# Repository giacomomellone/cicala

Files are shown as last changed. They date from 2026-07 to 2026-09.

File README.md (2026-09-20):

# cicala

Cicala is the Italian word for cicada, the loud, mildly annoying voice of every Italian summer.
What do cicadas talk about all that time? They must be asking each other quite interesting questions.
`cicala` is an open source questions and conversation project built to keep the words going, and to stimulate introspection and discovery.

Its three parts share one database:

1. **[Question database](questions/)**: community-maintained YAML files in this repo.
2. **[Website](website/)**: a static front-end to the database, no account needed. Anyone can play, save favorites, and suggest questions.
3. **[Device](hardware/)**: a pocket-sized offline object with one e-paper display and adjacent Filters and Next buttons. The first prototype is still in development.

Cicala also has an [Xteink X4 Pro integration](docs/crosspoint.md) in a CrossPoint
fork. It shares the portable question engine with the device firmware and adds
manual bundle updates and sessions saved on SD.

## AI policy

Cicala's questions are [**Human Reserved**](https://www.gatesnotes.com/home/home-page-topic/reader/a-turbulent-ai-era-and-critical-choices-to-make).
Do not use generative AI to write questions.
The questions in this project are meant for humans, not for machines (unless machines start having consciousness and enjoy asking each other questions).
For everything else in this repository, like code, documentation, tests, tooling, firmware, and hardware, feel free to use AI.
**Just make sure to leave questions to humans.**

AI may translate an human-written question into another supported language and may suggest metadata such as tags. After a new question or a human edit in any language is merged, the Google Cloud Translation workflow opens or updates review pull requests for the other linked translations. Editing a translation never rewrites its human-written original. Every machine-translated entry retains that original's `origin` and keeps `translated_by: google`, including after review. `translation_sync` records the version used for each update and prevents generated updates from triggering another round.

Machine translations do not merge automatically. A maintainer compares each draft with the accepted source edit and its original, and may edit or reject it to preserve the intended meaning and make it read naturally in the target language. Published machine translations remain labeled `translated_by: google` in the database, and the website marks them as automatically translated and human-reviewed wherever they appear, with a link to the original.

### Some tips to write a good question

More on the reasoning behind these points: [docs/theory.md](docs/theory.md). Every example below is quoted from that page.

- **Make people build an answer instead of repeating one.** If the answer is already finished in their head, the question is boring. Try adding a constraint.
  - Weak: "What food do you dislike?"
  - Better: "Which food do you wish you liked, and what keeps stopping you?"
- **Avoid rankings and superlatives: best, favourite, top, most.** They ask a person to scan a whole life, pick a winner, and defend that taste in public. Someone who cannot think of an answer feels boring, instead of blaming the question. Ask only what you would answer yourself, at that table.
  - Weak: "What's the best book you've ever read?" A memory test and a public verdict on taste.
  - Better: "Which book do you still think about at odd moments?" It asks what you noticed, not what is best.
- **Ask about one concrete thing, not a whole subject or a principle.** A subject gives attention nowhere to land, a principle has a socially correct answer, and a scene gives the table people, places, and choices to ask about next.
  - Weak: "Do you value honesty?"
  - Better: "When did you last tell a lie you're still unsure about?"
  - Weak: "What do you think about music?"
  - Better: "Which song do you love for a reason that has nothing to do with the music?"
- **Do not invent someone's life.** Keep the assumption that helps and remove the details you cannot know about their family, work, health, or history.
  - Weak: "Which parent understands you better?" It assumes two parents, a relationship with both, and a ranking.
  - Better: "Who understood you better than you expected?"
- **Give the question one job, and keep it short.** Leave the follow-up to the people at the table.

## Contributing a question

You don't need to be a developer or have an account. Use [suggest a question](https://cicala.dev/suggest), or open a [new-question issue](../../issues/new?template=new-question.yml) directly on GitHub. A maintainer who speaks your language reviews it, and once merged it ships to the site and every device. All questions are dedicated to the public domain (CC0); see [CONTRIBUTING.md](CONTRIBUTING.md).

To correct an existing question, use **suggest an edit** on its permalink. That
form needs no account either; the
[question-edit form](../../issues/new?template=edit-question.yml) on GitHub
stays available. Question rewrites remain Human Reserved; accepted edits keep
the existing ID.

Want to add a whole language? Read [docs/languages.md](docs/languages.md).

## Development

[`just`](https://github.com/casey/just) is the entry point. Type `just` to see every command:

```sh
just setup     # one-time: python venv + npm install
just validate  # check the question database
just website   # run the site locally
just test      # database validation + tools tests + website tests
just docs      # live-preview the docs (mkdocs)
```

Requires `just`, Python 3.11+ and Node 20+. `just setup` creates the venv (`.venv/`) from [requirements.txt](requirements.txt).

On a machine with [Nix](https://nixos.org), `nix develop` (or `direnv allow`, using the committed `.envrc`) provides those tools at the versions CI uses, without installing anything system-wide. It is optional and no recipe depends on it; `flake.nix` says what it deliberately leaves to upstream installers, the Zephyr SDK included.

## Documentation

- [docs/design.md](docs/design.md): product and UX rationale
- [docs/brand.md](docs/brand.md): public wordmark, typography, colour, and asset rules
- [docs/device_prototype.md](docs/device_prototype.md): device feasibility review, enclosure study targets, and prototype plan
- [docs/prototype_bom.md](docs/prototype_bom.md): breadboard and rev A parts list
- [docs/decisions.md](docs/decisions.md): decision log
- [docs/languages.md](docs/languages.md): multilingual policy and maintainers
- [docs/sync_protocol.md](docs/sync_protocol.md): device sync and bundle format

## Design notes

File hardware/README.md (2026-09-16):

# Hardware

Each revision owns its PCB, enclosure, exported parts and manufacturing notes.
Open the revision's KiCad project so its local libraries and models resolve.

| Directory | Design |
| --- | --- |
| [rev_a](rev_a/README.md) | Original 78 × 49 mm board and deeper enclosure |
| [rev_b](rev_b/README.md) | Landscape device; L-shaped board beside a thin battery |
| [tools](tools/README.md) | Shared checks and revision-specific build commands |

Native KiCad and OpenSCAD files are authoritative. Generated exports belong
inside their revision. Temporary candidates and logs go in the ignored
`build/` directory. Hardware is licensed under [CERN-OHL-S-2.0](../LICENSE-HARDWARE).

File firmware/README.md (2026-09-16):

# Firmware

Zephyr firmware for the ESP32-S3 Cicala device. The breadboard rig runs the
tabletop loop, deep sleep, setup portal, signed bundle sync, signed firmware
updates, battery monitoring, and the two status LEDs. Whole-device sleep current
still needs measurement on rev A because the DevKitC indicators exceed the
30 µA target.

Start with the [firmware primer](../docs/firmware_primer.md). See the
[firmware architecture](../docs/firmware_architecture.md) for module boundaries
and the [hardware wiring guide](../docs/hardware_wiring.md) for the bench rig.

## Integrated Rev A board

Select `hw=rev_a` for the integrated PCB; the default remains the breadboard.
The Rev A overlay/configuration control the switched battery divider and panel
rail, set the ADC divider to 1 MΩ/470 kΩ, wait 200 ms before sampling, and use
native USB Serial/JTAG for console and debugging. A dedicated power-sampling
work queue keeps the settling delay out of the input/system queue. Conversion
failure and deep-sleep entry both switch the divider off.

```sh
just hw=rev_a fw-build debug
just hw=rev_a fw-flash debug
just hw=rev_a fw-monitor debug
just hw=rev_a fw-debugserver
just hw=rev_a fw-flash                 # release with MCUboot
```

Rev A build directories are `build/cicala-rev-a` and
`build/cicala-rev-a-debug` (other profiles use the corresponding suffix).
Use `port=/dev/cu.usbmodem…` or the Linux serial device as a `just` override
when automatic detection selects the wrong port. The debug ELF is
`build/cicala-rev-a-debug/zephyr/zephyr.elf`; the existing OpenOCD configuration
uses the ESP32-S3 built-in USB JTAG adapter. No external JTAG probe is required.

GPIO14 low requests charging; the independent analog temperature guard can
still veto it. GPIO5 enables the panel before driver initialization. Deep
sleep parks physical display-bus levels low before disabling the rail and
holds those pins. The first refresh after power restoration is full because
the display controller RAM has been lost. The PCB recovery pinout and first
power checks are in [the hardware review](../hardware/rev_a/REVIEW.md).

The [Rev A build and flash guide](../docs/firmware_rev_a.md) covers toolchain
installation, first USB download, JTAG, UART recovery and hardware acceptance.
Rev A reads both BQ25185 status pins: high/high means idle or disabled, so it
does not claim a full battery from voltage alone. The release application and
MCUboot both use 16 MiB flash without PSRAM. Firmware validation passed 195
QEMU cases across 16 configurations, with two skips.
Physical USB flashing, JTAG, charging and display operation remain prototype
acceptance tests. The accepted question database is currently empty; use the
existing charset diagnostic for initial display testing.

## Target

- ESP32-S3-DevKitC-1-N8R8 on the breadboard
- ESP32-S3-WROOM-1-N16 on rev A
- 250 × 122 GDEY0213B74 e-paper panel with SSD1680 controller
- Filters and Next buttons
- red and green status LEDs; lighting both produces amber
- single-cell LiPo with a bq25185 power-path bench

Application logic is C++17 under `firmware/lib/`. Zephyr threads, drivers, and
channels live in `firmware/app/` and use C where Zephyr macros require it.

## Commands

```sh
just fw-init          # install the west workspace once
just fw-build         # release image with MCUboot
just fw-flash         # build and flash the release image
just fw-monitor       # UART console; ctrl-] exits
just fw-sim           # run the application under qemu
just fw-test          # run all firmware suites under qemu
just fw-test input    # run one suite
```

`fw-build`, `fw-flash`, and `fw-monitor` accept a profile:

| Profile | Purpose |
|---|---|
| `release` | normal MCUboot application; the default |
| `debug` | `-Og`, USB debug console, and OpenOCD support |
| `charset` | step through the renderer's glyph pages |
| `soak` | generate Next presses for ghosting measurements |
| `retain` | warm-reboot during the soak run |
| `power` | log raw and converted battery readings |
| `portal` | open the setup portal at boot |
| `corpus` | write the compiled corpus to LittleFS at boot |
| `bench` | fetch bundles from a local server; requires its host |
| `ota` | fetch firmware from a local server; requires its host on first build |

Examples:

```sh
just fw-flash charset
just fw-monitor charset
just fw-flash bench 192.168.1.20
just fw-build ota 192.168.1.20
just fw-monitor debug
```

Profiles use separate build directories, so switching images does not retain
another profile's CMake configuration. The release, power, and OTA profiles use
sysbuild and produce MCUboot plus the signed application.

For debugging, `just fw-debug` builds and flashes the debug profile, then starts
OpenOCD on port 3333. `just fw-debugserver` starts the server without flashing.

## Interaction

- Filters opens the menu or advances through Dark, Sexual, Heavy, and Done.
- Next draws during play, toggles a permission in the menu, or applies Done.
- A cold boot excludes all three permissions. RTC memory preserves the question
  snapshot, menu draft/cursor, per-language bags, and refresh count through sleep.
- Presses during a panel refresh are dropped.
- Ordinary playback includes depths 1 and 2. Heavy permits depth 3.
- Display errors and refused refreshes do not commit pending selection state.
- Holding both buttons through boot opens the setup portal.
- External power keeps the device awake and opens the sync and update window.
- LOW and CRITICAL battery states refuse panel refreshes. LOW blinks amber
  once; CRITICAL blinks red three times.

Wi-Fi is optional. Every release image contains the shipped corpora, and a
stored corpus replaces its compiled counterpart only after validation.

## Source layout

```text
firmware/
├── west.yml          # pinned Zephyr workspace
├── Kconfig.policy    # shared product policy
├── app/
│   ├── boards/       # board Kconfig and devicetree
│   ├── include/      # C interfaces and channel messages
│   └── src/          # Zephyr integration
├── lib/              # hardware-free logic
├── tests/            # ztest suites
└── patches.yml       # local Zephyr patches
```

The build creates question fixtures from the real YAML database. Firmware tests
therefore exercise the same QDB4 bytes compiled into the application.

## Hardware checks

The breadboard rig has verified:

- Filters and Next from GPIO input through the panel refresh
- English and German QDB4 bundles and no-repeat draws
- every shipped question at the minimum font size
- partial and full refresh policy on the GDEY0213B74
- deep-sleep wake and RTC-retained state
- setup with a phone, including saved credentials and language
- bundle validation and atomic LittleFS replacement
- MCUboot installation and rejection of an image signed with the wrong key
- battery and VBUS sensing, refresh gating, and LED states

Network download checks require a reachable bench server. Sleep-current
measurement requires rev A or a power mule without the DevKitC's indicator
loads. The procedures and recorded measurements are in the
[hardware wiring guide](../docs/hardware_wiring.md#bench-measurements).

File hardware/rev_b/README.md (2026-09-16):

# Rev B

Landscape prototype with a centered 3.52-inch display, ESP32-S3 module,
L-shaped PCB, 500 mAh battery and two flat, recessed Omron controls at the right: Filters above the larger Next button.
The core envelope is 128 × 66 × 16.8 mm (1 mm nominal button recess). The phone carrier is removable.

The routed board and nominal mechanical design pass the digital checks.
This is an engineering prototype; physical qualification and factory order
review remain open. See [validation](validation.md) for the measured scope.

- `contract.json` — shared mechanical dimensions and manufacturing limits
- `pcb/` — native KiCad project, local libraries and component models
- `case/` — OpenSCAD enclosure and generated geometry
- [Complete assembly BOM](BOM.md)
- [Fabrication and assembly order notes](pcb/fabrication_notes.md)
- `component_selection.csv` — selected components and rationale
- [Hardware specification](../../docs/hardware_rev_b.md)
- [Component evidence](../../docs/hardware_rev_b_selection.md)

Digital validation and first-article measurements are separate records.
The first assembled board is needed to qualify electrical behavior, printed
fits, display flex, temperature sensing and the optional phone carrier.

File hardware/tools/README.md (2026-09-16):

# Hardware tools

Run commands from the repository root through `just`.

| Directory | Responsibility |
| --- | --- |
| `pcb/` | KiCad parsing, geometry, assembly export and electrical/copper audits; historical Rev A routing helpers |
| `case/` | STEP-derived component bounds and mesh checks |
| `rev_a/` | Rev A review and manufacturing/enclosure exports |
| `rev_b/` | Rev B contract, routing support, review and exports |

Native board files are the source of truth. Routing helpers generate review
candidates; they do not reproduce a finished board by replaying an old script.
Keep candidate files and logs under `build/`, outside the source directories.

Rev B's `silkscreen.py` maintains the native identity and service legends and
checks their pin mappings. `just hw-rev-b-pcb-renders` regenerates orthographic
KiCad PNGs, mirrored underside/normal top silkscreen SVGs and their provenance.

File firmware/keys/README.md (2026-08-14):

# Firmware signing keys

MCUboot verifies each image with the public key compiled into the bootloader.
`SB_CONFIG_BOOT_SIGNATURE_KEY_FILE` in `firmware/app/sysbuild.conf` names the PEM
used both to generate that public key and to sign application images.

## Development key

`firmware-signing-dev.pem` is committed so local sysbuild builds produce a
matching bootloader and application without extra setup. Its private key is
public, so use it only for development hardware.

## Release key

Create the release key with:

```sh
just keygen --purpose firmware --out release-firmware-key.pem
```

Store the private PEM in the `FIRMWARE_SIGNING_KEY` GitHub Actions secret. CI
writes it over the development PEM while building a release. Never commit it.

A shipped device must receive the release-key bootloader during its wired first
flash. OTA cannot replace the bootloader or change the key it trusts. Losing or
rotating the release key requires a wired reflash of every affected device.

`BUNDLE_SIGNING_KEY` is separate. The application uses it to verify question
bundles and OTA manifests. See [firmware updates](../../docs/firmware_update.md).

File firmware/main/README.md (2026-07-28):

# main

Application entry point and state transitions. See
[firmware/README.md](../README.md) for the current interaction contract and
state outline.

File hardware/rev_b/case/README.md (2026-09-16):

# Rev B enclosure

`cicala_enclosure.scad` is editable. `contract.scad` and `pcb_component_bounds.scad` are generated from the contract and native KiCad placement.

The housing is 128 × 66 × 16.8 mm; the flat button tops are 1 mm recessed. Filters is at the upper right and the larger Next button is below. The active screen remains centered. Filters uses a 9 × 9 mm ivory B32-1200 cap; Next uses a 12 × 12 mm orange B32-1320 cap. Both seat directly on B3F-4050 switches. The enclosure supplies flared access wells, with no printed actuators or retaining mechanism.

Run `just hw-rev-b-export --renders` for checked native exports. `exports/assembly/` preserves assembly coordinates; `exports/print/` contains eight individually oriented printed parts, grouped by purpose. Purchased cap, switch, battery, panel and PCB models stay in `exports/reference/` and must not be printed. The clear lens outline is in `exports/patterns/`.

Four core prints form the housing and display supports. The other prints are the optional carrier, ring cover, wedge and temporary flex former. See [the assembly guide](../../../docs/hardware_rev_b.md#buttons-and-print-preparation) for soldering, cap installation, print tolerances and screws.

The carrier adds 3.2 mm. Its increased portrait length fails the former iPhone 16 Plus fit target; phone compatibility is unqualified. The R1.55 flex bend and connector entry height remain first-article checks. No integrated Rev B prototype has been assembled.

Native meshes use KiCad STEP handedness: X right, Y up (negative layout Y), Z above the base. Translate the native PCB STEP up 4.6 mm to align it. Print meshes include their bed rotation/translation; do not mirror them. The validation compares the PCB reference outline and mounting holes against this datum.

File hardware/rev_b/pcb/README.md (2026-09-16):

# Rev B PCB

Open `cicala_rev_b.kicad_pro` in KiCad 10. The engineering design uses the ESP32-S3 module, an L-shaped 1.2 mm four-layer PCB and one fitted assembly face. Bare diagnostic contacts may be on the underside. Component selection and assembly assumptions are recorded in [the engineering guide](../../../docs/hardware_rev_b.md) and [selection record](../../../docs/hardware_rev_b_selection.md).

The display is Waveshare 22609, 3.52-inch V1.1 UC8253. The Molex 503480-2400 connector uses the panel table: pins 1 and 4 unused, pin 5 decoupled. The protected Renata pack connects through JST SH: BAT+/NTC/GND on pins 1/2/3. R8 sets nominal 100 mA charging.

The board uses 0.2 mm general clearance, 0.5 mm copper-to-edge spacing, 0.15 mm fine-pin escapes and ordinary 0.3 mm drilled / 0.6 mm diameter through-vias. 87 SMT components and two B3F-4050 through-hole switches are installed from the top; switch solder joints are underneath; there are no filled via-in-pad requirements. Ground is poured on both outer faces and In1, with local In1 signal crossings outside reserved reference areas. In2 carries power/signals and a dedicated ground reference beneath the bottom USB pair.

Run `just hw-rev-b-check` for native electrical and mechanical checks. `just hw-rev-b-fab-export` exports only after those checks pass, including assembly BOM/CPL, Gerbers, drills, IPC-2581 and STEP. The factory must confirm the stack, controlled impedance, panel support, component orientations and paste treatment before an engineering order. This is an unbuilt prototype; see [validation](../validation.md) for actual check results and remaining measurements.

[`renders/`](renders/README.md) contains top and bottom KiCad 3D exports used by
the public device page. The mechanical board model is
`exports/cicala_rev_b_board.step`.

[Reading the board](silkscreen.md) explains its native silkscreen: Cicala
branding, circuit brackets, connector polarity, every test point, and the
underside power/recovery guide. Main text is 1 mm, compact labels are 0.8 mm,
with 0.15 mm minimum strokes and silk clearance. The render directory also
contains both silkscreen drawings as SVGs.

The switch hole pattern uses 1.2 mm finished PTH and 1.8 mm NPTH holes. The JLC BOM/CPL covers 87 SMT references; `manual_assembly.csv` specifies the separate switch soldering and purchased-cap installation. Caps are fitted only after soldering.

The [fabrication notes](fabrication_notes.md) specify stack, impedance, panel, tighter switch-hole tolerances, assembly stages and inspection. They are included in the exported prototype package. SW1/Filters is the upper control; SW2/Next is the lower control.

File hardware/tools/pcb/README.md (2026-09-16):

# PCB review and candidate tools

The checked `../cicala_rev_a/cicala_rev_a.kicad_pcb` is authoritative. These
scripts support review and isolated routing candidates. The historical
placement pipeline is not an exact replay of the current board; do not run
it over the working source. No script authorizes production release.

## Checks and exports

`just hw-pcb-check` runs KiCad ERC, netlist/pin/land checks, filled DRC,
schematic parity and populated STEP export. `../export_fab.sh` also requires
exact assembly MPNs and creates Gerber/drill ZIPs, BOMs, placement files and
both assembly drawings. `jlc_assembly.py` expands KiCad reference ranges,
converts the headers and requires identical fitted-reference coverage in the
BOM and CPL. It preserves explicit top/bottom placement and the common origin.

Run tool regressions with the dependencies in `requirements.txt` (NumPy,
Shapely 2 and fontTools):

```sh
python3 -m unittest discover -s hardware/tools/pcb -p 'test_*.py'
```

Run the complete source review with `just hw-review`. `CICALA_HW_PYTHON`
selects the analysis interpreter; `KICAD_PYTHON_BIN` selects KiCad's Python.
Pass `--app build/cicala-rev-a/app/zephyr --boot build/cicala-rev-a/mcuboot/zephyr`
after the report-directory argument to compare compiled firmware settings too.
The placement/copper/USB commands return a failing exit status on violations.

KiCad Python and analysis Python may be separate installations. On macOS,
KiCad supplies `pcbnew` in its bundled interpreter. CadQuery and Gerbonara
are optional analysis dependencies; install them in a separate environment.
`requirements.txt` contains the routing dependencies.

| Tool | Input / purpose |
| --- | --- |
| `export_geom.py` | KiCad Python: board → physical pads, drills, courts, tracks, filled polygons |
| `audit_electrical.py` | Netlist and project → critical pin mapping, bypass, feedback, LED and land checks |
| `audit_temperature.py` | Netlist → static NTC/comparator tolerance model |
| `audit_copper.py` | Geometry JSON → continuous clearance, edge, via-in-pad and track-angle audit |
| `audit_placement.py` | Geometry + board/models → courts, through-hole/body interference, fitted models |
| `audit_reference.py` | Candidate USB paths → reference/stitch analysis; not a measurement of current routing |
| `audit_usb.py` | Actual board → path lengths including vias, branch mismatch and In1 reference continuity outside launches |
| `check_rev_a_contract.py` | PCB/case datums and compiled app/MCUboot → connector, GPIO, flash, PSRAM and display agreement |
| `package_prototype.py` | Dated public working-source/export snapshot with archive and per-file SHA256 verification |
| `audit_fabrication.py` | Gerber ZIP + geometry → eleven layers and every drill/slot read back independently; needs Gerbonara |
| `check_assembly_bom.py` | Reject blank, unresolved or multiple MPNs |
| `make_component_models.py` | CadQuery → six original STEP envelopes; drawings in `../cicala_rev_a/models/README.md` |
| `apply_silkscreen.py` | Native cicada/wordmark/service legends and fab references; `--mark-only` preserves existing legends |
| `make_cicada.py` | Public SVG → committed native stroke and fill geometry for the cicada silkscreen |

The fabrication audit accounts for Excellon's 1 µm coordinate rounding.
It also opens the compressed IPC-2581 exchange and checks its XML document;
a plain XML file with a `.zip` extension fails the audit.
The enclosure's `../../case/export_component_bounds.py` exports 87 fitted
component envelopes from STEP and fingerprints placement/model changes.
The case checks reject stale envelopes. Generic capacitor height is bounded
at 1.5 mm; the enclosure contains detailed switch references.

## Candidate routing

`build_candidate.py` creates an isolated candidate directory. Its historical
placement and critical routing stages predate the current top-side display
and temperature guard. Updating those stages requires a new placement and
mechanical review; they must not be represented as a reproducible release.

`route_fanout.py` and `finish_routes.py` route on F.Cu, In2.Cu and B.Cu,
leaving In1 as ground. They model every physical pad, oval drills, no-net
mechanical copper, outlines, keepouts and via drills. Surface escapes stay
on the pad's actual layer. `repair_routes.py` permits explicit scoped rip-up
of ordinary copper while preserving the supplied critical seed. Its displaced
nets must be reconnected and checked.

`usb_pair.py` records the dedicated USB geometry, connector crossover and
inline test points. Its main F.Cu width/gap is 0.32/0.26 mm for the selected
JLC04121H-7628 stack. Short escapes remain 0.29 mm or the explicit fine-pitch
neck width. The current board's connector mismatch including the new barrel
spacing is about 0.041 mm. Generated candidate compensation can differ;
audit the actual board rather than treating a seed report as a measurement.

The recovery keepout is derived from J4's transformed physical contacts,
including rotation. The TC2030 shaded contact region and 0.508 mm foreign
copper rule must accompany candidates. U7's package land-to-land clearance
is 0.15 mm; this exception does not relax routed copper clearance.

`ground_planes.py`, `stitch_islands.py` and `stitch_coverage.py` add checked
plane connections. Filled polygons apply only to the exact track set KiCad
refilled. Never route using stale filled polygons. `stitch_islands.py` rejects
a mismatched input set. Unconnected-zone island removal does not repair an
unconnected pad.

`cleanup_dangling.py` removes only DRC-identified items whose deletion preserves
every physical pad group. Refill and repeat; deleting one stub can expose the
next. Some apparent dangling vias are single-layer copper junctions and need
replacement with proper trace junctions before deletion. Never suppress a
DRC warning merely because the router finished.

`unique_ids.py` assigns deterministic unique IDs to cloned footprint items;
`apply_tracks.py` emits stable IDs for copper. Appearance uses native polygon
artwork from `assets/cicala-wordmark.json` and stroke geometry from
`assets/cicala-mark.json`; their sources and regeneration are documented in
`assets/README.md`.

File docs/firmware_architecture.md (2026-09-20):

# Firmware architecture

The ESP32-S3 firmware runs the tabletop interaction, preserves state through
deep sleep, manages the setup portal, and installs signed question and firmware
updates. See [design.md](design.md) for interaction rules,
[sync_protocol.md](sync_protocol.md) for bundle formats, and
[hardware_wiring.md](hardware_wiring.md) for the breadboard pins.

Every module builds and runs on the breadboard. Whole-device sleep current is
still unmeasured because the DevKitC indicators exceed the 30 µA target. The
[firmware primer](firmware_primer.md) covers setup and common development
tasks.

## Runtime model

ESP32-S3 deep sleep restarts the application. SRAM and thread stacks are lost;
`main()` runs again after a button wake. State needed across wakes lives in RTC
slow memory or flash.

The device enters deep sleep after the idle timeout when all three conditions
hold:

1. the tabletop state machine has settled;
2. the portal, sync, and update paths are idle;
3. external power is absent.

External power keeps the application awake. It also opens a bounded window for
sync and update checks.

```mermaid
flowchart LR
    GPIO[Filters and Next GPIO] --> WQ[system workqueue<br/>debounce]
    WQ -->|chan_filters / chan_next| APP[app thread<br/>tabletop policy]
    APP --> QDB[qdb + shuffle bag]
    APP -->|chan_question| DISPLAY[display thread]
    DISPLAY --> PANEL[e-paper]
    DISPLAY -->|chan_render| APP

    POWER[power work item<br/>cell ADC + VBUS] -->|chan_power| STATUS[status LEDs]
    NET[net thread<br/>portal · sync · OTA] -->|chan_service / chan_corpus| APP
    NET --> NVS[(NVS)]
    NET --> LFS[(LittleFS)]
```

The display has its own thread because an e-paper refresh can block for up to
two seconds. The app thread remains responsive and can apply the rule that
presses during a refresh are discarded. Network coordination also has a thread;
short ADC and VBUS reads run as delayed work.

## Code boundaries

Shared question and session policy lives in `core/`, also consumed by the
[Xteink X4 fork](crosspoint.md). Zephyr-specific policy remains in
`firmware/lib/`; threads, drivers, channels, and storage adapters live in
`firmware/app/src/`.

| Area | Owns |
| --- | --- |
| `lib/fsm` | table-driven state machine engine with an injectable clock |
| `lib/app_fsm` | Filters, Next, render, and service-card policy |
| `../core`, through `lib/qdb` | QDB4 validation, selection, and transactional session state |
| `lib/layout` | UTF-8 decoding, accent composition, and line wrapping |
| `lib/portal` | portal state machine, form parsing, DNS replies, and HTML rendering |
| `lib/power` | battery and external-power states |
| `lib/status` | LED priority and blink patterns |
| `lib/sync` | CMake adapter for shared manifest parsing and version comparison |
| `lib/retained` | validation of the RTC-retained block |
| `lib/ed25519` | CMake adapter for shared detached-signature verification |
| `app/src/input.c` | Filters and Next events from `gpio-keys` |
| `app/src/app.c`, `app_logic.cpp` | app thread, state machine effects, and corpus binding |
| `app/src/display.c`, `panel.cpp` | display thread, layout, and refresh policy |
| `app/src/net.c`, `net_logic.cpp`, `portal.c` | Wi-Fi, setup, and network events |
| `app/src/fetch.c`, `sync.cpp`, `ota.cpp` | HTTP transport and signed updates |
| `app/src/power.c`, `power_logic.cpp` | ADC/VBUS sampling and power state publication |
| `app/src/status.c`, `status_logic.cpp` | serialized LED output |
| `app/src/sleep.c` | idle timer, wake sources, and pin state for deep sleep |

Files that define zbus objects stay in C because Zephyr's macros use
initializers that C++17 rejects. C++ policy is exposed to those files through
small C APIs.

## Channels

`chan_question` and `chan_power` hold current state. The other channels carry
events.

| Channel | Carries | Publisher | Consumer |
| --- | --- | --- | --- |
| `chan_filters`  | timestamp and press duration | input work item | app |
| `chan_next` | timestamp and press duration | input work item | app |
| `chan_question` | sequence, permissions, cursor, kind, text | app | display  |
| `chan_render` | sequence, result, and refresh type | display | app |
| `chan_service`  | setup or sync result card | net | app |
| `chan_corpus` | active language change | net | app |
| `chan_power` | power state, millivolts, and VBUS | power work item | status |

Messages use subscribers, so publishers do not wait for consumers.
`chan_question` copies the text into the message. This keeps it valid if sync
replaces the underlying corpus before the display thread reads it.

The app is the only publisher of `chan_question` and owns its sequence number.
Render results with an older sequence are ignored. Corpus changes take effect
on the next requested draw and do not refresh the panel by themselves.

## Question data

Every shipped language is compiled into the firmware. A valid synced corpus in
LittleFS takes precedence; the compiled copy remains the fallback.

```mermaid
flowchart LR
    YAML[questions/*.yaml] --> BUILD[tools/build_bundle.py]
    BUILD --> GZIP[dist/bundles/*.qdb.gz]
    GZIP --> RAW[firmware test fixtures<br/>raw QDB4]
    RAW --> EMBED[compiled corpora]
    HTTP[verified sync download] --> LFS[(LittleFS /corpus)]
    EMBED --> OPEN[qdb::open]
    LFS --> OPEN
```

The selected language is stored in NVS. Changing it reopens the corpus and
publishes `chan_corpus`. Binding the shuffle bag to a different bundle
fingerprint clears indices that belong to the previous corpus.

### QDB reader

`Qdb::open()` validates the whole QDB4 buffer: magic, record lengths, question
count, and trailing bytes. Questions point into that buffer, so the buffer must
outlive every returned view.

`Qdb::at()` walks records from the start. The shipped corpora are small enough
that an offset table would cost more RAM than the scan saves.

A question is eligible only when Dark permits its dark flag, Sexual permits its
sexual flag, and Heavy permits depth 3. All applicable permissions are required.

### Shuffle bag

Each installed language has one drawn bitmap and recent ring of 20 indices.
Selection happens at draw time: eligible, unseen, non-recent if possible, then
not current if possible. Only exhaustion reopens the eligible cycle. Excluded
questions keep their seen bits. A depth-3 predecessor adds a cost of three to
another depth-3 candidate; repeated depth band and overlapping form each add
one. Random choice among the cheapest candidates therefore prefers a breather
before texture, without forcing an early repeat. Restrictions never relax.

The fingerprint covers the full bundle bytes, so metadata or order changes
invalidate old indices even if a development version string is unchanged.

## Tabletop state machine

Filters opens or advances the four-row menu. Next draws during play, toggles a
menu row, or applies Done. A cold boot draws from default permissions; a valid
retained menu, question, or empty state needs no redraw. A button wake replays
its action once. The two-button service gesture remains unchanged.

```mermaid
stateDiagram-v2
    [*] --> BOOT
    BOOT --> SHOWING: retained view
    BOOT --> DRAWING: cold boot or Next wake
    BOOT --> FILTERS: Filters wake
    SHOWING --> DRAWING: Next
    SHOWING --> FILTERS: Filters
    SHOWING --> SERVICE: service pending
    DRAWING --> REFRESHING: card queued
    FILTERS --> REFRESHING: menu queued
    SERVICE --> REFRESHING: service queued
    DRAWING --> FAIL: queue refused
    FILTERS --> FAIL: queue refused
    SERVICE --> FAIL: queue refused
    REFRESHING --> SHOWING: commit matching successful render
    REFRESHING --> FAIL: error or timeout
    FAIL --> SHOWING: discard pending state
```

`AppIo` stages a copy of the bag and play state before publishing a card.
`complete(true)` commits after the display succeeds. A low-power refusal,
failed publication, display error, or timeout discards that copy. Both tabletop
inputs are dropped while refreshing. Late render results cannot commit. Service
cards wait until the current refresh finishes. If sync changes the corpus during
a refresh, completion cannot revive indices into the old corpus.

## Display

`panel.cpp` lays out UTF-8 text through `lib/layout`, draws through Zephyr CFB,
and selects full or partial refresh. A full refresh is forced at boot and after
`CONFIG_CICALA_FULL_REFRESH_INTERVAL` partial updates.

The SSD16xx driver performs a full update when blanking changes from on to off.
`panel.cpp` therefore uses `display_blanking_on()`, `display_write()`, then
`display_blanking_off()` for a full refresh. A partial refresh writes while
blanking is already off.

The local Zephyr patch controlled by `firmware/patches.yml` preserves the image
during driver initialization. Without it, every deep-sleep wake would clear the
bistable panel before the app could decide that no refresh was needed.

Before system power-off, `sleep.c` sends the panel controller to deep sleep,
stops pending ADC sampling and LED work, then parks the display signals.
Rev A holds reset, D/C, chip-select, MOSI and clock physically low and disables
the panel rail. Its first refresh after restoring power is full because the
controller RAM was lost. The retained question and shuffle state survive.

## Retained state and wake

`app/src/retained_block.cpp` places one validated block in `.rtc_noinit` inside
RTC slow memory. It contains:

- shuffle-bag state and the shared recent ring;
- the partial-refresh counter;
- committed permissions, menu draft and cursor;
- a copied question and its restrictions, plus the displayed card kind;
- the last question sequence number.

The block carries a magic value, layout version, size, and payload hash. A
failed check clears the whole block and excludes Dark, Sexual, and Heavy. The block is sealed
after each completed render.

```mermaid
flowchart TB
    BOOT([boot]) --> CHECK{retained block valid?}
    CHECK -- no --> COLD[clear state<br/>permissions off]
    CHECK -- yes --> MATCH{panel holds a retained<br/>question, menu, or empty state?}
    MATCH -- yes --> KEEP[keep panel unchanged]
    MATCH -- no --> ACTION[replay wake action<br/>or draw from defaults]
    COLD --> ACTION
```

Filters and Next are active-low RTC-capable inputs. At sleep time, firmware
arms every input that currently reads high with EXT1 `ANY_LOW`. A held or stuck
button is omitted from the mask, avoiding an immediate wake loop while leaving
the other button usable. The EXT1 wake status is latched at `PRE_KERNEL_1` so
later driver initialization cannot erase it. Next wins if both bits are set.

VBUS uses a separate active-high EXT0 trigger when
`CONFIG_CICALA_POWER_WAKE_ON_USB` is enabled. It is disabled by default because it
keeps the RTC peripheral domain powered. With the default setting, plugging in
does not wake the device; the next button press wakes it, VBUS is sampled during
boot, and the network window opens.

## Power and status

`power.c` samples the battery divider and VBUS on a dedicated workqueue. Rev A
switches its 1 MΩ/470 kΩ divider, waits 200 ms, samples, then switches it off
even after a conversion failure. VBUS remains usable when the ADC fails.
Rev A also reads both BQ25185 status inputs atomically. A mutex protects the
power state machine and queries from app, networking and system workqueue threads.

```mermaid
stateDiagram-v2
    [*] --> UNKNOWN
    UNKNOWN --> NORMAL: plausible cell reading
    NORMAL --> LOW: below refresh floor
    LOW --> CRITICAL: below critical threshold
    CRITICAL --> LOW: recovered with hysteresis
    LOW --> NORMAL: recovered with hysteresis
    NORMAL --> UNKNOWN: implausible reading
    LOW --> UNKNOWN: implausible reading
    CRITICAL --> UNKNOWN: implausible reading
    UNKNOWN --> CHARGING: VBUS high
    NORMAL --> CHARGING: VBUS high
    LOW --> CHARGING: VBUS high
    CRITICAL --> CHARGING: VBUS high
    CHARGING --> CHARGED: breadboard voltage estimate only
    CHARGED --> CHARGING: below full estimate with hysteresis
    CHARGING --> UNKNOWN: VBUS low
    CHARGED --> UNKNOWN: VBUS low
    CHARGING --> EXTERNAL_IDLE: Rev A idle or disabled
    EXTERNAL_IDLE --> CHARGING: charging
    CHARGING --> CHARGE_FAULT: charger fault
    EXTERNAL_IDLE --> CHARGE_FAULT: charger fault
    CHARGE_FAULT --> CHARGING: charging
    CHARGE_FAULT --> EXTERNAL_IDLE: idle or disabled
    EXTERNAL_IDLE --> UNKNOWN: VBUS low
    CHARGE_FAULT --> UNKNOWN: VBUS low
```

LOW and CRITICAL refuse panel refreshes. UNKNOWN permits them, so a missing or
failed divider does not disable the tabletop interaction. Downward transitions
are immediate. Recovery uses hysteresis. A reading below
`CONFIG_CICALA_POWER_PLAUSIBLE_MV` is treated as an invalid divider reading.

CHARGED is retained for the breadboard's voltage estimate. Rev A selects
CHARGING, EXTERNAL_IDLE or CHARGE_FAULT directly on USB insertion, depending
on its two status pins. High/high can mean charge completion, CE-disabled or
sleep; it does not prove a full battery. A failed status read uses EXTERNAL_IDLE
and logs unavailable status. The message preserves recoverable/latched fault
detail, even if voltage and the outer state do not change. External power
keeps the device awake in all four external states and opens one network window
per insertion; charger state changes do not reopen that window.

The red and green LEDs share one priority arbiter:

| Condition | Output |
| --- | --- |
| critical refresh refused | three red blinks |
| low refresh refused | one amber blink  |
| Rev A charger fault | slow red pulse |
| sync or update active | slow green pulse |
| setup portal active | steady amber |
| breadboard charged estimate | steady green |
| charging | steady red |
| Rev A idle/disabled/unavailable | slow amber pulse |
| healthy battery or unknown reading | off |

Calls from app, network and power threads set atomic flags. The zbus power
listener also posts to those flags; it runs on the ADC publisher's thread.
The status work item owns the arbiter and GPIO writes. Sleep synchronously
cancels pending work, prevents rescheduling, then makes the final LED-off write.

## Setup, sync, and updates

Holding Filters and Next for `CONFIG_CICALA_PORTAL_ENTRY_HOLD_MS` during boot opens
the setup portal. The device scans first, starts a WPA2 access point with a
fresh session password, serves DHCP/DNS/HTTP, stores submitted credentials, then
joins the selected network. The password is generated from the device random
source, shown on the e-paper service card, and cleared when the portal closes.
The setup page can rescan nearby networks and save the question language
separately from Wi-Fi. Its status page shows the access-point name, remaining
portal window, board and firmware versions, corpus information, connection
diagnostics, and the last requested sync result. It can request a question or
firmware update, or forget all saved Wi-Fi credentials after confirmation. The
stored password is never shown. The portal closes at its configured deadline.

```mermaid
stateDiagram-v2
    [*] --> OFF
    OFF --> SCANNING: both buttons held through boot
    SCANNING --> AP_STARTING: scan complete or timed out
    AP_STARTING --> SERVING: access point ready
    AP_STARTING --> SHUTDOWN: start failed
    SERVING --> CONNECTING: credentials submitted
    SERVING --> SHUTDOWN: portal deadline
    CONNECTING --> CONNECTED: station joined
    CONNECTING --> SERVING: join failed or timed out
    CONNECTED --> SHUTDOWN: portal deadline
    SHUTDOWN --> OFF
```

A cold boot with stored credentials checks for new data. A button wake also
checks while the external-power window is open. Battery-only wakes skip Wi-Fi
so the requested question is not delayed by network association.

Question sync performs these checks before storing a bundle:

1. manifest schema and minimum firmware version;
2. version newer than the installed corpus;
3. declared download size;
4. SHA-256 digest;
5. Ed25519 signature against the compiled public key.

The verified bytes are written beside the installed corpus and renamed over it.
A failure leaves the previous file intact. An automatic sync keeps the current
panel content. A sync requested from the portal publishes a result card.

OTA uses the same fetch, manifest, hash, and signature code. The image streams
into `slot1_partition`; it is marked for upgrade only after verification.
MCUboot validates and installs it on the next boot. `update_notice.c` displays
the installed version after a successful update. See
[firmware_update.md](firmware_update.md).

## Persistent storage and security

```mermaid
flowchart LR
    RTC[RTC slow memory<br/>bags · display · permissions] -->|lost on total power loss| COLD[cold defaults]
    NVS[NVS<br/>Wi-Fi credentials · language · versions] -->|cleared by factory reset| EMPTY[unset]
    LFS[LittleFS<br/>synced QDB4 files] -->|atomic rename| NEW[new corpus]
    SLOT[MCUboot secondary slot<br/>candidate firmware] -->|verified boot| APP[running image]
```

The current breadboard build does not enable flash encryption. Physical access
to its flash exposes Wi-Fi credentials and stored corpora. Product provisioning
needs ESP32-S3 eFuse-backed flash encryption before the device is used on a
sensitive network.

## Testing boundary

```mermaid
flowchart LR
    PURE[fsm · app_fsm · qdb · layout<br/>portal · power · status] --> HOST[qemu or native_sim]
    SEAMS[GPIO debounce · zbus flow<br/>panel policy · real QDB fixtures] --> HOST
    PHYSICAL[panel image · timing · radio<br/>battery · sleep current] --> BENCH[breadboard or rev A]
```

`just fw-test` runs the firmware suites under qemu. Linux can use
`just fw-test-linux` for `native_sim`. Both platforms use `gpio-emul` for the
button suites. Generated QDB fixtures keep the writer and firmware reader on
the same data contract.

The dummy display checks bounds, refresh selection, and channel behavior. Image
quality, ghosting, radio behavior, power thresholds, and current require
hardware.

## Open measurements

- Measure whole-device deep-sleep current on rev A without DevKitC indicator
  loads.
- Measure the lowest reliable e-paper refresh voltage and set
  `CICALA_REFRESH_MIN_MV` from that result.
- Measure the current cost of enabling VBUS wake through EXT0.
- Verify font coverage and layout for every released language.
- Run multi-phone setup-portal and long-transfer stress tests.

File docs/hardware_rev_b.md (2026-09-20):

# Rev B landscape hardware

Rev B is an **engineering prototype**, with a centered screen, two large flat controls beside a 30° outer-edge bevel and a thin battery beside an L-shaped PCB. The housing is **128 × 66 × 16.8 mm**. Filters is at the upper right and the larger Next button is below it; both flat faces are nominally **1 mm recessed**. The breadboard firmware works; the integrated Rev B hardware has not been built or powered. Read [component selection evidence](hardware_rev_b_selection.md) for the manufacturer drawings and the remaining first-article measurements.

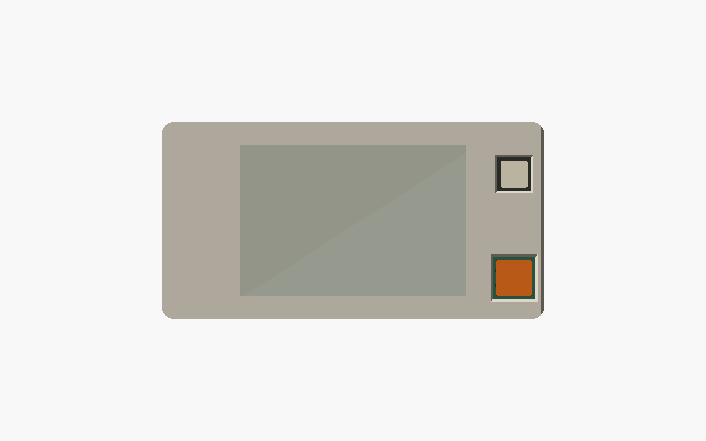
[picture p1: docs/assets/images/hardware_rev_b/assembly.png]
Rev B assembly from the mechanical source


## Files and revisions

Both hardware generations use the same structure. `hardware/rev_a/` preserves the earlier design; `hardware/rev_b/` owns this design. Shared and revision-specific tools live under `hardware/tools/`. A clean public clone contains all required engineering sources.

| File or directory | Purpose |
| --- | --- |
| `hardware/rev_b/contract.json` | Packaging dimensions and manufacturing limits |
| `hardware/rev_b/pcb/cicala_rev_b.kicad_pro` | Editable KiCad 10 project, schematic and board |
| `hardware/rev_b/case/cicala_enclosure.scad` | Editable enclosure, buttons, supports and carrier |
| `hardware/rev_b/case/contract.scad` | Generated numeric include |
| `hardware/rev_b/case/pcb_component_bounds.scad` | Fitted STEP envelopes and placement fingerprint |
| `hardware/rev_b/case/exports/` | STL, 3MF, lens outline and source/output manifest |
| `hardware/rev_b/pcb/exports/` | Generated fabrication, assembly and review files  |
| `hardware/rev_b/validation.md` | Recorded validation status |

Native KiCad files are authoritative. Routing helpers produce candidates; replaying a historical routing script is not required to open or edit the board. Do not hand-edit the generated SCAD dimensions.

## Packaging

| Item | Implemented arrangement |
| --- | --- |
| Enclosure | 128 × 66 × 16.8 mm; 1.4 mm wall, 1.2 mm base, 4 mm outer corner radius |
| PCB | Four layers, 1.2 mm nominal; lower arm and right arm, R1 reentrant corner; lower face z=4.6 mm |
| Assembly | Electronic components on the top face |
| Controller | ESP32-S3-WROOM-1-N16, antenna toward the left edge |
| Display | Waveshare 22609 V1.1, UC8253; 84.70 × 54.41 mm glass, 1.18 mm reserved thickness |
| Active screen | 74.51 × 49.67 mm, 360 × 240; centered at x=54, y=33 mm |
| Battery | Protected Renata ICP303450PA-02, 500 mAh minimum; 54 × 36 × 4.8 mm assembly reservation |
| Display connector | Molex 503480-2400, 24 positions, 0.5 mm pitch, dual contacts |
| Battery header | JST SH, BAT+/NTC/GND; AWG28 adapter harness |
| Controls | 2 × Omron B3F-4050; B32-1200 ivory 9 × 9 mm / B32-1320 orange 12 × 12 mm |
| USB / recovery | HRO TYPE-C-31-M-12 and six-contact Tag-Connect recovery interface |
| Optional carrier  | 3.2 mm behind the core; 1.4 mm around its perimeter |
| Table stand | Separate passive wedge, approximately 12° |

The glass is offset because its inactive border is asymmetric. The **visible screen** is centered. A separate frame and lower support bar carry the glass through a nominal 0.2 mm foam interface; the battery does not support it. The lens is 0.8 mm thick. Adhesive and foam interfaces need prototype compression checks.

The lower arm holds the module and recovery contacts. The right arm holds power, display electronics, the connector and switches. No U arm is needed for this placement. Keep the battery bay free of electronics and copper.

The antenna exclusion is x=3–9.5 mm, y=29–64 mm on all layers. It excludes the battery, display, other components and carrier metal. Follow [Espressif's placement guidance](https://docs.espressif.com/projects/esp-hardware-design-guidelines/en/latest/esp32s3/pcb-layout-design.html). This reserve does not predict radio performance against a phone; measure standalone and attached operation.

## Display, power and recovery

The circuit implements the V1.1 pin table, with pins 1/4 NC and pin 5 VDHR, and the reference HAT's 68 µH / BSS138 / 3 Ω boost arrangement. The selected reservoir capacitors are rated 50 V. [Selection evidence](hardware_rev_b_selection.md) explains the conflicting vendor documents and the exact BOM.

The display fold has a nominal R1.55 mm inside radius and straight reinforced tip. The minimum-tail / maximum-stiffener length calculation leaves **0.276 mm**. The connector entry z=6.115 mm is an assembly assumption; its contact-plane height, latch access and actual bend must be checked on a sample. The printed former is an assembly jig and is removed after forming. Hold the glass independently, avoid tension at the bond and never bend the reinforced tip to force insertion.

The battery retains factory protection. Bond the insulated **103JT-025** NTC against the pouch following its lead and insulation instructions. Splice the stock AWG26 pack wires to short AWG28 JST SH pigtails, with separate insulation and strain relief. Pin 1 is protected BAT+, pin 2 NTC, pin 3 protected ground. Test polarity and NTC resistance before connecting J3.

BQ25185 charging is nominal **100 mA at 4.2 V**, with the existing independent temperature veto. The Renata pack permits 510 mA continuous discharge; its higher noncontinuous rating is not a qualified operating budget. Measure Wi-Fi/OTA and display startup loads, charge-temperature thresholds, low-voltage behavior and sleep current. Runtime is unmeasured.

USB supplies charging and native USB recovery. The optional C1/C2 capacitor lands and TP12/TP13 branches were removed to shorten the data paths. USB measurements use the actual filled board; the factory still needs to confirm impedance. The Tag-Connect interface becomes accessible after removing the display stack; its 3.3 V contact is a reference, not a second power input. Rev B requires a UC8253 firmware port before display bring-up; this hardware change does not add a Rev B firmware target.

## Buttons and print preparation

Both controls use **Omron B3F-4050**, a through-hole switch with a 12 × 12 mm body, projected square plunger, 7.3 ±0.2 mm free height, 1.27 ±0.49 N operating force and 0.3 +0.2/−0.1 mm pretravel. **Filters is B32-1200, ivory, 9 × 9 mm. Next is B32-1320, orange, 12 × 12 mm**: 78% more face area. Both purchased caps fit directly onto the projected plunger. Their assembled height is 10.0 ±0.4 mm above the PCB. See the [switch drawing](https://omronfs.omron.com/en_US/ecb/products/pdf/en-b3f.pdf) and [cap drawing](https://omronfs.omron.com/en_US/ecb/products/pdf/en-b32.pdf).

The controls remain flat inside flared access wells; the outer case edge has a separate bevel. In landscape top view, SW1/Filters is at (108, 17.5) mm and SW2/Next at (108, 52.3) mm. Layout coordinates use KiCad Y-down; printable CAD uses X = layout X, Y = −layout Y and Z unchanged, matching native KiCad STEP with the board translated up by 4.6 mm. Do not mirror the printable files. The mesh audit compares the asymmetric outline and all four mounting holes against that STEP datum. The board right edge is x=116 mm and both switch centers are x=108 mm. The case extends from x=−10 to 118 mm, preserving the centered active screen. The PCB and display stack move upward together by 1.965 mm; the flex bend and relative connector geometry remain unchanged. The lens is recessed below the taller housing roof.

### Clearances

The throat openings are **10 × 10 mm** and **13 × 13 mm**, with 0.5 mm nominal clearance per side. Each has a 2.5 mm-deep flare opening another 1.4 mm per side at the roof. The geometric screen includes ±0.15 mm cap width, ±0.30 mm opening size and ±0.15 mm lateral alignment assumptions: minimum radial clearance is **0.125 mm**. These are critical local fit assumptions, not a printing service's guaranteed whole-part tolerances.

Cap tops are nominally z=15.8 mm below the z=16.8 mm roof. Including the manufacturer's assembled-height tolerance, board thickness and independent ±0.20 mm panel/PCB-seat assumptions, released faces remain at least **0.07 mm recessed**. At maximum 0.5 mm specified pretravel, worst-case recess is **2.43 mm**. A centered rigid R6 mm spherical access probe clears the flared well by at least **1.278 mm** in the analytical screen. This establishes geometric access, not fingertip comfort or off-centre performance. The housing does not preload the caps or stop the switch travel. Test full actuation and return on the first article.

The PCB underside is z=4.6 mm. Untrimmed nominal 3.5 mm leads have 1.10 mm base clearance; the declared worst-case untrimmed stack leaves 0.17 mm. The assembly specification therefore limits the complete lead/fillet projection to **2.60 mm below B.Cu**, trimming if needed, for at least **0.40 mm modeled base clearance**. The switch drilling example uses a 1.6 mm PCB; this design retains 1.2 mm and reserves the greater underside protrusion. Verify body seating and inspect the finished joints.

### Print and assembly preparation

| Folder | Contents |
| --- | --- |
| `case/exports/assembly/` | Assembly-coordinate printed parts |
| `case/exports/print/core/` | Base, top shell, display frame and support bar |
| `case/exports/print/accessories/` | Carrier, cover and wedge |
| `case/exports/print/jigs/` | Temporary flex former |
| `case/exports/reference/` | Purchased caps, switch, battery, panel and PCB envelopes; do not print |
| `case/exports/patterns/` | Clear-sheet lens cutting outline |

`print-layout.json` records print orientations and bed translations. Start home trials with PETG, a 0.4 mm nozzle and 0.15 mm layers. The top shell prints face-down; inspect the recessed display ledge and use local supports if required by the slicer. The base and display supports have flat print orientations. Purchased caps eliminate printed sliding fits, elastomer inserts and cap-retaining screws. [JLC3DP guidelines](https://jlc3dp.com/help/article/3d-printing-design-guideline) and [PCBWay printing capabilities](https://www.pcbway.com/rapid-prototyping/3d-printing/) describe the service limits, not acceptance of these parts.

Four **M2.5 × 10 mm countersunk screws** close the core; use **M2.5 × 12 mm** with the optional 3.2 mm carrier. Verify head seating, pilot engagement and screw-tip clearance before installing electronics.

1. Complete the 87-part SMT assembly. Seat and solder the two B3F-4050 switches from above, inspecting the underside joints and limiting lead/fillet projection to 2.60 mm below B.Cu. B3F is unsealed and not washable; follow the manufacturer's soldering restrictions.
2. Verify unpressed/open and pressed/closed continuity for both controls. Support the PCB beneath each switch and press on the matching cap **after soldering**: ivory on SW1/Filters, orange on SW2/Next. Do not load the display while seating a cap.
3. Install the board, prepared protected-cell/NTC harness, display supports, formed and latched flex, glass, perimeter foam and lens. Verify battery polarity before connection.
4. Lower the top shell over the fitted caps through its clearance openings. Close with the four core screws. Check full return and center/edge actuation again before powering the device.

The assembly checks cover cap insertion through the roof, 0–0.5 mm travel, lateral alignment corners, switch bodies/leads, electronics, glass, flex, supports and carrier fasteners. They do not simulate friction, spring force or cap extraction force. Recovery access still requires opening the display stack.

### What is printed, fabricated or purchased

| Part or operation | Practical route |
| --- | --- |
| L-shaped PCB: 87 SMT parts and two through-hole switches | PCB fabrication and assembly from Gerbers/BOM/CPL; confirm exact parts and the supported routed panel |
| Shell, base, supports, wedge and carrier plastics | Separate prints; qualify material, surface finish, fits and pilot threads |
| E-paper panel, protected battery, switches, caps, controller and NTC | Purchase the selected components |
| Clear lens, foam and insulation | Cut purchased sheet materials using the patterns; reference meshes are not substitutes |
| Battery/NTC harness | Crimp or source pigtails, splice and insulate, bond the sensor and verify polarity |
| Fasteners, magnetic array and steel shield | Source separately; printing supplies their housing, not the functional materials |
| Completed device | Install the controls, flex, glass and cell, close, program and test |

PCBWay advertises complete product and cable-harness assembly, which needs a separately defined scope, instructions and test procedure. JLCPCB states that enclosure integration and box-build assembly are not included in its current workflow. These are advertised services, not acceptance of this design. [PCBWay assembly services](https://www.pcbway.com/pcb-assembly.html), [JLCPCB service scope](https://jlcpcb.com/blog/turnkey-pcb-assembly).

## PCBWay / JLCPCB construction

Use nominal **1.2 mm four-layer FR-4, 1 oz copper, ENIG**, top-side SMT assembly plus separate through-hole switch soldering, through vias and tab routing. Check the current [PCBWay capabilities](https://www.pcbway.com/capabilities.html) and [JLCPCB capabilities](https://jlcpcb.com/capabilities/Capab) at order. No factory has reviewed or accepted an order for this revision.

| Constraint | Design limit |
| --- | --- |
| General trace / clearance | 0.20 / 0.20 mm |
| Fine-pitch escape traces | 0.15 mm minimum, local to dense pads |
| TI DGK adjacent lands | 0.15 mm pad-to-pad exception from the manufacturer pattern |
| Through via | 0.30 mm drill / 0.60 mm diameter; no soldered via-in-pad, blind or buried vias; bare probe contacts can share a through-via |
| Copper / drilled hole to routed edge | 0.50 mm minimum |
| Inside corner | True R1 routed arc |
| Assembly panel basis | 5 mm handling rails, 2 mm routed channels, supported lower/right arms |
| USB | 90 Ω differential target; 0.28 mm main tracks / 0.24 mm gap on B.Cu, local In2.Cu ground reference |

L1 carries components and signals; L2 is mostly ground with local signal crossings outside reserved reference regions; L3 carries power and signals with a dedicated ground corridor under the lower-face USB pair; L4 carries signals and ground fill. Keep that corridor free of foreign traces and inspect the filled copper, including around vias.

The calculation basis is [PCBWay's four-layer stack table](https://www.pcbway.com/multi-layer-laminated-structure.html), entry 17: outer pressed dielectric 0.1855 mm, Dk 4.74, 1 oz inner/outer copper. The published reference lists a 0.630 mm core and 1.21 mm finished board, ±10%. Those simplified listed layers do not sum exactly to the finished thickness. **KiCad uses a 0.689 mm normalized core solely to make the CAD substrate total 1.2 mm**; it does not prescribe that value to the factory. The USB estimate uses the published outer dielectric, not the normalized core. Confirm the actual pressed stack, solder mask and impedance at order; JLCPCB may require a different track width for its offered stack.

Account for approximately 1.33 mm maximum board thickness in assembly checks. The component/case intersection checks operate at the nominal CAD stack; printed seats, foam and flex positioning require first-article tolerance checks. Do not treat nominal collision-free CAD as a production tolerance analysis.

The L outline needs tab routing. Keep tabs clear of the antenna, USB opening and stressed reentrant corner. Factory rails carry fiducials and tooling; the bare board does not carry a duplicate set inside the case. Factory CAM review must confirm supports, tab placement and depanelization. [JLCPCB panel guidance](https://jlcpcb.com/help/article/pcb-panelization), [PCBWay assembly panels](https://www.pcbway.com/pcb_prototype/Panel_Requirements_for_Assembly.html).

The assembly BOM identifies exact MPNs. Blank LCSC fields require exact-part sourcing/consignment, not an inferred substitute. Check supplier stock, pin 1, rotations, stencil apertures and exposed-pad wetting in the order preview. No filled/capped thermal via process is assumed.

### Which factory and order options

**PCBWay turnkey mixed assembly is the recommended first-article route.** The selected stack is the calculation basis, and its sourcing and mixed SMT/through-hole services match the exact-MPN BOM. This is an engineering fit assessment, not a price comparison or accepted quote. [PCBWay assembly scope](https://www.pcbway.com/pcb-assembly.html).

Start with five bare boards and two assembled first articles. Use the exact settings and acceptance conditions in the [fabrication notes](https://github.com/giacomomellone/cicala/blob/main/hardware/rev_b/pcb/fabrication_notes.md), also included in the prototype ZIP. In particular: 1.2 mm four-layer FR-4, 1 oz inner/outer copper, ENIG, green mask/white legend, 90 Ω controlled USB impedance, tab-routed supported panel, electrical test, top SMT plus two through-hole switches, exact MPNs and hidden-joint inspection. Request caps loose. Confirm the tighter ±0.05 mm finished switch PTH tolerance; the ordinary PCBWay allowance is ±0.08 mm.

**JLCPCB Standard PCBA is the alternative**, with factory rails and confirmed stack/impedance. Its current capability table distinguishes Standard from Economic by stack, finish and inspection options. Standard's 70 × 70 mm minimum means the 113 × 62 mm L board needs a supported panel. The existing 87-part JLC BOM/CPL covers SMT only; add/quote the manual operations explicitly or install the switches locally. Current JLC services support through-hole assembly and parts consignment, but availability of this exact BOM must be checked. [JLC capabilities](https://jlcpcb.com/capabilities/pcb-assembly-capabilities), [sourcing/assembly FAQ](https://jlcpcb.com/help/article/pcb-assembly-faqs).

For the first case fit sample, request unpainted Somos Ledo tough SLA resin and inspection of the thin supports, PCB seats and button openings. The 0.8 mm supports and local tolerances need explicit print-service acceptance; do not infer approval from a generic material listing. PETG remains the home-print fit trial. The manufacturing notes specify the files, units, surface treatment and checks.

Digital checks prepare the design for **factory review and prototype fabrication**. Production readiness additionally requires the first-article measurements, factory acceptance and UC8253 firmware integration. Those are open, and `manufacturing.release` remains false.

## Removable phone carrier

The core rotates for carrying, radio end downward. With the carrier it occupies **68.8 × 130.8 mm**, with **20.0 mm** combined depth behind the phone before case/adhesive gaps. Its covered accessory-style magnetic array is a separate, made-to-drawing part, not a generic ring magnet.

The ring is 43.535 mm below the carrier top. On the iPhone 16 Plus reference it overlaps the camera keepout by **6.815 mm** and overhangs the bottom by **6.815 mm**. It fails that fit screen. [Selection evidence](hardware_rev_b_selection.md) gives the dimensions and source. Another phone or mounting position needs a new check, followed by physical optical/flash, retention and RF tests. Detach for wireless charging. The carrier remains experimental and optional.

## Reproduce validation

Use KiCad 10 with footprint/STEP libraries, OpenSCAD, and the repository Python environment with Shapely and Gerbonara. Install the hardware helper dependencies with `.venv/bin/python -m pip install -r hardware/tools/pcb/requirements.txt`. Regenerating fitted envelopes requires CadQuery, tested with 2.8.0. Optional tool variables are `KICAD_CLI`, `KICAD_PYTHON`, `KICAD10_3DMODEL_DIR`, `OPENSCAD_BIN` and `CAD_PYTHON`. Linux needs a Python that imports `pcbnew`; renders need a display or `xvfb-run`.

```sh
just hw-rev-b-check
CAD_PYTHON=/path/to/python-with-cadquery just hw-rev-b-export --renders
just hw-rev-b-fab-export
```

Reports are written under `build/hardware-rev-b/`. The checks cover the actual concave outline, component courts/models, one fitted assembly face and underside bare diagnostic contacts, mounting and pad-to-edge clearance, centered active screen, RF exclusion, source fingerprints, schematic/PCB netlist parity, ERC and DRC. The electrical check requires zero unconnected items.

Mesh checks require closed, oriented single solids for each printable part. Intersection checks cover components, battery, PCB, display, supports, harness, flex, carrier and caps across their stroke. Purchased cap and lead clearance calculations include the declared print and component tolerances. `--mechanical-only` explicitly skips electrical checks and labels its report accordingly.

Physical acceptance remains: first power and recovery; exact panel waveforms and fold; charge/NTC and pulse loads; purchased-cap fit, actuation and retention; enclosure assembly and optical support; optional phone retention and loaded RF. These measurements follow fabrication of the engineering prototype.

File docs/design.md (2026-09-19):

# Design

Product and interaction rationale. [Theory](theory.md) governs question writing.

## The principle

**Minimize time-to-question, maximize time-in-conversation.** Start with a question.
The originality belongs in the writing and its variety, rather than a taxonomy
that people must learn before talking.

## One mixed stream

Questions have no relationship categories. Each question is stored once per
language with editorial depth and optional tags. There is no topic taxonomy,
new emotional-weight scale, intensity ladder, or inferred readiness.

Depth means the existing disclosure cost:

1. Little public exposure.
2. A personal construction.
3. Vulnerability, conflict, fear, loss, or consequential disclosure.

Forms describe how a question invites an answer: `icebreaker`, `reflective`,
`hypothetical`, `memory`, and `wouldyourather`. Form tags guide variety and remain
available in Browse. They are not modes of play.

The ordinary pool includes depths 1 and 2, with Dark and Sexual excluded.
Thoughtful, gentle questions can belong here. Editorial review must ensure that
a standalone question does not depend on everyone sharing a particular
relationship. Existing wording and IDs remain human-owned.

## Optional permissions

| Filters row | What enabling it permits |
| --- | --- |
| Dark | Questions tagged `dark`: macabre material, morbid scenarios, disturbing imagery |
| Sexual | Questions tagged `sexual`: sexual experiences, desire, explicit material |
| Heavy | Depth 3: vulnerable or consequential disclosure |
| Done | Apply the draft and resume play |

These are independent permissions. A dark, sexual depth-3 question needs all
three. Enabling a permission adds eligible questions to the mixed pool. It does
not select a separate channel. Absurdity, playfulness, ordinary disagreement,
and emotional depth alone do not imply sexual content.

The old `spicy` tag is retired. It was broader than Sexual, so pending submissions
with that tag need explicit human reclassification. It must never be silently
converted. Production question texts and IDs are unchanged by this migration.

## Two-button interaction

The small physical button is **Filters**; the large one is **Next**. The phone
and web player use the same controls and state transitions. On web and phone,
each filter row is also a clickable toggle, and Done can be tapped directly.
Tapping a row selects it for subsequent Filters / Next input. These edits use
the same draft and apply only at Done.

| Input | During play | In Filters |
| --- | --- | --- |
| Filters | Open the menu with Dark selected | Move to the next row; Done wraps to Dark |
| Next | Draw a permitted question | Toggle the selected permission, or apply Done |
| Hold a button | One action on release | One action on release |
| Both buttons held through boot | Open service setup | Existing service gesture |

All four menu rows are visible. The e-paper explains “Filters: move” and
“Next: change / done”; the cap labels stay fixed. Changes remain a draft until
Done. Done resumes the same question if it is still permitted, otherwise it
selects an eligible replacement. An empty pool shows an empty state with Filters
still reachable. Question-specific save, share, edit, and provenance controls
are hidden while the menu is open.

During play, a compact summary shows each permission as included or excluded.
A discarded press changes no state. Firmware stages the question, bag, draft,
and permissions, committing only after a successful matching display result.
A failed queue, denied refresh, error, or timeout does not silently consume a
question or apply a permission.

## Fresh starts and sleep

All permissions start excluded. During use, they persist through device deep
sleep and same-tab browser reloads and navigation. The browser uses
`sessionStorage`; a fresh tab/session starts excluded. Favorites and language
preferences still use `localStorage`.

The device retains the menu cursor, draft, permissions, question text snapshot,
and per-language selection state in validated RTC memory. Full power loss or an
invalid RTC block restores defaults. A corpus fingerprint change clears its
index-based selection state. A copied question snapshot remains safe to display
even when the underlying corpus buffer is replaced.

## Selection and variance

Both platforms select at draw time, using one bag per language and a recent
window of 20. Filter changes preserve seen history. The priority order is:

1. Require every relevant permission.
2. Prefer unseen eligible questions. Reopen the eligible cycle only when exhausted;
   excluded questions retain their seen state.
3. Avoid recent questions when possible, then avoid the current question when possible.
4. After depth 3, prefer a non-3 question within those candidates.
5. Prefer a different depth band (1 versus 2/3) and a different form; each repetition
   costs one point.
6. Choose randomly within the best remaining group.

A breather never forces an early repeat. Small pools can relax recency and
texture, but permissions never relax. A singleton can repeat; an empty pool
stays empty. There is no escalation schedule, turn count, or judgment of the table.

## Website jobs

- The landing at `/` opens the question app at `/play`.
- Play mirrors the device and adds visible save/share actions. F opens or advances
  Filters; Space and Right perform Next. There is no previous/forward replay history.
- Browse exposes all questions with search, depth, tags, and sort. Play permissions
  do not filter Browse.
- Saved and shared collections remain at `/deck`, without relationship chips.
- Direct question links display their named question regardless of play permissions.
  They do not enable permissions; Next returns to the allowed automatic pool.
- Contribution collects original human wording. Editors assign depth and precise tags.
- Info introduces the project in a few sentences; Device links to the hardware README.

The website uses orange and yellow with wine-coloured ink, bold sans-serif
branding and Zilla Slab questions on cream. The circular cicada and question
transitions respect reduced motion. See the [brand guide](brand.md).

## Why a device

The device stays a shared object: e-paper keeps the conversation visible at
zero display power, without accounts, notifications, Bluetooth, or an app.
Wi-Fi and language setup remain on a phone. Sync is optional and does not
interrupt the displayed question. There are no physical favorites or automatic
session progression.

QDB4 removes category masks. Question manifests use schema 4 and require
firmware 0.2.0; RTC layout version 3 replaces version 2. A stored QDB3 bundle is
rejected and the embedded QDB4 corpus is the fallback. The electrical aliases
and enclosure geometry retain their existing identifiers; visible labels become
Filters. See [the protocol](sync_protocol.md) and
[firmware architecture](firmware_architecture.md).

Physical validation still needs to check menu legibility, accepted versus
dropped presses during real e-paper refreshes, wake replay, and total power loss.

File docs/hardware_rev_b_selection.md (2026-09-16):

# Rev B component selection evidence

Reviewed 15 September 2026. The selections in `hardware/rev_b/component_selection.csv` are applied to the native Rev B design. The assembled board has not been powered or measured. [The engineering notes](hardware_rev_b.md) describe the current geometry; this page records the source evidence and the decisions that need first-article measurements.

## Controller, display and boost

Retain **ESP32-S3-WROOM-1-N16**, native USB, recovery contacts and 16 MB flash. Use **Waveshare SKU 22609, 3.52-inch V1.1, UC8253**, with a 360 × 240 landscape image. The [V1.1 panel drawing](https://files.waveshare.com/wiki/3.52inch%20e-Paper%20HAT/3.52inch%20e-Paper%20V1.1.pdf) specifies pins 1 and 4 NC and pin 5 VDHR. The [linked HAT schematic](<https://files.waveshare.com/wiki/3.52inch%20e-Paper%20HAT%20(B)/3.52inch_e-Paper_HAT.pdf>) uses older names: pin 1 is unconnected; pins 4 and 5 each have a capacitor to ground. It does not externally drive pin 5 as a gate voltage.

The implementation follows the V1.1 pin table: **pins 1/4 NC, pin 5 VDHR with 1 µF to ground**. The PCB net name `EPD_VSH2` at pin 5 is the inherited host-side name for that reservoir. Pin 4 has no fitted or optional capacitor. This reconciles conflicting documents; it is not a vendor-issued correction. Compare actual rail waveforms with a reference HAT during bring-up.

| Circuit role | Applied MPN / value |
| --- | --- |
| L1 | TDK VLS4012CX-680M-1, 68 µH |
| Q1 | Diodes BSS138-7-F, SOT-23: gate 1, source 2, drain 3 |
| D1–D3 | Diodes MBR0530-7-F |
| R20 / R19 | Yageo RC0603FR-073RL / RC0603FR-0710KL, 3 Ω / 10 kΩ |
| C15 / C16 | Murata GRM31CR71H475KA12L, 4.7 µF, 50 V, X7R, 1206; 1.8 mm maximum height |
| C17–C24 | Samsung CL21B105KBFNNNE, 1 µF, 50 V, X7R, 0805 |

The boost topology follows the HAT. C15 is input decoupling; C16 is the flying capacitor. The HAT input regulator and level translator are unnecessary with a 3.3 V host. Direct logic, panel supply switching and GPIO parking are retained. Check gate drive, rail startup, MLCC capacitance under bias and inductor current on the prototype. [TDK](https://product.tdk.com/en/search/inductor/inductor/smd/info?part_no=VLS4012CX-680M-1) specifies 1.625 Ω maximum DCR and 320 mA minimum saturation current at its 30% inductance-drop criterion. Sources: [BSS138](https://www.diodes.com/datasheet/download/BSS138.pdf), [Samsung capacitor](https://product.samsungsem.com/mlcc/CL21B105KBFNNN.do), [Murata capacitor](https://search.murata.co.jp/Ceramy/image/img/A01X/G101/ENG/GRM31CR71H475KA12-01A.pdf).

### Firmware interface

Zephyr [PR 113230](https://github.com/zephyrproject-rtos/zephyr/pull/113230) added UC8253 support, merged 4 August 2026 as `4420c8ce85d91ac7f309cb5fb1b13e75b843a844`. Cicala still pins Zephyr 4.4.1, whose checked-out driver lacks that support. The selected bring-up path is a reviewed project-owned backport; do not edit `deps/`. The [binding](https://docs.zephyrproject.org/latest/build/dts/api/bindings/display/ultrachip%2Cuc8253.html) uses active-low BUSY. Address the controller as **240 × 360**, then rotate the UI. A monochrome framebuffer occupies 10,800 bytes. Start with full refresh and the panel waveform settings. This hardware revision does not implement or validate that firmware port.

## Display connector and fold

**Molex 503480-2400** has dual contacts, a 0.30 ±0.05 mm FPC interface, 1 mm nominal body height and **1.58 mm insertion**. Its [manufacturer drawing](https://www.molex.com/content/dam/molex/molex-dot-com/products/automated/en-us/salesdrawingpdf/503/503480/5034802400_sd.pdf) requires at least 2 mm exposed contacts and 3 mm reinforcement. The panel drawing gives 3.15 ±0.30 mm contacts and 3.65 ±0.30 mm reinforcement, which meet those lengths.

The earlier FH12 selection was rejected: its [Hirose family drawing](https://www.hirose.com/en/product/series/FH12) calls for a longer reinforced end and exposed contact region than this panel supplies. Connector pitch and cable thickness alone did not establish compatibility.

The custom land pattern follows Molex drawing 503480 rev J/J1: 24 lands at 0.5 mm pitch, each 0.30 × 0.70 mm; two 0.30 × 1.00 mm retention lands at ±6.54 mm. Pin 1 is the left rear contact in the footprint drawing. The board rotates the footprint 90°, with cable entry toward the right. Inspect pin 1 and the dual-contact latch in the assembly viewer before ordering.

The supported static fold uses **R1.55 mm inside radius**. With maximum flex thickness 0.13 mm, minimum 9.70 mm tail, maximum 3.95 mm stiffener and 0.40 mm straight at the glass bond:

`9.70 − 3.95 − π × (1.55 + 0.13/2) − 0.40 = 0.276 mm`

That is the remaining length allowance, not a physical measurement. The nominal folded centerline fits the 10 mm tail with the reinforced end straight. The CAD entry height of **6.115 mm** is an assembly assumption based on the connector envelope, not a dimensioned contact-plane tolerance. Check insertion, contact side, latch access and bond loading on the first article. Use the rounded former as an assembly jig; remove it after forming. [Minco's static-flex guidance](https://www.minco.com/wp-content/uploads/Designing-a-Flex-Circuit-for-Flexibility.pdf) supports a starting bend ratio; it does not qualify this particular panel construction. Do not force the fold or bend the stiffener.

## Battery and harness

Select **Renata ICP303450PA-02 / 100701**, protected, 500 mAh minimum / 510 mAh typical, maximum 52 × 34.5 × 3.6 mm. Its [datasheet](https://www.renata.com/en-us/downloads/?fileid=362eb77e217c713a5b0570752b&product=icp303450pa-02) specifies 510 mA continuous discharge; its 1.02 A noncontinuous figure has no usable pulse-duration qualification. Use **Semitec 103JT-025**, an insulated 10 kΩ B3435 film NTC, maximum 0.5 mm thick, following the [sensor drawing](https://www.semitec-global.com/uploads/2022/01/P9-JT-Thermistor.pdf).

Retain BQ25185DLHR, TPS63802DLAR, TPS22917DBVR and the TLV9022DGKR charge-temperature veto. R8 = 3.00 kΩ selects nominal **100 mA charging**, with 4.2 V regulation. The JT-table tolerance model gives a nominal permission window of 4.44–37.05 °C and positive static stop margins at 0 and 45 °C; sensor bonding and thermal lag require physical measurements. Charging must remain inside the pack's 0–45 °C range including circuit tolerances. Hardware protection, the NTC veto and firmware have separate roles; verify all on the sample.

The low-profile **JST SM03B-SRSS-TB(LF)(SN)** uses **SHR-03V-S** and **SSH-003T-P0.2** contacts. Its wire range requires **AWG28 pigtails spliced to the pack's AWG26 leads**; do not crimp the stock leads directly into these contacts. Use at most 40 mm per power pigtail, individually insulated joints and strain relief. The 80 mm round-trip AWG28 copper contributes approximately 18 mΩ before connectors and joints. Pin 1 is protected BAT+, pin 2 NTC, pin 3 protected ground; the NTC returns to that ground. Keep the pack's factory protection. [JST SH drawing](https://www.jst-mfg.com/product/pdf/eng/eSH.pdf).

The 54 × 36 × 4.8 mm battery reservation includes the NTC, attachment, insulation and clearance. It is not a supplier-approved lifetime expansion allowance. Capture battery current and rail minima during Wi-Fi, OTA and display refresh. A 350 mA, 3.3 V load at 3.0 V battery and assumed 90% converter efficiency already needs about 428 mA from the cell. Schedule radio and refresh separately where possible and validate shutdown margin above the 3.0 V discharge endpoint. Runtime is not yet measured.

## Controls and magnetic carrier

**Omron B3F-4050** is selected for both controls. The projected 3.8 mm square plunger matches **B32-1200 (ivory, 9 × 9 mm)** and **B32-1320 (orange, 12 × 12 mm)**. The caps are 5.5 mm high and both reach 10.0 ±0.4 mm above the PCB when seated. The B3F drawing specifies a 12 × 12 mm body, 7.3 ±0.2 mm projected-plunger height, 1.27 ±0.49 N operating force and 0.3 +0.2/−0.1 mm pretravel. The 1.27 N B3F-4000 family rating is three million operations; this is the component rating, not measured device life. [Omron B3F](https://omronfs.omron.com/en_US/ecb/products/pdf/en-b3f.pdf), [Omron B32](https://omronfs.omron.com/en_US/ecb/products/pdf/en-b32.pdf).

The local centered footprint follows the top-view drilling diagram: four 1.2 mm PTH holes on a 12.5 × 5 mm grid and two 1.8 mm NPTH positioning holes, 9 mm apart. Logical pin 1 joins the top terminal pair, pin 2 the bottom pair; the PCB also connects each duplicate pair in copper. These logical numbers intentionally collapse the manufacturer's four physical terminal numbers into the existing two-pin switch symbol. The 2.4 × 2.0 mm oval lands provide at least 0.4 mm nominal annular copper. Specify finished hole sizes; the manufacturer drawing calls for ±0.05 mm hole tolerances. Ask the fabricator to confirm these at order.

The 22 kΩ pull-ups draw about 150 µA at 3.3 V. This exceeds Omron's reference minimum applicable load of 10 µA at 1 V, though it is below the general 1 mA rated-load range. Confirm reliable low-current switching on the first article. B3F-5051 is a compatible projected-plunger gold-contact alternative if contact reliability testing warrants a substitution; it is not the selected BOM part. B3F is unsealed/IP00 and cannot be washed. Solder the switches after the SMT cycle, then mount the caps; heating installed caps can deform them.

The removable carrier specifies a made-to-drawing **CIC-MAG-01** accessory array; this is not a stocked MPN. The [Apple accessory guidelines](https://developer.apple.com/accessories/Accessory-Design-Guidelines.pdf), 8 June 2026, §42, describe 54.10/46.00 mm ring geometry, N48H magnets, radial polarity and a steel DC shield. The CAD reserves 1.10 mm magnets, 0.05 mm adhesive, 0.70 mm shield, 0.85 mm cover and 0.50 mm support, totaling **3.20 mm**. A generic axial ring is not an equivalent specification. Actual magnetic field, force and certification are unverified.

The former reference phone was [iPhone 16 Plus](https://developer.apple.com/download/files/accessories/dimensional-drawings/iphone-16-plus.pdf): 77.76 × 160.89 mm, ring center 80.44 mm from the top, camera keepout ending at 43.72 mm. The widened carrier is now **68.8 × 130.8 mm** in portrait. With the retained ring datum it occupies y=36.905–167.705 mm: **6.815 mm into the camera keepout and 6.815 mm beyond the phone bottom**. This revision therefore fails that nominal phone-fit target. The carrier stays an experimental removable accessory; another mounting position or phone requires a new dimensional check. It is not presented as a confirmed phone-compatible product. Retention, optical clearance, cases and loaded RF remain physical checks; detach for wireless charging.

## Qualification after fabrication

No further user component decisions are required. Build a small engineering batch, then check power and recovery, the exact panel and fold, charging/NTC and pulse loads, purchased button operation, optical support and attached radio behavior. Supplier CAM/assembly review belongs to the prototype order. It does not require delaying digital routing until the user obtains hardware.

If the panel fold fails on a sample, [GDEY037T03](https://www.good-display.com/product/437.html) is the preselected larger-panel redesign candidate. Its 92.99 × 53 mm glass requires a new envelope and circuit review; it is not a drop-in substitute. The smaller [GDEY031T10](https://www.good-display.com/product/426.html) sacrifices image area. Do not force an incompatible flex into the current design.

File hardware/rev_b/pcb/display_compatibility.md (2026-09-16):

# Display compatibility work after the fit study

The current firmware supports the Rev A panel. The new display is **not compatible by changing only the enclosure or bundle contents**. This milestone changes no firmware.

## New target contract

The candidate active matrix is 360 × 240 pixels in landscape. A packed monochrome framebuffer has 10,800 bytes before driver-specific alignment or secondary buffers. Confirm the controller, SPI protocol, waveform tables and power sequence against the exact supplied panel revision.

The V1.1 pin table calls BUSY_N active low while busy. The driver and GPIO flags must match the actual device. Do not copy the old panel's busy interpretation. The visible active area is centered mechanically, but the flex exits right; establish the software rotation with a labelled corner/checkerboard pattern on hardware.

The retained host pins are EPD_PWR_EN GPIO5, RESET GPIO8, BUSY GPIO9, CS GPIO10, MOSI GPIO11, CLK GPIO12 and DC GPIO18. Treat the copied `pin_contract.csv` as the host wiring proposal, not proof that the new driver can run. Park host outputs safely when panel power is off and verify the power switch, bleed path, boost voltages and leakage on the new panel.

## Before a firmware target

Resolve the vendor pin-table/application-circuit discrepancy, select the boost components, fit the FPC without bending its stiffener and confirm connector contact side. Then measure full refresh, usable partial-refresh behavior (if any), temperature effects, ghosting, wake latency and the complete power-off state. Revisit text wrapping, glyph size and question presentation for the larger matrix without changing the question corpus.

Signed question bundles remain an application-data format. A panel change does not make a competitor's firmware accept those bundles, nor does it make a Cicala firmware image compatible with a different bootloader. A future donor-device port needs its own storage/install adapter, signature verification, driver mapping, partition budget and recovery/rollback validation.

Sources: [Waveshare candidate](https://www.waveshare.com/product/displays/e-paper/3.52inch-e-paper.htm) and [V1.1 documentation](https://files.waveshare.com/wiki/3.52inch%20e-Paper%20HAT/3.52inch%20e-Paper%20V1.1.pdf). See [the engineering contract](../../../docs/hardware_rev_b.md) for the current unresolved gates.

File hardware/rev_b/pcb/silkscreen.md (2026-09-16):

# Reading the Rev B board

The native `F.SilkS` and `B.SilkS` layers contain the Cicala wordmark and cicada,
functional boundaries, connector legends and a service guide. These markings
are part of the manufactured Gerbers. KiCad groups the added graphics as
**Rev B identity and service guide**.

## Front

Open brackets identify the display/boost, charge-temperature guard, power and
debug areas without crossing component bodies or solder openings. Large IC and
connector labels give the function alongside the reference. Dense passive
designators remain on `F.Fab` and in the assembly PDF.

The probe labels name the signals directly: `BOOT`, `EN`, `GND`, `3V3`, `BAT`,
`SYS`, `5V`, `S1`, `CLK`, `MOSI`, `CS`, `DC` and `BUSY`. `S1` means charge
status 1. J3's `+`, `T` and `-` align with its battery-positive, thermistor and
ground pins. J2 identifies the e-paper connector and downward-facing flex
contacts. Both switches and the status LED are named.

## Back

The underside is read with the board flipped over; its artwork is mirrored in
KiCad coordinates. It provides:

- Revision B.05, module/flash identification, four layers and 1.2 mm thickness.
- USB/battery/system/3.3 V power flow, nominal 100 mA charging and the U7/Q2
  temperature veto.
- The top-side test-point number key and direct labels for all seven bottom
  test contacts. Numbers refer to `TP` references; `BAT` is the charger-side
  battery rail and `CELL+` is the protected pack connector's positive rail.
- J4's six-pin recovery mapping, MCU-relative TX/RX direction and boot/reset
  sequence. J4 pin 1 is **3.3 V reference only**, not a power input.
- J3 polarity and the protected single-cell LiPo / bonded 10 kΩ B3435 NTC
  requirement, plus the J2 UC8253 display identification.
- An antenna-clearance reminder and the hardware license identifier.

`FACTORY OD` identifies an open-drain firmware signal; its eventual factory
operation remains unqualified. The printed service guide does not replace the
schematic or the first-power procedure.

## Print rules and checks

Main legends are 1.0 mm high; compact probe and connector labels are 0.8 mm.
Text and outline strokes are at least 0.15 mm. KiCad enforces 0.15 mm silk
clearance to edges and other markings, and checks solder-mask clipping. The
front text was also checked against the fitted component envelopes. The local
L1 outline is shortened on its Q1-facing side to preserve the ink gap; its
lands, courtyard and component position are unchanged.

The generator verifies every test-point net and both service-connector pinouts
before editing. Regression checks preserve copper, pads, placements, outline
and model geometry. The manufacturer must still review the resulting artwork;
physical print quality has not been measured.

## References

- [Adafruit ESP32-S3 Feather](https://learn.adafruit.com/adafruit-esp32-s3-feather/pinouts):
  nearby power, pin, reset/boot and hardware-variant labels. Rev B uses this
  approach for service information placed beside the relevant contact.
- [SparkFun PCB Basics](https://learn.sparkfun.com/tutorials/pcb-basics/all):
  silkscreen as a human-readable explanation of pins, LEDs and assembly.
- [PCBWay legend guidance](https://www.pcbway.com/helpcenter/design_instruction/How_to_make_my_silkscreen_clear_and_beautiful_on_PCB__.html):
  at least 0.15 mm strokes and 0.8 mm character height for ordinary positive text.
- [JLCPCB silkscreen guide](https://jlcpcb.com/blog/pcb-silkscreen-printing-guide):
  readable lettering, pad clearance, identity and service markings.

Reviewed 15 September 2026. No third-party artwork was copied. The logo and
wordmark are the project's existing public brand assets.

## Regeneration

From the repository root:

```sh
.venv/bin/python hardware/tools/rev_b/silkscreen.py
just hw-rev-b-check
just hw-rev-b-pcb-renders
just hw-rev-b-fab-export
```

The [render directory](renders/README.md) includes straight top/bottom PNGs and
zoomable SVG plots of both silkscreen layers with solder openings. The device
page imports these files directly. Refresh the complete enclosure export when
updating its source manifest, even though silkscreen does not change the fit.

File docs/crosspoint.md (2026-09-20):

# Cicala on Xteink X4 Pro

[cicala-crosspoint](https://github.com/giacomomellone/cicala-crosspoint) adds
Cicala to CrossPoint's Home menu. It targets the Xteink X4 Pro. CrossPoint keeps its
book reader, settings, networking, and device drivers. Cicala owns the question
session and its signed bundle store.

The implementation has host tests and builds for X4 Pro. Touch and physical button mapping,
panel refreshes, sleep current, peak heap, and installation through firmware
OTA still need checks on a device. The public English corpus is currently empty;
the embedded fallback therefore shows the empty-deck state. Existing firmware
test questions are packaged only as test fixtures.

## Shared code

```mermaid
flowchart TD
    YAML[Human-authored question database] --> Builder[Python bundle builder]
    Builder --> Bundle[Signed QDB4 bundles]
    Core[Portable C++ core] --> Zephyr[Zephyr adapter]
    Core --> X4[CrossPoint activity and SD adapter]
    Bundle --> Zephyr
    Bundle --> X4
    Contract[Shared selection fixtures] --> Core
    Contract --> Website[TypeScript website engine]
```

`core/` contains QDB4 parsing, permission eligibility, selection and recency,
transactional Filters/Next behavior, bundle verification, and an explicit SD
snapshot codec. It has no Arduino, Zephyr, network, filesystem, or display
dependency. It uses C++17, fixed capacity state, and no dynamic allocation.

The Zephyr application compiles these sources through its existing CMake
library adapters. Its RTC layout and three language bag slots remain intact.
The website retains its TypeScript implementation. Both languages run
`core/tests/fixtures/selection.json` to check eligibility and seen-history rules;
they need not produce the same random ordering among equally ranked candidates.

The fork consumes a versioned archive with a SHA-256 pin. That archive contains
the core, the public verification key, and an English offline bundle. It has no
dependency on another local repository or a private repository. A local archive
override supports development before publication.

## Session and display contract

Preparing an action creates a token and a bounded copy of the proposed view.
Permissions, draft state, displayed question, and bag history change only after
the matching render completes. Failed, timed-out, cancelled, and stale renders
cannot consume a question. Input pressed during a refresh remains suppressed
through its later release.

Filters opens the draft menu and moves the cursor. Touch can activate a filter
row directly; each tap follows the same display-commit contract. Next toggles a permission;
on Done it applies the draft. The current question remains if it is still
eligible. Otherwise the core selects another question. New session resets
permissions and history after the new view renders successfully.

CrossPoint's activity uses its logical buttons and touch coordinates, wraps the
whole question, and falls back to a smaller font when necessary. Layout failure
does not commit the question. It uses one framebuffer, starts with a full
refresh, and requests another full refresh after ten partial refreshes.

A small FreeInk SDK patch adds an opt-in checked refresh result. The Pro adapter
checks BUSY completion using the detected panel controller's protocol.
SSD1677 requires a BUSY assertion and completion. UC8179/UC8279 retain the SDK's
one-tick wait followed by idle-HIGH completion; a stuck LOW times out, but this
level-based protocol cannot diagnose a disconnected line that reads HIGH.
The build applies the patch to an ignored copy of the pinned SDK display
library. The SDK submodule remains unchanged. The fork includes host tests of
the patched bus implementation with simulated GPIO and semaphore behavior.

## Persistence and updates

Normal power-off loses RAM. Its SD card is authoritative for
sessions. Two alternating, checksummed session records retain the question,
permissions, draft cursor, and bag history. The codec writes fields explicitly
in little-endian order and rejects incompatible capacities. Records are 265
bytes with the default configuration. A new record is reopened and checked
before it becomes the active generation.

Sessions save on leaving Cicala, preparing for sleep, and completing New session.
An unexpected power cut can lose changes since the last save. Normal sleep
preserves the committed question or filter view. A consumed-on-boot SD marker
requests Cicala resume; panic recovery and holding the Pro's right page button (Down) take precedence. Opening
books and returning to Cicala restores the saved session.

Question updates are manual. Cicala reuses CrossPoint's Wi-Fi selection and HTTP
transport. Its worker releases the active corpus allocation during networking,
then checks the downloaded file's size, SHA-256 digest, Ed25519 signature, QDB4
structure, language, version, count, UTF-8, and question length. The payload's
signed header must match the manifest. A bundle is limited to 32 KiB and 512
questions, each at most 128 UTF-8 bytes. Two payload/manifest slots keep the old
verified bundle available if a write is interrupted. Every reopen verifies the
signature again; two invalid slots fall back to the compiled English bundle.

An updated corpus clears incompatible selection indices while keeping the
copied current question and explicit filter state. The update task stops before
the activity is destroyed. A Wi-Fi connection opened by Cicala is shut down
after updating or cancelling; play itself performs no networking.

Firmware OTA replaces the combined CrossPoint/Cicala application. Its version
starts at `0.1.0`, independently of CrossPoint's version. It follows the fork's
GitHub releases and selects `cicala-crosspoint-<version>-x4pro.bin`. Core packages,
firmware versions, upstream revisions, and question bundle versions are separate
identities. Bundle `min_fw` is compared with the shared sync contract version,
currently `0.2.0`, rather than either project's release number.

## Development and rollout

Run `just test-core` and `just core-package` here. Build the fork with
`CICALA_CORE_ARCHIVE=/absolute/path/to/cicala-core-0.1.0.tar.gz pio run -e cicala`.
The fork's [development guide](https://github.com/giacomomellone/cicala-crosspoint/blob/cicala/docs/cicala.md)
contains setup, native HTTP tests, release staging, and the hardware checklist.

Publish a core package from a clean, reviewed Cicala revision before releasing
firmware. Then replace the fork's development archive checksum with the checksum
of that published package. The intended `core-0.1.0` URL is not populated by a
local build. During review, the fork can reproduce the same archive from its
pinned public source commit if that release asset is absent; release builds
require the published asset. Release provenance records both source revisions and artifact
hashes; a development archive's dirty provenance cannot pass the release gate.

The production bundle feed also needs verification before release. During this
implementation, `device.cicala.dev` did not resolve from the development host.
Local HTTP tests cover signed updates independently of that service.

Keep `develop` aligned with upstream and maintain the product on `cicala`.
Merge upstream into the shared product branch; rebase unpublished feature
branches as useful. The fork's daily workflow tries an upstream merge in a
disposable checkout, builds X4 Pro, and runs the native suites. It does not update
branches. Set `cicala` as the fork's default branch when it is published so the
scheduled workflow runs there. SDK changes require reviewing the checked-refresh
patch and its pin before adoption.

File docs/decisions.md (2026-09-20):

# Decisions

Append-only decision log (ADR-lite). One `##` per decision, newest last. Decisions marked DECIDED in the handoff specification (`Cicala — Project handoff specification.md` at the repo root) are not repeated here; this file records choices the spec left OPEN, plus every dependency added.

## 2026-07-24: Repo bootstrapped from the handoff specification

Phase A (database + tools), Phase B (website), and structure-only stubs for firmware/hardware created in one pass. Git history starts here; the spec document itself is kept at the repo root as the founding reference.

## 2026-07-24: Placeholder org and domain

The GitHub repository is `giacomomellone/cicala` and the site domain is `cicala.dev`. Both live in exactly one place each (`website/src/config.ts`; `$id` in `questions/schema.json`; `--base-url` default in `tools/build_bundle.py`; CODEOWNERS handles in `.github/CODEOWNERS` and maintainer names in `docs/languages.md`).

## 2026-07-24: Tests use stdlib unittest, not pytest

The tools dependency policy is "stdlib + pyyaml + jsonschema only"; adding pytest for tests would be the first violation of the policy in the same commit that introduces it. `python -m unittest discover tools/tests` needs nothing extra.

## 2026-07-24: Ed25519 signing via system openssl, not a Python package

`build_bundle.py`/`keygen.py` shell out to `openssl` (≥ 1.1.1, present on GitHub runners and dev machines) instead of adding `cryptography` or `pynacl`. Keeps the tools dependency policy intact; the signature is standard ed25519 over the bundle's raw SHA-256 digest, so the firmware side can use any conforming verifier. Unsigned dev builds are allowed (`"sig": null`) and must be rejected by release firmware.

## 2026-07-24: Denylist semantics: whole-word match on normalized text

Terms (including multi-word phrases) match case-insensitively as whole words against the NFC-lowercased, whitespace-collapsed text. Substring matching was rejected for Scunthorpe-problem false positives. A hit is a CI failure that asks for manual maintainer review, and no cleverness beyond that, per spec.

## 2026-07-24: `--fix` rewrites only files that validate cleanly

`validate.py --fix` never rewrites a file that produced errors, so a broken submission can't cause data-destroying reformats. Rewritten files carry a fixed 3-line header comment; hand-written comments in question files are not preserved (the files are tool-managed).

## 2026-07-24: Browse "newest" sort uses reverse file order

`added` is stripped from the main payloads (spec §5), so the browse page sorts "newest" by reverse position within each category file. Files are append-only, so file order _is_ chronological order. `recent.{lang}.json` (which keeps `added`) stays the source for the contribute page's recent list.

## 2026-07-24: Website shows the device's display id

The meta line's `#<id-short>` uses the same formula as the OLED (`decimal of first 2 id-hash bytes mod 10000`, e.g. `#6666`), so a question has one human-visible number across site and device. Collisions are cosmetic and accepted, same as on the device.

## 2026-07-24: Permalinks switch the active language

Visiting `/q/<id>` sets the active language (`cicala.lang`) to that question's language. A shared German link therefore lands in a fully German experience, and "next question" continues in German. The alternative (keeping the visitor's old language) would show a German question inside English chrome and then jump languages on the first keypress.

## 2026-07-24: Generated site data is not committed

`website/src/data/*.json` is gitignored; `tools/build_site_data.py` regenerates it locally and in CI before every build. The question YAML stays the single source of truth, and PR diffs never contain generated blobs.

## 2026-07-24: npm dependencies (website)

Per the guardrail, every package with a one-line justification:

- `astro`: the decided framework (spec §7.1).
- `@fontsource/literata`, `@fontsource/ibm-plex-mono`: the decided self-hosted fonts (spec §7.1); fontsource is the standard way to self-host with subset files.
- `typescript` (dev): required for `.ts` islands and editor support; ships no runtime bytes.

## 2026-07-24: firmware.yml gates on the project existing

The firmware CI workflow checks for `firmware/CMakeLists.txt` and exits green with a notice while only the structure stubs exist (this build), so CI isn't red for months. The `idf.py build` path activates automatically once the phase-C skeleton lands.

## 2026-07-24: GitHub issue form uses a multi-select dropdown for tags

GitHub issue forms cannot URL-prefill checkbox groups, and the contribute page must prefill everything. Tags are therefore a `dropdown` with `multiple: true` (prefillable); the CC0 confirmation stays a required checkbox the contributor must tick on GitHub, which is exactly the explicit consent we want anyway.

## 2026-07-24: Doc filenames are snake_case; just is the repo entry point

`docs/` files renamed from SCREAMING_SNAKE_CASE to snake_case (`design.md`, `decisions.md`, `languages.md`, `sync_protocol.md`) per maintainer preference; root-level `README.md`/`CONTRIBUTING.md`/`CODE_OF_CONDUCT.md` keep their conventional names because GitHub's UI treats them specially. A `justfile` is the single entry point: typing `just` lists every command (database, website, docs, tests, firmware); recipes call the `.venv` tools directly so nothing needs to be on PATH except `just`, `python3` and `npm`.
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

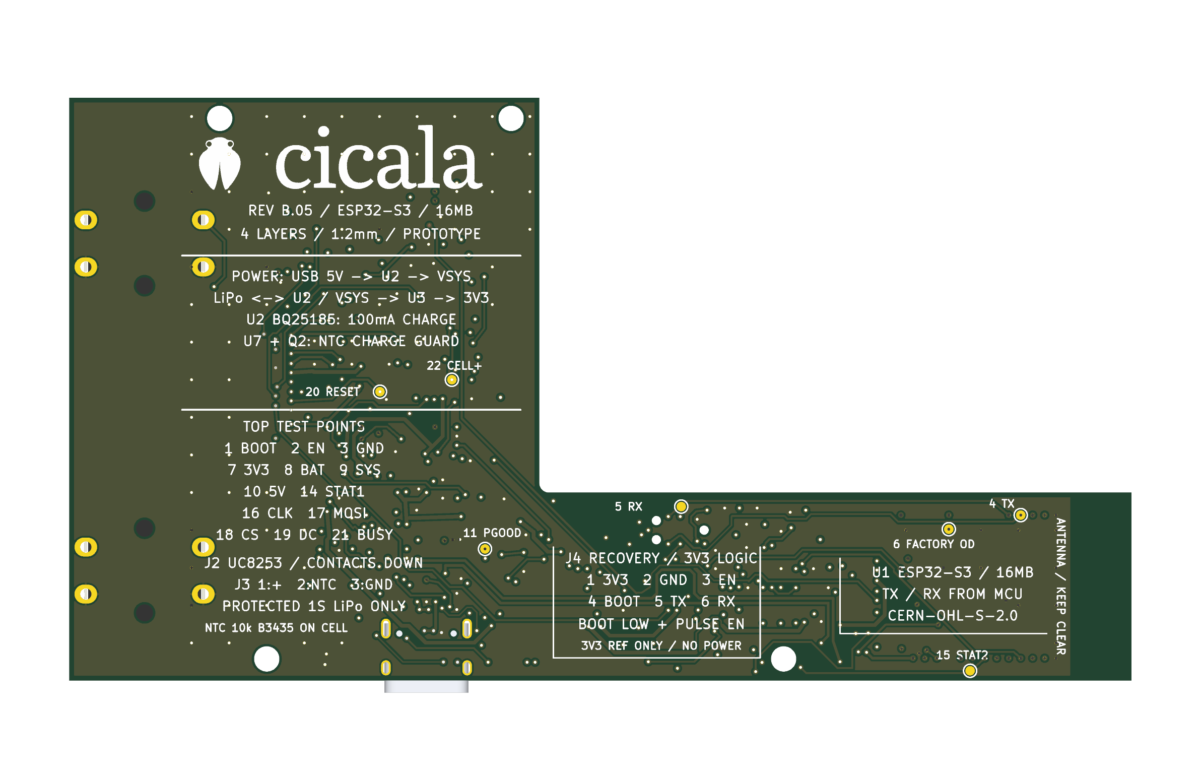
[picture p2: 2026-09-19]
hardware/rev_b/pcb/renders/bottom.png

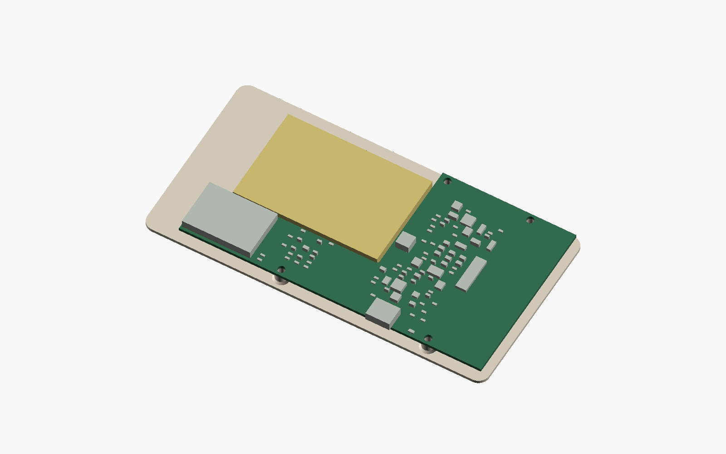
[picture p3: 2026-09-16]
hardware/rev_b/case/renders/inside.png

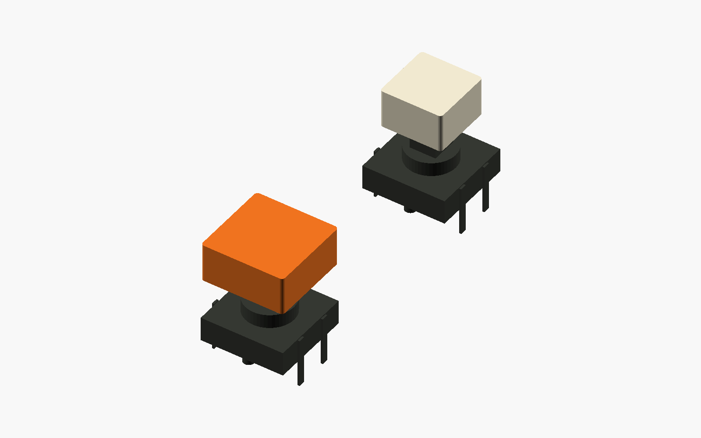
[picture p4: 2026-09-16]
hardware/rev_b/case/renders/buttons_exploded.png

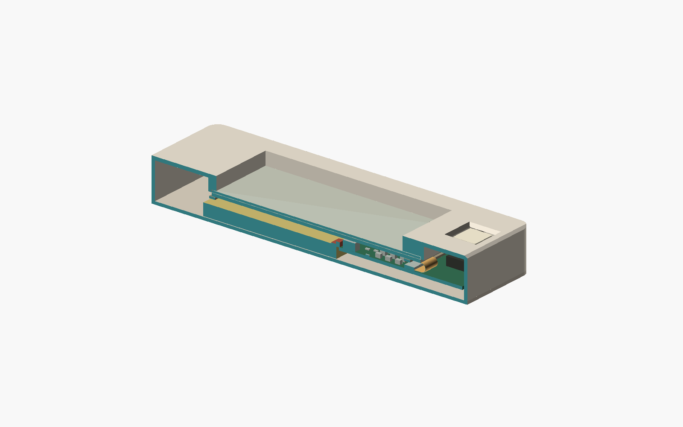
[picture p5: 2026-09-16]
hardware/rev_b/case/renders/section.png

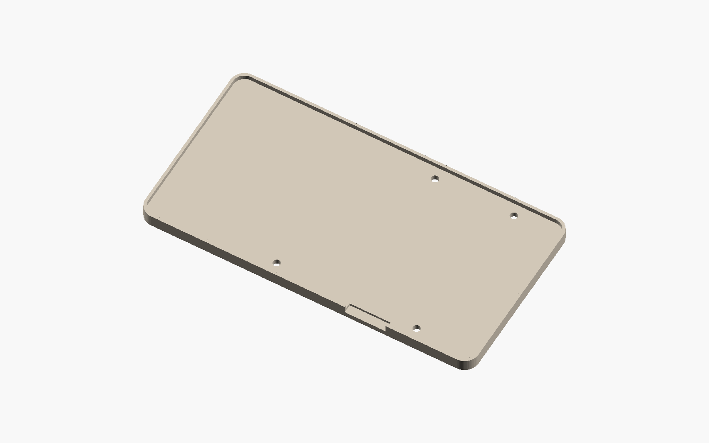
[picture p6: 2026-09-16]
hardware/rev_b/case/renders/carrier.png

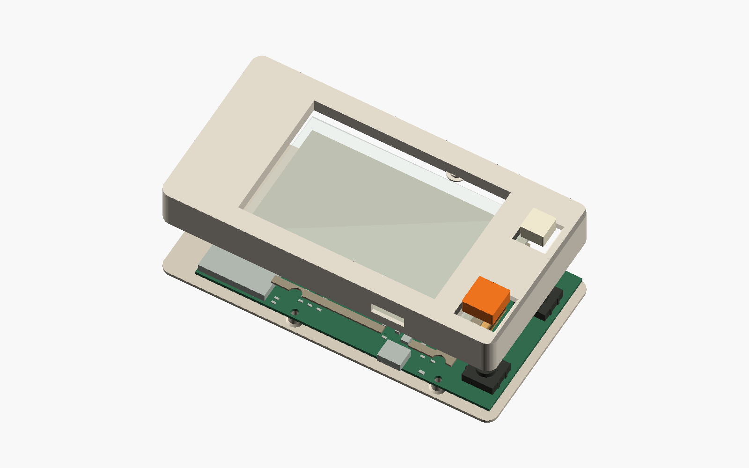
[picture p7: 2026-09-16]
hardware/rev_b/case/renders/exploded.png

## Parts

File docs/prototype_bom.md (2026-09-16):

# Prototype BOM

Parts for the working breadboard rig and the planned rev A integration. Prices and stock change; order by manufacturer part number and confirm the exact board revision at checkout.

## Breadboard rig

| Part | Quantity | Use | Reference |
| --- | ---: | --- | --- |
| Espressif **ESP32-S3-DevKitC-1-N8R8** | 1 | firmware target with UART and native USB/JTAG | [Reichelt ESP32S3DK-C1N8R8](https://www.reichelt.de/index.html?ACTION=3&ARTICLE=411139) |
| Waveshare **12915 2.13-inch e-Paper HAT V4**, black/white, 250 × 122 | 1 | SPI display and partial-refresh testing | [Welectron](https://www.welectron.com/Waveshare-12915-213inch-e-Paper-HAT_1), [Amazon B07J3FHJVP](https://www.amazon.de/dp/B07J3FHJVP), [Eckstein](https://eckstein-shop.de/Waveshare-213-inch-250x122-E-Ink-Display-HAT-for-Raspberry-Pi-SPI-EN) |
| 6 mm through-hole tactile buttons | 2 | Category and Next | any electronics distributor |
| Adafruit **6092**, bq25185 charger with 3.3 V buck | 1 | USB charging, power path, and regulated 3.3 V | [Adafruit 6092](https://www.adafruit.com/product/6092) |
| **EEMB 524261**, 3.7 V, 1500 mAh, JST-PH | 1 | bench cell and discharge measurements | supplier listing matching the exact MPN |
| Red LED and green LED | 1 each | status output | any electronics distributor |
| LED series resistors | 1 each | set bench LED current | choose from the measurement in [hardware wiring](hardware_wiring.md) |
| 1 MΩ, 470 kΩ, 100 kΩ, and 150 kΩ resistors, 1% | 1 each | battery and VBUS dividers | any electronics distributor |
| 100 nF ceramic capacitor | 1 | battery-divider filter | any electronics distributor |
| Breadboard and jumper wires | 1 set | temporary wiring | existing stock |
| USB-C data cables | 3 | UART, native USB/JTAG, and charger | existing stock |

The display listing must say black/white, 250 × 122, V4, and SKU 12915. Three-colour, four-colour, touch, and HAT+ variants use different hardware. The module includes the eight-wire PH2.0 cable and accepts 3.3 V logic.

The DevKitC N8R8 has enough flash and RAM for firmware development. The rev A partition layout targets a 16 MB module and must be checked on that board.

### Buttons

Ordinary through-hole buttons cover the breadboard tests. The target switch is the sealed 2 N C&K **KSC321GLFS**. It is available as [RS 1769505](https://de.rs-online.com/web/p/tastschalter/1769505) and from [Sinuss](https://sinuss.nl/en/products/ksc321glfs-switch-spst-005a-32vdc-16n-smd-ck-components).

The SMD switch needs soldered leads for breadboard use. Connect one side to ground and the opposite side to a GPIO input with its pull-up enabled. Check the contact pair with a continuity meter before connecting the ESP32.

### Battery safety

Cut the Adafruit 6092 charge-rate jumper before connecting the cell. This sets the charge current to 500 mA, about 0.33C for the 1500 mAh bench cell.

Check JST-PH polarity against the charger silkscreen with a meter. Suppliers use both connector polarities; a reversed cell can damage the charger and cell.

The 1500 mAh cell is for measurement. Its roughly 61 × 42 × 5.2 mm envelope does not fit the planned enclosure, and its runtime must not be quoted as the 503035 product-cell runtime.

## Measurement tools

A multimeter is enough for continuity, divider taps, and steady voltage. Short Wi-Fi and e-paper current peaks need a current profiler such as the Nordic Power Profiler Kit II.

The DevKitC power LED and WS2812 prevent a useful whole-device sleep-current measurement. Measure the 30 µA target on rev A.

## Rev A integration

| Part | Quantity | Use |
| --- | ---: | --- |
| ESP32-S3-WROOM-1U-N16, with WROOM-1-N16 gated | 1 | production module, antenna study and 16 MB partition layout |
| **GDEY0213B74** bare panel | 1, plus optional spare | final display stack |
| 24-pin 0.5 mm FPC connector | 1 | panel connection |
| C&K **KSC321GLFS** | 2 | Category and Next |
| Protected 503035 LiPo | 1 | enclosure-sized product cell |
| Charger, regulator, USB-C, ESD, load switches, and passives | 1 set | rev A power and service path; exact parts remain open in `hardware/rev_a/BOM.md` |
| Printed shell, button caps, lens, ballast, and feet | 1 set | tabletop interaction and mechanical tests |

Use [hardware wiring](hardware_wiring.md) to assemble and check the breadboard. The current validation state and remaining enclosure tests are in [device prototype](device_prototype.md).

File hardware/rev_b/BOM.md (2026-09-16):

# Rev B assembly bill of materials

The exact fitted PCB component list is generated from schematic fields into
`pcb/exports/assembly/cicala_rev_b_bom.csv`. The factory-specific BOM and placement
files are generated from that list and the native PCB. The JLC BOM/CPL contains 87 SMT references; `manual_assembly.csv` lists both through-hole switches and the two purchased caps. The full native BOM/position files retain all 89 electronic references. Empty distributor IDs
require sourcing the specified MPN; they do not authorize substitutions.

The following parts complete one standalone prototype. Dimensions and assembly
allowances are in [the engineering guide](../../docs/hardware_rev_b.md).

| Quantity | Part | Selection |
| --- | --- | --- |
| 1 | Populated PCB | Rev B, 1.2 mm four-layer FR-4, ENIG; 87 SMT parts plus 2 through-hole switches |
| 1 | Display | Waveshare 22609, 3.52-inch V1.1 UC8253 |
| 1 | Protected cell | Renata ICP303450PA-02 / 100701, 500 mAh minimum |
| 1 | Temperature sensor | Semitec 103JT-025, 10 kΩ B3435 thin film |
| 1 | Battery plug | JST SHR-03V-S |
| 3 | Crimp contacts | JST SSH-003T-P0.2 |
| 2 | Power pigtails | AWG28, each ≤40 mm; insulated splices to stock pack leads |
| 1 set | Sensor wiring and insulation | Route without loading the sensor head; bond to the cell through electrical insulation |
| 1 | Lens blank | Clear 0.8 mm sheet, cut to `case/exports/patterns/lens_cut.svg`; kerf and material fit to be established on a coupon |
| 1 set | Printed core | Base, top shell, display frame, support bar |
| 2 | Switches (included in PCB BOM) | Omron B3F-4050, through-hole; solder after SMT |
| 1 | Filters cap | Omron B32-1200, ivory, 9 × 9 mm; upper control |
| 1 | Next cap | Omron B32-1320, orange, 12 × 12 mm; lower control |
| 1 set | Display foam and attachment | Nominal 0.2 mm removable perimeter foam; keep the active screen and flex bond unloaded |
| 1 set | Battery attachment and insulation | Within the 54 × 36 × 4.8 mm reservation; preserve the pack's protection board |
| 4 | Core fasteners | M2.5 × 10 mm countersunk screws; confirm engagement and tip clearance in the printed posts |

The remaining meshes are assembly tools and purchased-part references. The flex
former is removed after forming. The reference battery, panel and PCB meshes are
not installed alongside the real components.

## Optional accessories

The wedge is a separate print. The magnetic carrier uses its printed body and
cover, the made-to-drawing CIC-MAG-01 array and shield in `contract.json`, and four
M2.5 × 12 mm screws in place of the core screws. The carrier adds 3.2 mm. No
catalogue magnet is a verified substitute; the array, shield, adhesive stack and
phone compatibility need supplier and first-article qualification.

These are engineering selections, not stock guarantees or a production release.
The prototype must be assembled and tested before accepting the hardware.

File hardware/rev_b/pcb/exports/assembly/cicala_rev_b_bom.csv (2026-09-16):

Refs | Value | Footprint | MPN | Manufacturer | LCSC | Qty | DNP
C3,C7,C11,C28,C32,C33 | 100nF | Capacitor_SMD:C_0603_1608Metric | CL10B104KB8NNNC | Samsung Electro-Mechanics | C1591 | 6
C4,C6,C34 | 10uF 10V | Capacitor_SMD:C_0603_1608Metric | CL10A106KP8NNNC | Samsung Electro-Mechanics | C19702 | 3
C5 | 10uF 25V | Capacitor_SMD:C_0805_2012Metric | CL21A106KAYNNNE | Samsung Electro-Mechanics | C15850 | 1
C8,C10,C30 | 47uF 10V | Capacitor_SMD:C_0805_2012Metric | CL21A476MPYNNNE | Samsung Electro-Mechanics | C41796773 | 3
C9 | 22uF 6.3V | Capacitor_SMD:C_0603_1608Metric | CL10A226MQ8NRNC | Samsung Electro-Mechanics | C59461 | 1
C12,C27 | 1uF | Capacitor_SMD:C_0603_1608Metric | CL10B105KA8NNNC | Samsung Electro-Mechanics | C29936 | 2
C13,C29 | 10uF | Capacitor_SMD:C_0603_1608Metric | CL10A106KP8NNNC | Samsung Electro-Mechanics | C19702 | 2
C14 | 1nF | Capacitor_SMD:C_0603_1608Metric | CL10C102JB8NNNC | Samsung Electro-Mechanics | C163508 | 1
C15,C16 | 4.7uF 50V | Capacitor_SMD:C_1206_3216Metric | GRM31CR71H475KA12L | Murata |  | 2
C17-C24 | 1uF 50V | Capacitor_SMD:C_0805_2012Metric | CL21B105KBFNNNE | Samsung Electro-Mechanics |  | 8
C25,C26 | 10nF | Capacitor_SMD:C_0603_1608Metric | CL10B103KB8NNNC | Samsung Electro-Mechanics | C1589 | 2
D1-D3 | MBR0530 | Diode_SMD:D_SOD-123 | MBR0530-7-F | Diodes Incorporated |  | 3
D4 | APBA2006SURKCGKC red/green | cicala:LED_Kingbright_APBA2006SURKCGKC | APBA2006SURKCGKC | Kingbright |  | 1
J1 | USB-C receptacle | cicala:USB_C_Receptacle_HRO_TYPE-C-31-M-12_EdgeOverhang | TYPE-C-31-M-12 | HRO |  | 1
J2 | Waveshare 3.52in V1.1 UC8253 | cicala:Molex_503480-2400_1x24_P0.5mm | 503480-2400 | Molex |  | 1
J3 | Battery + external 10k B3435 NTC | Connector_JST:JST_SH_SM03B-SRSS-TB_1x03-1MP_P1.00mm_Horizontal | SM03B-SRSS-TB(LF)(SN) | JST |  | 1
L1 | 68uH | cicala:L_TDK_VLS4012 | VLS4012CX-680M-1 | TDK |  | 1
L2 | 0.47uH XFL4015-471ME | cicala:L_Coilcraft_XFL4015 | XFL4015-471ME | Coilcraft |  | 1
Q1 | BSS138 | Package_TO_SOT_SMD:SOT-23 | BSS138-7-F | Diodes Incorporated |  | 1
Q2 | 2N7002P | Package_TO_SOT_SMD:SOT-23 | 2N7002P,215 | Nexperia |  | 1
R1,R2 | 5.1k | Resistor_SMD:R_0603_1608Metric | RC0603FR-075K1L | Yageo |  | 2
R3,R4 | 22 | Resistor_SMD:R_0603_1608Metric | RC0603FR-0722RL | Yageo |  | 2
R5,R16,R38,R39 | 100k | Resistor_SMD:R_0603_1608Metric | RC0603FR-07100KL | Yageo |  | 4
R6 | 150k | Resistor_SMD:R_0603_1608Metric | RC0603FR-07150KL | Yageo |  | 1
R7 | 18k | Resistor_SMD:R_0603_1608Metric | RC0603FR-0718KL | Yageo |  | 1
R8 | 3.00k | Resistor_SMD:R_0603_1608Metric | RC0603FR-073KL | Yageo |  | 1
R9,R10,R19,R25,R26 | 10k | Resistor_SMD:R_0603_1608Metric | RC0603FR-0710KL | Yageo |  | 5
R11,R32 | 1M | Resistor_SMD:R_0603_1608Metric | RC0603FR-071ML | Yageo |  | 2
R12 | 470k | Resistor_SMD:R_0603_1608Metric | RC0603FR-07470KL | Yageo |  | 1
R13 | 4.7k | Resistor_SMD:R_0603_1608Metric | RC0603FR-074K7L | Yageo |  | 1
R14 | 511k 1% | Resistor_SMD:R_0603_1608Metric | RC0603FR-07511KL | Yageo |  | 1
R15 | 91k 1% | Resistor_SMD:R_0603_1608Metric | RC0603FR-0791KL | Yageo |  | 1
R18 | 150 | Resistor_SMD:R_0603_1608Metric | RC0603FR-07150RL | Yageo |  | 1
R20 | 3 | Resistor_SMD:R_0603_1608Metric | RC0603FR-073RL | Yageo |  | 1
R21,R22 | 22k | Resistor_SMD:R_0603_1608Metric | RC0603FR-0722KL | Yageo |  | 2
R23,R24 | 1k | Resistor_SMD:R_0603_1608Metric | RC0603FR-071KL | Yageo |  | 2
R27-R31 | 470 | Resistor_SMD:R_0603_1608Metric | RC0603FR-07470RL | Yageo |  | 5
R33,R34 | 0 | Resistor_SMD:R_0603_1608Metric | RC0603JR-070RL | Yageo |  | 2
R35 | 820k | Resistor_SMD:R_0603_1608Metric | RC0603FR-07820KL | Yageo |  | 1
R36 | 210k | Resistor_SMD:R_0603_1608Metric | RC0603FR-07210KL | Yageo |  | 1
R37 | 82.5k | Resistor_SMD:R_0603_1608Metric | RC0603FR-0782K5L | Yageo |  | 1
SW1,SW2 | B3F-4050 | cicala:SW_Omron_B3F-4050 | B3F-4050 | Omron |  | 2
U1 | ESP32-S3-WROOM-1-N16 | cicala:ESP32-S3-WROOM-1_NoEmbeddedVias | ESP32-S3-WROOM-1-N16 | Espressif Systems |  | 1
U2 | BQ25185DLH | cicala:Texas_DLH0010A_NoEmbeddedVias | BQ25185DLHR | Texas Instruments |  | 1
U3 | TPS63802DLA | cicala:Texas_DLA0010A_VSON-HR-10_2x3mm_P0.5mm | TPS63802DLAR | Texas Instruments |  | 1
U4 | USBLC6-2SC6 | Package_TO_SOT_SMD:SOT-23-6 | USBLC6-2SC6 | STMicroelectronics |  | 1
U5,U6 | TPS22917DBVR | Package_TO_SOT_SMD:SOT-23-6 | TPS22917DBVR | Texas Instruments |  | 2
U7 | TLV9022DGK | Package_SO:VSSOP-8_3x3mm_P0.65mm | TLV9022DGKR | Texas Instruments |  | 1

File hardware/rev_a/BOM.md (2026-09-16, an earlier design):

# Rev A bill of materials

The schematic contains exact manufacturer part numbers for every fitted PCB
component. The generated grouped BOM is
`pcb/exports/assembly/cicala_rev_a_bom.csv`; the JLCPCB version also
includes purchasing identifiers where available. Do not substitute a package,
voltage rating or capacitor dielectric on value alone.

## Main PCB parts

| Reference | Selected part | Purpose |
| --- | --- | --- |
| U1 | ESP32-S3-WROOM-1-N16 | Controller, 16 MB flash, PCB antenna |
| U2 | BQ25185DLHR | Protected 1S cell charger and power path |
| U3 | TPS63802DLAR | 3.3 V buck-boost supply |
| U4 | USBLC6-2SC6 | USB ESD protection |
| U5, U6 | TPS22917DBVR | Switched battery measurement and display supply |
| U7 | TLV9022DGKR | Independent charge-temperature window comparator |
| Q2 | 2N7002P,215 | Charge-enable veto interface |
| J1 | HRO TYPE-C-31-M-12 | USB-C power, ROM flashing, serial and JTAG |
| J2 | Hirose FH12-24S-0.5SH(55) | Top-side, bottom-contact display ZIF |
| J3 | JST S3B-PH-SM4-TB(LF)(SN) | Protected cell, NTC and ground |
| L1 | TDK VLS4012CX-470M-1 | 47 µH display boost inductor |
| L2 | Coilcraft XFL4015-471ME | 0.47 µH buck-boost inductor |
| Q1 | Si1308EDL-T1-GE3 | Display boost MOSFET |
| D1–D3 | MBR0530-7-F | Display rail Schottky diodes |
| D4 | APBA2006SURKCGKC | Red/green side-view status LED |
| SW1, SW2 | KSC323GLFG | Gold-contact Filters and Next switches; R21/R22 = 22 kΩ |

Resistors are Yageo RC0603, 1% except the 0 Ω links. Capacitors are Samsung
MLCCs with exact purchasing suffixes in the schematic. The DLA0010A,
Kingbright LED and two inductor lands follow the manufacturer drawings.
U3 has an extended PGND terminal with split paste apertures and no central
exposed pad. U7's adjacent package lands require 0.15 mm pad clearance; routed
copper remains at least 0.20 mm from foreign copper.

C1/C2 (optional USB shunts) and C31 (optional shell capacitor) are DNP.
R33 is the fitted 0 Ω USB-shell ground bond. J4, TP1–TP22 and H1–H4 are bare
PCB features, excluded from the assembly BOM and placement file.

## Off-board parts per device

| Item | Selection | Quantity |
| --- | --- | ---: |
| Display | Good Display GDEY0213B74, W2 mechanical drawing | 1 |
| Battery | Adafruit 258, protected PKCELL LP503562, 1200 mAh | 1 |
| Cell thermistor | Semitec 103AT-2, 10 kΩ at 25°C | 1 |
| Harness | PH2 battery adapter to PHR-3, with bonded NTC; see assembly instructions | 1 |
| Battery adapter source | Adafruit 1131 extension, retaining its battery-mating end | 1 |
| PCB harness housing | JST PHR-3 | 1 |
| Harness terminals | JST SPH-002T-P0.5S, crimped for AWG28 | 3 |
| Case and controls | Printed parts in [case/README.md](../case/README.md) | 1 set |
| Base screws | ISO 7046 / DIN 965 M2.5 × 20, countersunk machine screws | 3 |
| Lens | 55.0 × 30.1 × 0.8 mm clear PMMA, R1 corners | 1 |
| Light pipe | Ø2.0 × 3.5 mm clear PMMA rod, polished ends | 1 |
| Ballast | Optional 1.2 mm steel cut to `steel_cut.svg`, countersunk after cutting | 1 |
| Feet | Ø8 × 1.5 mm self-adhesive elastomer disks | 4 |

The harness rows list its constituent connector parts, not additional complete
harnesses. Also allow AWG28 insulated wire, splice insulation, polyimide NTC
tape, 0.10 mm display-perimeter adhesive and 0.2 mm removable battery tabs.
Print the steel surrogate when omitting the metal so the screw stack is retained.
Bench equipment includes a USB-C data cable; UART recovery additionally uses
a TC2030-IDC-NL breakout and a 3.3 V USB/UART adapter.

The battery's manufacturer drawing specifies a maximum new-pack envelope of
62.3 × 35.3 × 5.3 mm. The case reserves 63 × 36 × 6.3 mm plus 0.2 mm adhesive.
The NTC is attached to the pouch surface with electrically insulating tape;
never solder directly to a pouch cell. The factory pack protection circuit
and connector must remain intact. Wire J3 as 1=protected pack positive,
2=NTC, 3=pack negative; the other NTC lead goes to pin 3.

## Circuit settings

USB-C is a 5 V sink with separate 5.1 kΩ CC pull-downs; it has no PD controller.
BQ25185 is set to 4.2 V, approximately 250 mA charge and 500 mA input limit.
R13 requests charging when the MCU is unpowered; U7/Q2 can independently
force charge disable. The nominal external temperature window is roughly
4–37°C and is deliberately conservative relative to the pack's 0–45°C charge
range. The native charger TS protection remains connected.

The battery divider is 1 MΩ / 470 kΩ with 100 nF filtering. Firmware enables
it only for measurement and waits 200 ms before conversion. The buck-boost
input C8 is 47 µF; its output is 22 µF + 47 µF. C4/C6/C34 use 10 µF parts so
their effective capacitance stays above the required 1 µF after DC bias.
The numerical capacitor and temperature review is in [REVIEW.md](REVIEW.md).

R27–R31 are 470 Ω display signal resistors. Firmware parks the physical signal
levels low before removing panel power. R34 is a removable battery-current
measurement link; TP22 is on its protected-pack side. A WROOM-1U replacement
requires a separate antenna and mechanical review and is not an approved BOM
substitution.

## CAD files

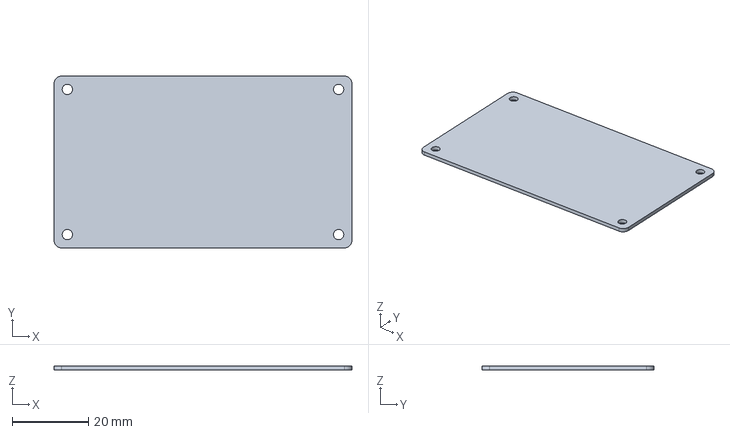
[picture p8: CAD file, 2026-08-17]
hardware/pcb/kveld_rev_a/exports/kveld_rev_a_board.step
78.0 x 45.0 x 1.13 mm

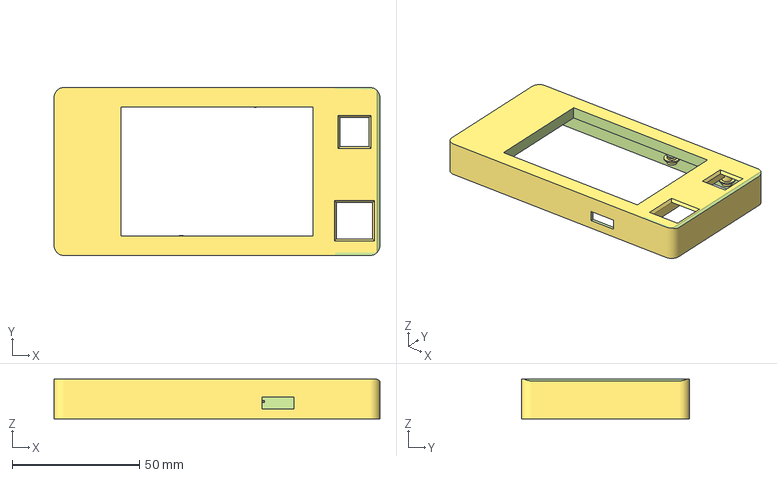
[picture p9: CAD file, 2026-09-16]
hardware/rev_b/case/exports/assembly/top_shell.3mf
128.0 x 66.0 x 15.6 mm

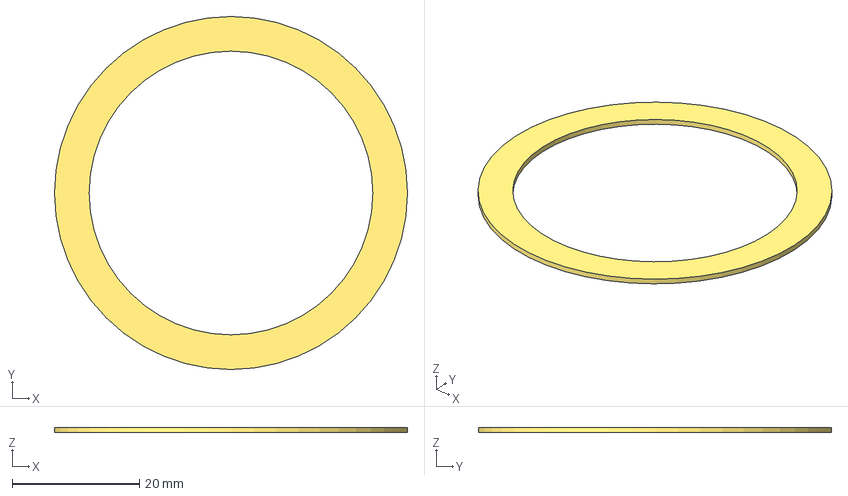
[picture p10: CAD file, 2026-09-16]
hardware/rev_b/case/exports/print/accessories/carrier_cover.3mf
55.5 x 55.5 x 0.85 mm

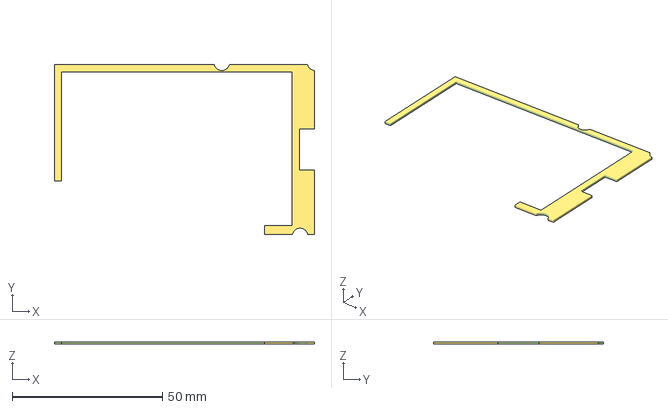
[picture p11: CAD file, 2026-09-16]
hardware/rev_b/case/exports/print/core/display_frame.3mf
86.4 x 56.4 x 0.8 mm

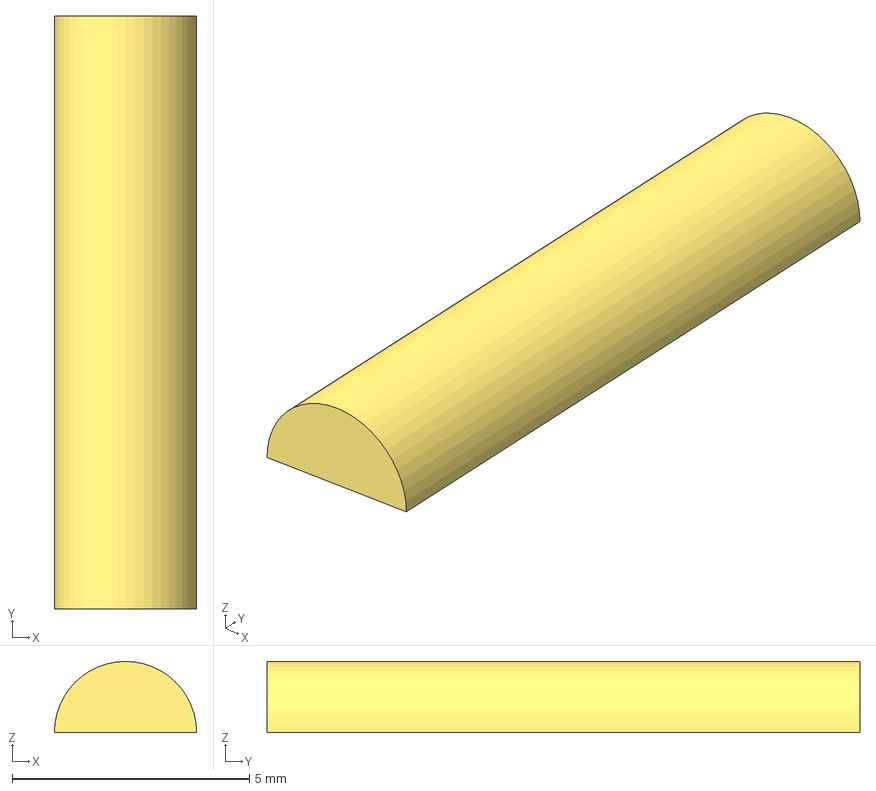
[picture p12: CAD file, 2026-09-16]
hardware/rev_b/case/exports/print/jigs/flex_former.3mf
3.00 x 12.5 x 1.50 mm

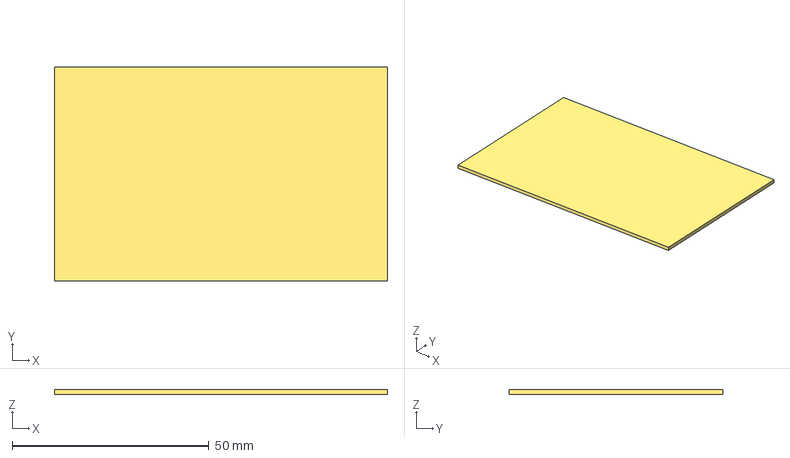
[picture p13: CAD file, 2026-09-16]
hardware/rev_b/case/exports/reference/panel_reference.3mf
84.7 x 54.4 x 1.18 mm

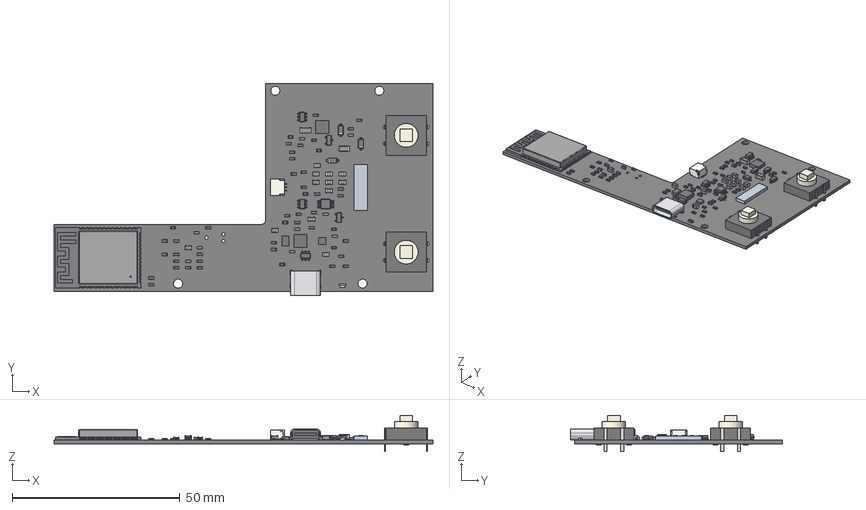
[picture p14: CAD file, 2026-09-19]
hardware/rev_b/pcb/exports/cicala_rev_b_board.step
113.0 x 63.3 x 10.8 mm
R_0603_1608Metric x 38
C_0805_2012Metric x 12
C_0603_1608Metric x 17
SOT-23-6 x 3
D_SOD-123 x 3
JST_SH_SM03B-SRSS-TB_1x03-1MP_P1.00mm_Horizontal
SOT-23 x 2
plunger x 2
lead_0_0 x 2
lead_0_1 x 2
lead_1_0 x 2
lead_1_1 x 2
boss_0 x 2
boss_1 x 2
Texas_DLH0010A_WSON-10-1EP_2.2x2mm_P0.4mm_EP0.9x1.5mm
C_1206_3216Metric x 2
VSSOP-8_3x3mm_P0.65mm
ESP32-S3-WROOM-1
cicala_rev_b_PCB

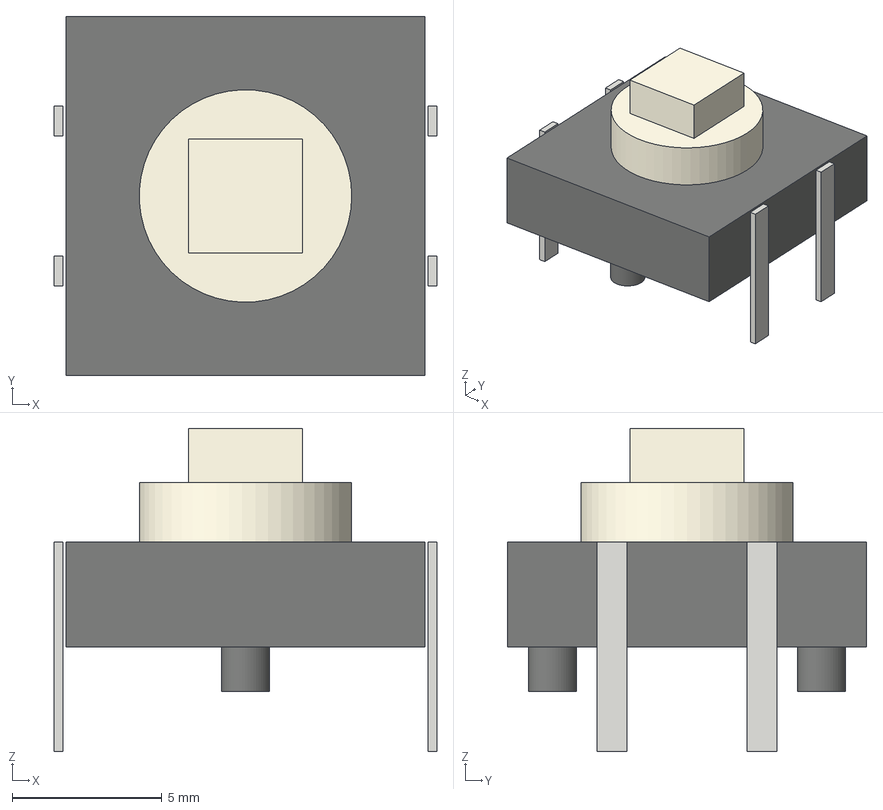
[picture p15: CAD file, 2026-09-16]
hardware/rev_b/pcb/models/Omron_B3F-4050.step
12.8 x 12.0 x 10.8 mm
plunger
lead_0_0
lead_0_1
lead_1_0
lead_1_1
boss_0
boss_1

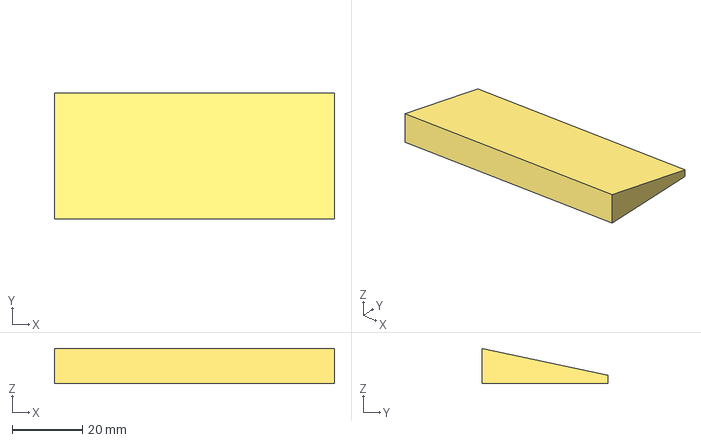
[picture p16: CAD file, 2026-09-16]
hardware/rev_b/case/exports/assembly/wedge.3mf
80.0 x 36.0 x 10.0 mm

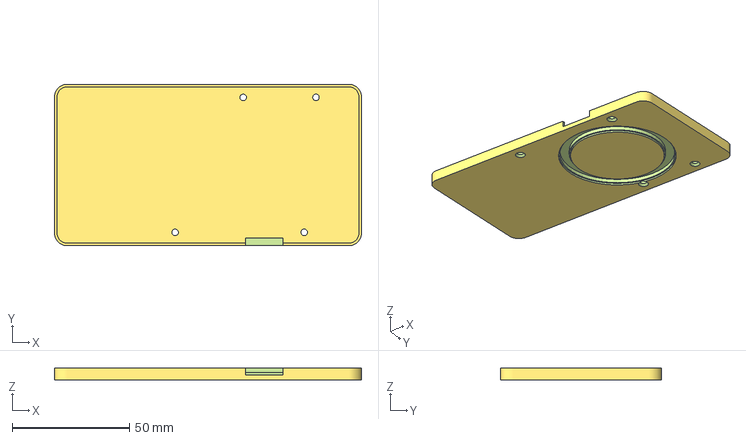
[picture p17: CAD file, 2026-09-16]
hardware/rev_b/case/exports/print/accessories/carrier.3mf
130.8 x 68.8 x 5.19 mm

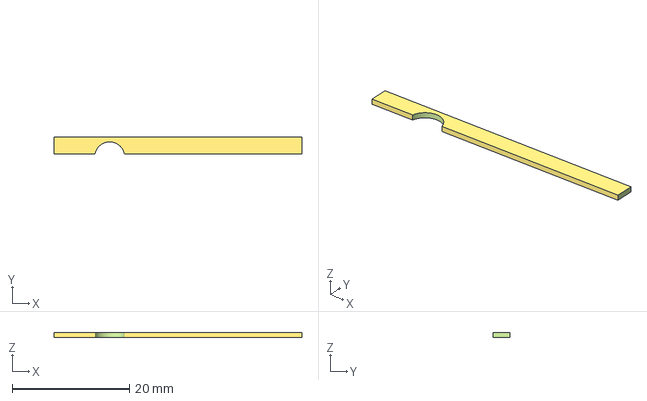
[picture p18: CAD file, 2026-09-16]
hardware/rev_b/case/exports/print/core/display_support_bar.3mf
42.3 x 2.87 x 0.8 mm

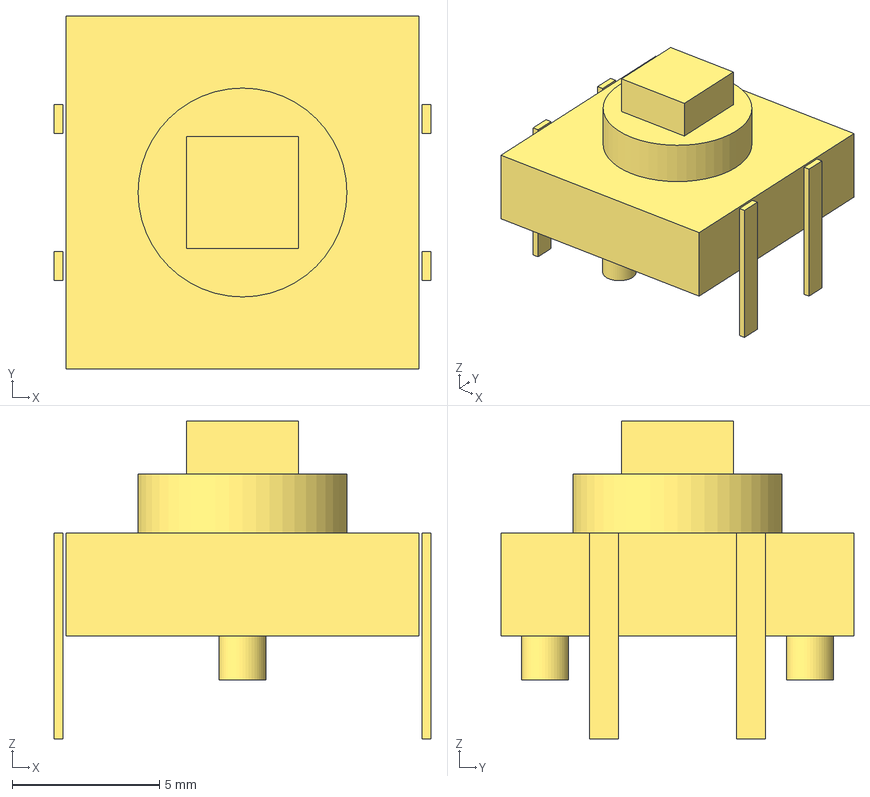
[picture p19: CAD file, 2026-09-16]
hardware/rev_b/case/exports/reference/switch_reference.3mf
12.8 x 12.0 x 10.8 mm

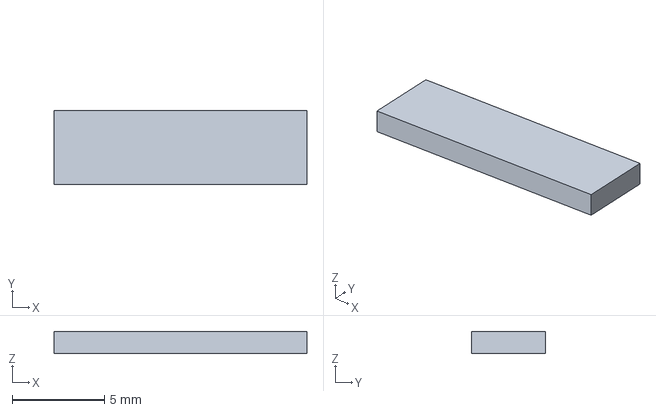
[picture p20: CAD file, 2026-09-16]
hardware/rev_b/pcb/models/Molex_503480-2400_envelope.step
13.7 x 4.00 x 1.20 mm

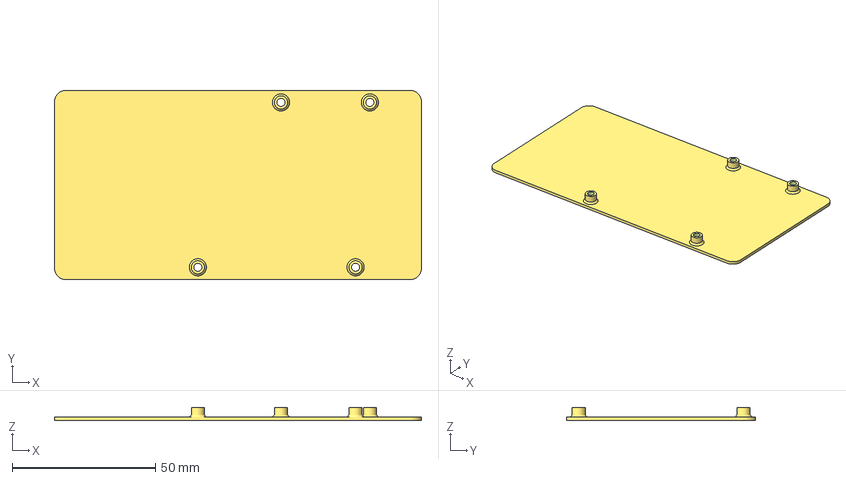
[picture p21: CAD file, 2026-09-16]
hardware/rev_b/case/exports/print/core/base.3mf
128.0 x 66.0 x 4.60 mm

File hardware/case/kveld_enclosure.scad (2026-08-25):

/*
 * Kveld enclosure, Rev A mechanical contract
 *
 * Canonical coordinates are millimetres. X runs left to right, Y runs from
 * rear to front, and Z runs upward from the table. The model is deliberately
 * parametric and conservative: fit-critical details remain coupon-gated.
 *
 * SPDX-License-Identifier: CERN-OHL-S-2.0
 */

$fn = $preview ? 48 : 96;

part = "assembly"; // [assembly,exploded,section,top_shell,base,retainer,category_cap,next_cap,lens,steel_skin,light_pipe,pcb_reference,coupon_buttons,coupon_buttons_assembly,coupon_usb,coupon_lens,coupon_boss]
section_axis = "x"; // [x,y,z]
section_position_percent = 50; // [0:1:100]
section_keep = "positive"; // [negative,positive]

// Public Kveld finish intent. Physical colour and texture remain sample-gated.
paper_color = [250 / 255, 248 / 255, 242 / 255];
paper_raised_color = [1, 1, 254 / 255];
ink_color = [31 / 255, 31 / 255, 29 / 255];
ink_soft_color = [95 / 255, 94 / 255, 90 / 255];

// Product envelope.
case_width = 84;
case_depth = 56;
corner_radius = 3;
face_rear_z = 15.85;
face_front_z = 12.91;
face_angle = atan(
    (face_rear_z - face_front_z) /
    (case_depth - 2 * corner_radius)
);

// Stack from the table upward.
foot_height = 1.5;
steel_thickness = 1.2;
base_thickness = 1.2;
steel_z = foot_height;
base_z = steel_z + steel_thickness;
seam_z = base_z + base_thickness;

// Shell construction. Do not tune fits before printing the coupons.
wall = 2.0;
roof = 2.0;
fit_clearance_xy = 0.25;
boss_outer_diameter = 6.0;
boss_pilot_diameter = 2.1;

// PCB datum: rear-left corner at (3, 3), component side upward.
pcb_x = 3;
pcb_y = 3;
pcb_z = 9.2;
pcb_width = 78;
pcb_depth = 45;
pcb_thickness = 1.2;
pcb_corner_radius = 2;

// Display datum and vendor envelope.
display_x = 42;
display_y = 37;
panel_width = 59.2;
panel_depth = 29.2;
panel_thickness = 1.0;
active_width = 48.55;
active_depth = 23.7046;
window_width = 50.6;
window_depth = 25.7;
lens_width = 55.0;
lens_depth = 30.1;
lens_thickness = 0.8;
lens_pocket_width = 55.4;
lens_pocket_depth = 30.5;

// Controls. Default Rev A presentation: Category sub-flush, Next flush.
category_x = 27;
category_y = 12;
category_bore = 10.30;
category_cap_diameter = 10.0;
category_proud = -0.20;
next_x = 53;
next_y = 12;
next_bore_width = 18.30;
next_bore_depth = 11.30;
next_bore_radius = 5.65;
next_cap_width = 18.0;
next_cap_depth = 11.0;
next_cap_radius = 5.5;
next_proud = 0.0;

// Front I/O. Light pipe is sealed by a gasket or adhesive at assembly.
usb_x = 42;
usb_width = 9.4;
usb_height = 3.8;
usb_center_z = 7.7;
light_pipe_x = 52;
light_pipe_diameter = 2.4;
light_pipe_center_z = 7.7;

mount_points = [
    [6.5, 6.5], [77.5, 6.5], [6.5, 44.5], [77.5, 44.5]
];
service_points = [[6.5, 28], [77.5, 28]];
foot_points = [[14, 8], [70, 8], [14, 48], [70, 48]];

function face_z(y) = face_rear_z -
    (face_rear_z - face_front_z) *
    (y - corner_radius) /
    (case_depth - 2 * corner_radius);

module rounded_2d(width, depth, radius) {
    hull()
        for (x = [radius, width - radius], y = [radius, depth - radius])
            translate([x, y]) circle(r = radius);
}

module rounded_prism(width, depth, height, radius) {
    linear_extrude(height = height)
        rounded_2d(width, depth, radius);
}

module centered_rounded_prism(width, depth, height, radius) {
    translate([-width / 2, -depth / 2, -height / 2])
        rounded_prism(width, depth, height, radius);
}

module xy_centered_rounded_prism(width, depth, height, radius) {
    translate([-width / 2, -depth / 2, 0])
        rounded_prism(width, depth, height, radius);
}

module sloped_rounded_solid(inset = 0, bottom = seam_z, top_offset = 0) {
    local_radius = max(0.5, corner_radius - inset);
    x0 = corner_radius;
    x1 = case_width - corner_radius;
    y0 = corner_radius;
    y1 = case_depth - corner_radius;
    hull()
        for (x = [x0, x1], y = [y0, y1])
            translate([x, y, bottom])
                cylinder(
                    r = local_radius,
                    h = (y == y0 ? face_rear_z : face_front_z) +
                        top_offset - bottom
                );
}

module face_part(width, depth, thickness, radius, x, y, z_offset = 0) {
    translate([x, y, face_z(y) + z_offset])
        rotate([-face_angle, 0, 0])
            centered_rounded_prism(width, depth, thickness, radius);
}

module top_shell_blank() {
    difference() {
        sloped_rounded_solid();
        // Open-bottom cavity leaves conservative roof and wall thickness.
        sloped_rounded_solid(
            inset = wall,
            bottom = seam_z - 0.2,
            top_offset = -roof
        );

        // Lens rebate and the smaller through-window are separate operations.
        face_part(
            lens_pocket_width,
            lens_pocket_depth,
            1.25,
            1.2,
            display_x,
            display_y,
            -0.45
        );
        face_part(
            window_width,
            window_depth,
            7,
            1.0,
            display_x,
            display_y,
            -3.0
        );

        // Vertical cap bores. Flange and actuator stack are coupon-gated.
        translate([category_x, category_y, seam_z - 1])
            cylinder(d = category_bore, h = 20);
        translate([next_x, next_y, seam_z + 8])
            centered_rounded_prism(
                next_bore_width,
                next_bore_depth,
                20,
                next_bore_radius
            );

        // USB-C mouth and adjacent status-light channel through the front wall.
        translate([usb_x, case_depth + 1, usb_center_z])
            rotate([90, 0, 0])
                xy_centered_rounded_prism(
                    usb_width,
                    usb_height,
                    wall + 2,
                    usb_height / 2
                );
        translate([light_pipe_x, case_depth + 0.5, light_pipe_center_z])
            rotate([90, 0, 0])
                cylinder(d = light_pipe_diameter, h = wall + 3);
    }
}

module top_shell() {
    difference() {
        union() {
            top_shell_blank();
            // Bosses are rebuilt inside the cavity after the cavity subtraction.
            for (point = mount_points)
                translate([point[0], point[1], seam_z])
                    cylinder(d = boss_outer_diameter, h = 4.4);
        }
        for (point = mount_points)
            translate([point[0], point[1], seam_z - 0.5])
                cylinder(d = boss_pilot_diameter, h = 6);
    }
}

module base() {
    difference() {
        translate([1.2, 1.2, base_z])
            rounded_prism(
                case_width - 2.4,
                case_depth - 2.4,
                base_thickness,
                2.0
            );

        for (point = concat(mount_points, service_points))
            translate([point[0], point[1], base_z - 0.2])
                cylinder(d = point[1] == 28 ? 2.5 : 2.7, h = base_thickness + 0.4);

        // Shallow datum only: the adhesive-backed cell is retained above it.
        translate([24.5, 4.0, base_z + base_thickness - 0.35])
            rounded_prism(35, 30, 0.5, 1.5);
    }
}

module steel_skin() {
    difference() {
        translate([0.8, 0.8, steel_z])
            rounded_prism(
                case_width - 1.6,
                case_depth - 1.6,
                steel_thickness,
                2.3
            );
        for (point = concat(mount_points, service_points))
            translate([point[0], point[1], steel_z - 0.2])
                cylinder(d = 3.0, h = steel_thickness + 0.4);
        // RF keepout: no steel under or beside the PCB antenna zone.
        translate([-0.1, 20, steel_z - 0.2])
            cube([15.1, 16, steel_thickness + 0.4]);
    }
}

module foot(x, y) {
    translate([x, y, 0]) cylinder(d = 8, h = foot_height);
}

module lens() {
    color([31 / 255, 34 / 255, 35 / 255, 0.82])
        face_part(
            lens_width,
            lens_depth,
            lens_thickness,
            1.0,
            display_x,
            display_y,
            -lens_thickness / 2 + 0.05
        );
}

module panel_reference() {
    color(paper_raised_color)
        face_part(
            panel_width,
            panel_depth,
            panel_thickness,
            0.7,
            display_x,
            display_y,
            -2.3
        );
}

module retainer() {
    // Front-loaded frame with a clear FPC exit at the rear-left of the panel.
    difference() {
        face_part(61.2, 31.2, 1.2, 1.2, display_x, display_y, -2.8);
        face_part(56.8, 26.8, 2.0, 0.8, display_x, display_y, -2.8);
        translate([24, 47, 7]) cube([12, 6, 8]);
    }
}
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

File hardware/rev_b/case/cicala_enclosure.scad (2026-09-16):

// CERN-OHL-S-2.0. Rev B engineering prototype; dimensions from contract.json.
include <contract.scad>
include <pcb_component_bounds.scad>
part = "assembly";
stroke = 0;
print_rotation = [0,0,0];
print_shift = [0,0,0];
side_shift = [0,0,0];
lift = display_assembly_lift;
$fn = 48;
eps = 0.01;

module block(p, size) { translate(p) cube(size); }
module round_box(w,d,h,r=4) {
    linear_extrude(h) offset(r=r) translate([r,r]) square([w-2*r,d-2*r]);
}
module bevel_volume() {
    translate([case_bevel_start,case_depth+1,case_height]) rotate([90,0,0])
        linear_extrude(case_depth+2)
        polygon([[0,0],[20,-20*tan(case_bevel_angle)],[20,20],[0,20]]);
}
module outer() {
    difference() {
        translate(case_origin) round_box(case_width,case_depth,case_height);
        bevel_volume();
        block([case_control_ledge_x,-1,case_control_ledge_z],[20,case_depth+2,2]);
    }
}
module glass(extra=0) {
    block(display_glass_origin-[extra,extra,extra],display_glass+[2*extra,2*extra,2*extra]);
}
module cell() { block(battery_reserved_origin,battery_reserved_size); }
module lens() {
    block([display_glass_origin.x,display_glass_origin.y,display_lens_z],
          [display_glass.x,display_glass.y,display_lens_thickness]);
}
module pcb() {
    translate([0,0,pcb_z]) linear_extrude(pcb_thickness) difference() {
        polygon(board_polygon);
        for (p=mounts) translate(p) circle(d=2.7);
    }
}
module components() {
    for (row=pcb_component_bounds) block(row[1],row[2]);
}
module switch_body(index=0) {
    p=buttons_centres[index]; z=pcb_z+pcb_thickness;
    block([p.x-6,p.y-6,z],[12,12,3.5]);
    translate([p.x,p.y,z]) cylinder(d=7.1,h=5.5-stroke);
    block([p.x-1.9,p.y-1.9,z+5.5-stroke],[3.8,3.8,1.8]);
    for(x=[-6.25,6.25],y=[-2.5,2.5])
        block([p.x+x-.15,p.y+y-.5,z-buttons_lead_length],[.3,1,7]);
    for(y=[-4.5,4.5]) translate([p.x,p.y+y,z-1.5]) cylinder(d=1.6,h=1.5);
}
module switches() { for(i=[0:1]) switch_body(i); }
module rounded_block(p,size,r=.4) {
    translate(p) linear_extrude(size.z) offset(r=r)
        translate([r,r]) square([size.x-2*r,size.y-2*r]);
}
module cap(index=0,travel=stroke) {
    p=buttons_centres[index]; size=buttons_cap_sizes[index];
    z=pcb_z+pcb_thickness+buttons_assembled_height-buttons_cap_height-travel;
    // Purchased-part exterior/socket envelope. Internal ribs are not reproduced.
    translate(side_shift) difference() {
        rounded_block([p.x-size/2,p.y-size/2,z],[size,size,buttons_cap_height],.5);
        block([p.x-size/2+.8,p.y-size/2+.8,z-eps],[size-1.6,size-1.6,2.8+eps]);
    }
}
module caps() {
    color("#eee6cd") cap(0);
    color("#ed721f") cap(1);
}
module cap_slot(index) {
    p=buttons_centres[index]; size=buttons_cap_sizes[index]+2*buttons_radial_clearance;
    block([p.x-size/2,p.y-size/2,0],[size,size,case_height+5]);
    // The flared mouth admits a fingertip while the cap remains recessed.
    hull() {
        block([p.x-size/2,p.y-size/2,case_control_ledge_z-buttons_well_depth],
              [size,size,eps]);
        block([p.x-size/2-buttons_well_flare,p.y-size/2-buttons_well_flare,case_control_ledge_z],
              [size+2*buttons_well_flare,size+2*buttons_well_flare,eps]);
    }
}
module flex_reserve() { block([99.225,26.5,3.85+lift],[2.15,13,3.8]); }
module port() { block([71.7,60,pcb_z+.5],[12.6,10,4.7]); }
module screw_holes() {
    for (p=mounts) translate([p.x,p.y,-4]) cylinder(d=2.8,h=pcb_z+4+eps);
}
module shell_posts() {
    for (p=mounts) translate([p.x,p.y,pcb_z+pcb_thickness+.05]) difference() {
        cylinder(r=2.3,h=case_height-pcb_z-pcb_thickness-.6);
        translate([0,0,-eps]) cylinder(d=2.05,h=4.5);
    }
}
module frame_seats() {
    for (p=mounts) translate([p.x,p.y,5.75+lift]) cylinder(r=3.6,h=.6);
}
module top_shell() {
    difference() {
        intersection() {
            outer();
            union() {
                difference() {
                    outer();
                    block([case_origin.x+case_wall,case_wall,-1],
                          [case_width-2*case_wall,case_depth-2*case_wall,case_height-case_wall+1]);
                    block([case_origin.x-1,-1,-1],[case_width+2,case_depth+2,case_base+1]);
                }
                shell_posts(); frame_seats();
                // Recessed display bezel joins the roof and locates the lens.
                block([display_glass_origin.x-1.4,display_glass_origin.y-1.4,display_lens_z],
                      [display_glass.x+2.8,display_glass.y+2.8,case_height-display_lens_z]);
            }
        }
        flex_reserve(); glass(.2);
        block([display_glass_origin.x-.2,display_glass_origin.y-.2,display_lens_z-.15],
              [display_glass.x+.4,display_glass.y+.4,display_lens_thickness+.3]);
        block([display_active_origin.x-.5,display_active_origin.y-.5,display_lens_z-.25],
              [display_active.x+1,display_active.y+1,case_height]);
        port();
        for(i=[0:1]) cap_slot(i);
    }
}
module base() {
    difference() {
        union() {
            translate(case_origin) round_box(case_width,case_depth,case_base);
            for(p=mounts) translate([p.x,p.y,case_base]) {
                cylinder(r=2.3,h=pcb_z-case_base);
                cylinder(r1=3,r2=2.3,h=.8);
            }
        }
        screw_holes();
        for(p=mounts) translate([p.x,p.y,-eps]) cylinder(d1=4.8,d2=2.8,h=1.01);
    }
}
module display_frame_set() { translate([0,0,lift]) display_frame_set_local(); }
module display_frame_set_local() {
    difference() {
        block([13.375,4.795,6.35],[86.425,56.41,.8]);
        block([15.745,7.165,6.2],[76.51,51.17,1.1]);
        block([94.8,26.15,6.1],[7,13.7,1.3]);
        block([72.8,58.2,6.1],[10.4,4.2,1.3]);
        // The module occupies the lower left; the frame supports the other
        // three perimeter regions without placing a load on its RF shield.
        block([12,43.5,6.1],[18.5,20,1.3]);
        for(p=mounts) translate([p.x,p.y,6.1]) cylinder(r=2.55,h=1.2);
    }
}
module display_frame() {
    difference() { display_frame_set(); block([30,58.2,6+lift],[43,4,2]); }
}
module display_support_bar() {
    intersection() { display_frame_set(); block([30,58.2,6+lift],[43,4,2]); }
}
module flex() { translate([0,0,lift]) flex_local(); }
module flex_local() {
    // Static fold former R1.55; the connector tip remains straight.
    translate([99.475,39.25,5.75]) rotate([90,0,0]) linear_extrude(12.5)
        difference() {
            circle(r=1.65); circle(r=1.55);
            translate([-2,-2]) square([2,4]);
        }
    block([99.075,26.75,7.3],[.4,12.5,.1]);
    block([94.9,26.75,4.1],[4.575,12.5,.1]);
}
module flex_former() { translate([0,0,lift]) flex_former_local(); }
module flex_former_local() {
    translate([99.475,39.25,5.75]) rotate([90,0,0]) linear_extrude(12.5)
        intersection() { circle(r=1.5); translate([0,-2]) square([2,4]); }
}
module harness() { translate([0,0,lift]) harness_local(); }
module harness_local() {
    // Reserved service loop beside the cell. Leads follow the edge of the
    // pouch; all joints use individual insulation and strain relief.
    block([64.7,30.5,3.7],[1.6,5,1.8]);
    block([62.8,29,3.7],[1.9,8,.9]);
}
module carrier_ring(outer=carrier_ring_outer_diameter, inner=carrier_ring_inner_diameter, height=1) {
    linear_extrude(height) difference() { circle(d=outer); circle(d=inner); }
}
module carrier_cover() {
    difference() {
        translate([carrier_ring_centre.x,carrier_ring_centre.y,-carrier_thickness])
            carrier_ring(carrier_ring_outer_diameter+1.4,carrier_ring_inner_diameter-1.4,carrier_cover_thickness);
        for(p=mounts) translate([p.x,p.y,-carrier_thickness-eps])
            cylinder(d1=5.2,d2=3.2,h=1.01);
    }
}
module carrier_screws() {
    for(p=mounts) translate([p.x,p.y,-carrier_thickness]) {
        cylinder(d1=4.8,d2=2.5,h=1);
        cylinder(d=2.5,h=12);
    }
}
module carrier_magnets() {
    translate([carrier_ring_centre.x,carrier_ring_centre.y,-carrier_thickness+carrier_cover_thickness])
        carrier_ring(height=carrier_magnet_thickness);
}
module carrier_shield() {
    translate([carrier_ring_centre.x,carrier_ring_centre.y,-carrier_support_thickness-carrier_steel_shield_thickness]) carrier_ring(height=carrier_steel_shield_thickness);
}
module carrier() {
    difference() {
        union() {
            translate([case_origin.x-1.4,-1.4,-carrier_thickness]) round_box(case_width+2.8,case_depth+2.8,carrier_thickness,5.4);
            difference() {
                translate([case_origin.x-1.4,-1.4,-eps]) round_box(case_width+2.8,case_depth+2.8,2,5.4);
                translate([case_origin.x-.3,-.3,-1]) round_box(case_width+.6,case_depth+.6,4,4.3);
            }
        }
        translate([carrier_ring_centre.x,carrier_ring_centre.y,-carrier_thickness-eps])
            carrier_ring(carrier_ring_outer_diameter+.4,carrier_ring_inner_diameter-.4,2.7+eps);
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

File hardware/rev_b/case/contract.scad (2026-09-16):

// Generated by hardware/tools/rev_b/generate_contract.py. Millimetres.
case_width = 128;
case_depth = 66;
case_height = 16.8;
case_corner_radius = 4;
case_wall = 1.4;
case_base = 1.2;
case_bevel_start = 116.8;
case_bevel_angle = 30;
case_origin = [-10, 0, 0];
case_control_ledge_x = 100;
case_control_ledge_z = 16.8;
pcb_z = 4.6;
pcb_thickness = 1.2;
pcb_layers = 4;
pcb_outline = [[3, 44], [65, 44], [66, 43], [66, 2], [116, 2], [116, 64], [3, 64]];
pcb_inside_radius = 1;
pcb_copper_edge_clearance = 0.5;
display_glass = [84.7, 54.41, 1.18];
display_glass_origin = [14.375, 5.795, 9.315];
display_active = [74.51, 49.67];
display_active_origin = [16.745, 8.165];
display_resolution = [360, 240];
display_flex_width = 12.5;
display_flex_length = 10;
display_flex_stiffener = 3.65;
display_flex_bend_radius_assumption = 1.55;
display_lens_z = 10.615;
display_lens_thickness = 0.8;
display_flex_nominal_spare_length = 0.923;
display_connector_insertion = 1.58;
display_connector_contact_bottom_z = 6.115;
display_assembly_lift = 1.9649999999999999;
battery_capacity_mah = 500;
battery_nominal_cell = [52, 34.5, 3.6];
battery_reserved_origin = [11, 7, 1.4];
battery_reserved_size = [54, 36, 4.8];
battery_adhesive = 0.2;
battery_charge_current_ma = 100;
buttons_centres = [[108, 17.5], [108, 52.3]];
buttons_caps = ["B32-1200", "B32-1320"];
buttons_cap_sizes = [9, 12];
buttons_cap_colors = ["ivory", "orange"];
buttons_cap_height = 5.5;
buttons_assembled_height = 10;
buttons_assembled_height_tolerance = 0.4;
buttons_switch_height = 7.3;
buttons_switch_height_tolerance = 0.2;
buttons_switch_body_size = [12, 12, 3.5];
buttons_switch_travel = 0.3;
buttons_switch_travel_range = [0.2, 0.5];
buttons_radial_clearance = 0.5;
buttons_cap_size_tolerance = 0.15;
buttons_printed_aperture_tolerance = 0.3;
buttons_alignment_tolerance = 0.15;
buttons_vertical_print_tolerance = 0.2;
buttons_pcb_thickness_tolerance = 0.13;
buttons_lead_length = 3.5;
buttons_lead_length_tolerance = 0.4;
buttons_terminal_pitch = [12.5, 5];
buttons_terminal_drill = 1.2;
buttons_boss_pitch = 9;
buttons_boss_drill = 1.8;
buttons_force_n = 1.27;
buttons_force_tolerance_n = 0.49;
buttons_sources = ["https://omronfs.omron.com/en_US/ecb/products/pdf/en-b3f.pdf", "https://omronfs.omron.com/en_US/ecb/products/pdf/en-b32.pdf"];
buttons_pcb_seat_height_tolerance = 0.2;
buttons_nominal_recess = 1.0;
buttons_well_flare = 1.4;
buttons_well_depth = 2.5;
buttons_access_probe_radius = 6.0;
buttons_maximum_pressed_recess = 2.5;
buttons_max_solder_projection = 2.6;
rf_keepout_origin = [3, 29];
rf_keepout_size = [6.5, 35];
mounts = [[40, 61.7], [69, 4.2], [100, 4.2], [95, 61.7]];
carrier_thickness = 3.2;
carrier_ring_outer_diameter = 54.1;
carrier_ring_inner_diameter = 46;
carrier_ring_depth = 1.15;
carrier_ring_centre = [75.865, 33];
carrier_case_clearance = 0.3;
carrier_magnet_thickness = 1.1;
carrier_adhesive_thickness = 0.05;
carrier_steel_shield_thickness = 0.7;
carrier_cover_thickness = 0.85;
carrier_support_thickness = 0.5;
manufacturing_route_min_width = 0.2;
manufacturing_escape_min_width = 0.15;
manufacturing_clearance = 0.2;
manufacturing_via_drill = 0.3;
manufacturing_via_diameter = 0.6;
manufacturing_panel_rail = 5;
manufacturing_panel_route_channel = 2;
manufacturing_release = false;
gates = ["First power-up: polarity, 3V3 regulation and USB/UART programming", "Display refresh, power-down, rail voltages and flex fit on selected V1.1 panel", "Battery NTC veto, charging, pulse load and sleep current", "Purchased cap seating, aperture clearance, off-centre force, full actuation and return; soldered through-hole lead clearance", "Optional phone carrier retention, camera interference and loaded antenna performance", "Factory confirmation of stack, stencil and tab-panel support at prototype order"];
board_polygon = [[3, 44], [65.0, 44.0], [65.08715574274765, 43.99619469809175], [65.17364817766693, 43.984807753012205], [65.25881904510253, 43.965925826289066], [65.34202014332567, 43.939692620785905], [65.4226182617407, 43.90630778703665], [65.5, 43.86602540378444], [65.57357643635105, 43.81915204428899], [65.64278760968654, 43.76604444311898], [65.70710678118655, 43.707106781186546], [65.76604444311897, 43.642787609686536], [65.819152044289, 43.57357643635105], [65.86602540378443, 43.5], [65.90630778703665, 43.4226182617407], [65.9396926207859, 43.34202014332567], [65.96592582628907, 43.25881904510252], [65.9848077530122, 43.173648177666934], [65.99619469809174, 43.08715574274766], [66.0, 43.0], [66, 2], [116, 2], [116, 64], [3, 64]];

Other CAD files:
hardware/rev_b/case/exports/assembly/flex_former.3mf
hardware/rev_b/case/exports/print/accessories/wedge.3mf
hardware/rev_b/case/exports/reference/cell_reference.3mf
hardware/rev_b/case/exports/assembly/base.3mf
hardware/rev_b/case/pcb_component_bounds.scad
hardware/rev_a/case/cicala_enclosure.scad
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

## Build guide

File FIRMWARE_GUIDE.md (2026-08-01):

# Firmware guide

A hands-on tour of the Zephyr setup in this repo: what exists, how a build
actually works, and what to poke at to understand it. Everything here is
runnable — read it next to a terminal.

The design this implements is [docs/firmware_architecture.md](docs/firmware_architecture.md).
The reasons behind each choice are in [docs/decisions.md](docs/decisions.md).

---

## 1. What is here

```
firmware/
├── west.yml                    manifest: zephyr revision + module allowlist
├── app/
│   ├── CMakeLists.txt
│   ├── prj.conf                shared config, all boards
│   ├── Kconfig                 our own settings (CONFIG_TK_*)
│   ├── boards/                 per-board config + devicetree overlay
│   └── src/main.c              bring-up blinky
├── lib/fsm/                    table-driven state machine, C++17
└── tests/
    ├── smoke/                  proves the harness works
    └── fsm/                    13 cases, injected clock
```

Two things are deliberately absent: the application state machine, and
`deps/`. The first is next. The second is Zephyr itself — cloned by
`just fw-init`, gitignored, never committed.

Quick check that your machine is set up:

```sh
just fw-doctor
```

Every line should have a path or a version. If not, it prints the command to
fix that line.

---

## 2. The three commands you will actually use

```sh
just fw-build     # compile for the ESP32-S3 devkit
just fw-test      # run both ztest suites under qemu, no hardware
just fw-flash     # build + write to the board over USB
```

`just fw-test` takes about 25 seconds and needs nothing plugged in. That is
the loop for anything that is not driver code.

---

## 3. How a Zephyr build works

A Zephyr binary is assembled from four inputs. Confusing them is the source of
most early frustration, so it is worth separating them properly.

| Input | Answers | Lives in |
|---|---|---|
| **Board** | Which chip, which peripherals exist | `deps/zephyr/boards/…` |
| **Devicetree** | What hardware is wired where | `app/boards/*.overlay` |
| **Kconfig** | Which software features are compiled in | `app/prj.conf`, `app/Kconfig` |
| **Source** | What the program does | `app/src/`, `lib/` |

The rule of thumb: **devicetree describes hardware, Kconfig selects software.**
A pin number is devicetree. "Include the SPI driver" is Kconfig.

### The board target

```
esp32s3_devkitc/esp32s3/procpu
└── board          └── SoC  └── CPU cluster
```

Under Zephyr's hardware model v2, the qualifiers are part of the name. Leaving
them off is an error rather than a default — `qemu_xtensa` is a board *name*,
and the target is `qemu_xtensa/dc233c`. `west boards` lists what exists.

---

## 4. Devicetree, hands on

Devicetree is a description of hardware that the build turns into C macros. You
never write those macros — you read the tree and ask for a node.

**Look at what the board gives you:**

```sh
sed -n '15,45p' deps/zephyr/boards/espressif/esp32s3_devkitc/esp32s3_devkitc_procpu.dts
```

You will see an `aliases` block with `watchdog0` and not much else. In
particular there is no `led0`, which is why blinky here does not use the usual
`DT_ALIAS(led0)` — the DevKitC-1's only onboard LED is an addressable WS2812.

**Look at what we add:**

```sh
cat firmware/app/boards/esp32s3_devkitc_esp32s3_procpu.overlay
```

The filename is not arbitrary: it is the board target with `/` replaced by `_`.
Zephyr picks it up automatically because it sits in `app/boards/`.

**Look at the merged result.** This is the file worth knowing about — board
plus overlay, fully resolved:

```sh
less build/esp32s3/zephyr/zephyr.dts
```

**Now change something and watch it move.** In the overlay, find:

```dts
zephyr,user {
    blink-gpios = <&gpio0 2 GPIO_ACTIVE_HIGH>;
};
```

Change `2` to `4`, rebuild, and grep the generated header:

```sh
just fw-build
grep -m1 -A3 "zephyr_user.*blink_gpios" build/esp32s3/zephyr/include/generated/zephyr/devicetree_generated.h
```

That 1 MB header is what `GPIO_DT_SPEC_GET(DT_PATH(zephyr_user), blink_gpios)`
in `app/src/main.c` expands into. The C source never mentions a pin number, so
moving the LED is an overlay edit and the same source still builds for the
host.

`zephyr,user` is a conventional catch-all node for application-specific
properties that do not deserve a binding of their own. Good for bring-up,
not where the real selector and panel go — those get proper nodes.

---

## 5. Kconfig, hands on

Kconfig decides what is compiled in. Symbols come from Zephyr, from modules,
and from us.

**Ours are in `firmware/app/Kconfig`:**

```sh
cat firmware/app/Kconfig
```

These are the values the architecture deliberately leaves open — the selector
settle window, the refresh interval, the depth cap. They are Kconfig rather
than `#define` so they can be changed per board and per test without editing
source.

**See the resolved values:**

```sh
grep "^CONFIG_TK_" build/esp32s3/zephyr/.config
```

```
CONFIG_TK_SELECTOR_SETTLE_MS=600
CONFIG_TK_NEXT_DEBOUNCE_MS=30
CONFIG_TK_FULL_REFRESH_INTERVAL=8
CONFIG_TK_PLAYBACK_DEPTH_MAX=2
CONFIG_TK_RECENT_RING=20
CONFIG_TK_REFRESH_MIN_MV=3200
```

**Explore interactively:**

```sh
.venv/bin/west build -t menuconfig -d build/esp32s3
```

Press `/` to search for a symbol. `CONFIG_TK_` finds ours. This is the fastest
way to discover what a subsystem offers and what it depends on — Kconfig shows
you why a symbol is unavailable, which is usually a missing dependency.

Changes made in menuconfig apply to that build directory only. To keep one,
write it into `app/prj.conf` (all boards) or `app/boards/<target>.conf` (one
board).

**Three layers, in merge order:**

1. the board's `_defconfig`
2. `app/prj.conf`
3. `app/boards/<board target>.conf`

`build/<dir>/zephyr/.config` is the outcome. When a setting seems ignored,
check there first — it is the ground truth, and a typo'd symbol name silently
does nothing.

**A note on the `LATER` blocks in `prj.conf`.** Sections for zbus, display,
storage, power management and networking are written out and commented. They
are the architecture's targets, staged so the tree always builds. Uncomment as
each component lands.

---

## 6. What to look at in a build directory

```sh
just fw-build
```

The link map at the end is the most informative output:

```
FLASH:      140564 B    8388352 B     1.68%
iram0_0_seg:  49832 B     415492 B    11.99%
dram0_0_seg:  58152 B     399108 B    14.57%
rtc_slow_seg:    36 B        8 KB      0.44%
```

That last line matters for this project. `rtc_slow_seg` is memory that survives
deep sleep, and the architecture puts the shuffle bag, the recent ring and the
current question there — about 512 bytes against the 8 KB shown. Watch it as
the application grows.

Worth knowing about:

| Path | What it is |
|---|---|
| `zephyr/.config` | resolved Kconfig, the ground truth |
| `zephyr/zephyr.dts` | merged devicetree, board + overlay |
| `zephyr/include/generated/zephyr/devicetree_generated.h` | the macros `DT_*` expands to |
| `zephyr/zephyr.elf` | what the debugger loads |
| `compile_commands.json` | what clangd reads for IntelliSense |

`just fw-clean` removes all of it. Rebuild after changing anything structural —
Zephyr does not always notice a new source file, and a stale build directory
produces confusing errors like `ninja: error: loading 'build.ninja'`.

---

## 7. The state machine

`firmware/lib/fsm/` is a table-driven FSM. The idea: a transition table is the
specification, and the per-tick function only answers *what happened*, never
*where do I go*.

```cpp
enum class State { IDLE = 0, WORKING, DONE, FAILED };
enum class Transition { CONTINUE, FAIL, REPEAT };

// clang-format off
const Fsm::StateTransition MyFsm::_transitions[] = {
//   Current State     Transition             Next State       Timeout
    {STATE(IDLE),     TRANSITION(CONTINUE),  STATE(WORKING),  0       },
    {STATE(IDLE),     TRANSITION(REPEAT),    STATE(IDLE),     0       },
    {STATE(WORKING),  TRANSITION(CONTINUE),  STATE(DONE),     0       },
    {STATE(WORKING),  TRANSITION(REPEAT),    STATE(WORKING),  30_s    },
};
// clang-format on
```

The `// clang-format off` is required. Without it the formatter collapses the
column alignment, and the alignment is what makes the table readable as a
specification.

Four behaviours worth knowing, each covered by a test:

- **A timeout only fires on a self-loop.** A transition that leaves the state
  wins even on the tick its timeout expires. This is a fix to the original
  pattern, which checked the timeout first and could send a state that had just
  succeeded to the fail state instead.
- **A self-loop does not restart the clock.** Otherwise a state that repeats
  every tick would never reach its timeout.
- **A transition with no table row goes to the fail state.** That is a table
  bug, not a runtime condition, and failing loudly beats silently staying put.
- **`current_state_has_timeout()`** tells an event loop whether it may block
  forever. In this design that is what lets the system reach deep sleep: no
  timeout to honour means `K_FOREVER`, which means nothing is runnable, which
  means the idle thread can power down.

Time is injected via a virtual `now_ms()`. Tests override it, so a 30-second
timeout is verified in microseconds and no suite ever sleeps:

```cpp
fsm.advance(29_s);
fsm.run();
zassert_equal(fsm.get_current_state(), STATE(WORKING), "timed out early");

fsm.advance(1_s + 1_ms);
fsm.run();
zassert_equal(fsm.get_current_state(), STATE(FAILED));
```

---

## 8. Tests

```sh
just fw-test              # everything
just fw-test fsm          # one suite
```

Under the hood this is `twister`, Zephyr's runner. It builds each suite, runs
it under qemu, and parses the output.

**To add a suite**, copy `firmware/tests/fsm/` — four files:

| File | Purpose |
|---|---|
| `CMakeLists.txt` | sources, plus `add_subdirectory` for any lib under test |
| `prj.conf` | `CONFIG_ZTEST=y` and whatever the code needs |
| `testcase.yaml` | which platforms may run it |
| `src/main.cpp` | `ZTEST_SUITE` and `ZTEST` cases |

**Platforms.** `qemu_xtensa/dc233c` is the default: a full Zephyr kernel on
macOS, same architecture as the target. `native_sim` is faster and is the only
host platform that emulates GPIO, but it builds on Linux only — so suites that
drive the selector and Next need it, and that is what `just fw-test-linux`
(Docker) and CI are for.

**Fixtures.** `qdb` tests will run against real question bundles rather than
hand-written bytes. `just fw-fixtures` builds them from the question database
and decompresses them, since the device stores raw TKB2 and the gzip is only a
transport encoding. They are gitignored, so a corpus change is picked up by the
next run.

---

## 9. Debugging

**Host, under qemu.** Open the repo in VSCode and pick *sim: debug (qemu)* —
it builds, starts a gdb server on :1234 halted, and attaches. Breakpoints in
`main()` hit.

**On hardware.** *devkit: debug (OpenOCD)* uses the DevKitC-1's built-in
USB-JTAG, so no external probe is needed. It starts OpenOCD on :3333 and
attaches with the xtensa gdb from the SDK.

If either fails to launch, the SDK paths are in `.vscode/settings.json` as
`tischkarte.gdbTarget` and `tischkarte.gdbSim`. `just fw-doctor` prints the
paths that actually exist.

**Printf debugging** works too — `just fw-monitor` opens the serial console.
`LOG_INF` output appears there.

---

## 10. Errors we already hit

These all happened while setting this up. If you see one, this is the fix.

**`esptool>=5.0.2 not found in PATH`**
Zephyr's espressif CMake looks on PATH, not in the venv. The justfile prepends
`.venv/bin` for every recipe, so use `just fw-build` rather than calling `west`
directly. If you must call west by hand:
`PATH="$PWD/.venv/bin:$PATH" .venv/bin/west build …`

**`unrecognized platform - qemu_xtensa`**
Missing SoC qualifier. Use `qemu_xtensa/dc233c`. See section 3.

**`xtensa/config/core.h: No such file or directory`**
A module is missing from the allowlist in `firmware/west.yml`. This one was
`hal_xtensa`. The allowlist is narrow on purpose — importing all ~60 modules
costs several GB — so widening it when a build fails is the expected workflow.
Add the name, run `west update` (not `west update <name>`, which refuses for
imported projects).

**`zephyr/heap_constants.h: No such file or directory`**
A library added with `add_subdirectory` after `find_package(Zephyr)` misses the
generated-header dependency, so it can compile before those headers exist.
`firmware/lib/fsm/CMakeLists.txt` shows the fix:
`add_dependencies(<lib> zephyr_generated_headers)`.

**`undefined reference to` something in a lib you added**
Same root cause — Zephyr collects its own libraries before `find_package`
returns. Link it explicitly: `target_link_libraries(app PRIVATE <lib>)`.

**`invalid application of 'sizeof' to incomplete type`**
`ARRAY_SIZE(_transitions)` in a constructor defined inline in the class, above
the table's definition. Define the constructor after the table.

**`ninja: error: loading 'build.ninja'`**
A build directory left half-configured by an earlier failure. Delete it, or
build with `-p`.

**CMake 4.x complaining about a minimum required version**
CMake 4 dropped compatibility with `cmake_minimum_required(VERSION < 3.5)`.
Zephyr itself is fine; a third-party module might not be. If it happens:
`export CMAKE_POLICY_VERSION_MINIMUM=3.5`. It has not been needed here.

---

## 11. Conventions

**C++ for logic, C at the Zephyr boundary.** Not stylistic:
`ZBUS_CHAN_DEFINE`, `ZBUS_MSG_INIT` and several HAL macros expand to
out-of-order designated initializers, which C accepts and C++17 rejects.
Keeping those files `.c` means upstream samples paste in unmodified.

No exceptions, no RTTI, nothing allocates. Construct objects inside `main()`
rather than as globals — a static constructor runs before device drivers are
ready.

**Formatting** is `just fmt`. Firmware is clang-format with Linux braces and
four-space indent; `deps/` is protected by its own `DisableFormat` config, so
an editor cannot reformat Zephyr on save. `just fmt-check` is what CI runs.

**Never format `questions/`.** `just fix` (`tools/validate.py --fix`) owns that
formatting exactly, and prettier is configured to ignore it.

**Commits** are conventional, enforced by `.githooks/commit-msg`. Scope `fw`
for firmware.

---

## 12. Where to go next

The application state machine is the next piece. The design is settled — see
the diagrams in [docs/firmware_architecture.md](docs/firmware_architecture.md) —
and the order that keeps every step testable:

1. **`input`** — six selector GPIOs plus Next, publishing on zbus. Needs
   `CONFIG_ZBUS=y` and the 600 ms settle. Testable on `native_sim`.
2. **`qdb`** — TKB2 reader and the drawn-bitmap bag, against real fixtures.
   No hardware at all.
3. **`app_fsm`** — the tabletop machine, built on `lib/fsm`. Pure logic given
   fake input, so it tests under qemu.
4. **`panel`** — SSD1680 and text layout. The first part that genuinely needs
   the breadboard.

One loose end: `tools/*.py` predates the formatter and `just fmt-check` fails
on it. `just fmt-py && just lint-py` cleans it up in a commit of its own.

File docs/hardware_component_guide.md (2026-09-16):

# Rev A component guide

Why each part on the Rev A schematic is there. It walks the three functional
sheets — Power and USB, Controller and user I/O, E-paper display — and gives the
role of every component, not just the ICs. The selected part numbers and
sourcing notes are in [hardware/rev_a/BOM.md](https://github.com/giacomomellone/cicala/blob/main/hardware/rev_a/BOM.md);
the coordinate, pin and validation contracts are in [rev A hardware](hardware_rev_a.md).

This is an electrical-review baseline, not a fabrication release. The wiring
errors found so far are fixed and recorded under
[Wiring errors found and fixed](#wiring-errors-found-and-fixed); none of them
were visible to ERC.

Values quoted are the schematic values. Voltage rating, tolerance and dielectric
still have to be pinned when each line gets an ordered manufacturer part.

## Power and USB

### USB-C receptacle and CC detection

One USB-C port brings in 5 V and carries USB 2.0 data. There is no USB-PD
controller: the device is a plain 5 V sink.

| Ref | Value | Role |
| --- | --- | --- |
| J1  | USB-C 2.0 16-pin | Power and data inlet. VBUS and GND are doubled on the receptacle; the SBU and shield pins are unused. |
| R1  | 5.1 kΩ | CC1 pull-down (Rd). Advertises the board as a sink so a source turns on 5 V. |
| R2  | 5.1 kΩ | CC2 pull-down (Rd). The second CC line makes detection work in both plug orientations. |

Two 5.1 kΩ resistors (one per CC line) are required rather than one, because a
reversible cable can land the source's CC on either pin.

### Data-line ESD and series termination

| Ref | Value | Role |
| --- | --- | --- |
| U4  | USBLC6-2SC6 | Low-capacitance ESD/TVS array on the D+/D− pair, placed at the connector so a discharge is clamped before it reaches the MCU. |
| R3  | 22 Ω | Series resistor on D− between the TVS and the ESP32-S3, for impedance matching and edge control. |
| R4  | 22 Ω | Series resistor on D+, same purpose. |
| C1  | 3 pF, DNP | Optional D− shunt for extra edge slowing. Not populated; a footprint kept for tuning. |
| C2  | 3 pF, DNP | Optional D+ shunt, same. |

The 22 Ω series parts sit between the TVS and the MCU so the clamp is closest to
the connector. The native USB pins (GPIO19/20) are the ESP32-S3 USB-Serial/JTAG
block, so this one port does flashing, serial console and JTAG without a USB-UART
bridge chip.

### Shell grounding

| Ref | Value | Role |
| --- | --- | --- |
| R33 | 0 Ω | Ties the USB-C shell to board ground. Fitted by default. |
| C31 | 1 nF, 2 kV | The alternative if a DC-isolated shell is ever wanted; not fitted alongside R33. |

The enclosure is plastic and carries no chassis ground, so the shell's only
discharge path is into the board. A direct connection at the receptacle gives
that discharge the shortest route to the ground plane.

### VBUS presence sensing

| Ref | Value | Role |
| --- | --- | --- |
| R5  | 100 kΩ | Top of the VBUS divider, from VBUS to the sense node. |
| R6  | 150 kΩ | Bottom of the VBUS divider. 100 k over 150 k scales 5 V to 3.0 V, which clears the ESP32-S3 guaranteed high-input threshold at 3.3 V. The earlier 150 k/100 k gave 2.0 V and did not. |
| C4  | 1 µF 25 V | Bulk/decoupling on VBUS at the charger input. |
| C3  | 100 nF | Filters the divided VBUS-sense node against noise and switching transients. |

The high-value divider keeps the standing current on VBUS at 20 µA, which
matters for the sleep budget when USB is attached but idle.

### BQ25185 charger and power path

The charger runs the cell and supplies the system rail (VSYS) with power-path
switching between USB and battery.

| Ref | Value | Role |
| --- | --- | --- |
| U2  | BQ25185 | Single-cell linear charger with power path. Sets charge from USB and hands VSYS to the regulator. |
| C4  | 1 µF 25 V  | Input (VBUS/IN) capacitor, shared with the VBUS sense group above. |
| C5  | 10 µF 25 V | SYS/VSYS output capacitor for the power path. |
| C6  | 1 µF 16 V  | BAT-pin decoupling next to the cell connection. 16 V keeps useful capacitance at 4.2 V. |
| R7  | 18 kΩ | ILIM/VSET — sets the 4.2 V cell target and the 500 mA input current limit. |
| R8  | 1.20 kΩ | ISET — sets the 250 mA fast-charge current for the ~500 mAh pack. |
| R9  | 10 kΩ | Pull-up on the open-drain STAT1 status output so the MCU can read it. |
| R10 | 10 kΩ | Pull-up on the open-drain STAT2 status output. |
| R13 | 100 kΩ | Pull-down on /CE so charging is enabled by default even before firmware runs. |

STAT1/STAT2 are open-drain, so they need the two 10 kΩ pull-ups to present a
logic level. The /CE pull-down is a deliberate fail-safe: a blank board still
charges.

### Protected cell and temperature sense

| Ref | Value | Role |
| --- | --- | --- |
| J3  | 3-pin JST-PH | Protected LiPo connector: VBAT, the NTC sense wire, and GND. |
| R34 | 0 Ω | Removable link in the cell lead, with TP22 on the pack side. Lifting it puts a meter between the pack and everything else, which is how whole-device sleep current is measured. Specify a part rated at least 1 A. |
| BT1 | 503035-class 1S LiPo | Off-board protected pack with PCM and a 10 kΩ B=3435 NTC on a keyed three-wire harness. |

The charger sources about 38 µA into its TS pin, so the pack's 10 kΩ NTC to GND
sets the temperature window directly (roughly 1.5 °C cold to 59 °C hot) with no
external bias resistors. TS/MR is its own `BATT_NTC` net carrying only the NTC
wire; tying it to VBAT (an earlier error, now fixed) would have read as
out-of-range and suspended charging.

### TPS63802 buck-boost 3.3 V rail

A buck-boost holds 3.3 V across the whole useful LiPo range, where a linear
regulator would drop out as the cell approaches 3.3 V.

| Ref | Value | Role |
| --- | --- | --- |
| U3  | TPS63802 | Low-IQ buck-boost regulator, VSYS in, 3V3 out. |
| L2  | 0.47 µH (XFL4015) | Buck-boost inductor; the single energy-storage element the topology switches. |
| C8  | 10 µF 25 V | Input capacitor on VSYS at the regulator. 25 V because SLUSF65B section 7.2.2.3 asks for it on the SYS node, and because the regulator needs 4 µF effective on VIN, which a 6.3 V part at 4.5 V does not reliably give. |
| C9  | 22 µF 6.3 V | Output bulk on 3V3. |
| C10 | 47 µF 6.3 V | Additional 3V3 output bulk for transient response and display-refresh load steps. |
| C11 | 100 nF | High-frequency 3V3 decoupling. |
| R14 | 511 kΩ 1% | Top of the feedback divider. |
| R15 | 91 kΩ 1% | Bottom of the feedback divider. 511 k/91 k sets V_out = 0.5 V·(1 + 511/91) ≈ 3.31 V. |
| R16 | 100 kΩ | Pull-up on the open-drain PG (power-good) output, exposed as REG_PG. |

The 1 % feedback resistors set the output voltage, so their tolerance matters;
ordinary parts elsewhere can be 5 %. MODE is tied low for power-save operation at
light load, which is where the device spends most of its life.

### Switched battery measurement

Measuring the cell through a fixed divider would leak current continuously, so
the divider is switched off except during a reading.

| Ref | Value | Role |
| --- | --- | --- |
| U5  | TPS22917 | Load switch that connects the battery divider only when the MCU asserts VBAT_SENSE_EN. |
| R11 | 1 MΩ | Top of the battery-sense divider. |
| R12 | 470 kΩ | Bottom of the battery-sense divider; 1 M/470 k scales VBAT into the ADC range. |
| C7  | 100 nF | Filters the ADC sense node for a stable reading. |

The megohm-scale divider keeps the measurement current tiny, and the load switch
removes even that during sleep.

## Controller and user I/O

### ESP32-S3 module and boot straps

| Ref | Value | Role |
| --- | --- | --- |
| U1  | ESP32-S3-WROOM-1(-U) | The controller: Wi-Fi/BLE SoC module running the firmware. WROOM-1 is preferred; WROOM-1U is the antenna fallback. |
| C28 | 100 nF | High-frequency decoupling at the module 3V3 pin. |
| C29 | 10 µF | Mid-band bulk for the module supply. |
| C30 | 47 µF | Bulk to hold the rail through radio and flash current bursts. |
| R25 | 10 kΩ | EN pull-up so the module runs by default. |
| C27 | 1 µF | EN capacitor: an RC delay on reset for a clean power-up, and debounce on EN. |
| R26 | 10 kΩ | IO0 pull-up so the module boots from flash normally; pulling IO0 low selects download mode. |

The EN pull-up plus 1 µF gives the reset an RC rise; the IO0 pull-up sets normal
boot. Both nets reach the recovery header so a bad image can be forced into
download mode.

### Buttons

| Ref | Value | Role |
| --- | --- | --- |
| SW1 | KSC321G | "Category" tactile switch (also an RTC wake source). |
| SW2 | KSC321G | "Next" tactile switch (also an RTC wake source). |
| R21 | 47 kΩ | Pull-up on the Category line; the switch pulls it to GND when pressed. |
| R22 | 47 kΩ | Pull-up on the Next line. |
| C25 | 10 nF | Hardware debounce on Category, with R21. |
| C26 | 10 nF | Hardware debounce on Next, with R22. |

47 kΩ pull-ups keep the standing current on each idle button under 100 µA; the
10 nF caps give an RC debounce so a single press is not read as several.

### Status LED

| Ref | Value | Role |
| --- | --- | --- |
| D4  | APBA2006 red/green | Side-view bi-colour status indicator, driven anode-high by two GPIOs. |
| R23 | 1 kΩ | Red-channel series/current-limit resistor. |
| R24 | 1 kΩ | Green-channel series resistor. |

Both dies are AlGaInP: hyper red at 1.95 V typical and 2.5 V maximum, green at
574 nm, 2.1 V typical and 2.5 V maximum. From 3.3 V through 1 kΩ that is
0.8 mA in the worst case and about 1.3 mA typically. That is a deliberately
small current, and how much of it reaches the eye through the light pipe is a
bench measurement, not a calculation.

Each die has its own series resistor, so both GPIOs low leaves no standing LED
current in sleep. The part is two independent diodes; the board ties both
cathodes to GND to use it as a common-cathode LED.

### Recovery header and production test points

| Ref | Value | Role |
| --- | --- | --- |
| J4 | Tag-Connect TC2030 (DNP) | Concealed recovery interface: 3V3, GND, EN, IO0, UART0_TX, UART0_RX — a full UART download path when native USB is unavailable. Pads only, no fitted part. |
| TP1–TP11 | test points | Bring-up/probe access: BOOT_IO0, CHIP_EN, GND, UART0_TX, UART0_RX, FACTORY_RESET_OD, 3V3, VBAT, VSYS, USB_VBUS, REG_PG. |

USB-C is the normal flashing/console/JTAG port. J4 and the test points are the
fallback for when firmware has reconfigured or disabled the native USB; they live
on the underside and are reached only with the case open.

## E-paper display

The panel is a GDEY0213B74 with an on-glass SSD1680 controller. Its analog
supplies are generated on-board by a boost and a pair of charge pumps, following
Good Display's reference circuit, and are switched off between refreshes.

### Switched panel supply

| Ref | Value | Role |
| --- | --- | --- |
| U6  | TPS22917 | Load switch that removes 3V3 from the panel and boost network between refreshes (gated by EPD_PWR_EN). |
| C12 | 1 µF | Input decoupling on the switch's 3V3 input. |
| C13 | 10 µF | Output bulk on the switched panel rail (EPD_3V3). |
| C14 | 1 nF | CT capacitor setting the switch's controlled turn-on slew, to limit inrush into the panel caps. |
| R18 | 150 Ω | Quick-output-discharge resistor: bleeds the panel rail down fast when the switch opens, so the panel restarts cleanly. |

Switching the whole panel supply is what makes the display-off leakage near zero;
the CT slew limits inrush and the QOD resistor guarantees a clean rail collapse.

### SSD1680 boost and charge pumps

| Ref | Value | Role |
| --- | --- | --- |
| L1  | 47 µH (VLS4012) | Boost inductor for the panel's high-voltage generation. |
| Q1  | Si1308EDL | Switching MOSFET driven by the SSD1680 gate-driver output (EPD_GDR). |
| R20 | 2.2 Ω | Boost current-sense resistor at the RESE pin, setting the switch current. |
| R19 | 1 MΩ | Gate pull-down on EPD_GDR, keeping the MOSFET defined and off when the driver is inactive. |
| D1  | MBR0530 | Output diode of the negative (VGL) pump: cathode on EPD_PUMP, anode on EPD_PREVGL. |
| D2  | MBR0530 | Clamp diode of the VGL pump: anode on EPD_PUMP, cathode to GND. |
| D3  | MBR0530 | Schottky in the positive (VGH) charge pump from the switch node. |
| C15 | 4.7 µF 25 V | Boost/panel reservoir on EPD_3V3. |
| C16 | 4.7 µF 25 V | Flying capacitor between the switch node and the pump node EPD_PUMP. |

Schottky diodes are used for their low forward drop and fast recovery, which the
charge pumps need to reach the panel's ±15 V-class rails efficiently.

### Bus isolation and reset parking

The panel's logic pins sit behind series resistors so that driving one while
`EPD_3V3` is off cannot push current into the panel through its own ESD diodes.

| Ref | Value | Role |
| --- | ----- | --- |
| R27–R31 | 470 Ω | In series with CLK, MOSI, CS, D/C and RES#. Caps the injected current at about 5.7 mA per pin against a 3.3 V output and a diode drop, and damps the edges; fit 0 Ω to remove them during bring-up. |
| R32 | 1 MΩ  | Pull-down on the panel side of RES#, so the panel is held in reset while its rail is off and while the MCU pin is high-impedance. |

At 4 MHz into roughly 20 pF of connector and trace, 470 Ω adds about 21 ns of
rise time, which is a small fraction of the 125 ns half-period. The resistors
are the fallback, not the plan: firmware still parks the bus before removing
panel power.

### Panel rail reservoirs and FPC

Each SSD1680 analog rail gets its own reservoir capacitor so it holds voltage
through a refresh.

| Ref | Value | Rail / role |
| --- | --- | --- |
| C17 | 1 µF 25 V | EPD_PREVGH pre-charge-pump reservoir |
| C18 | 1 µF 25 V | EPD_VSH2 (positive source) |
| C19 | 1 µF 25 V | EPD_3V3 (panel VCI/VDDIO) |
| C20 | 1 µF 25 V | EPD_VDD |
| C21 | 1 µF 25 V | EPD_VSH1 |
| C22 | 1 µF 25 V | EPD_VSL (negative source) |
| C23 | 1 µF 25 V | EPD_PREVGL pre-charge-pump reservoir |
| C24 | 1 µF 25 V | EPD_VCOM (common electrode) |
| J2  | FH12-24S-0.5SH | 24-pin 0.5 mm bottom-contact ZIF connector for the panel FPC. |

The 25 V rating on the pump and rail capacitors is deliberate: the charge-pump
nodes swing well above 3.3 V.

## Wiring errors found and fixed

Four errors reached the captured schematic and all four passed ERC, because each
was an electrically valid connection that was simply wrong. They are fixed; the
list is kept so the same checks get repeated on the next capture.

- **USB-C D+/D− shorted, then crossed (critical).** J1's D+ (A6/B6), D− (A7/B7)
  and CC2 (B5) first sat on one net tied to both USBLC6 line pins. Separating
  them left the pair crossed: the connector's D− reached GPIO20 (USB_D+) and D+
  reached GPIO19 (USB_D−). D− now runs J1 → U4 I/O1 → R3 → USB_DN → GPIO19 and
  D+ runs J1 → U4 I/O2 → R4 → USB_DP → GPIO20.
- **Q1 gate and source swapped.** The capture used `Q_NMOS_SGD`, but the
  Si1308EDL in SOT-323 is pin 1 = G, 2 = S, 3 = D. The symbol is now
  `Q_NMOS_GSD`, so EPD_GDR lands on the gate and EPD_RESE on the source.
- **D1 shorted, then D2 on the wrong node.** Both D1 terminals sat on
  EPD_PREVGL. Freeing D1 left D2's anode on EPD_PREVGL instead of the pump node,
  which gave the flying capacitor no charging path. D1's cathode, D2's anode and
  C16 now meet at EPD_PUMP, matching the GDEY0213B74 reference circuit.
- **C21 was 1 nF.** VSH1 is a driving rail and the reference gives it 1 µF/25 V,
  as every other panel rail here already had.

Three net names were also lost in a sheet re-layout and restored: `BATT_NTC`,
`BTN_CATEGORY` and `BTN_NEXT`, all of which `pin_contract.csv` refers to.

Two earlier errors from the same review were fixed before these: the TPS63802
feedback divider (FB had been shorted to VOUT, bypassing R14) and the BQ25185
TS/MR path (now the `BATT_NTC` net). See [decisions](decisions.md) for the
record.

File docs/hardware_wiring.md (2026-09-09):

# Hardware and wiring

This page describes the breadboard rig and its bench checks. See
[prototype BOM](prototype_bom.md) for parts, [device prototype](device_prototype.md)
for the product design, and [firmware architecture](firmware_architecture.md)
for firmware behavior.

The rig includes the two buttons, e-paper panel, charger, cell, voltage dividers,
and separate red and green status LEDs. The DevKitC indicators make sleep-current
measurements invalid for the 30 µA target; use rev A or a separate power mule for
that measurement.

## Wiring overview

```text
   cell ──JST──┐
               │
      ┌────────┴─────────────────────────────┐
      │        Adafruit 6092 · bq25185       │
      │   USB-C ──► charge input             │
      │                                      │
      │   ● VU      ● BAT      ● 3V     ● −  │
      └─────┬──────────┬─────────┬────────┬──┘
            │          │         │        │
       100k/150k   470k/470k     │        │
            │      + 100 nF      │        │
            ▼          ▼         ▼        ▼
         GPIO21      GPIO1      3V3      GND ─────┐
      ┌──────────────────────────────────────┐    │
      │        ESP32-S3-DevKitC-1            │    │
      │                                      │    │
      │  GPIO4  ──── Filters switch ────────┼────┤
      │  GPIO17 ──── Next switch ────────────┼────┤
      │  GPIO15 ──── R ──►|── red ───────────┼────┤
      │  GPIO16 ──── R ──►|── green ─────────┼────┤
      │                                      │    │
      │  GPIO10 11 12 13 · 18 8 9 ──── HAT   │    │
      │  3V3, GND ───────────────────── HAT ─┼────┤
      └──────────────────────────────────────┘    │
                                              − rail
```

Connect every ground to one rail: charger, dividers, capacitor, DevKitC,
switches, LEDs, and panel.

## Pin assignment

| GPIO | Function | Direction | Notes |
| ---: | --- | --- | --- |
| 4 | Filters | input, pull-up | active low; RTC-capable |
| 17 | Next | input, pull-up | active low; RTC-capable |
| 10 | e-paper CS | output | SPI2 |
| 11 | e-paper MOSI | output | SPI2 |
| 12 | e-paper SCK | output | SPI2 |
| 13 | SPI MISO | input | claimed by SPI2; unused by panel |
| 18 | e-paper D/C | output | active high |
| 8 | e-paper reset | output | active low |
| 9 | e-paper busy | input | active high |
| 1 | battery sense | ADC1_CH0 | 470 kΩ / 470 kΩ divider |
| 21 | VBUS detect | input | 100 kΩ / 150 kΩ divider |
| 15 | red status LED | output | active high |
| 16 | green status LED | output | active high |

Wake inputs must use RTC-capable GPIO0–21. GPIO19 and GPIO20 remain free for
native USB. GPIO0 and GPIO3 are strapping pins; GPIO26–32 are used by flash;
GPIO33–37 are used by octal PSRAM; GPIO43/44 carry UART0; GPIO48 drives the
onboard WS2812.

GPIO0–31 belong to Zephyr controller `gpio0`; GPIO32–53 belong to `gpio1`. For
example, GPIO48 is `<&gpio1 16 ...>`.

Battery sensing uses ADC1 because ADC2 shares hardware with Wi-Fi. GPIO2, 5, 6,
7, and 14 remain spare and RTC-capable.

## Voltage dividers

Use 1% metal-film resistors. The 100 nF battery-sense capacitor must be ceramic
(X7R or C0G); electrolytic leakage causes a large error at this impedance. An
1/8 W rating is sufficient.

### Battery sense

```text
   BAT (3.0–4.2 V)
      │
    470 kΩ
      │
      ├────────────┬────────────► GPIO1
      │            │
    470 kΩ        100 nF
      │            │
      └────────────┴────────────► GND
```

The tap is half the cell voltage. Place the capacitor across the lower resistor,
close to GPIO1. `CONFIG_CICALA_POWER_DIVIDER_NUM=2` and
`CONFIG_CICALA_POWER_DIVIDER_DEN=1` convert the ADC reading back to cell voltage.

| Resistor pair | Current at 4.2 V | Source impedance |
| --- | ---: | ---: |
| 100 kΩ / 100 kΩ | 21 µA | 50 kΩ |
| 470 kΩ / 470 kΩ | 4.5 µA | 235 kΩ |
| 1 MΩ / 1 MΩ | 2.1 µA | 500 kΩ |

The BOM uses 470 kΩ. Rev A switches this divider off during sleep. Connect the
divider to `BAT`, which follows the cell, rather than the regulated 3.3 V rail.

### VBUS detect

```text
   VU (about 5 V with charger USB-C connected)
      │
    100 kΩ
      │
      ├─────────────────────────► GPIO21
      │
    150 kΩ
      │
      └─────────────────────────► GND
```

The tap is about 3.0 V. A 100 kΩ / 100 kΩ divider leaves too little margin over
the ESP32-S3 input-high threshold. Connect the divider to `VU`; `VIN` can reach
18 V and would overvoltage GPIO21. DC or solar power applied at `VIN` is not
detected as VBUS.

Before fitting either divider, connect GPIO1 and GPIO21 to ground. Both pins are
read by the normal firmware and must not float. Remove each jumper only after
checking the corresponding divider tap with a meter.

The buttons are the deep-sleep wake sources. USB insertion is sampled on the
next boot; `CONFIG_CICALA_POWER_WAKE_ON_USB` is disabled because the ESP32-S3 cannot
mix EXT1 trigger polarities per pin.

## Buttons

Both buttons are active low and use internal pull-ups. Connect one leg from each
internally joined pair of a tactile switch:

```text
   switch viewed from above

     1 ●━━━━━━━━━● 2
       ╎  ▄▄▄▄▄  ╎
     3 ●━━━━━━━━━● 4

   GPIO ───● 1        4 ●─── GND
```

Connect Filters to GPIO4 and Next to GPIO17. Continuity should be open when
released and closed when pressed.

## Status LEDs

```text
GPIO15 ── resistor ──►|── GND    red
GPIO16 ── resistor ──►|── GND    green
```

The long leg is the anode and faces the resistor. Choose resistor values for a
clear but subdued indication across a table.

| State | Red | Green |
| --- | --- | --- |
| Healthy on battery  | off | off |
| Charging | on | off |
| Charged | off | on |
| Setup portal | on | on |
| Sync or update | off | slow pulse |
| Low-battery warning | one blink | one blink  |
| Refresh refused | three blinks | off |

The breadboard uses separate LEDs. Rev A uses one bi-color package, where both
dies appear amber when lit together.

## E-paper panel

Connect the Waveshare HAT through its 40-pin header:

```text
   pin 1  VCC  → 3V3       pin 6  GND  → GND
   pin 11 RST  → GPIO8     pin 18 BUSY → GPIO9
   pin 19 DIN  → GPIO11    pin 22 DC   → GPIO18
   pin 23 CLK  → GPIO12    pin 24 CS   → GPIO10
```

The overlay targets the 250 × 122 V3/V4 panel:

| Revision | Devicetree compatible | Controller | Size |
| --- | --- | --- | --- |
| V3 / V4  | `gooddisplay,gdey0213b74` | SSD1680 | 250 × 122 |
| V2 | `gooddisplay,gdeh0213b72` | SSD1675A | 250 × 120 |
| V1 | `gooddisplay,gdeh0213b1`  | SSD1673 | 250 × 120 |

Set the compatible and height to match the board marking. The panel uses
MIPI-DBI; [firmware architecture](firmware_architecture.md#display) describes
the refresh policy.

## Power and cables

Connect the charger's `3V` output to DevKitC `3V3` and `−` to GND. This bypasses
the DevKitC regulator. Disconnect the cell, or open a switch in its lead, before
powering the DevKitC from USB: otherwise both regulators drive the 3.3 V rail.

The charger `VU` signal detects only the charger USB-C input. A DevKitC cable
powers the board without asserting VBUS detect, so remove all DevKitC cables for
battery and current measurements.

| Job | Cell | Charger USB-C | DevKitC UART | DevKitC USB  |
| --- | --- | --- | --- | --- |
| Flash and normal console | disconnected | disconnected  | connected | optional |
| Debug console and JTAG | disconnected | disconnected  | connected for flash | connected |
| Charge-state check | connected | connected | disconnected | disconnected |
| Battery behavior | connected | disconnected  | disconnected | disconnected |
| Sleep current | connected through meter | disconnected  | disconnected | disconnected |

The UART jack appears as `/dev/cu.usbserial-*` and carries flashing and the
normal console. The native USB jack appears as `/dev/cu.usbmodem*` and carries
JTAG plus the debug profile's console. Opening the UART port resets the chip via
the CP2102 auto-reset circuit.

Rev A routes charger USB D+/D− to GPIO19/20. Native-USB flashing through that
route remains a hardware verification item.

## Bring-up checks

Perform these checks in order.

1. With nothing connected, confirm that the 6092 charge-rate jumper is open.
   Check that cell polarity matches the charger marking and that the cell reads
   3.6–4.0 V. A reversed cell can damage the charger and cell.
2. Connect the charger and cell. Confirm `3V` is 3.30 V ±0.05 and `4.5V` is near
   cell voltage. Connect charger USB-C briefly; `VU` should be about 5 V and the
   charge LED should light.
3. Measure each divider before connecting it to the MCU. Battery sense should be
   half the cell voltage. VBUS sense should be 2.9–3.1 V with charger USB-C
   connected and about 0 V without it.
4. Touch each LED resistor to 3.3 V and confirm polarity.
5. With DevKitC USB disconnected, connect charger `3V` to DevKitC `3V3` and
   charger `−` to GND. Confirm 3.30 V ±0.05 at the DevKitC.
6. Disconnect the cell before connecting the DevKitC UART cable for flashing.

Build the power profile to inspect ADC and VBUS readings:

```sh
just fw-flash power
just fw-monitor power
```

Compare the reported cell voltage with a meter at `BAT`; the error should be
within about 2%. Connect and disconnect charger USB-C and confirm that VBUS
follows on the next sample. Check charging red, charged green, portal amber, and
the three-red-blink refresh refusal.

Restore the release profile and test on the cell with all DevKitC cables removed:

```sh
just fw-flash
```

The panel should respond to both buttons, the LEDs should follow charger state,
and the device should sleep two seconds after external power is removed.

## Functional checks

```sh
just fw-flash
just fw-monitor
```

- Cold boot starts with Dark, Sexual, and Heavy excluded.
- Filters opens the four-row menu; Next toggles the selected permission or applies Done.
- Next shows one question per accepted press.
- Holding and releasing a button produces one event.

Ground GPIO1 and GPIO21 when the dividers are absent. A floating GPIO21 can keep
the device awake; a floating GPIO1 can make the firmware reject refreshes.

## Bench measurements

Measured with a Waveshare 2.13-inch V4 panel:

| Measurement | Result | Configuration |
| --- | --- | --- |
| Consecutive partial refreshes | minor artifacts at 193; visible ghosting before 64 | `CICALA_FULL_REFRESH_INTERVAL=16` |
| Partial refresh duration | 622 ms ±2 ms across 193 refreshes | below the 1 s product target |
| Refresh after deep-sleep wake | 624 ms | Zephyr panel patch applied |
| Peak thread stack | logging 89%; other threads 18–38% | `LOG_PROCESS_THREAD_STACK_SIZE=2048` |
| RTC memory across warm reboot | retained across three runs | retained block works on ESP32-S3 |
| Battery reading | 3890 mV reported; 3930 mV measured | divider ratio remains 2/1 |
| VBUS detection | followed first sample after connect and disconnect | sync and sleep inputs work |

Open measurements:

- full-refresh duration at the BUSY pin;
- lowest cell voltage that gives a clean partial refresh;
- discharge curve;
- idle, refresh, Wi-Fi, LED, and sleep current.

### Measurement profiles

Use `just fw-flash <profile>` and `just fw-monitor <profile>`.

| Profile | Purpose |
| --- | --- |
| `soak` | Draw a new question every five seconds with periodic full refresh disabled. Record the first visible ghosting. |
| `retain`  | Warm reboot every three presses. Confirm sequence and partial-refresh state survive. |
| `charset` | Draw every supported diacritic and inspect placement. |
| `power` | Log raw and converted ADC values once per second. Use for divider calibration and discharge measurements. |

For the refresh floor, replace the cell with a bench supply and reduce voltage
in steps while requesting partial refreshes. Set `CICALA_REFRESH_MIN_MV` above the
first voltage that leaves visible artifacts. Below the configured floor, the
panel should remain unchanged and the red LED should blink three times.

Measure current in series with the cell and remove every DevKitC USB cable. The
DevKitC power LED and onboard WS2812 add roughly 1–2 mA, so this rig cannot
validate the 30 µA sleep budget.

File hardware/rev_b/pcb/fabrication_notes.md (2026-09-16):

# Cicala Rev B.05 — engineering prototype fabrication notes

Reviewed 16 September 2026. This package supports a first-article fabrication and
assembly review. It is not a production release. No factory has accepted the
stack, tooling, component sourcing or assembly process, and no integrated unit
has been powered. Do not substitute parts or change copper without approval.

## Board order

| Setting | Required specification |
| --- | --- |
| Board | One design; routed L outline, 113 × 62 mm bounding box; dimensions from Edge.Cuts |
| Material | FR-4, four copper layers, nominal 1.2 mm finished board; maximum 1.33 mm reserved |
| Copper | 1 oz finished outer; 1 oz inner; no blind/buried vias or filled via-in-pad |
| Finish | ENIG, lead-free process; green solder mask, white legend on both sides |
| Quality | IPC Class 2 acceptance; electrical open/short test on every bare board; AOI after SMT |
| Geometry | 0.20 mm general track/space; 0.15 mm fine-pitch escape width; local 0.15 mm U7 pad spacing |
| Holes | Standard vias Ø0.30/0.60 mm drill/land; use separate plated/non-plated drill files |
| Switch holes | SW1/SW2: Ø1.20 ±0.05 mm **finished PTH**, Ø1.80 ±0.05 mm NPTH; preserve the 12.5 × 5 mm terminal grid and 9 mm boss pitch |
| Edge | Routed, R1 concave corner, 0.50 mm minimum copper clearance; no V scoring through the L |
| Mask | Follow supplied masks; keep probe contacts exposed; do not fill or cap test-contact vias |
| Panel | Factory-designed tab-routed support, ≥5 mm handling rails and 2 mm route channels; approval drawing before manufacture |
| Tooling | Fiducials and tooling holes on removable rails; support both arms during assembly and depanelization |
| Marking | Keep factory order marks on removable rails; preserve Cicala and all diagnostic labels |

PCBWay's published standard PTH tolerance is ±0.08 mm, which is wider than the
switch drawing. Obtain written acceptance of the specified **±0.05 mm** switch
holes. NPTH tolerance is also explicit. A nominal drill file does not request a
tighter finished-hole tolerance by itself.
[PCBWay capabilities](https://www.pcbway.com/capabilities.html).

Keep tabs away from the module antenna, USB mouth, switch apertures, mounting
holes and reentrant corner. Factory-depanelize and deburr before shipment; no
remaining tabs may intrude into the enclosure fit. Return the panel drawing for
review. [PCBWay assembly panel requirements](https://www.pcbway.com/pcb_prototype/Panel_Requirements_for_Assembly.html).

## Controlled impedance

Target **90 Ω differential, ±10%**, for the USB main pair on B.Cu, referenced to
the designated In2.Cu ground corridor. Main geometry is 0.28 mm trace width and
0.24 mm edge gap. Local launches differ; use the complete native board for review.
Keep the reference corridor continuous and the return vias intact.

Calculation basis: PCBWay's published four-layer 1.2 mm entry 17, 0.1855 mm pressed
outer dielectric, Dk 4.74, 1 oz inner/outer copper. The published entry lists
0.630 mm core and 1.21 mm finished thickness. KiCad's normalized 0.689 mm core only
makes the CAD substrate total 1.2 mm; it is **not** a factory stack instruction.
Confirm the actual laminate, pressed thicknesses, solder mask and required width/gap
before releasing CAM. Request an impedance coupon and measured report. If the
proposed stack requires different geometry, return it for layout review instead
of scaling or silently editing the tracks.
[PCBWay stack table](https://www.pcbway.com/multi-layer-laminated-structure.html).

## Assembly scope and files

Install **87 SMT components on the top face and two Omron B3F-4050 through-hole
switches from the top**. The full native BOM/position files cover all 89 electronic
references. `cicala_rev_b_smt_bom.csv` and `cicala_rev_b_smt_pos.csv` isolate the SMT
stage; the JLC BOM/CPL also covers only these 87 parts. `manual_assembly.csv`
specifies the switches and two caps. Include its operations in the quote; an SMT
upload alone is not a complete assembly order.

Use exact manufacturer part numbers. Blank LCSC fields mean sourcing is required,
not that a part is optional. The caps, display, protected cell, NTC harness, lens,
plastics and fasteners are additional device parts, not SMT placements. Request
B32-1200 ivory and B32-1320 orange caps packed separately for enclosure assembly.

- Inspect USB connector position, Molex FPC pin 1/entry direction, diode polarity,
  module antenna overhang and U2/U3 exposed pads against the assembly drawings.
- Use a 0.10 mm laser-cut stainless stencil as the initial process proposal. The
  assembler must approve aperture volumes, paste and reflow profile for the mixed
  package sizes. Inspect hidden U2/U3 joints by X-ray; ask for the inspection record.
- Complete SMT reflow and cleaning **before** adding B3F switches. The switches
  are unsealed and must not be washed. Follow Omron's permitted soldering process.
- Seat switch bodies on the PCB; support the board during soldering and later cap
  fitting. The total lead/fillet projection below B.Cu must be **≤2.60 mm**. Trim
  where needed, remove clippings and inspect for shorts. This preserves at least
  0.40 mm modeled clearance to the base under the declared assembly assumptions.
- SW1 is Filters at upper right: ivory **9 × 9 mm B32-1200**. SW2 is Next at lower
  right: orange **12 × 12 mm B32-1320**. Fit caps only after soldering. Released
  contacts must be open and pressed contacts closed; inspect both duplicate pairs.

[Omron B3F process restrictions](https://omronfs.omron.com/en_US/ecb/products/pdf/en-b3f.pdf),
[Omron B32 cap drawing](https://omronfs.omron.com/en_US/ecb/products/pdf/en-b32.pdf).

No programming or functional-test binary is included. The Rev B UC8253 firmware
port remains outstanding. Optical/X-ray inspection and an unpowered continuity
test do not certify operation of the device.

## Enclosure print order

Use the four parts in `case/exports/print/core/`: base, top shell, display
frame and support bar. Select either STL or 3MF for each part, not both.
Optional accessories and the temporary flex-forming jig
are separate. Never print `reference/` files. STL/3MF units are mm; do not scale,
mirror or auto-thicken parts. Native assembly meshes use X right, Y up, matching
KiCad STEP after translating the PCB upward by 4.6 mm. Print files are separately
rotated and placed on the bed.

For the first dimensional sample, request **SLA Somos Ledo tough resin, natural
colour, no paint or dimensional coating**, with support removal and full cure.
Ask for explicit acceptance of the 1.4 mm shell walls, 1.2 mm base and 0.8 mm display
supports, and an inspection of the button openings and PCB seats. Local dimensional
assumptions are tighter than a generic whole-part percentage tolerance; they must
be confirmed, measured or compensated. Thin supports and pilot threads need a
sample before selecting a final process/material. SLS/MJF is not approved merely
because it is stronger; the service's wall and tolerance rules must be met.
[PCBWay SLA service](https://www.pcbway.com/rapid-prototyping/3d-printing/3d-printing-SLA.html),
[JLC3DP design guidelines](https://jlc3dp.com/help/article/3d-printing-design-guideline).

Home fit trials may use PETG, 0.4 mm nozzle, 0.15 mm layers, three or more walls;
inspect slicer paths through thin features. Keep support scars off the PCB seats,
lens seat and button wells. Do not force a screw into an undersized printed pilot.

The housing is **128 × 66 × 16.8 mm**. Cap faces are nominally at z=15.8 mm,
**1.0 mm recessed**, in 10 × 10 and 13 × 13 mm throats with 1.4 mm flared mouths.
Four M2.5 × 10 mm countersunk screws close the core; check thread engagement and
head seating on the empty sample. Electronics, lens and cell are installed later.

## Release conditions

CAM acceptance must include the stack/impedance, switch-hole tolerances, panel,
exact BOM/placement, stencil, no-wash switch sequence and printed critical fits.
The first articles then need power/recovery, display/flex, battery/NTC/current,
USB/RF, enclosure and button force/return measurements. The optional phone carrier
fails the iPhone 16 Plus dimensional screen and is not part of a validated product.

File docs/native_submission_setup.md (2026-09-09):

# Native question submission setup

The `/suggest` and `/edit` pages submit without a user account. A Cloudflare
Pages Function verifies the request, authenticates as a repository-scoped
GitHub App and opens an issue: `question-submission` for a new question, which
the review workflow promotes, or `question-edit` for a change to an existing
one, which a maintainer handles by hand.

This setup creates credentials in GitHub and Cloudflare. Never put their
values in this repository, an issue, a shell command, or documentation.

## Runtime boundary

```mermaid
flowchart LR
    B[Browser] -->|same-origin JSON + Turnstile token| F[Pages Function]
    F -->|secret key signs JWT| A[GitHub App API]
    A -->|one-hour installation token| F
    F -->|Issues: write| I[question-submission issue]
    F -->|Issues: write| E[question-edit issue]
    I --> W[GitHub Actions review and promotion]
    E --> M[Maintainer review]
```

The private key exists only as an encrypted Cloudflare runtime secret. The
browser receives the public Turnstile site key from `GET /api/suggestions` or
`GET /api/edits` and never receives a GitHub credential. The function does not use a personal
access token, OAuth client secret, user token or webhook secret.

The App needs `Issues: write` on one repository. It does not need Contents,
Pull requests, Actions, Administration, organization or account permissions.
The workflow's own `GITHUB_TOKEN` continues to create the branch and pull
request after a maintainer approves an issue.

## 1. Create the GitHub App

Open the GitHub account or organization that owns the repository, then go to
**Settings → Developer settings → GitHub Apps → New GitHub App**.

Use these settings:

| Setting | Value |
| --- | --- |
| Name | `cicala-bot`, or the closest available unique name |
| Homepage URL | `https://cicala.dev` |
| User authorization callback | disabled / empty |
| Webhook | inactive |
| Repository permissions → Issues | Read and write |
| Other repository permissions | No access, except GitHub's implicit Metadata read  |
| Organization and account permissions | No access |
| Where it can be installed | Only this account |

Create the App, then record its numeric **App ID**. The App ID is configuration,
not a secret. Do not substitute the client ID.

Install the App and choose **Only select repositories**, then select
`giacomomellone/cicala`. Record the numeric installation ID. It is the number
in the installation settings URL and is not a secret.

GitHub App permissions start empty and should stay at the minimum required for
the issue endpoint. See GitHub's
[permission guidance](https://docs.github.com/en/apps/creating-github-apps/registering-a-github-app/choosing-permissions-for-a-github-app)
and the
[create-issue requirement](https://docs.github.com/en/rest/issues/issues#create-an-issue).

## 2. Generate the App private key

On the App settings page, open **Private keys** and select **Generate a private
key**. GitHub downloads a PEM file and retains only its public half.

The Pages Function accepts GitHub's downloaded PKCS#1 PEM and PKCS#8 PEM. Keep
the complete `BEGIN … PRIVATE KEY` block intact, including line breaks. Paste
it into the Cloudflare encrypted secret in step 5. Do not paste it into a
repository secret: GitHub Actions does not need this key.

GitHub App installation tokens expire after one hour. The function creates a
short-lived token for each accepted request and does not store it. The private
key itself does not expire. Replace it after suspected exposure, when project
policy requires it, or when retiring its owner; there is no calendar rotation
schedule in this project. GitHub documents
[installation tokens](https://docs.github.com/en/apps/creating-github-apps/authenticating-with-a-github-app/generating-an-installation-access-token-for-a-github-app)
and
[private-key rotation](https://docs.github.com/en/apps/creating-github-apps/authenticating-with-a-github-app/managing-private-keys-for-github-apps).

## 3. Create the editorial labels

The direct GitHub issue form stores classification in its body. Native issues
store it in labels so the website does not ask contributors to make editorial
decisions.

Create these labels in the repository if they do not exist:

```text
question-submission
question-edit
approved
needs-changes

depth:1
depth:2
depth:3

tag:icebreaker
tag:reflective
tag:sexual
tag:dark
tag:hypothetical
tag:memory
tag:wouldyourather
```

`lang:<code>` labels are created on demand by `promote-question.yml` when an
issue opens.

For a native issue, a language maintainer adds exactly one `depth:*` label,
any applicable `tag:*` labels, and then
`approved`. Approval before classification fails closed and removes
`approved`.

## 4. Create the Turnstile widget

In Cloudflare, open **Turnstile → Add widget**.

Use:

| Setting | Value |
| --- | --- |
| Name | `cicala question suggestions` |
| Hostname | `cicala.dev` |
| Widget mode | Managed |

Record the site key and secret key. The site key is public. The secret key is
used only by the Pages Function to call Siteverify.

One widget serves both forms. The suggestion page sends action
`suggest-question` and the edit page sends `suggest-edit`; each function
requires its own action and the exact `SUBMISSION_HOSTNAME`, so a token minted
on one form is refused by the other endpoint. Actions are asserted by the
client and checked by the server, not registered in the dashboard, so adding
the second form needs no Turnstile change. Turnstile tokens are short-lived
and single-use. Client rendering alone is not a
security check; the server-side Siteverify call is mandatory. See Cloudflare's
[server-side validation guide](https://developers.cloudflare.com/turnstile/get-started/server-side-validation/).

## 5. Add Pages runtime variables and secrets

Open **Cloudflare → Workers & Pages → cicala → Settings → Variables and
Secrets**. Add these to the production environment:

| Name | Kind | Value |
| --- | --- | --- |
| `GITHUB_APP_ID` | plain text | Numeric App ID |
| `GITHUB_INSTALLATION_ID` | plain text | Numeric installation ID |
| `GITHUB_OWNER` | plain text | `giacomomellone` |
| `GITHUB_REPO` | plain text | `cicala` |
| `SUBMISSION_HOSTNAME` | plain text | `cicala.dev` |
| `TURNSTILE_SITE_KEY` | plain text | Turnstile public site key |
| `GITHUB_APP_PRIVATE_KEY` | encrypted secret | Complete private PEM |
| `TURNSTILE_SECRET` | encrypted secret | Turnstile secret key |

Do not add quotes around values in the dashboard. Preserve PEM line breaks.
Cloudflare makes encrypted secrets available through `context.env` but does
not expose their values after saving. See
[Pages bindings and secrets](https://developers.cloudflare.com/pages/functions/bindings/#secrets).

The existing `CLOUDFLARE_API_TOKEN` and `CLOUDFLARE_ACCOUNT_ID` GitHub
repository secrets are deployment credentials. They remain in GitHub Actions
and are separate from these function-runtime settings.

Do not configure the GitHub App credentials in preview unless preview
deployments are intentionally allowed to create real public issues.

## Credential lifecycle

These secrets follow the repository-wide policy in
[hosting](hosting.md#credential-lifecycle); the translation key and deployment
credentials are not exceptions.

- To replace `GITHUB_APP_PRIVATE_KEY`, generate an additional App key, update
  the encrypted Cloudflare value, redeploy and verify one readiness request,
  then delete the old App key. GitHub permits overlapping keys so this can avoid
  downtime.
- To replace `TURNSTILE_SECRET`, use **Rotate Secret Key** for the widget, update
  the encrypted Cloudflare value and redeploy during Cloudflare's two-hour
  overlap, then verify a submission challenge.
- To replace `CLOUDFLARE_API_TOKEN`, create or roll a token with the same narrow
  Pages permission, update the GitHub repository secret and verify a deployment
  before revoking any still-valid predecessor.

Rotate immediately after suspected exposure. Otherwise rotate only when an
owner or permission boundary changes, a provider expires a credential, or
project policy sets a schedule. The corresponding provider procedures are
[GitHub App private keys](https://docs.github.com/en/apps/creating-github-apps/authenticating-with-a-github-app/managing-private-keys-for-github-apps),
[Turnstile secret rotation](https://developers.cloudflare.com/turnstile/troubleshooting/rotate-secret-key/),
and [Cloudflare token rolling](https://developers.cloudflare.com/fundamentals/api/how-to/roll-token/).

## 6. Deploy the Function

The function source is `website/functions/api/suggestions.ts`. The existing
Wrangler deployment discovers the `functions/` directory when it uploads
`website/dist`.

`website/public/_routes.json` includes only `/api/*`, so normal page and asset
requests stay on the static path. Cloudflare documents
[Pages Functions deployment](https://developers.cloudflare.com/pages/functions/get-started/)
and
[invocation routes](https://developers.cloudflare.com/pages/functions/routing/).

Redeploy after adding or changing runtime variables. A push to `main` runs the
normal `site` workflow; the Cloudflare deployment step must not be skipped.

## 7. Verify without opening an issue

Check configuration readiness:

```sh
curl -sS https://cicala.dev/api/suggestions
curl -sS https://cicala.dev/api/edits
```

Expected shape, with `turnstileAction` reading `suggest-question` and
`suggest-edit` respectively:

```json
{
  "available": true,
  "turnstileRequired": true,
  "turnstileSiteKey": "0x…",
  "turnstileAction": "suggest-question"
}
```

The site key is deliberately public. A private key or Turnstile secret in this
response is a security incident.

Open `https://cicala.dev/suggest` and verify:

1. the page does not say submissions are unavailable;
2. invalid and duplicate questions remain disabled;
3. Turnstile completes without an unnecessary visible challenge;
4. a deliberate test submission creates one issue authored by the App bot;
5. the issue has `question-submission` and later `lang:<code>`;
6. the check workflow comments with the native text-check result;
7. adding deck and depth labels followed by `approved` opens a valid pull request.

Then open a question permalink, select **suggest an edit**, and verify:

8. the current wording appears and an unknown `?q=` value is refused;
9. the consent boxes appear only once wording is proposed;
10. a deliberate test edit creates one `question-edit` issue authored by the
    App bot, whose body carries the same headings as the GitHub issue form.

Close the test issues or pull request without merging their fixture content.

Events created with a GitHub App installation token can trigger the repository
workflow. GitHub suppresses recursive events created with a workflow's own
`GITHUB_TOKEN`, which is a different token and does not apply to the Pages
Function. See [triggering workflows](https://docs.github.com/en/actions/how-tos/write-workflows/choose-when-workflows-run/trigger-a-workflow).

## Local and automated checks

Unit and browser tests mock Turnstile and GitHub; they do not need credentials
and never open an issue:

```sh
just test-tools
just test-website
just test-e2e e2e/suggest.spec.ts
```

For a deliberate local Pages Function test, build the site and use Wrangler:

```sh
just website-build
cd website
npx wrangler pages dev dist
```

Put local runtime values in `website/.dev.vars`, which is ignored by Git. Use
Cloudflare's published Turnstile test keys until the request reaches the final
GitHub call. Do not put the production GitHub App key in a routine development
environment.

## Failure behavior

`GET /api/suggestions` reports `available: false` when any required runtime
setting is absent. The page keeps the draft visible and disables submission.
The POST endpoint also fails closed.

The endpoint rejects an incorrect origin, non-JSON and oversized bodies,
invalid question data, stale consent versions, unsupported languages and
failed Turnstile checks before asking GitHub for a token. GitHub errors return
a generic `502` to the browser and do not expose an API response or credential.

The submitted issue is public because the accepted question database is
public. The contributor's account is not exposed; only an optional chosen
credit is written. The endpoint does not collect an email address or create a
user profile.

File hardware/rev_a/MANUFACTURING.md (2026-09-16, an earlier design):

# Rev A prototype manufacturing handoff

Prepare four assembled prototypes. If the fabrication service requires five
bare PCBs, assemble four and retain the fifth as a spare. These are engineering
prototypes; no hardware bench test or printed fit test has yet been completed.
No order has been placed and no files have been uploaded to a supplier.

## PCB and assembly settings

| Setting | Requirement |
| --- | --- |
| Finished board | 78 × 49 mm, routed outline, 1.2 mm nominal FR-4 |
| Layers | F.Cu signals; In1.Cu ground; In2.Cu 3V3/signals/local USB ground; B.Cu signals |
| Stack | JLC04121H-7628, outer 1 oz, inner 0.5 oz |
| Published dielectric | 0.2104 mm 7628 prepreg each side; 0.6 mm core |
| Finish | ENIG; lead-free assembly; black mask, white legend |
| Via process | Ordinary plated through vias, minimum drill 0.20 mm; preserve supplied masks and thermal-hole treatment below |
| Assembly | Standard PCBA, both sides; exclude all DNP/bare-contact features |
| USB | 90 Ω differential target; main F.Cu pair 0.32 mm wide, 0.26 mm gap |
| Inspection | AOI; X-ray the BQ25185 bottom-terminated joints and inspect U3's PGND/paste lands |

The layer construction comes from JLCPCB's
[published stackup selector](https://jlcpcb.com/impedance), queried for 4 layers,
1.2 mm, 1 oz outer and 0.5 oz inner on 7 September 2026. Its dielectric figures
are a process construction; finished thickness follows the ordered nominal
thickness and factory tolerance. The enclosure uses a 1.2 mm nominal PCB.

The USB width/gap has been adjusted to this stack. A first-order uncoated
microstrip estimate is about 90 Ω; solder mask and etched conductor shape
require the fabricator's impedance calculation. Specify the 90 Ω target and
have CAM confirm the geometry before approving fabrication. Short connector,
ESD and module escapes retain their fine-pitch geometry. Never change the
layer order or route across In1 ground gaps.

The 474 separately routed vias are tented on both faces. U1 has twelve and
U2 has two intentional Ø0.20 mm thermal holes within their exposed-pad lands.
Those holes are tented on F.Mask and open into the component-side land on
B.Mask. Preserve that mask treatment and review the exposed-pad stencil/joints;
do not convert them to mask openings on both faces. No filled/capped via
process is specified. Include U1/U2 exposed-pad solder quality in inspection.

The board is below the 70 × 70 mm minimum for JLCPCB Standard assembly.
Use **Panel by JLCPCB / edge rails**, with a routed carrier at least 88 × 75 mm.
Have the factory add tooling holes and fiducials on the removable rails.
Keep USB/JST overhang and the left antenna region free. Locate breakaway tabs
away from connector mouths and mounting-hole bearing surfaces; depanelize and
finish tabs flush to the supplied board outline. Do not enlarge the finished
PCB or add holes to it. The factory's panel drawing is part of order review.
See the [assembly service](https://cart.jlcpcb.com/quote/?fromDemo=yes) and
[panelization rules](https://jlcpcb.com/help/article/pcb-panelization).

## Files to provide

Paths below are relative to `hardware/rev_a/pcb/exports/`.

| File | JLCPCB input |
| --- | --- |
| `cicala_rev_a_gerbers.zip` | PCB fabrication upload |
| `assembly/cicala_rev_a_jlc_bom.csv` | Assembly BOM |
| `assembly/cicala_rev_a_jlc_cpl.csv` | Assembly CPL / pick-and-place |
| `assembly/assembly_top.pdf` | Top placement/reference drawing |
| `assembly/assembly_bottom.pdf` | Mirrored bottom placement/reference drawing |
| `review/schematic.pdf` | Circuit reference for assembly review |
| `cicala_rev_a_board.step` | Optional mechanical reference |

The Gerber ZIP includes four copper layers, masks, legends, paste, outline
and separate PTH/NPTH drills. `cicala_rev_a_ipc2581.zip` is an alternative
structured exchange. Unpack the dated prototype handoff first and upload its
inner Gerber ZIP to the fabrication field.

The KiCad and JLCPCB position files use the same drill/placement origin.
Bottom placements remain explicitly marked bottom. Check the supplier's
placement overlay against the mirrored bottom assembly drawing, especially
U1, U2/U3, U7, Q1/Q2, D1–D4 and all three connectors. Confirm each exact MPN;
an LCSC identifier is a lookup aid, not permission for an alternate.
Supplier stock and sourcing acceptance are checked at order preparation.

The display, battery, NTC harness, case and optical/mechanical parts are fitted
after PCBA. Do not send the LiPo or display glass through reflow. Keep the
battery disconnected during inspection and first USB power-up. The complete
prototype assembly and acceptance procedure is in [REVIEW.md](REVIEW.md).

## Submit the prototype order

1. Check `review/verification.json` and the source/checksum record. If the
   design changed, repeat `just hw-review`, `just hw-fab-export` and the
   fabrication read-back before using a dated archive.
2. Start a PCB quote and upload `cicala_rev_a_gerbers.zip`. Confirm the preview
   shows one 78 × 49 mm board, four copper layers and the routed corners. Set
   1.2 mm, ENIG and the construction above. The desired delivery is **four
   individual assembled boards**, with one bare spare if the minimum lot is
   five; panel quantity and finished-board quantity are different fields.
3. Enable Standard assembly on **both sides**. Request the removable routed
   carrier described above, tooling and fiducials on its rails, and return of
   depanelized boards. Have CAM confirm the stack, USB impedance and carrier
   drawing before fabrication. Keep the supplied finished outline unchanged.
4. Upload the two `_jlc_` CSV files to the BOM and CPL fields and process them.
   The BOM columns are `Comment`, `Designator`, `Footprint`, `LCSC Part #`,
   `Manufacturer`, `MPN`, `Quantity`; CPL uses `Designator`, `Mid X`, `Mid Y`,
   `Rotation`, `Layer`. Coordinates are millimetres. These headers follow
   [JLCPCB's KiCad assembly guide](https://jlcpcb.com/help/article/how-to-generate-the-bom-and-centroid-file-from-kicad).
5. Review every matched part against its **exact MPN**. Blank LCSC fields
   require exact-part selection or the service's sourcing/consignment process.
   Do not accept a similar-looking capacitor or switch automatically. SW1/SW2
   are gold-contact **KSC323GLFG** (current Littelfuse orderable alias
   **Y31B13117FPLFG**); the silver version has a different minimum switching
   current. R21/R22 must be 22 kΩ. Confirm connector shell/hold-down soldering
   and the selected mixed SMT/through-hole tabs are included in the quote.
6. Check **89 fitted designators per board** in both BOM and CPL, including
   top-side SW1/SW2 and the display circuit. C1/C2/C31 are DNP. J4, test pads
   and mounting holes are bare features. Inspect the supplier placement preview
   against both PDFs: position, side, pin 1, polarity and connector opening.
   Any supplier rotation correction must be tied to its exact library part.
7. Attach the assembly PDFs and the fabrication note below. Review the final
   CAM image, sourced BOM and assembly overlay before payment/release. Retain
   those files with the order so they can be checked against the arriving boards.

Fabrication note to copy into the order:

```text
Cicala Rev A engineering prototypes; four assembled individual boards.
Finished outline 78 x 49 mm; nominal thickness 1.2 mm; 4 layers.
Stack JLC04121H-7628: outer 1 oz / inner 0.5 oz, ENIG.
F.Cu / In1.Cu GND / In2.Cu / B.Cu. Confirm USB 90-ohm differential.
Main USB F.Cu width/gap 0.32/0.26 mm; confirm with the selected stack.
Double-sided Standard assembly, exact MPNs, 89 fitted parts per board.
C1/C2/C31 DNP; J4/test contacts/mounting holes unpopulated.
Factory routed carrier at least 88 x 75 mm, rail tooling/fiducials.
Submit the carrier drawing and placement overlay before fabrication.
Keep connector overhangs and X=3..9.5 mm antenna strip clear.
Depanelize and finish tabs flush; preserve the finished board outline.
Inspect fine-pitch/polarized parts and USB/JST hold-down solder joints.
X-ray U2; inspect U3 asymmetric PGND and its two paste apertures.
Preserve thermal-hole masks: U1 (12) and U2 (2), tented on F.Mask.
Battery, NTC harness, display glass and enclosure are fitted after PCBA.
```

## After delivery

Complete the electrical acceptance sequence in [REVIEW.md](REVIEW.md), then
follow [Rev A build and flash](../../docs/firmware_rev_a.md). The case print,
button-stop adjustment, display/harness assembly and German/European printing
options are in [case/README.md](../case/README.md). Keep the first assembly
accessible until USB recovery, JTAG, display, buttons and charging pass.

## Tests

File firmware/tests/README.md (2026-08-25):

# Firmware tests

Twister runs the ztest suites:

```sh
just fw-test             # all suites under qemu
just fw-test input       # one suite
just fw-test-linux       # native_sim in the Zephyr CI container
```

`qemu_xtensa/dc233c` is the default because it runs on macOS and matches the
target architecture. `native_sim` is faster but requires Linux. Both platforms
can emulate GPIO through a `zephyr,gpio-emul` devicetree node.

| Suite | Covers |
|---|---|
| `smoke` | harness startup |
| `fsm` | generic transition and timeout rules |
| `input` | Category, Next, and debounce |
| `app_fsm` | tabletop states and refresh handling |
| `qdb` | bundle parsing, deck filters, and no-repeat draws |
| `layout` | UTF-8, accents, wrapping, and the shipped corpus |
| `panel` | refresh policy and framebuffer output |
| `power` | voltage thresholds, hysteresis, and charge window |
| `status` | LED priority and timing |
| `portal` | setup states, DNS, forms, and pages |
| `sync` | manifest parsing and version comparison |
| `retained` | RTC block validation |
| `integration` | emulated GPIO through real application channels and panel code |
| `soak` | repeated automatic draws and refresh policy |

A suite that needs the application's `CONFIG_CICALA_*` values adds a `Kconfig`
containing `rsource "../../Kconfig.policy"`, the same file `app/Kconfig` pulls
in. Bundle and layout suites use QDB3 fixtures generated from the real question
database by `just fw-test`; the fixture files are gitignored.

Timing, electrical behavior, and the e-paper glass require the breadboard. See
the [hardware checks](../README.md#hardware-checks).

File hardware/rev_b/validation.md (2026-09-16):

# Rev B engineering validation

Validated locally on 16 September 2026 with KiCad 10.0.5, OpenSCAD 2026.06.12,
CadQuery 2.8.0, Shapely 2.1.2 and Gerbonara 1.6.3. This record covers the digital
engineering prototype. No integrated Rev B device has been built or powered.

## Results

- Native schematic ERC: zero violations. Schematic/PCB netlist parity matches.
- Filled-board DRC: **zero violations and zero unconnected items**. No DRC exclusions were added to clear the routing.
- Native front/back silkscreen includes Cicala branding, functional brackets, all 20 probe signals, connector polarity and a recovery/power guide. Text is at least 0.8 mm with 0.15 mm strokes and silk clearance. Pin labels match native nets; front text clears the fitted component envelopes. The right arm and switch footprints now follow the B3F-4050 drilling diagram; unrelated circuitry and the USB pair are retained.
- 115 footprints; 89 fitted electronic components: 87 SMT parts and two through-hole switches installed from above and soldered below. Bare diagnostic contacts also use the underside. The L-shaped board has 4360.22 mm² area.
- USB geometric D+ and D− paths are both approximately 71.806 mm, including board-layer transitions and excluding package interiors. Their computed difference is below 0.001 mm. Every checked outer data-trace centreline has adjacent ground, outside the defined 0.55 mm launch allowance around USB vias. Factory impedance confirmation and USB testing remain required.
- The selected 103JT thermistor table passes the static charge-veto tolerance model: nominal permission window 4.44–37.05 °C, positive stop margins at 0 and 45 °C. Actual cell temperature and bonded-sensor lag require measurement.
- CAD exports use KiCad STEP handedness, verified against the asymmetric PCB outline and four mounting holes. Filters is upper right; the larger Next is lower right. The 16.8 mm roof is nominally 1 mm above both cap faces.
- Next has a direct 45° approach without the backtracking hook. Collinear run consolidation removes 179 redundant vertices; ten off-center via approaches and two obsolete switch-ground tails are corrected. The native via-centering rule is enabled. Native DRC and connectivity are rechecked after refill. All four copper layers were visually reviewed; USB path/reference checks and the power/boost placement remain in the electrical review.
- 87 STEP component envelopes plus two explicit switch models. Placement/model, courtyard, mounting, concave outline, RF reserve and copper-to-edge checks pass.
- Purchased B32-1200/B32-1320 caps have 9 × 9 / 12 × 12 mm flat faces and direct B3F-4050 plunger seating. All 37 mechanical poses pass, covering assembly insertion, 0–0.5 mm travel, lateral alignment, switch leads, electronics, glass/flex and carrier clearances.
- The declared worst-case screen leaves 0.125 mm radial aperture clearance, 0.07 mm released-cap recess and 2.43 mm maximum pressed recess. The R6 access probe clears the flared mouth by at least 1.278 mm. The 2.60 mm solder-projection limit leaves 0.40 mm base clearance; untrimmed leads have only 0.17 mm modeled worst-case clearance. These are modeled margins; physical cap seating, solder fillets, force and return remain unmeasured.
- Export contains 14 native STL/3MF pairs: eight printed parts and six purchased-part references. Eight additional pairs are oriented for printing. Printed parts are closed, oriented single solids; the switch reference intentionally has a body and four separate terminal solids. Both cap reference meshes pass their flat-face area checks.
- Fabrication readback confirms the expected 11 graphic layers, including all four copper layers and the outline. It matches every drilled hole and slot to native geometry within 0.00051 mm. Full native BOM/positions cover 89 electronic references. JLC BOM/CPL cover the same 87 SMT references; the manual assembly CSV lists both switches and both caps. Gerber ZIP, Excellon files, assembly drawings, schematic PDF, IPC-2581 and STEP are packaged with source/output hashes.
- 29 Rev B helper tests and the required product-tool/website tests pass. The public website build and strict documentation build pass.
- The device page passes nine viewport/language combinations, with all eight CAD images loaded, both full-resolution PCB PNG links and both silkscreen SVG links checked. PCB views are straight orthographic exports with matching scale.
- Rev A still passes its enclosure, ERC, filled-board DRC, schematic parity and STEP-export checks after the folder reorganization.

The detailed electrical and fabrication reports are in `pcb/exports/review/`.
`pcb/exports/manifest.json` and `case/exports/manifest.json` identify the checked
sources and output hashes. The ZIP checksum is beside the prototype package.

## First-article qualification

The flex entry height and R1.55 bend remain assembly assumptions. The calculated
0.276 mm tail-length remainder does not establish fold durability. Check the
actual panel revision, insertion and latch access, battery pulse limits, NTC
bonding, USB operation, panel rails/refresh and radio behavior. The UC8253 firmware
port is still required before display bring-up.

Printed fits, component/PCB tolerances, lens supports, screw engagement, cap
travel/force/wear and battery clearance need physical checks. The magnetic
carrier is a made-to-drawing accessory concept that fails the prior iPhone 16 Plus dimensional fit;
retention, optical clearance, cases and attached RF are unqualified. Factory CAM
must confirm the stack, impedance, stencil and supported tab panel before the
prototype order. These are remaining physical/order checks, not missing digital
routing. No manufacturing order has been placed.

The purchased controls and soldering sequence are detailed in the [assembly guide](../../docs/hardware_rev_b.md#buttons-and-print-preparation). No custom printed caps, silicone strips, keepers or keeper screws are installed or exported as print jobs.

See [fabrication notes](pcb/fabrication_notes.md) for the prototype order settings and explicit CAM/assembly acceptance conditions. This record does not certify a production-ready device.

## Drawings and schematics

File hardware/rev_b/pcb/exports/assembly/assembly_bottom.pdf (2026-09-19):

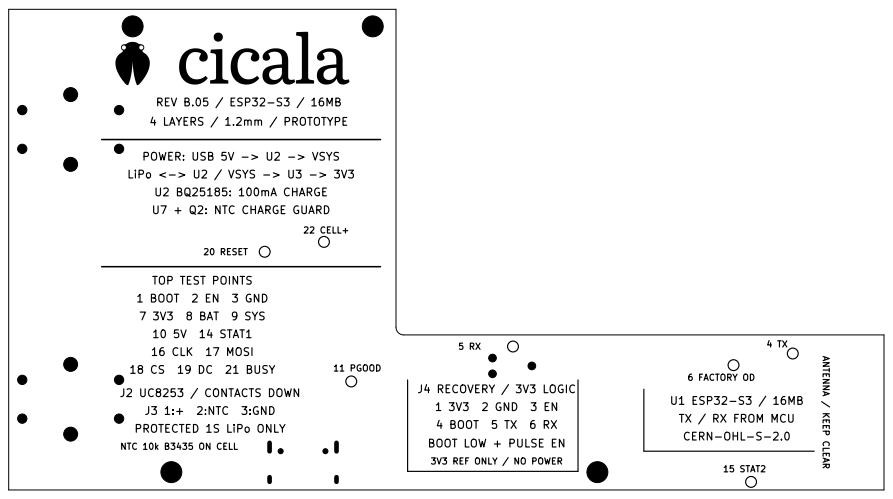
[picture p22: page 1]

J4 RECOVERY / 3V3 LOGIC
1 3V3 2 GND 3 EN
4 BOOT 5 TX 6 RX
BOOT LOW + PULSE EN

U1 ESP32-S3 / 16MB
TX / RX FROM MCU

3V3 REF ONLY / NO POWER

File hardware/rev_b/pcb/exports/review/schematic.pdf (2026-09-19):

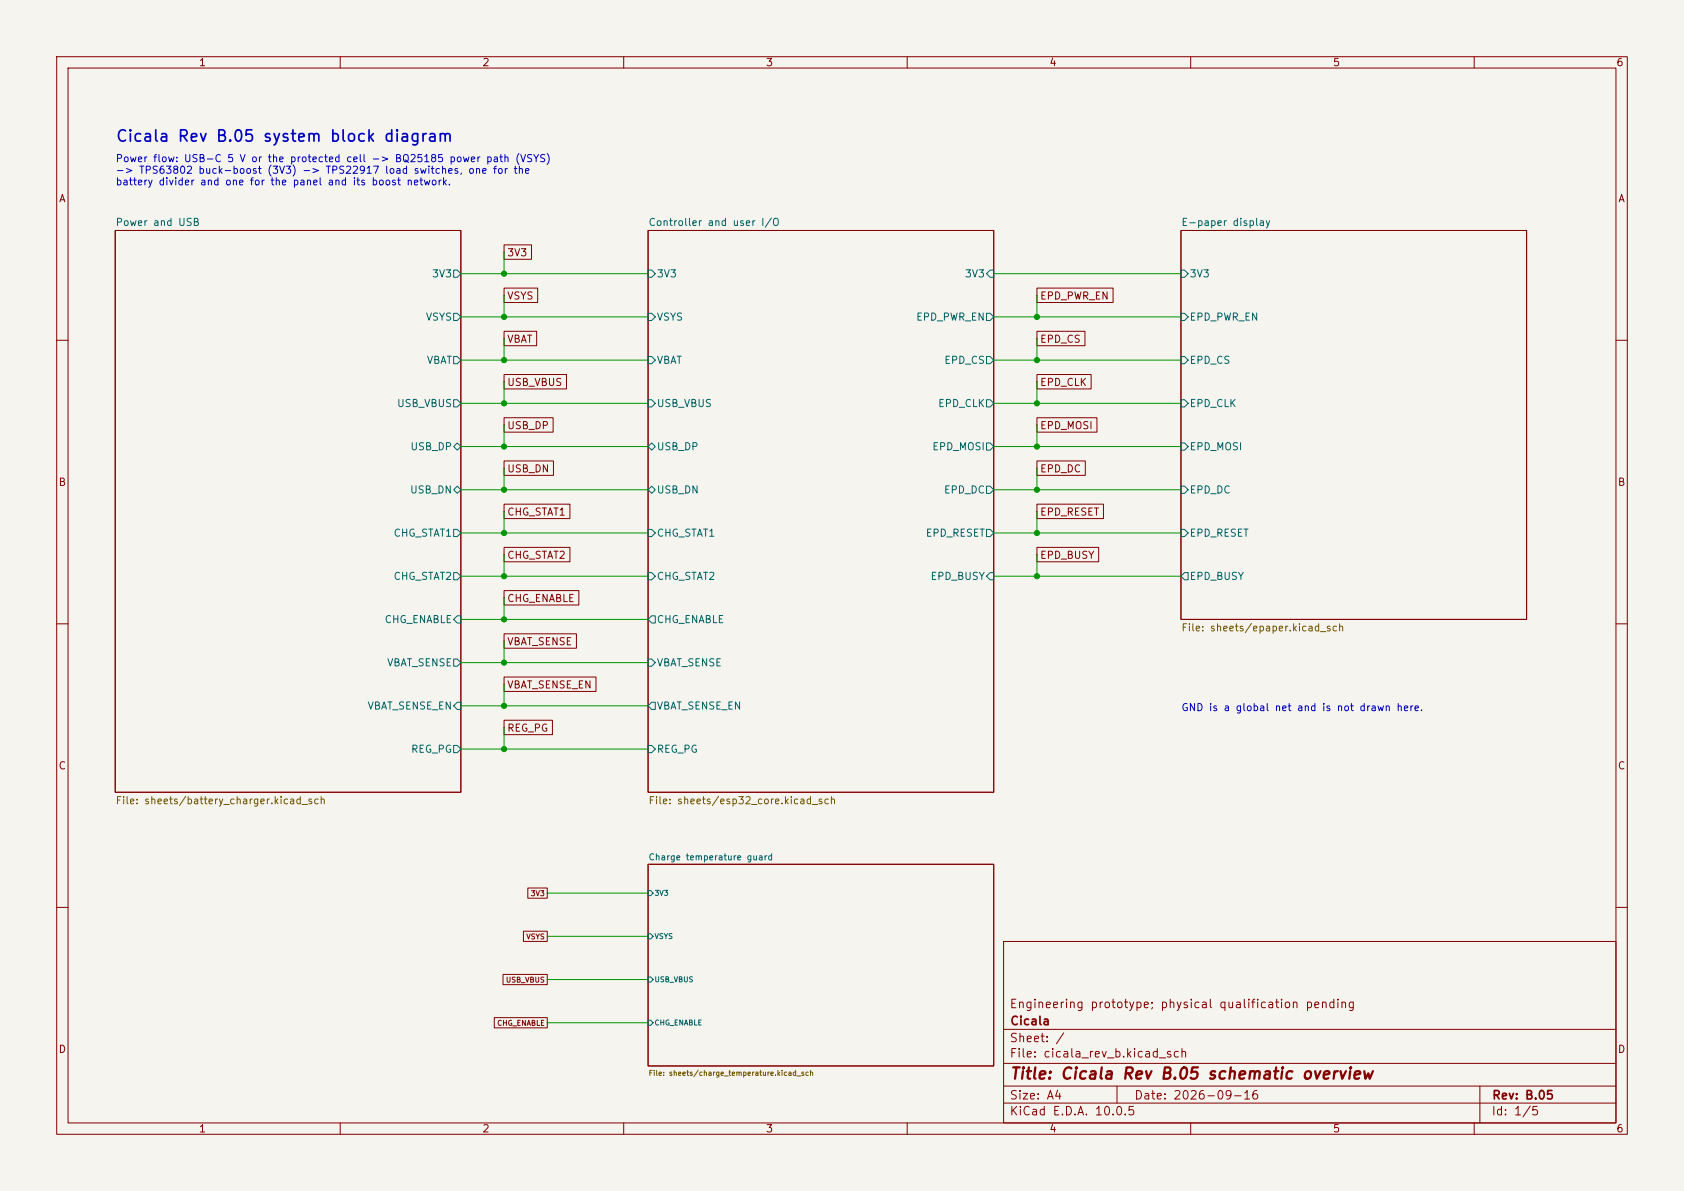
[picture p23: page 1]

Power flow: USB-C 5 V or the protected cell -> BQ25185 power path (VSYS) -> TPS63802 buck-boost (3V3) -> TPS22917 load switches, one for the battery divider and one for the panel and its boost network.

EPD_RESET EPD_BUSY E-paper display File: sheets/epaper.kicad_sch
EPD_MOSI EPD_PWR_EN

VSYS USB_VBUS CHG_ENABLE Charge temperature guard

Engineering prototype; physical qualification pending
Cicala
Sheet: /
File: cicala_rev_b.kicad_sch
Title: Cicala Rev B.05 schematic overview

Size: A4 | Rev: B.05
KiCad E.D.A. 10.0.5 | Id: 1/5

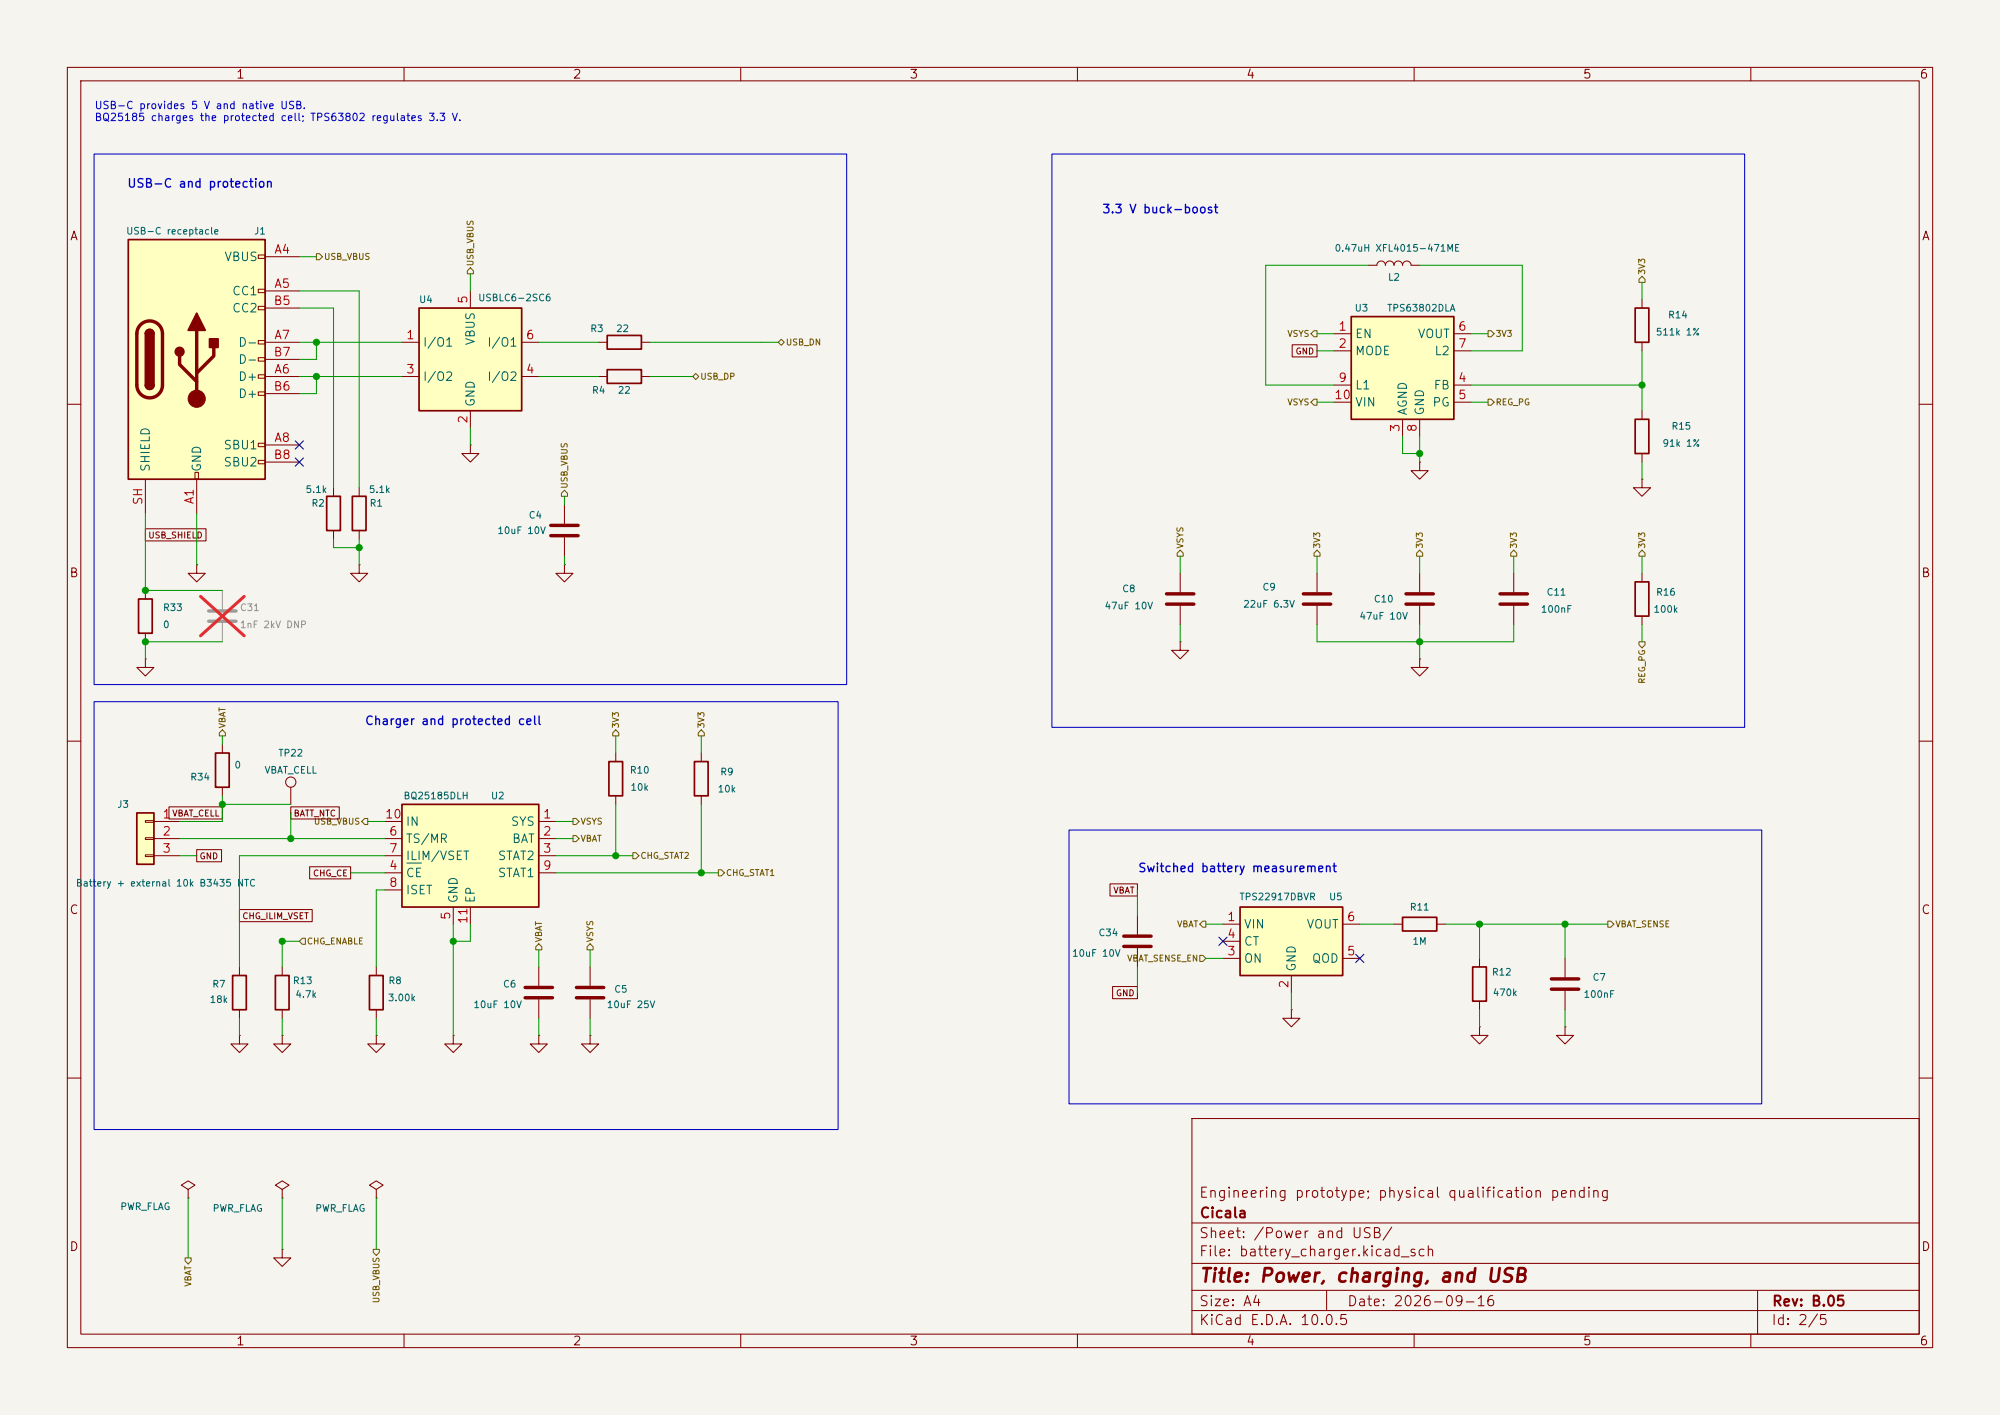
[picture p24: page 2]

VBAT GND Charger and protected cell

Engineering prototype; physical qualification pending
Cicala
Sheet: /Power and USB/
File: battery_charger.kicad_sch
Title: Power, charging, and USB

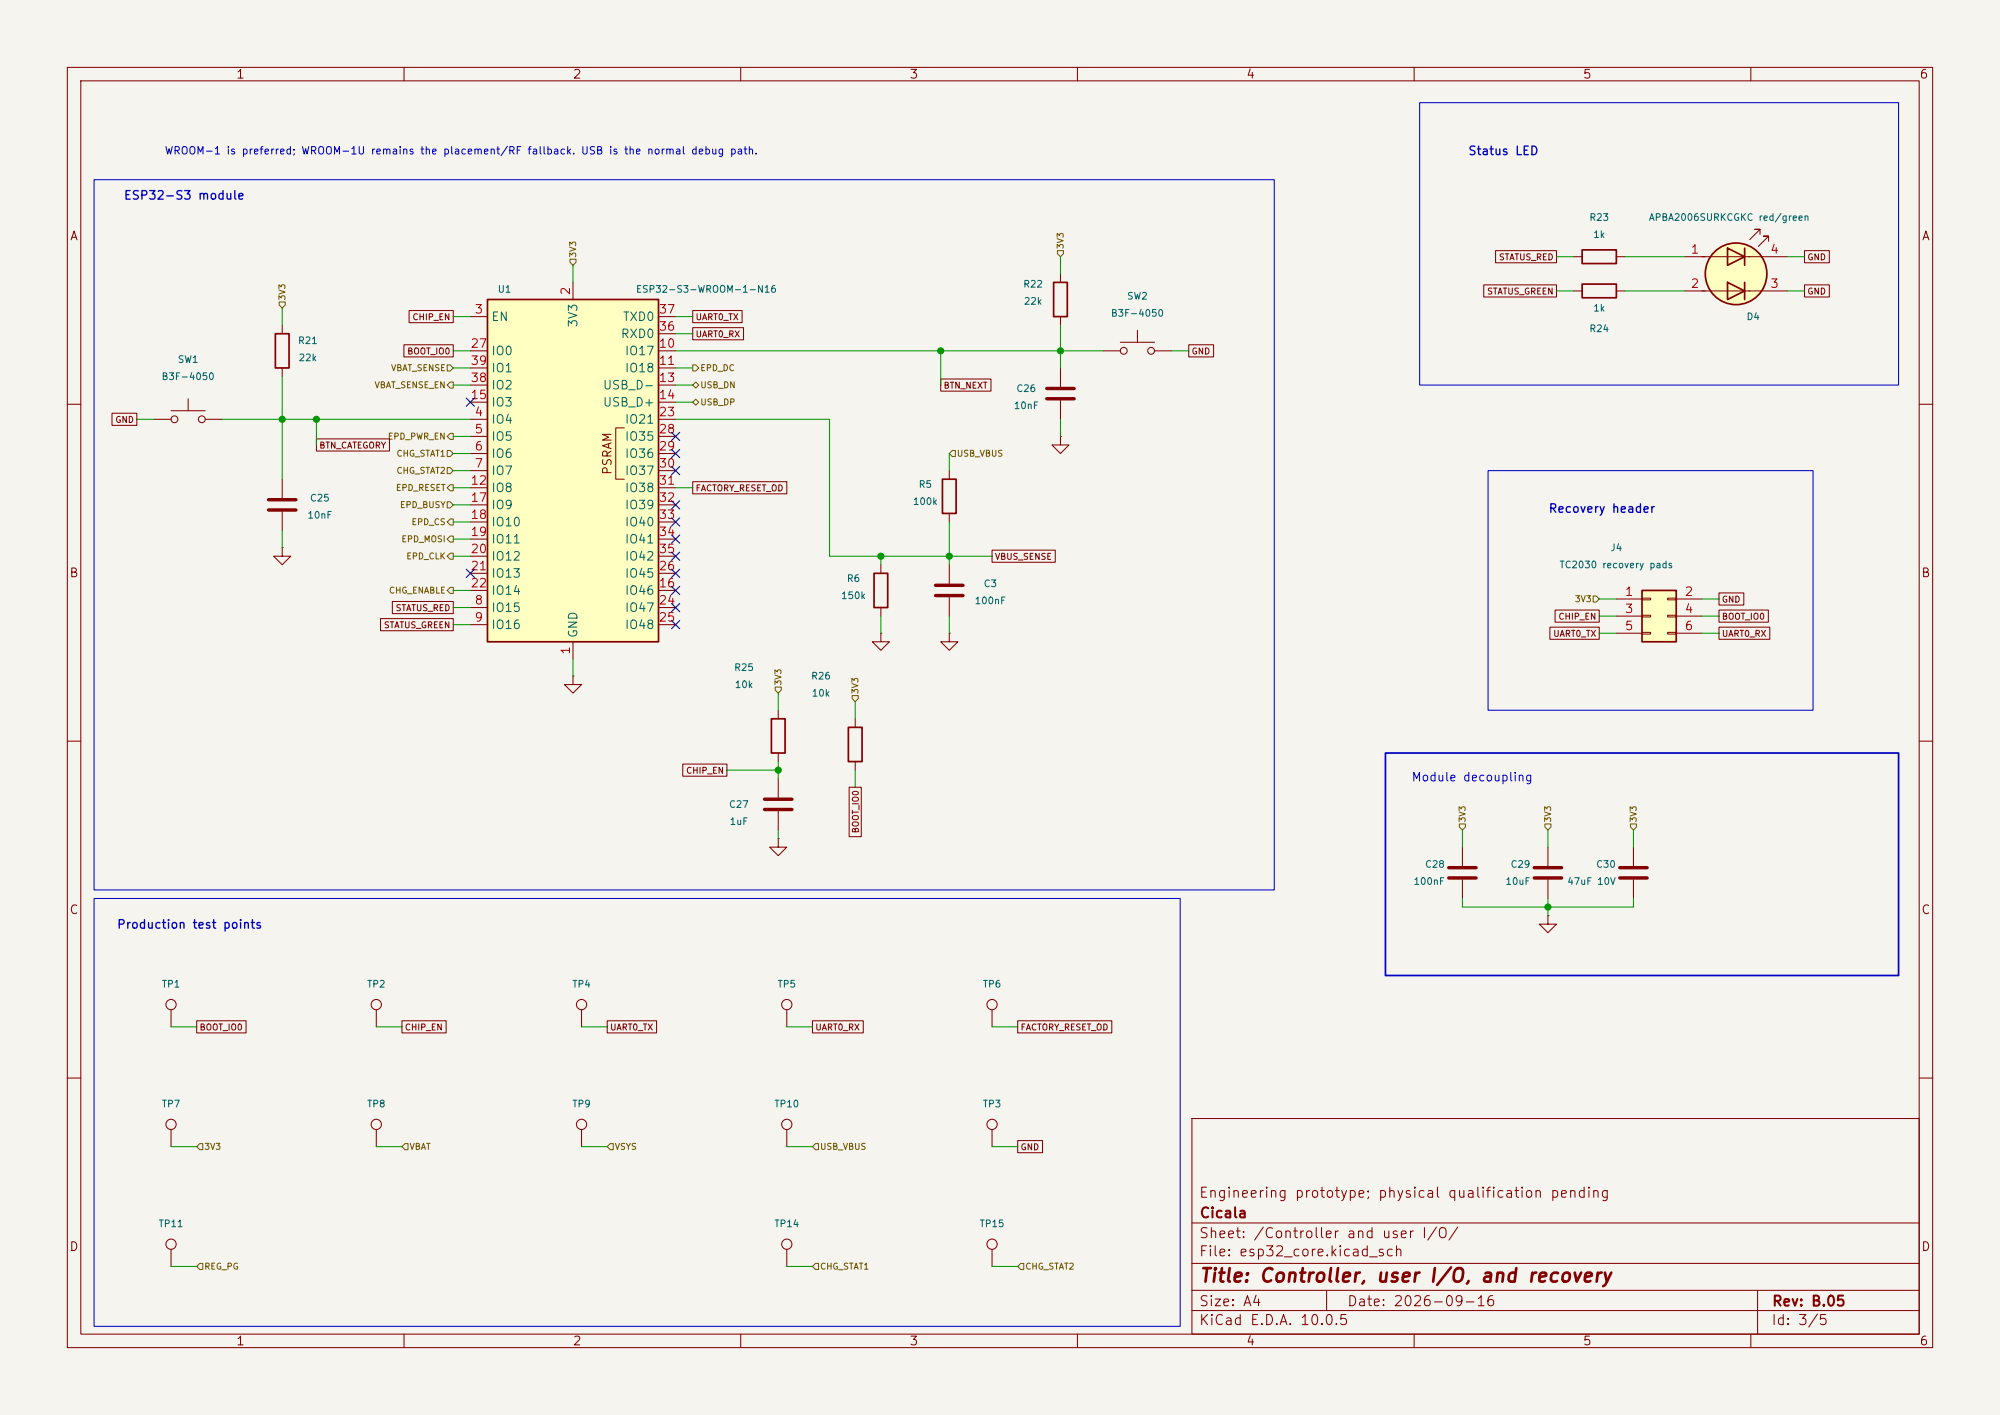
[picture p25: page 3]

Engineering prototype; physical qualification pending
Cicala
Sheet: /Controller and user I/O/
File: esp32_core.kicad_sch
Title: Controller, user I/O, and recovery

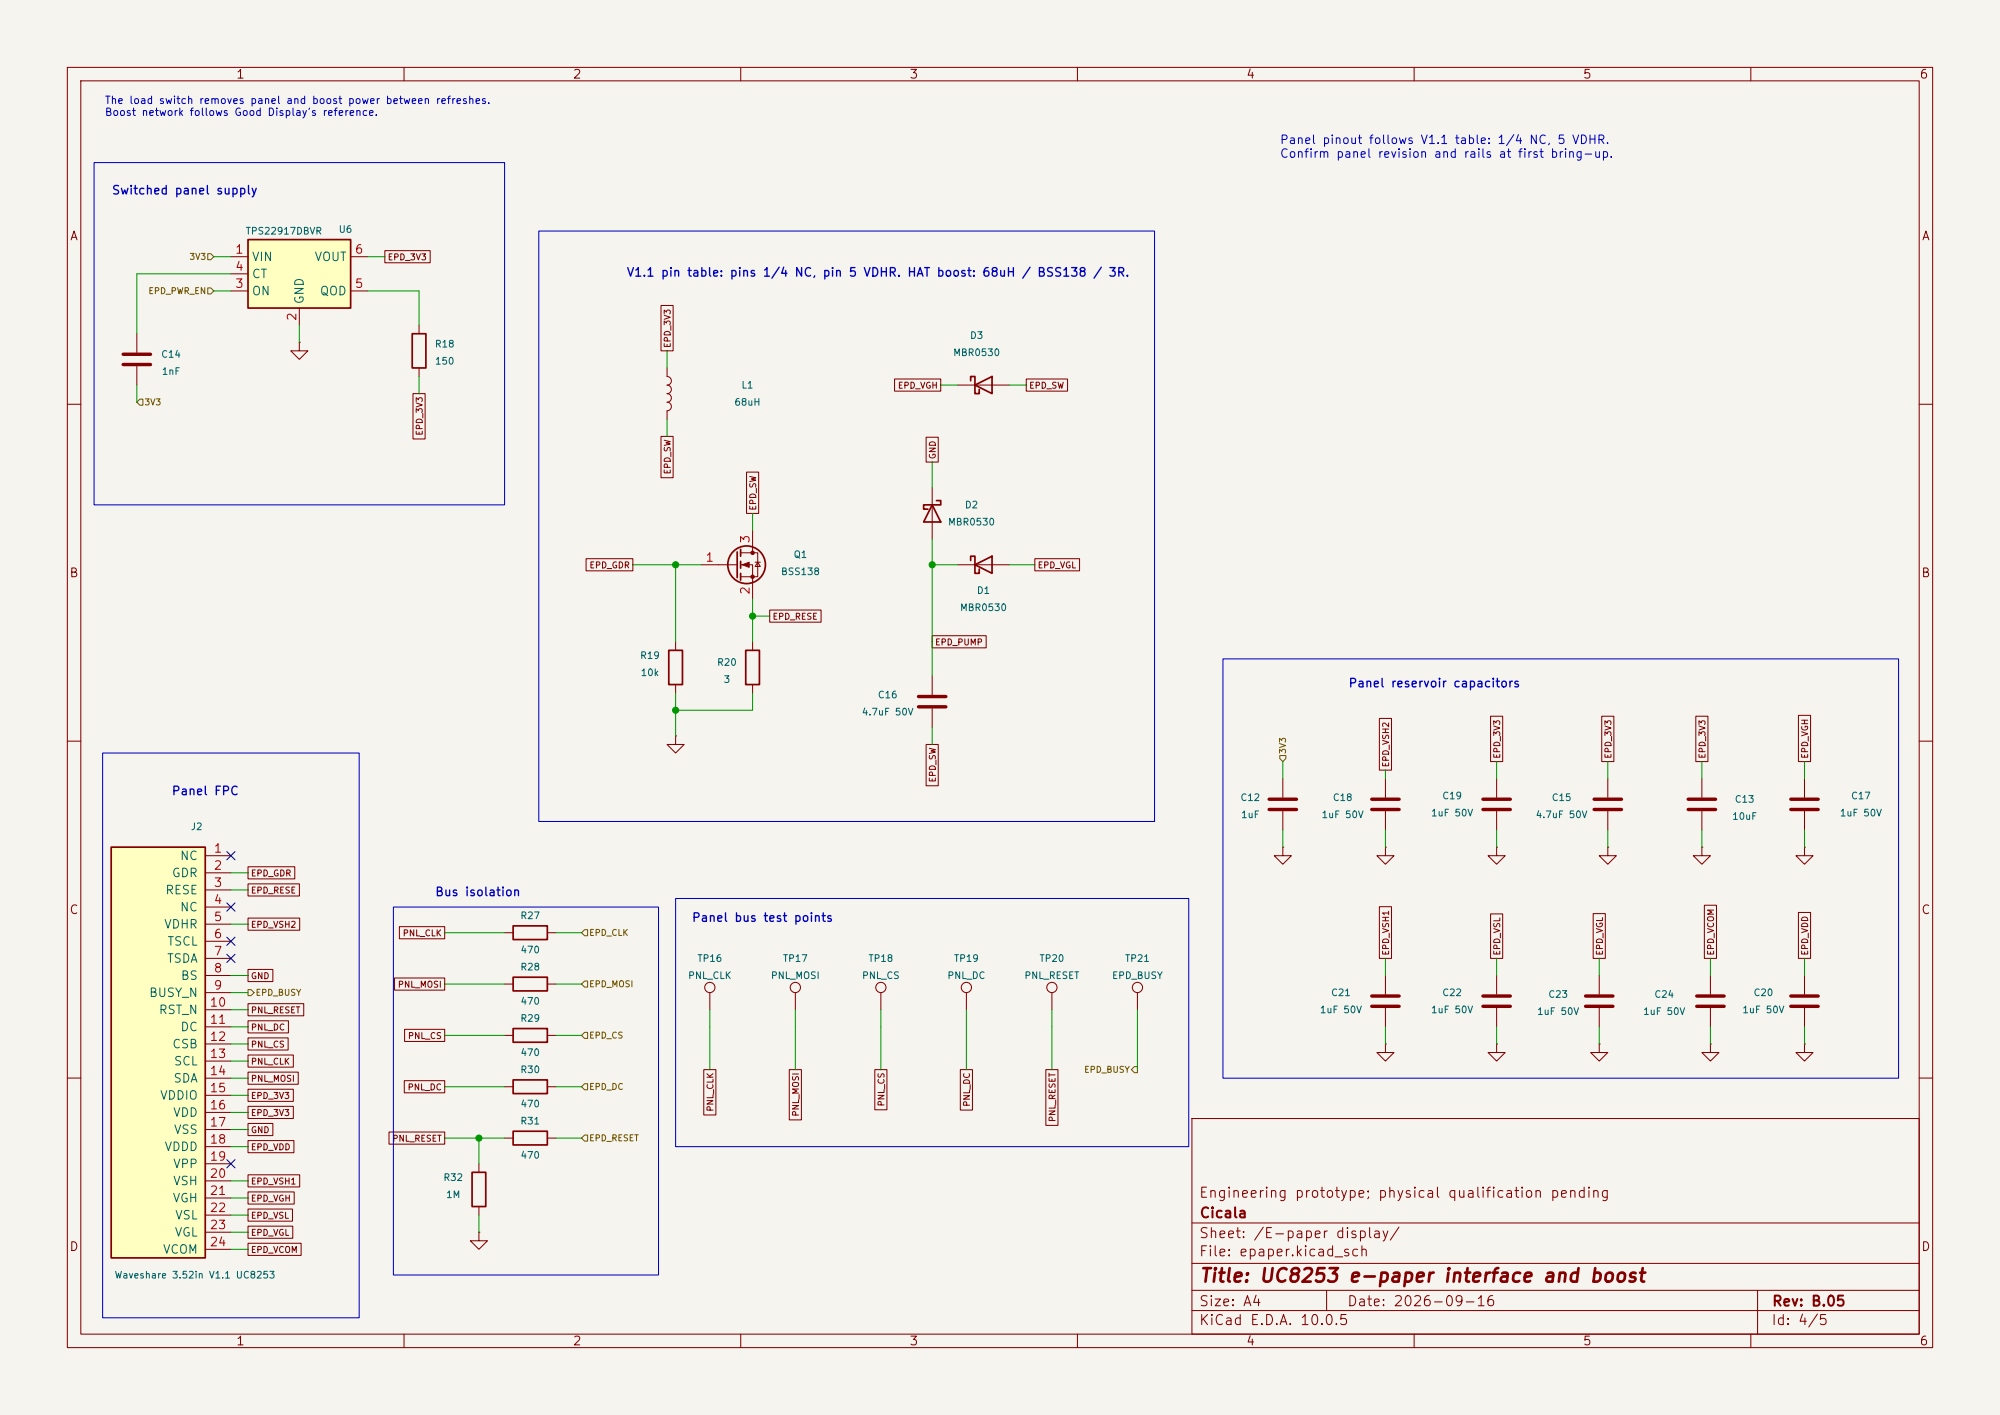
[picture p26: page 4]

Panel bus test points

Engineering prototype; physical qualification pending
Cicala
Sheet: /E-paper display/
File: epaper.kicad_sch
Title: UC8253 e-paper interface and boost

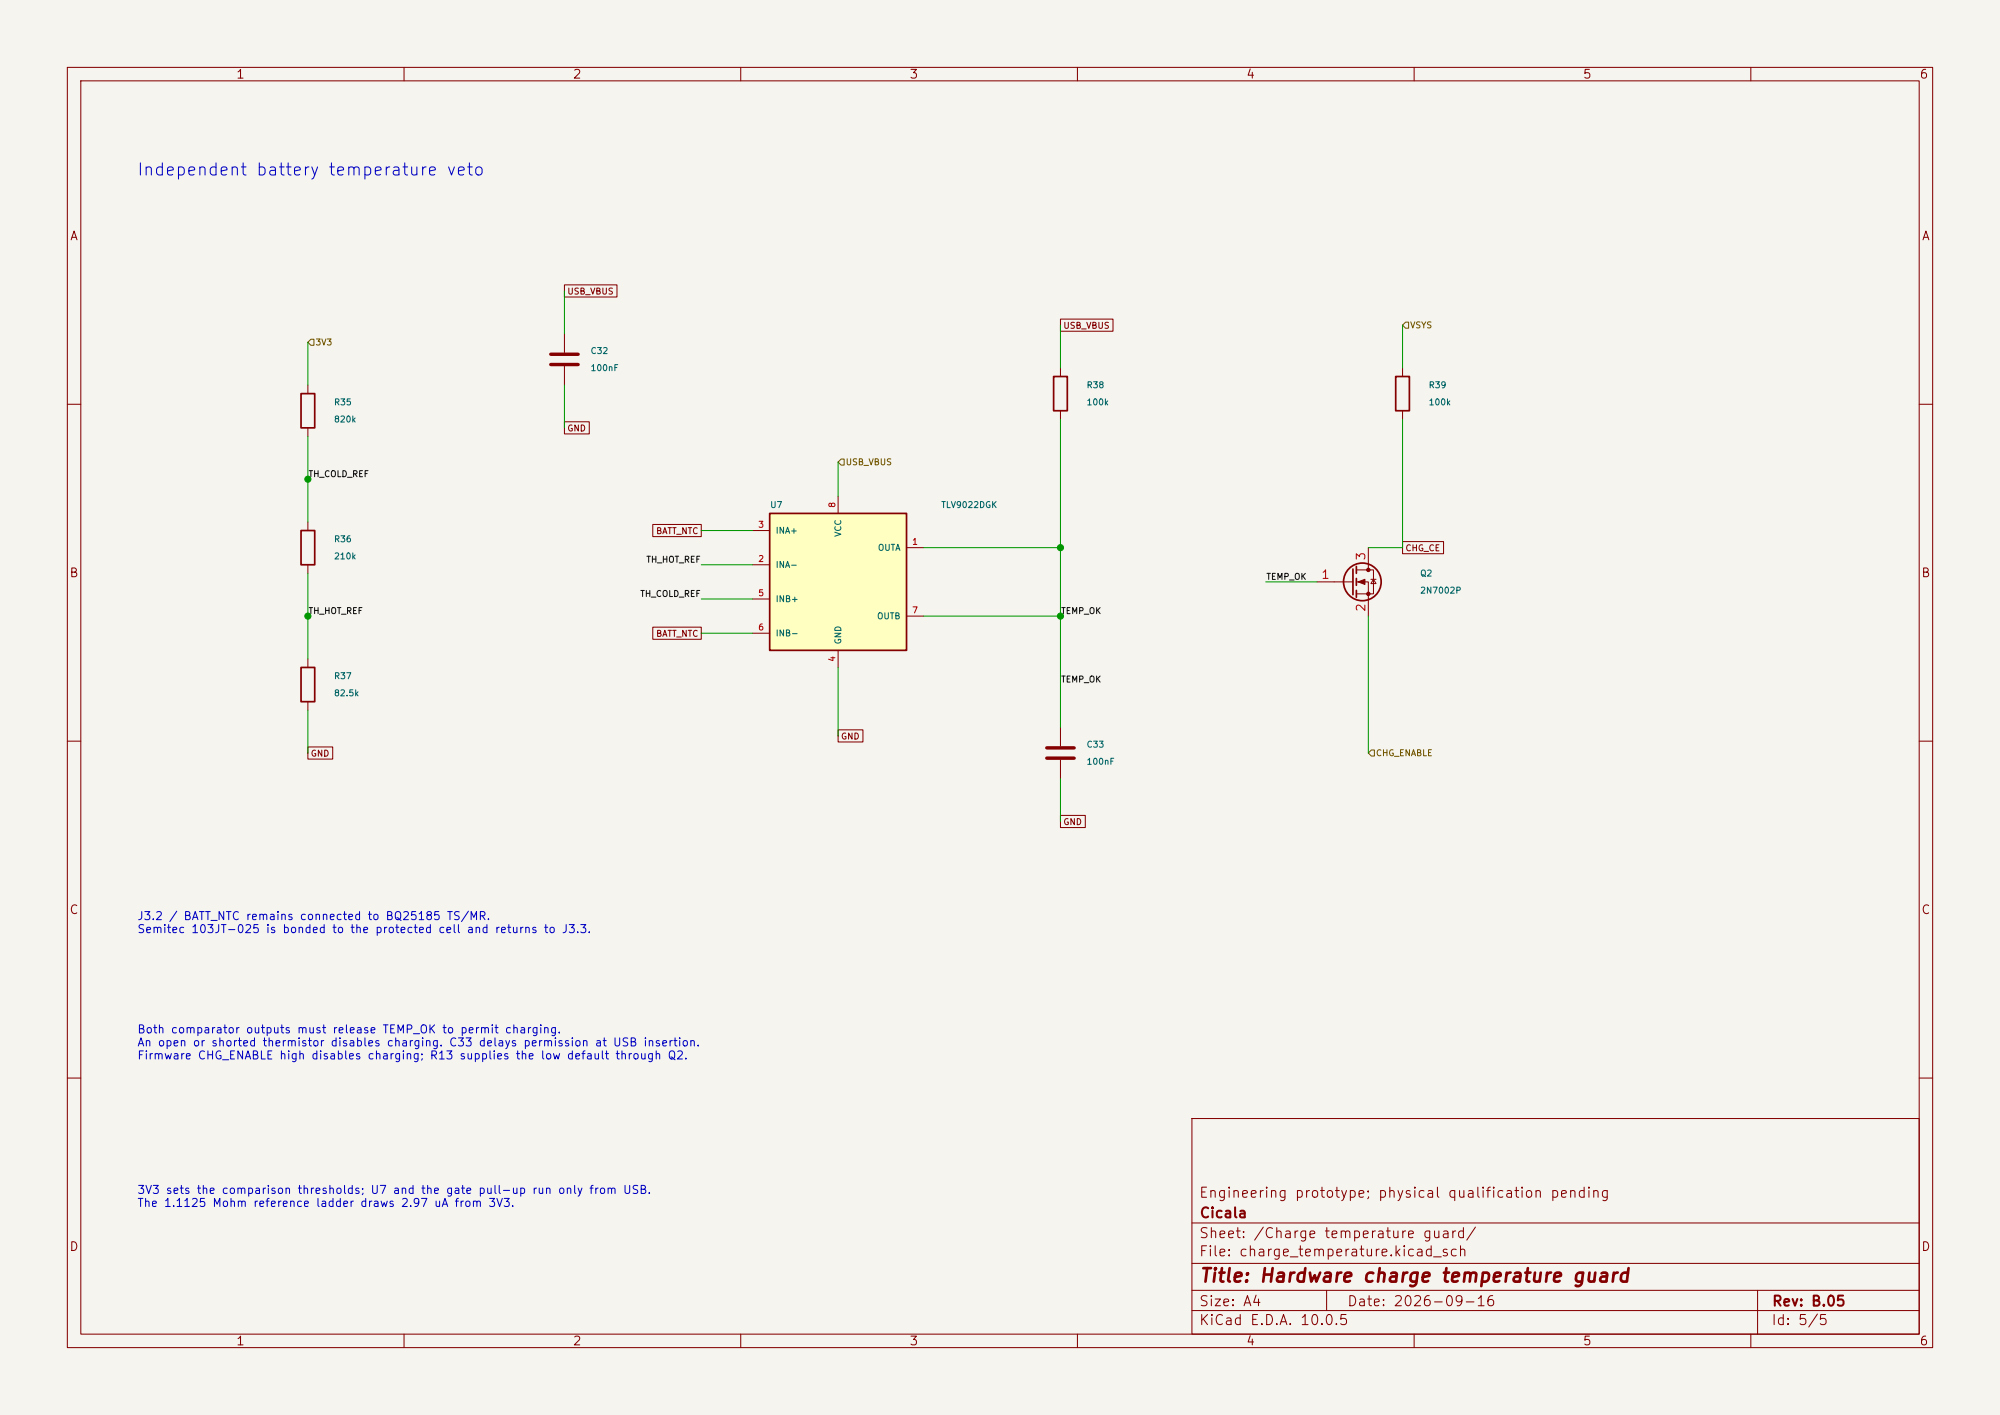
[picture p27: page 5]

TH_HOT_REF Independent battery temperature veto

J3.2 / BATT_NTC remains connected to BQ25185 TS/MR. Semitec 103JT-025 is bonded to the protected cell and returns to J3.3. Both comparator outputs must release TEMP_OK to permit charging. An open or shorted thermistor disables charging. C33 delays permission at USB insertion. Firmware CHG_ENABLE high disables charging; R13 supplies the low default through Q2. 3V3 sets the comparison thresholds; U7 and the gate pull-up run only from USB. The 1.1125 Mohm reference ladder draws 2.97 uA from 3V3.

Engineering prototype; physical qualification pending
Cicala
Sheet: /Charge temperature guard/
File: charge_temperature.kicad_sch
Title: Hardware charge temperature guard

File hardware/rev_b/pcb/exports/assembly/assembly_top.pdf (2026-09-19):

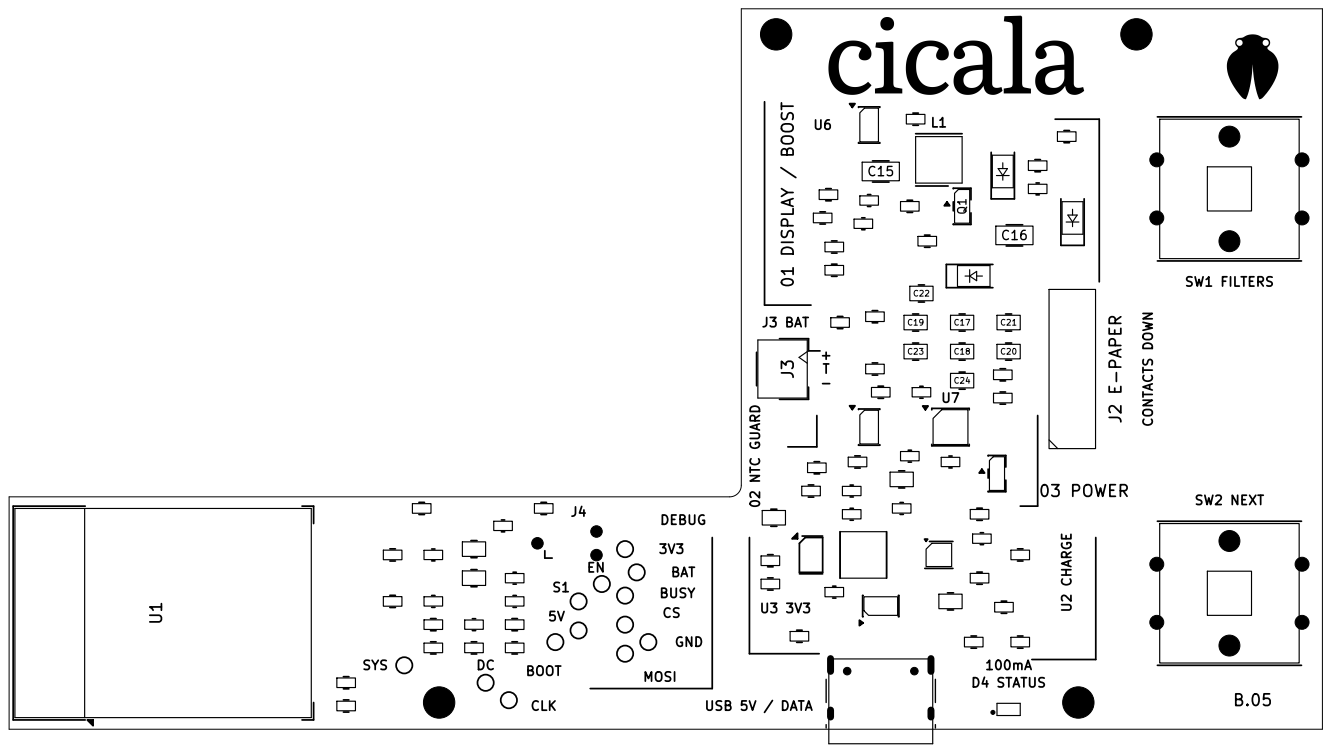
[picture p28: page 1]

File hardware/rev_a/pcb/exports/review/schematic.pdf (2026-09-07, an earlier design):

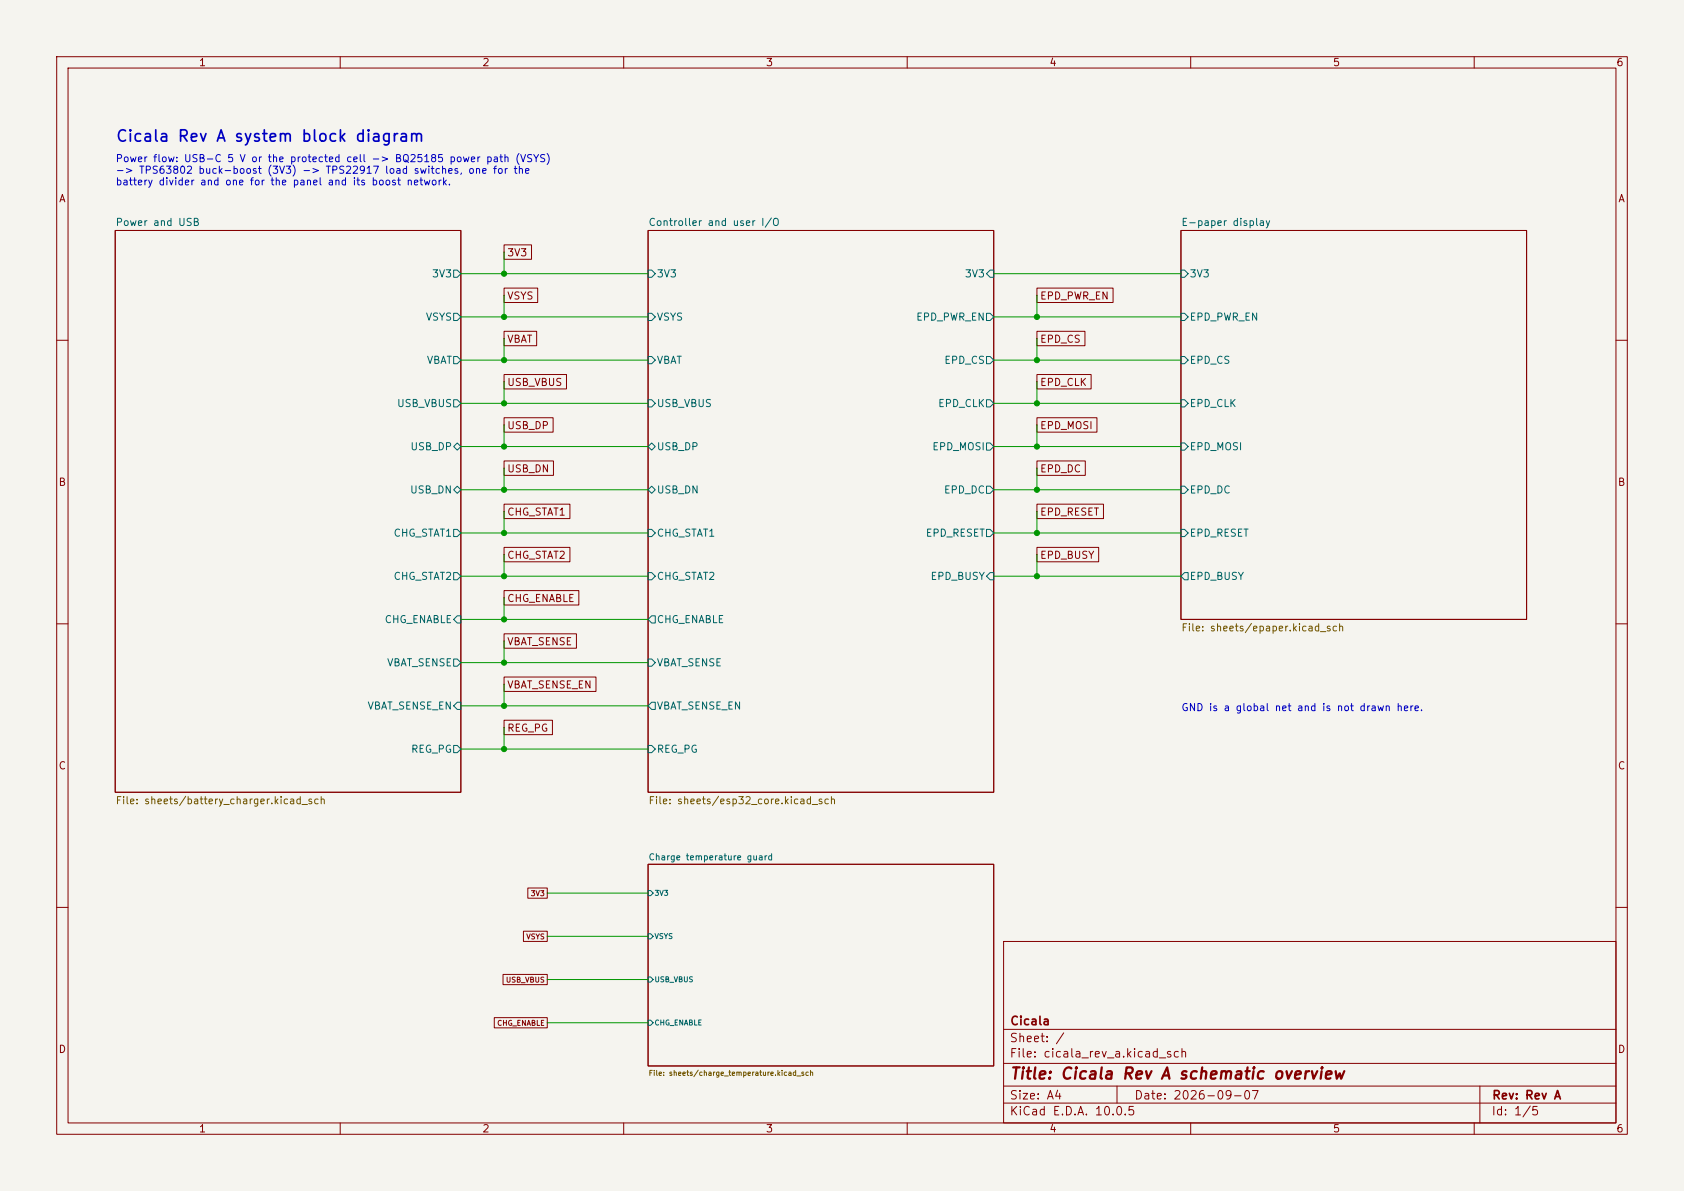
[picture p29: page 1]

Power flow: USB-C 5 V or the protected cell -> BQ25185 power path (VSYS) -> TPS63802 buck-boost (3V3) -> TPS22917 load switches, one for the battery divider and one for the panel and its boost network.

EPD_RESET EPD_BUSY E-paper display File: sheets/epaper.kicad_sch
EPD_MOSI EPD_PWR_EN

VSYS USB_VBUS CHG_ENABLE Charge temperature guard

Cicala
Sheet: /
File: cicala_rev_a.kicad_sch
Title: Cicala Rev A schematic overview

Size: A4 | Rev: Rev A
KiCad E.D.A. 10.0.5 | Id: 1/5

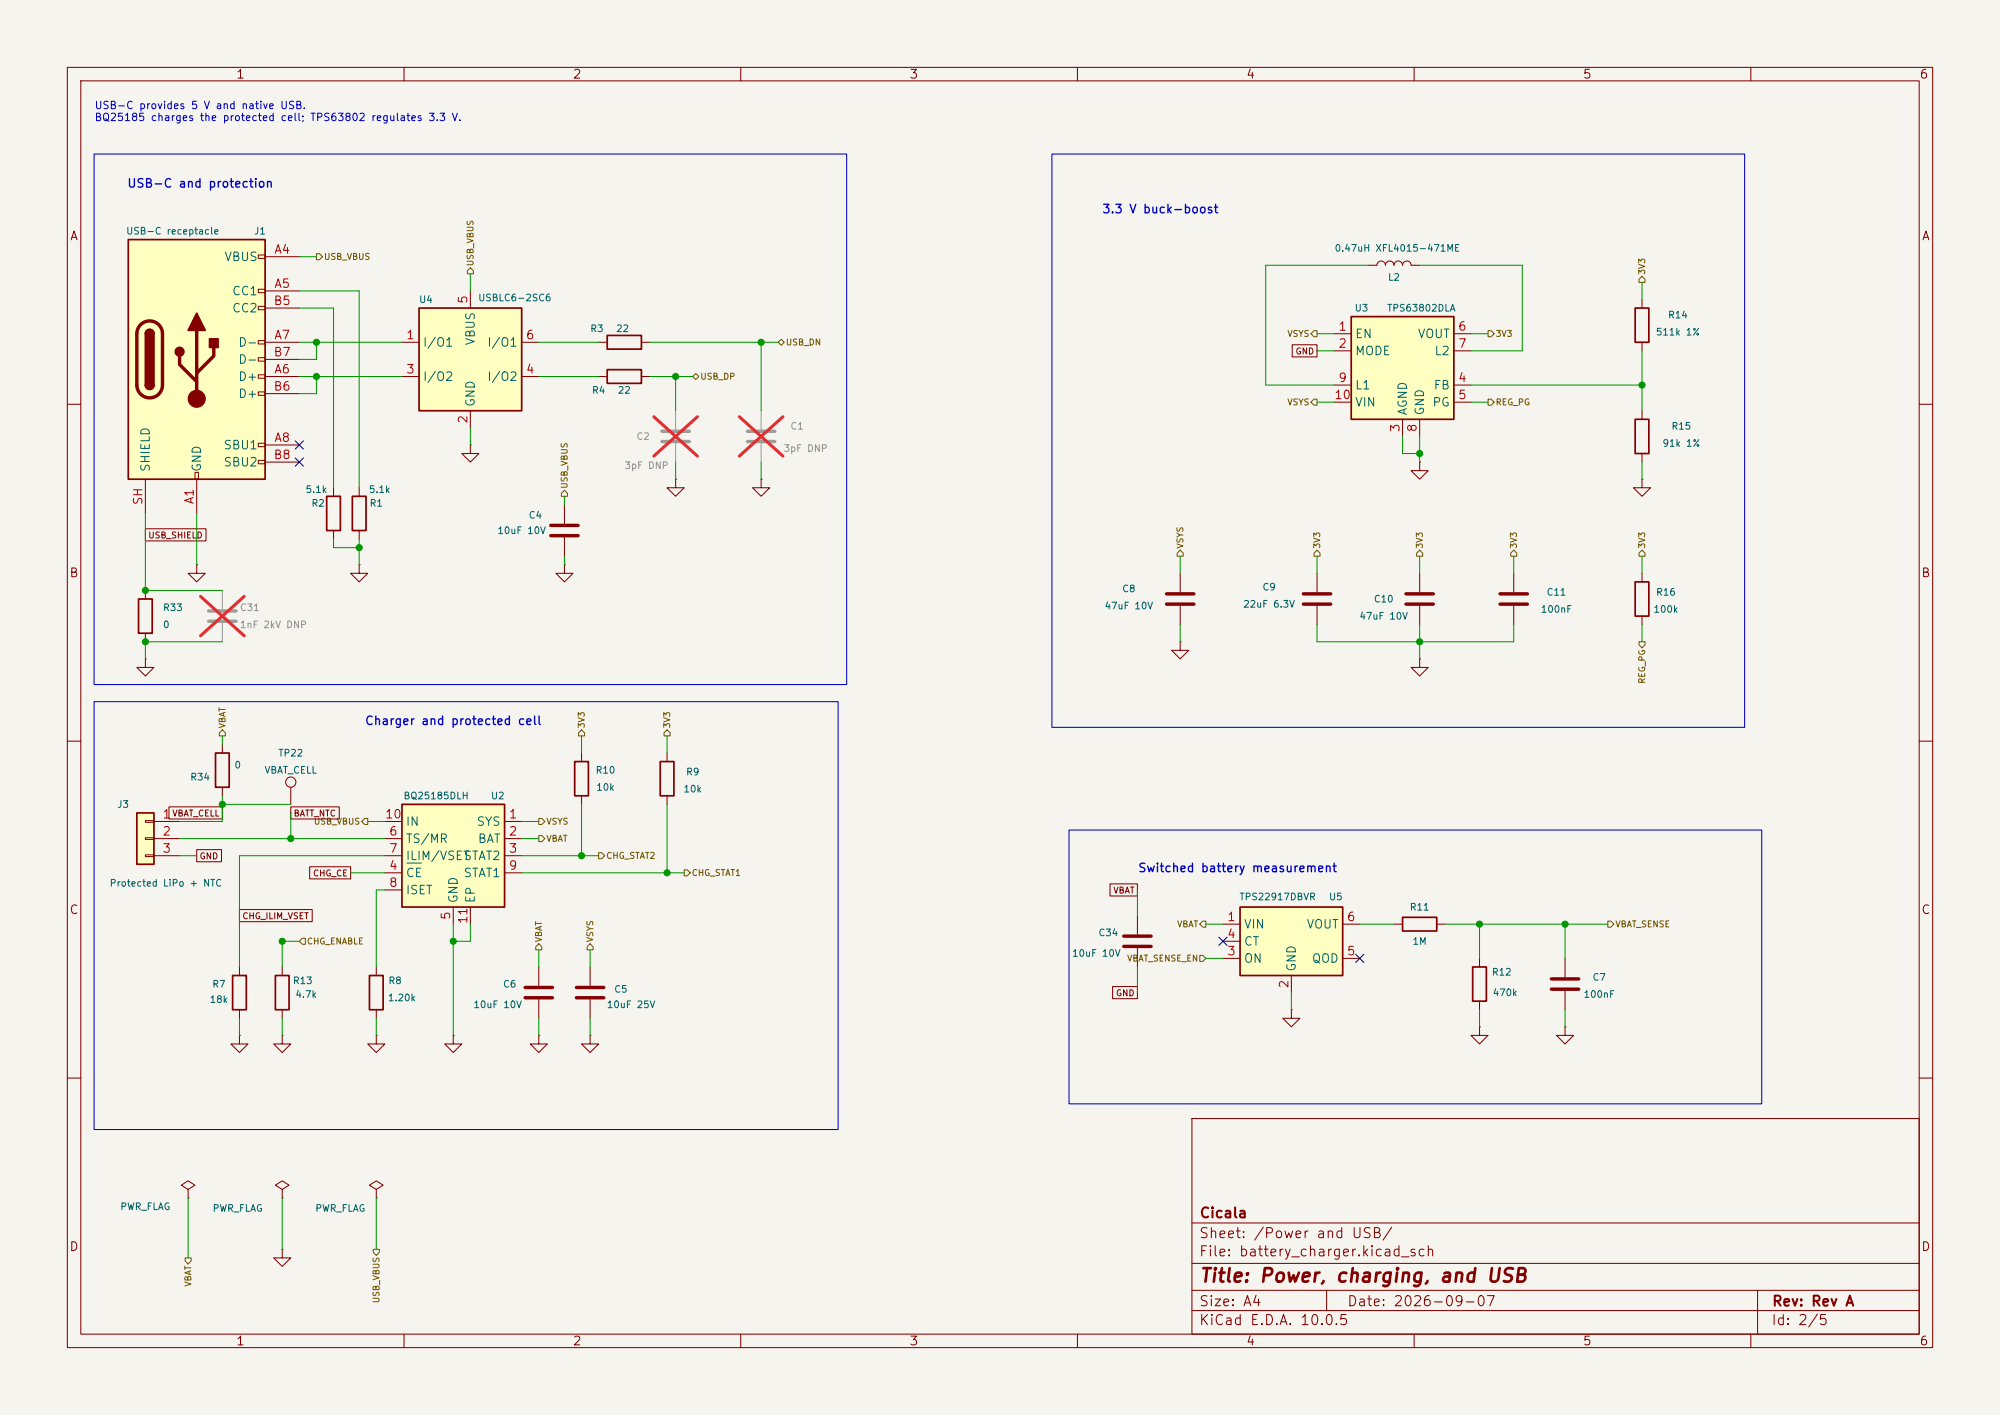
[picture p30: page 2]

Cicala
Sheet: /Power and USB/
File: battery_charger.kicad_sch
Title: Power, charging, and USB

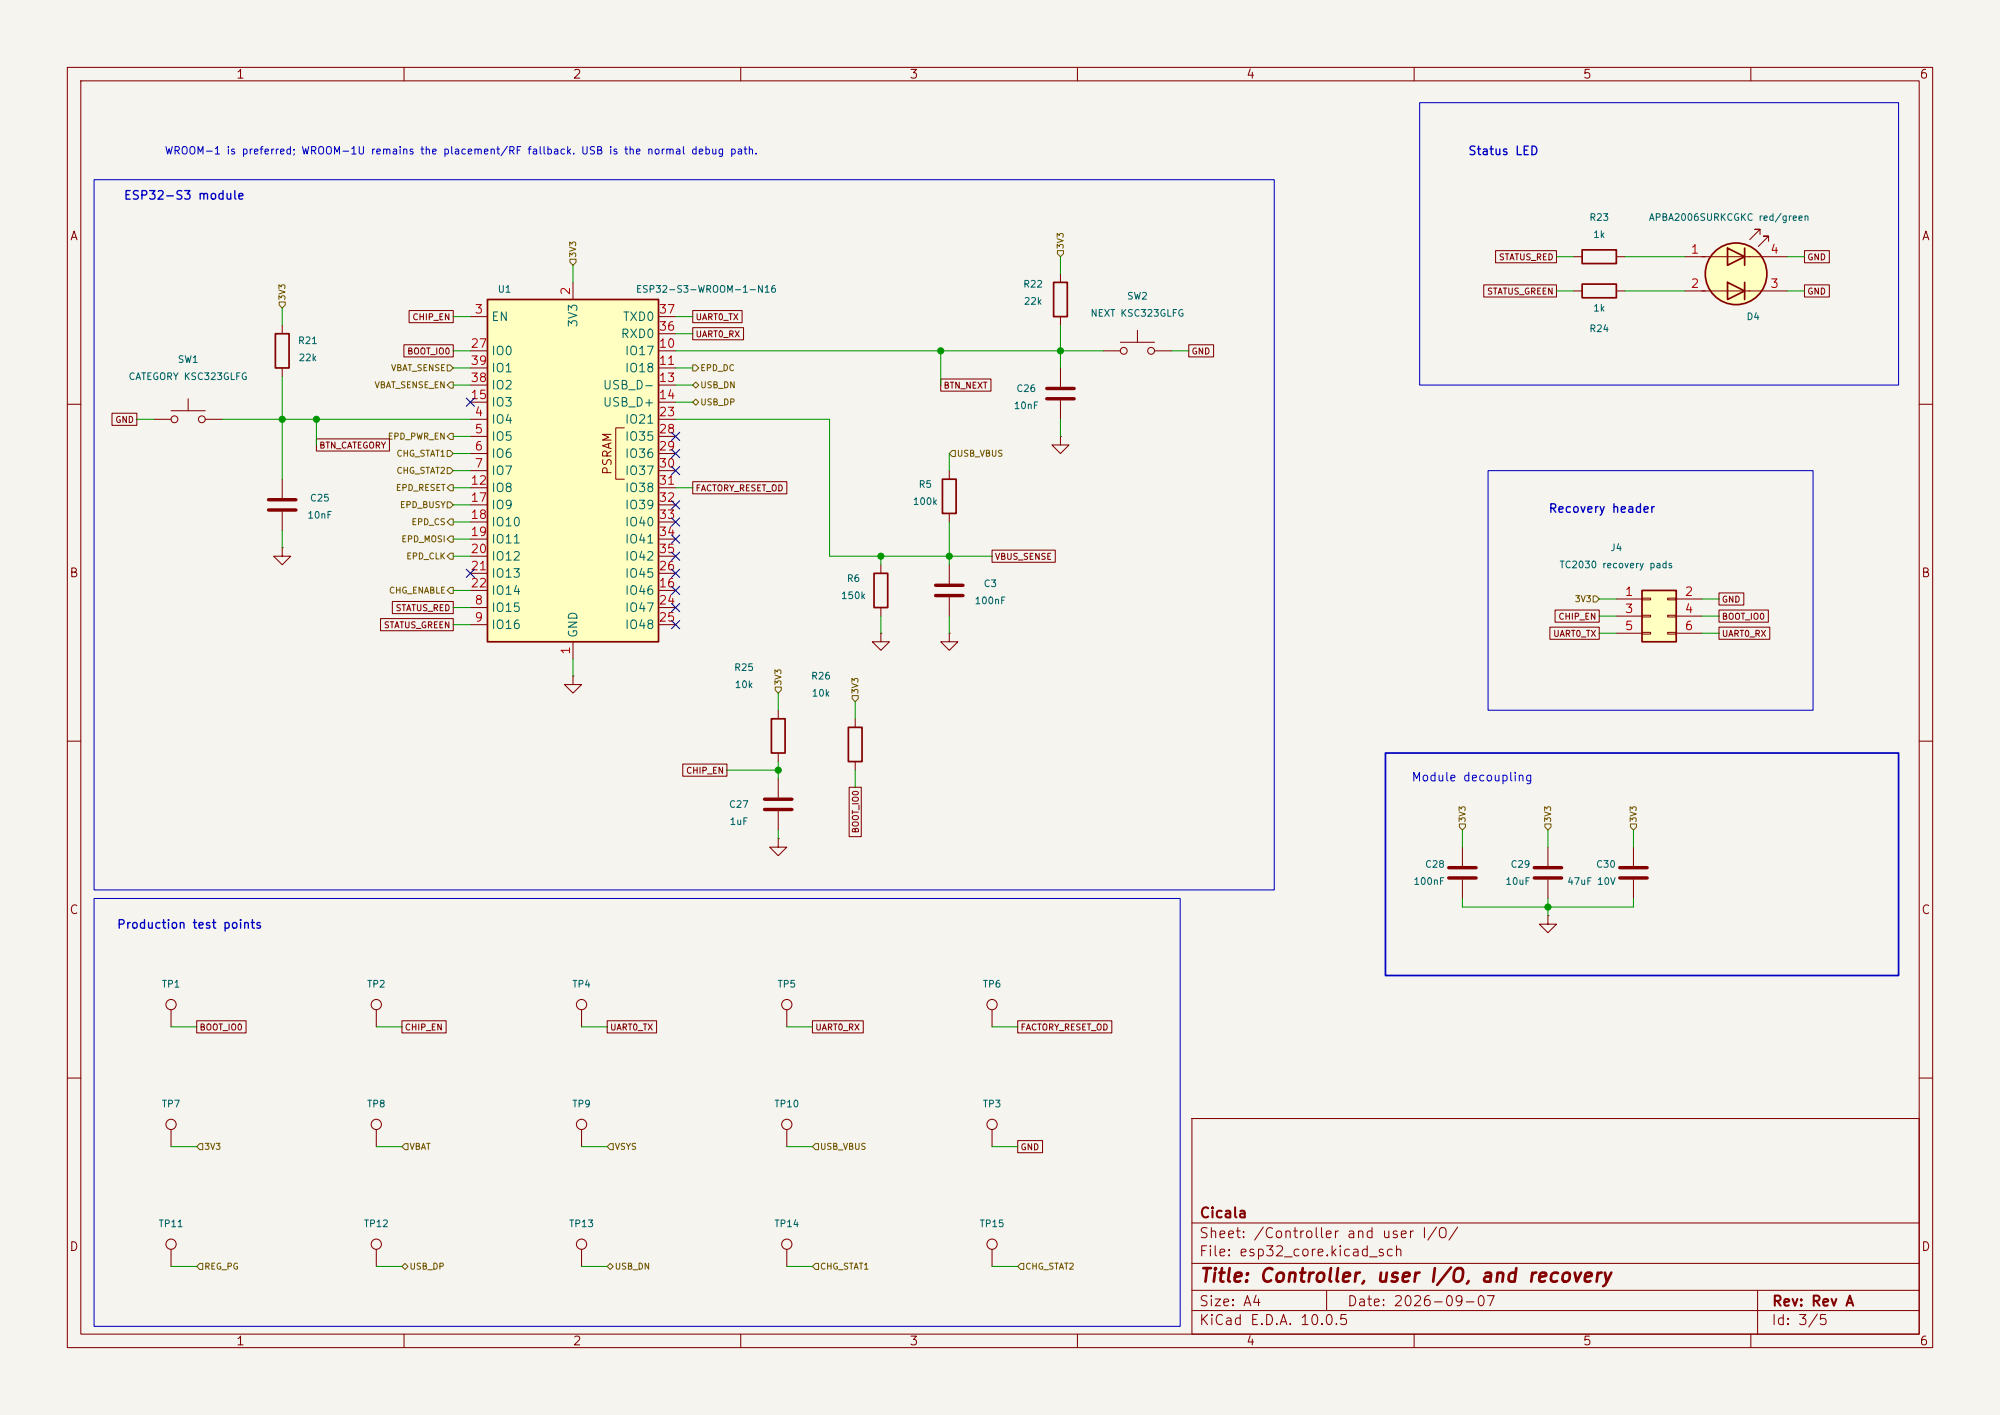
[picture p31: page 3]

APBA2006SURKCGKC red/green PSRAM GND
IO42 35 RXD0 36 TXD0 37

Cicala
Sheet: /Controller and user I/O/
File: esp32_core.kicad_sch
Title: Controller, user I/O, and recovery

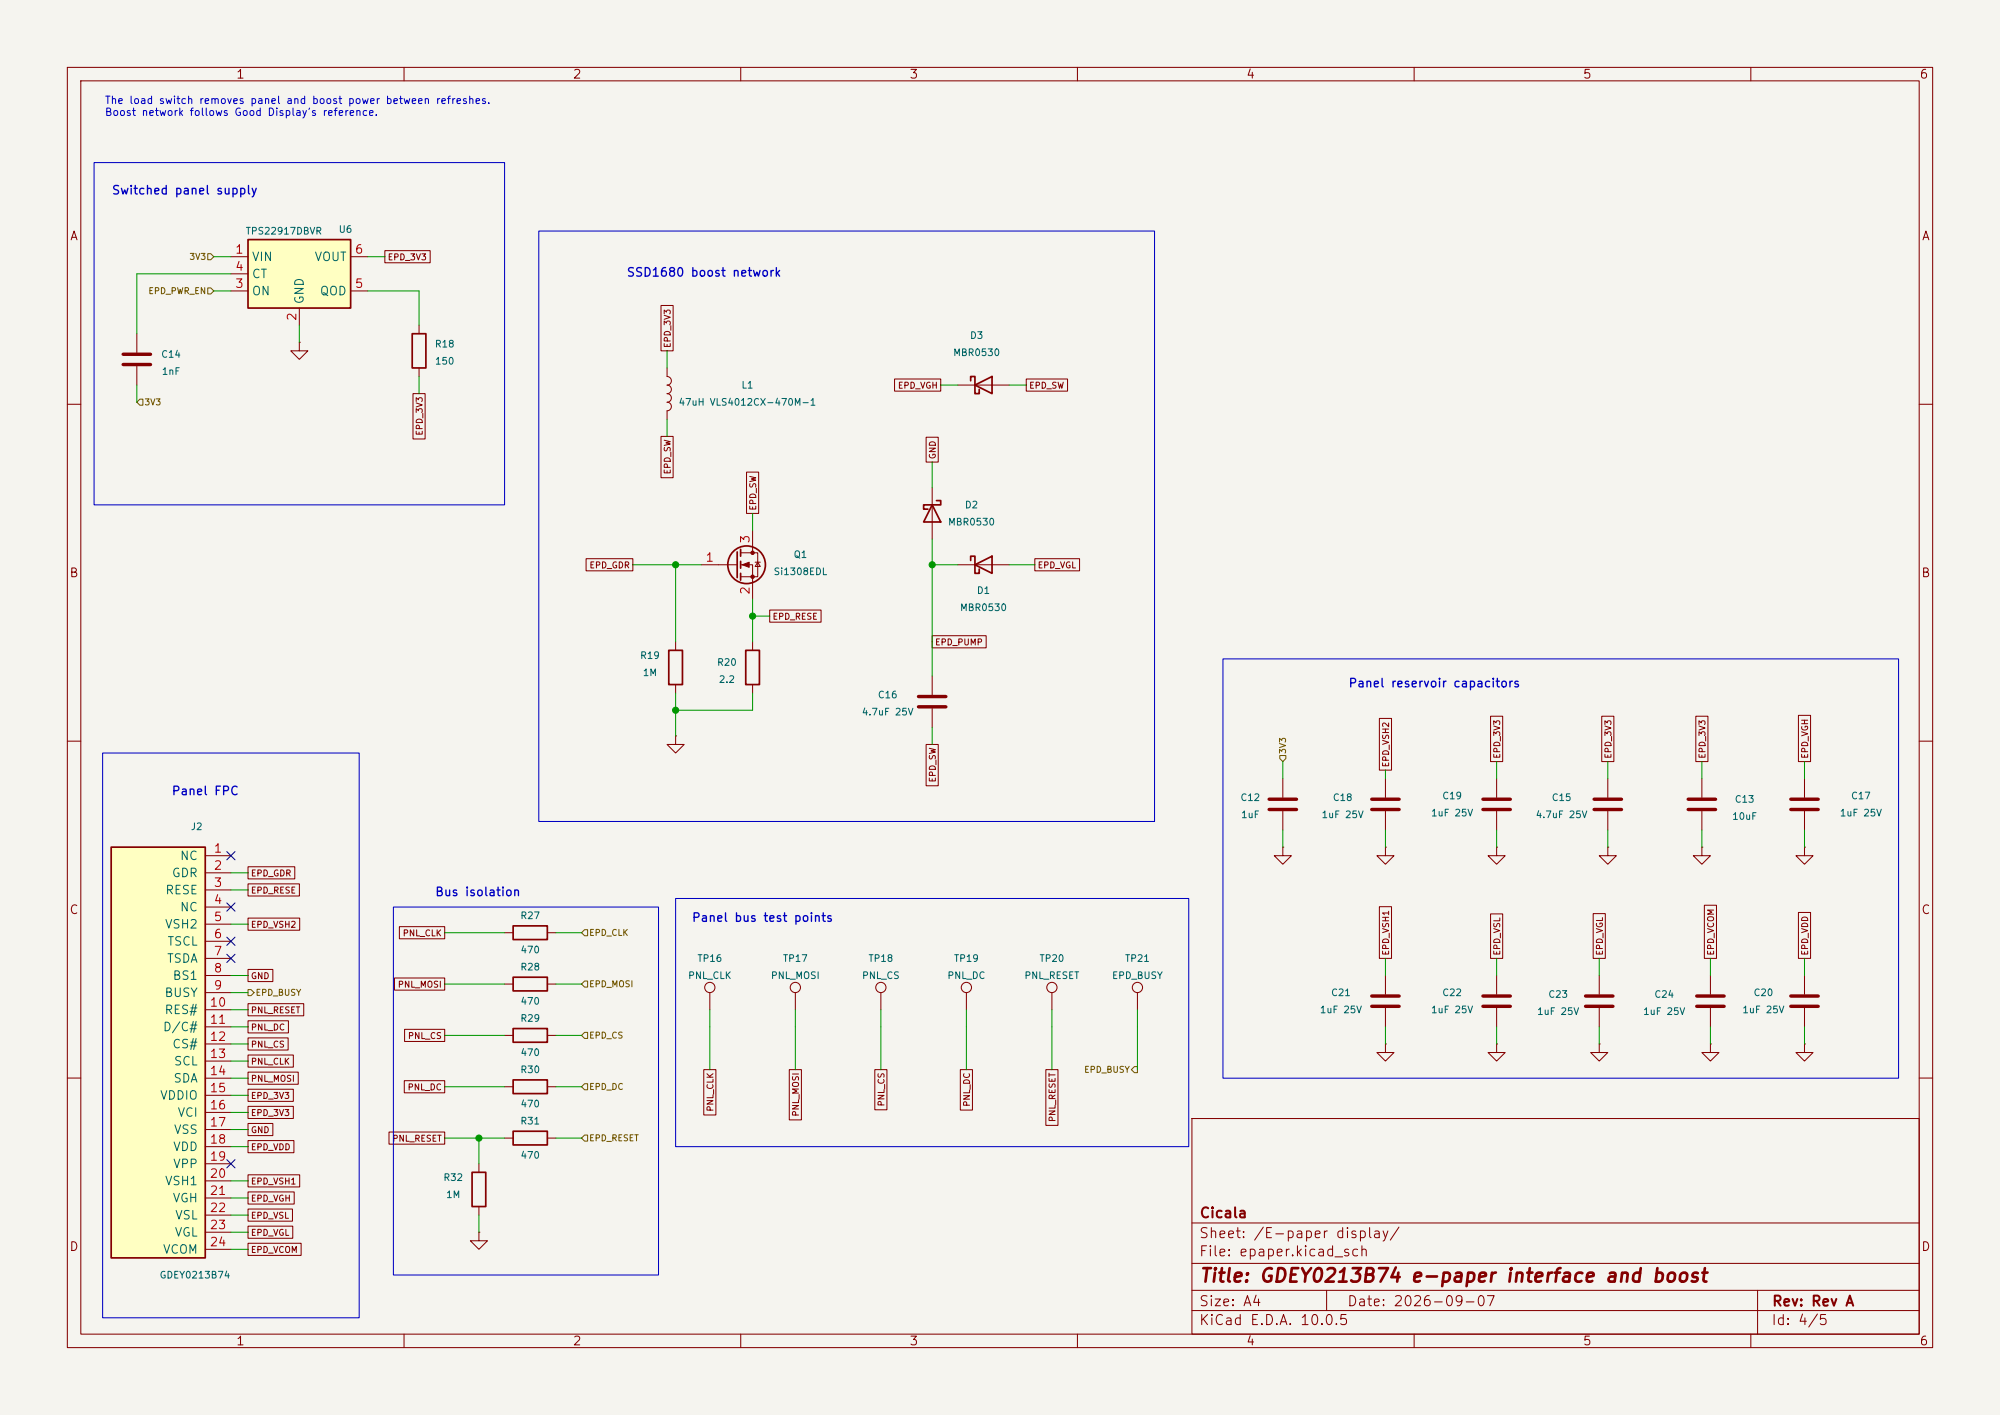
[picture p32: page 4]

The load switch removes panel and boost power between refreshes. Boost network follows Good Display's reference. Switched panel supply Panel FPC

Cicala
Sheet: /E-paper display/
File: epaper.kicad_sch
Title: GDEY0213B74 e-paper interface and boost

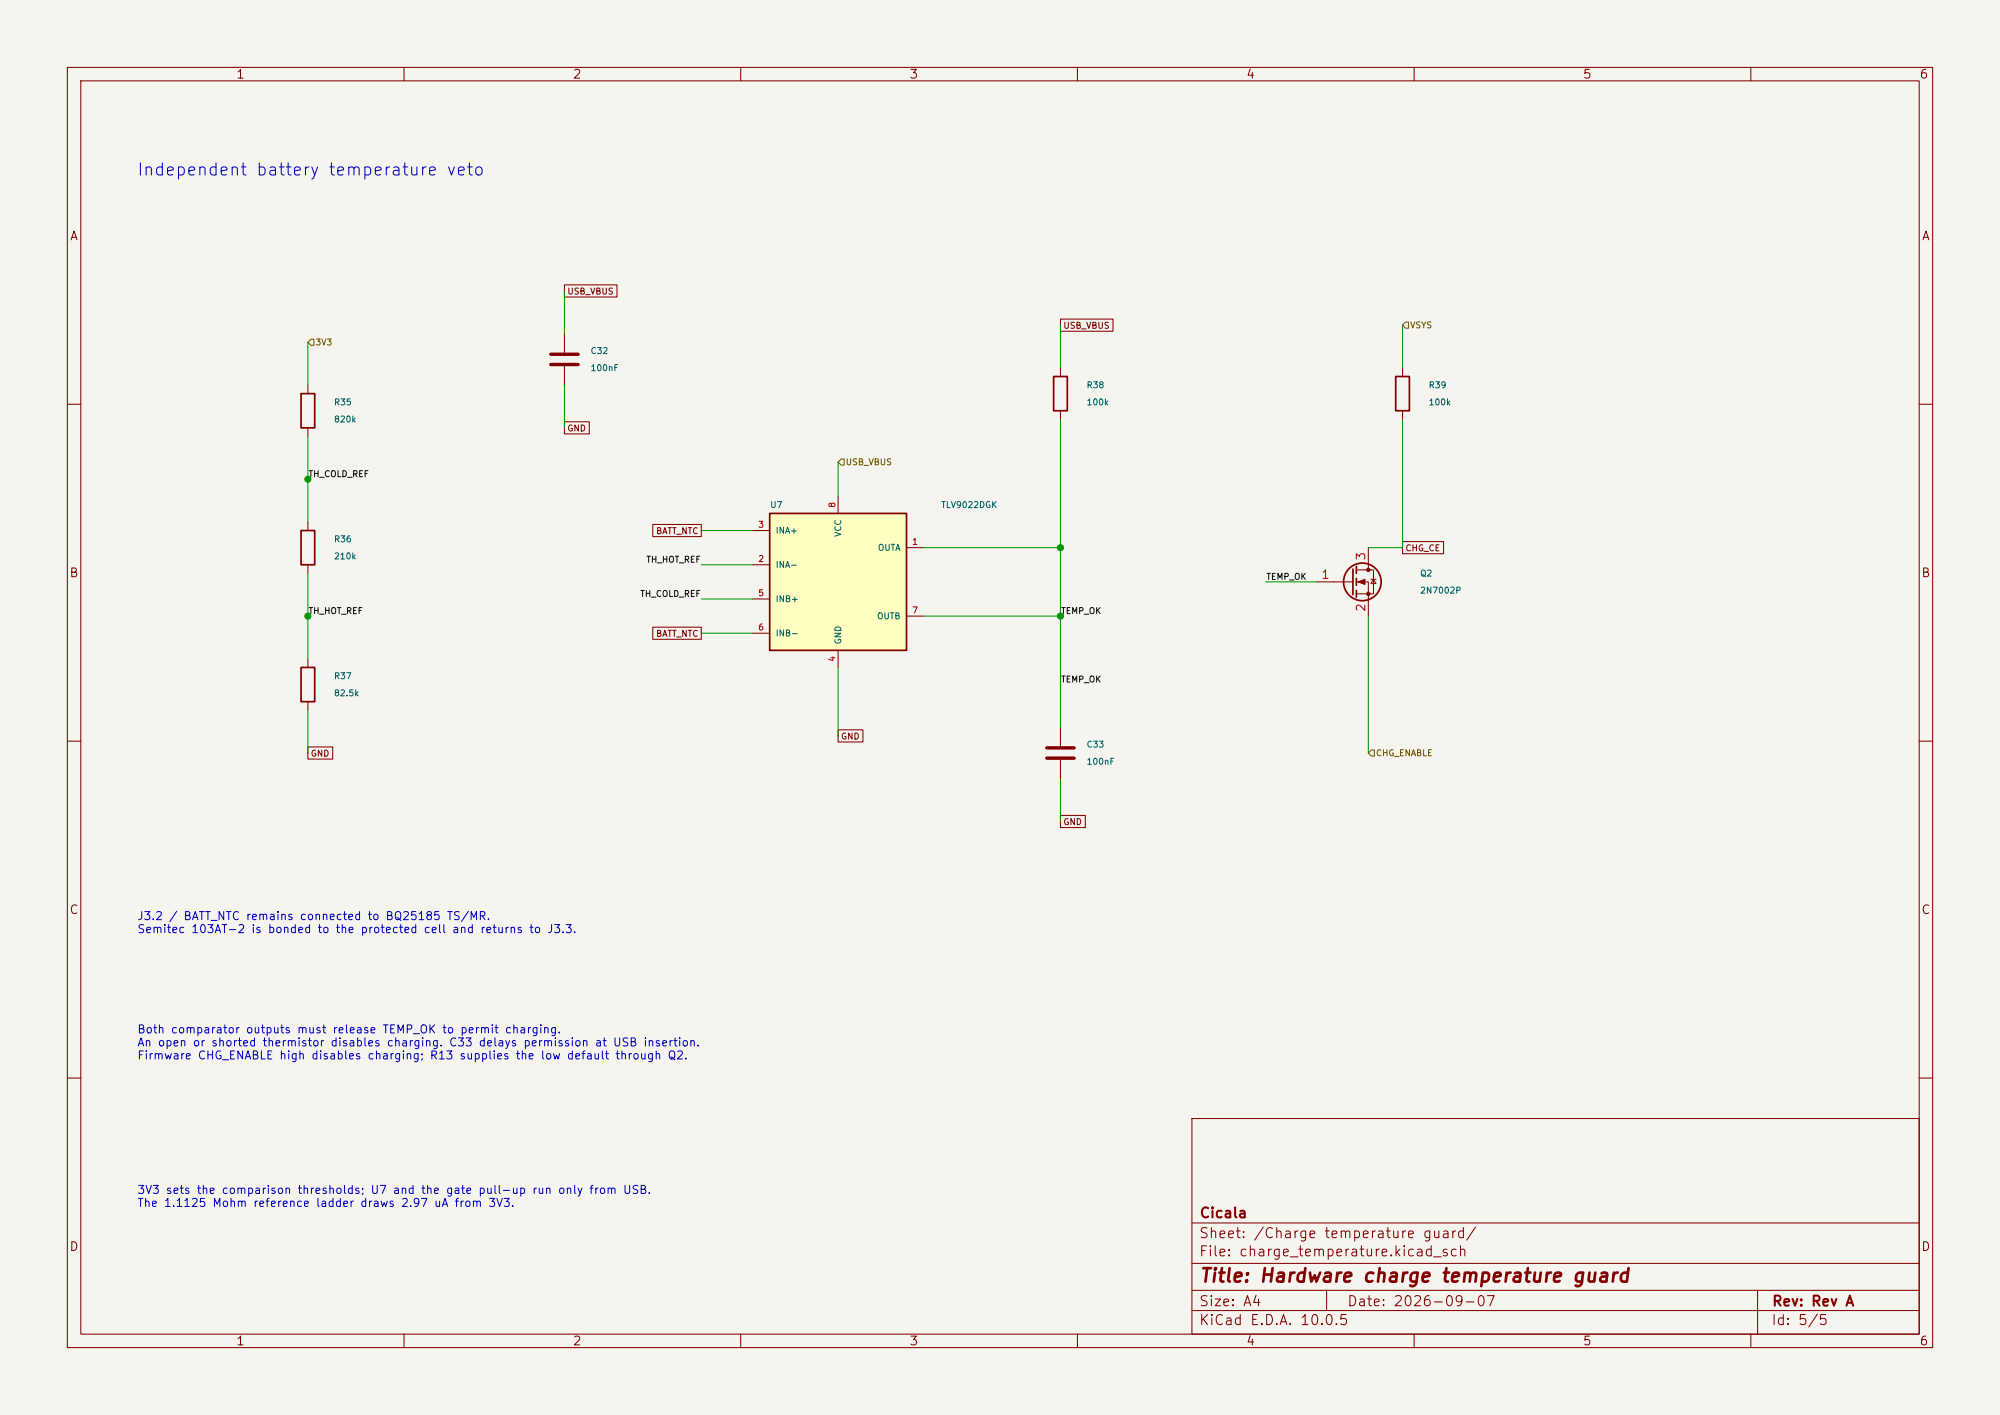
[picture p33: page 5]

TH_HOT_REF Independent battery temperature veto

J3.2 / BATT_NTC remains connected to BQ25185 TS/MR. Semitec 103AT-2 is bonded to the protected cell and returns to J3.3. Both comparator outputs must release TEMP_OK to permit charging. An open or shorted thermistor disables charging. C33 delays permission at USB insertion. Firmware CHG_ENABLE high disables charging; R13 supplies the low default through Q2. 3V3 sets the comparison thresholds; U7 and the gate pull-up run only from USB. The 1.1125 Mohm reference ladder draws 2.97 uA from 3V3.

Cicala
Sheet: /Charge temperature guard/
File: charge_temperature.kicad_sch
Title: Hardware charge temperature guard





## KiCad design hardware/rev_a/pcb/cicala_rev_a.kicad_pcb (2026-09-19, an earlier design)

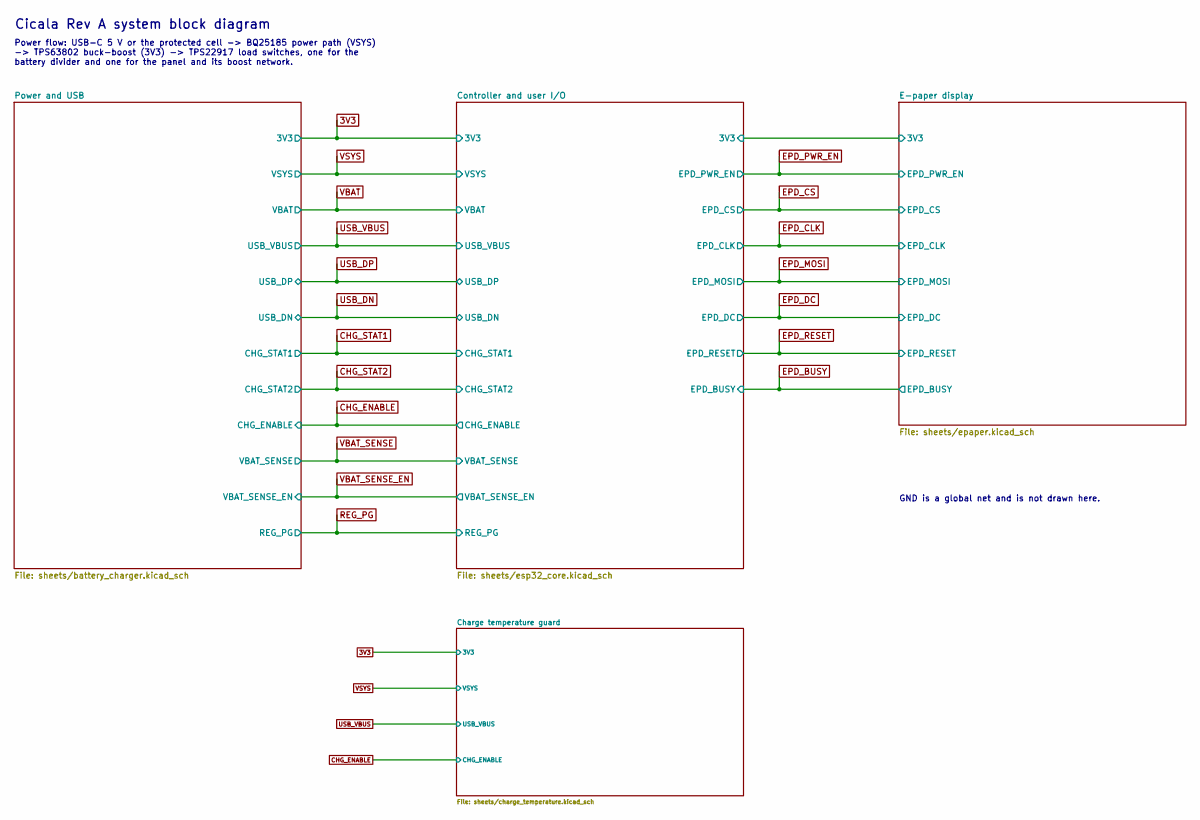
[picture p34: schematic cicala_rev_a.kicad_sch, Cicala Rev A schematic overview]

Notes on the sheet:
Power flow: USB-C 5 V or the protected cell -> BQ25185 power path (VSYS) -> TPS63802 buck-boost (3V3) -> TPS22917 load switches, one for the battery divider and one for the panel and its boost network.
Cicala Rev A system block diagram
GND is a global net and is not drawn here.

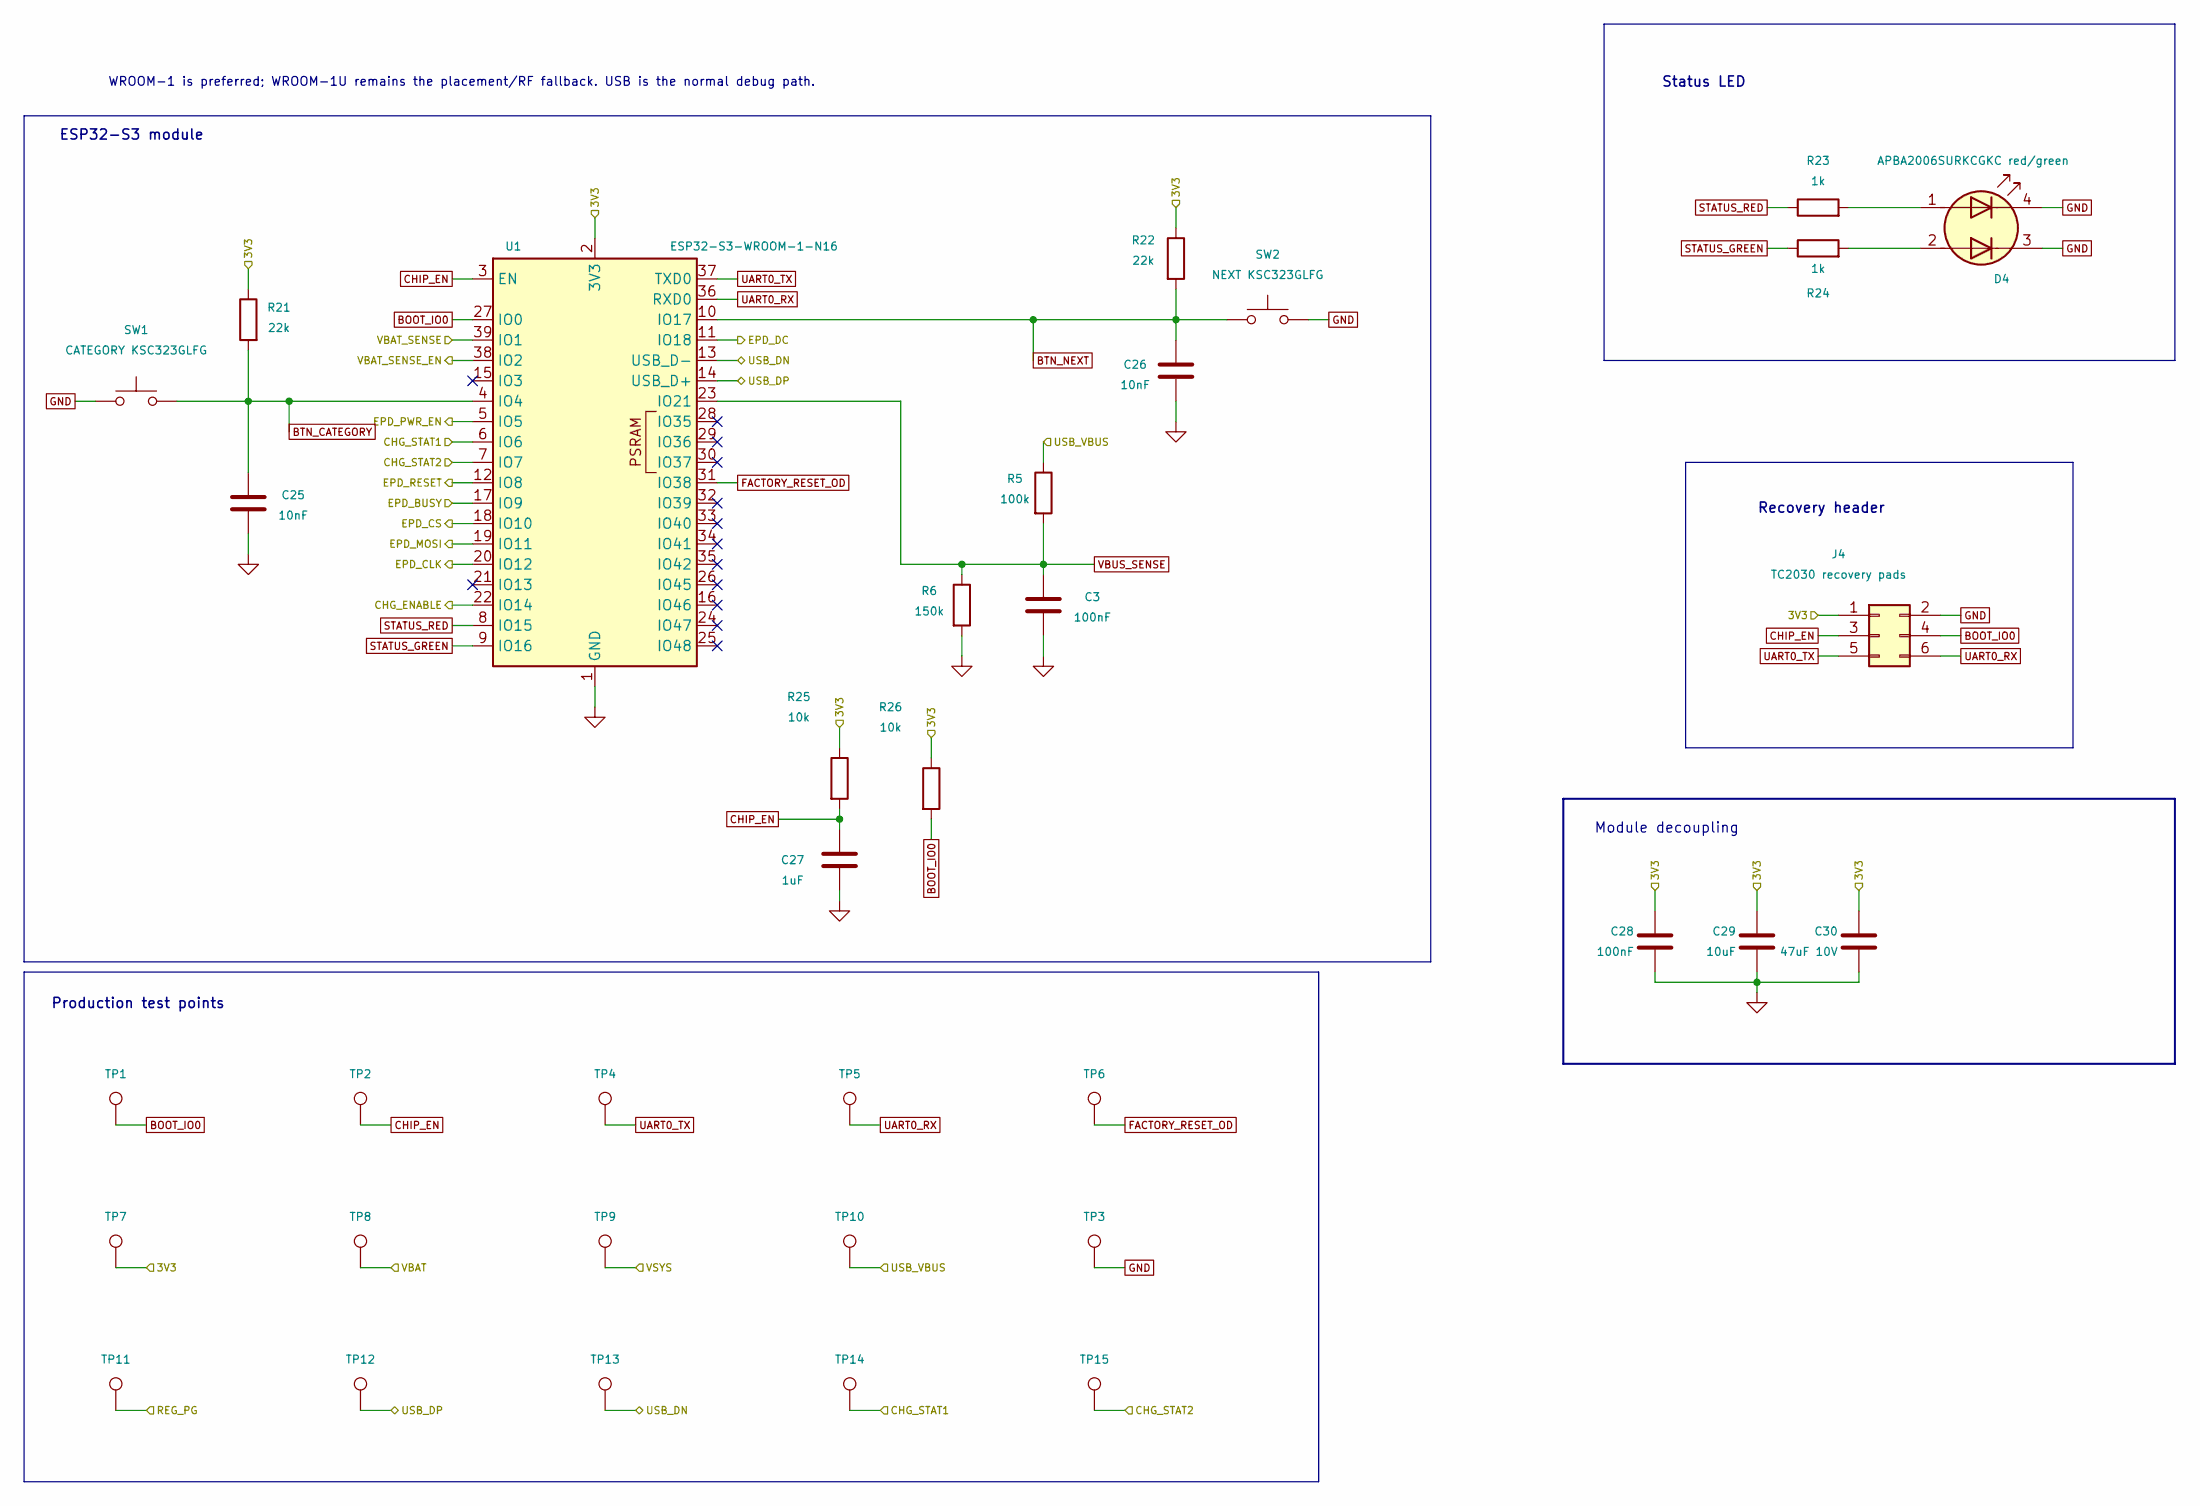
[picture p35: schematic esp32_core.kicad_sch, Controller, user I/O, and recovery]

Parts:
C3, C28: 100nF; C_0603_1608Metric; MPN CL10B104KB8NNNC; LCSC C1591
C25, C26: 10nF; C_0603_1608Metric; MPN CL10B103KB8NNNC; LCSC C1589
C27: 1uF; C_0603_1608Metric; MPN CL10B105KA8NNNC; LCSC C29936
C29: 10uF; C_0603_1608Metric; MPN CL10A106KP8NNNC; LCSC C19702
C30: 47uF 10V; C_0805_2012Metric; MPN CL21A476MPYNNNE; LCSC C41796773
D4: APBA2006SURKCGKC red/green; LED_Kingbright_APBA2006SURKCGKC; MPN APBA2006SURKCGKC
J4: TC2030 recovery pads; Tag-Connect_TC2030-IDC-NL_2x03_P1.27mm_Vertical
R5: 100k; R_0603_1608Metric; MPN RC0603FR-07100KL
R6: 150k; R_0603_1608Metric; MPN RC0603FR-07150KL
R21, R22: 22k; R_0603_1608Metric; MPN RC0603FR-0722KL
R23, R24: 1k; R_0603_1608Metric; MPN RC0603FR-071KL
R25, R26: 10k; R_0603_1608Metric; MPN RC0603FR-0710KL
SW1: CATEGORY KSC323GLFG; SW_Push_1P1T_NO_CK_KSC6xxG; MPN KSC323GLFG
SW2: NEXT KSC323GLFG; SW_Push_1P1T_NO_CK_KSC6xxG; MPN KSC323GLFG
TP1: BOOT_IO0; TestPoint_Pad_D1.0mm
TP2: CHIP_EN; TestPoint_Pad_D1.0mm
TP3: GND; TestPoint_Pad_D1.0mm
TP4: UART0_TX; TestPoint_Pad_D1.0mm
TP5: UART0_RX; TestPoint_Pad_D1.0mm
TP6: FACTORY_RESET_OD; TestPoint_Pad_D1.0mm
TP7: 3V3; TestPoint_Pad_D1.0mm
TP8: VBAT; TestPoint_Pad_D1.0mm
TP9: VSYS; TestPoint_Pad_D1.0mm
TP10: USB_VBUS; TestPoint_Pad_D1.0mm
TP11: REG_PG; TestPoint_Pad_D1.0mm
TP12: USB_DP; TestPoint_Pad_D1.0mm
TP13: USB_DN; TestPoint_Pad_D1.0mm
TP14: CHG_STAT1; TestPoint_Pad_D1.0mm
TP15: CHG_STAT2; TestPoint_Pad_D1.0mm
U1: ESP32-S3-WROOM-1-N16; ESP32-S3-WROOM-1; MPN ESP32-S3-WROOM-1-N16

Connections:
3V3: C28.1, C29.1, C30.1, J4.1, R21.1, R22.1, R25.1, R26.1, TP7.1, U1.2 (3V3); also elsewhere on the board
BOOT_IO0: J4.4, R26.2, TP1.1, U1.27 (IO0)
BTN_CATEGORY: C25.1, R21.2, SW1.1, U1.4 (IO4)
BTN_NEXT: C26.1, R22.2, SW2.1, U1.10 (IO17)
CHG_ENABLE: U1.22 (IO14); also elsewhere on the board
CHG_STAT1: TP14.1, U1.6 (IO6); also elsewhere on the board
CHG_STAT2: TP15.1, U1.7 (IO7); also elsewhere on the board
CHIP_EN: C27.1, J4.3, R25.2, TP2.1, U1.3 (EN)
EPD_BUSY: U1.17 (IO9); also elsewhere on the board
EPD_CLK: U1.20 (IO12); also elsewhere on the board
EPD_CS: U1.18 (IO10); also elsewhere on the board
EPD_DC: U1.11 (IO18); also elsewhere on the board
EPD_MOSI: U1.19 (IO11); also elsewhere on the board
EPD_PWR_EN: U1.5 (IO5); also elsewhere on the board
EPD_RESET: U1.12 (IO8); also elsewhere on the board
FACTORY_RESET_OD: TP6.1, U1.31 (IO38)
GND: C3.2, C25.2, C26.2, C27.2, C28.2, C29.2, C30.2, D4.3 (K2), D4.4 (K1), J4.2, R6.2, SW1.2, SW2.2, TP3.1, U1.1 (GND), U1.40 (GND), U1.41 (GND); also elsewhere on the board
unnamed: D4.1 (A1), R23.2
unnamed: D4.2 (A2), R24.2
REG_PG: TP11.1; also elsewhere on the board
STATUS_GREEN: R24.1, U1.9 (IO16)
STATUS_RED: R23.1, U1.8 (IO15)
UART0_RX: J4.6, TP5.1, U1.36 (RXD0)
UART0_TX: J4.5, TP4.1, U1.37 (TXD0)
USB_DN: TP13.1, U1.13 (USB_D-); also elsewhere on the board
USB_DP: TP12.1, U1.14 (USB_D+); also elsewhere on the board
USB_VBUS: R5.1, TP10.1; also elsewhere on the board
VBAT: TP8.1; also elsewhere on the board
VBAT_SENSE: U1.39 (IO1); also elsewhere on the board
VBAT_SENSE_EN: U1.38 (IO2); also elsewhere on the board
VBUS_SENSE: C3.1, R5.2, R6.1, U1.23 (IO21)
VSYS: TP9.1; also elsewhere on the board

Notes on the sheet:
Recovery header
Status LED
WROOM-1 is preferred; WROOM-1U remains the placement/RF fallback. USB is the normal debug path.
ESP32-S3 module
Production test points
Module decoupling

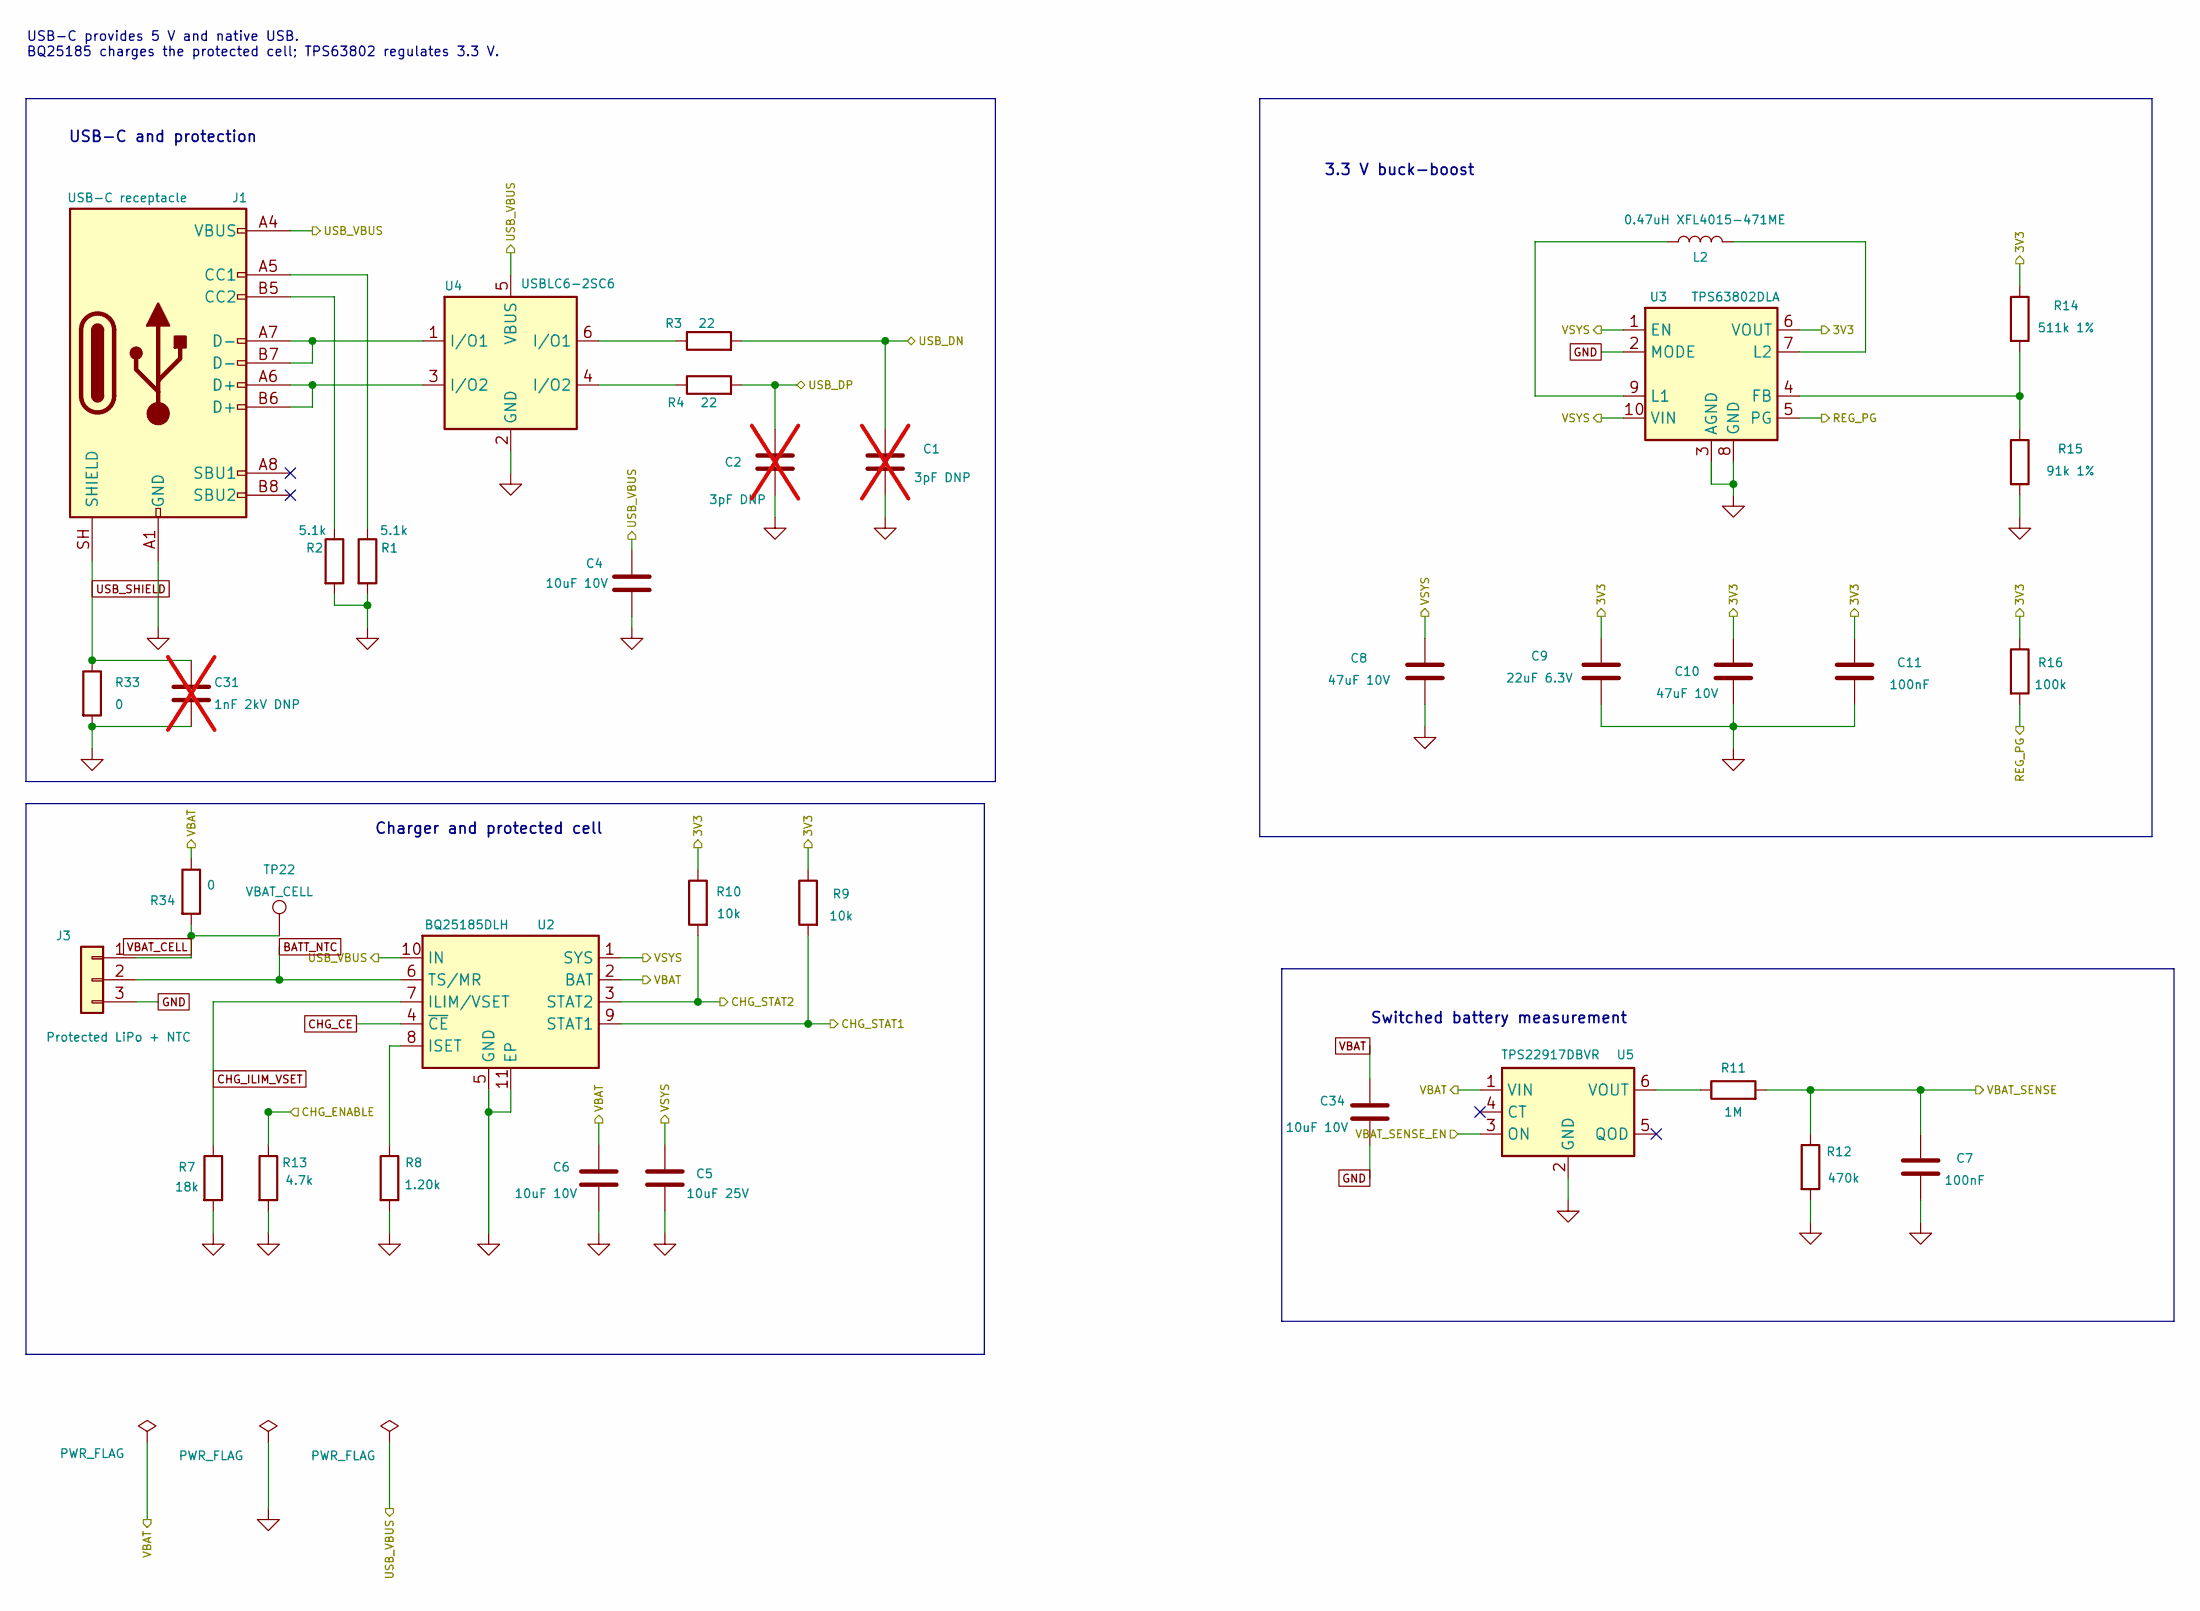
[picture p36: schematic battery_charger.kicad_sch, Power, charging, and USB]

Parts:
C1, C2: 3pF DNP; C_0603_1608Metric; not fitted
C4, C6, C34: 10uF 10V; C_0603_1608Metric; MPN CL10A106KP8NNNC; LCSC C19702
C5: 10uF 25V; C_0805_2012Metric; MPN CL21A106KAYNNNE; LCSC C15850
C7, C11: 100nF; C_0603_1608Metric; MPN CL10B104KB8NNNC; LCSC C1591
C8, C10: 47uF 10V; C_0805_2012Metric; MPN CL21A476MPYNNNE; LCSC C41796773
C9: 22uF 6.3V; C_0603_1608Metric; MPN CL10A226MQ8NRNC; LCSC C59461
C31: 1nF 2kV DNP; C_0805_2012Metric; not fitted
J1: USB-C receptacle; USB_C_Receptacle_HRO_TYPE-C-31-M-12_EdgeOverhang; MPN TYPE-C-31-M-12
J3: Protected LiPo + NTC; JST_PH_S3B-PH-SM4-TB_1x03-1MP_P2.00mm_Horizontal; MPN S3B-PH-SM4-TB(LF)(SN)
L2: 0.47uH XFL4015-471ME; L_Coilcraft_XFL4015; MPN XFL4015-471ME
R1, R2: 5.1k; R_0603_1608Metric; MPN RC0603FR-075K1L
R3, R4: 22; R_0603_1608Metric; MPN RC0603FR-0722RL
R7: 18k; R_0603_1608Metric; MPN RC0603FR-0718KL
R8: 1.20k; R_0603_1608Metric; MPN RC0603FR-071K2L
R9, R10: 10k; R_0603_1608Metric; MPN RC0603FR-0710KL
R11: 1M; R_0603_1608Metric; MPN RC0603FR-071ML
R12: 470k; R_0603_1608Metric; MPN RC0603FR-07470KL
R13: 4.7k; R_0603_1608Metric; MPN RC0603FR-074K7L
R14: 511k 1%; R_0603_1608Metric; MPN RC0603FR-07511KL
R15: 91k 1%; R_0603_1608Metric; MPN RC0603FR-0791KL
R16: 100k; R_0603_1608Metric; MPN RC0603FR-07100KL
R33, R34: 0; R_0603_1608Metric; MPN RC0603JR-070RL
TP22: VBAT_CELL; TestPoint_Pad_D1.0mm
U2: BQ25185DLH; Texas_DLH0010A_WSON-10-1EP_2.2x2mm_P0.4mm_EP0.9x1.5mm_Therm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; MPN BQ25185DLHR
U3: TPS63802DLA; Texas_DLA0010A_VSON-HR-10_2x3mm_P0.5mm; MPN TPS63802DLAR
U4: USBLC6-2SC6; SOT-23-6; MPN USBLC6-2SC6
U5: TPS22917DBVR; SOT-23-6; MPN TPS22917DBVR

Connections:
3V3: C9.1, C10.1, C11.1, R9.1, R10.1, R14.1, R16.1, U3.6 (VOUT); also elsewhere on the board
BATT_NTC: J3.2, U2.6 (TS/MR); also elsewhere on the board
CHG_CE: U2.4 (~CE); also elsewhere on the board
CHG_ENABLE: R13.1; also elsewhere on the board
CHG_ILIM_VSET: R7.1, U2.7 (ILIM/VSET)
CHG_STAT1: R9.2, U2.9 (STAT1); also elsewhere on the board
CHG_STAT2: R10.2, U2.3 (STAT2); also elsewhere on the board
GND: C1.2, C2.2, C4.2, C5.2, C6.2, C7.2, C8.2, C9.2, C10.2, C11.2, C31.2, C34.2, J1.A1 (GND), J1.A12 (GND), J1.B1 (GND), J1.B12 (GND), J3.3, R1.2, R2.2, R7.2, R8.2, R12.2, R13.2, R15.2, R33.2, U2.5 (GND), U2.11 (EP), U3.2 (MODE), U3.3 (AGND), U3.8 (GND), U4.2 (GND), U5.2 (GND); also elsewhere on the board
unnamed: J1.A5 (CC1), R1.1
unnamed: J1.B5 (CC2), R2.1
unnamed: J1.A6 (D+), J1.B6 (D+), U4.3 (I/O2)
unnamed: J1.A7 (D-), J1.B7 (D-), U4.1 (I/O1)
unnamed: R3.1, U4.6 (I/O1)
unnamed: R4.1, U4.4 (I/O2)
unnamed: R8.1, U2.8 (ISET)
unnamed: R14.2, R15.1, U3.4 (FB)
unnamed: L2.1, U3.9 (L1)
unnamed: L2.2, U3.7 (L2)
unnamed: R11.1, U5.6 (VOUT)
REG_PG: R16.2, U3.5 (PG); also elsewhere on the board
USB_DN: C1.1, R3.2; also elsewhere on the board
USB_DP: C2.1, R4.2; also elsewhere on the board
USB_SHIELD: C31.1, J1.SH (SHIELD), R33.1
USB_VBUS: C4.1, J1.A4 (VBUS), J1.A9 (VBUS), J1.B4 (VBUS), J1.B9 (VBUS), U2.10 (IN), U4.5 (VBUS); also elsewhere on the board
VBAT: C6.1, C34.1, R34.1, U2.2 (BAT), U5.1 (VIN); also elsewhere on the board
VBAT_CELL: J3.1, R34.2, TP22.1
VBAT_SENSE: C7.1, R11.2, R12.1; also elsewhere on the board
VBAT_SENSE_EN: U5.3 (ON); also elsewhere on the board
VSYS: C5.1, C8.1, U2.1 (SYS), U3.1 (EN), U3.10 (VIN); also elsewhere on the board

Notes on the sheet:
USB-C provides 5 V and native USB. BQ25185 charges the protected cell; TPS63802 regulates 3.3 V.
Switched battery measurement
USB-C and protection
3.3 V buck-boost
Charger and protected cell

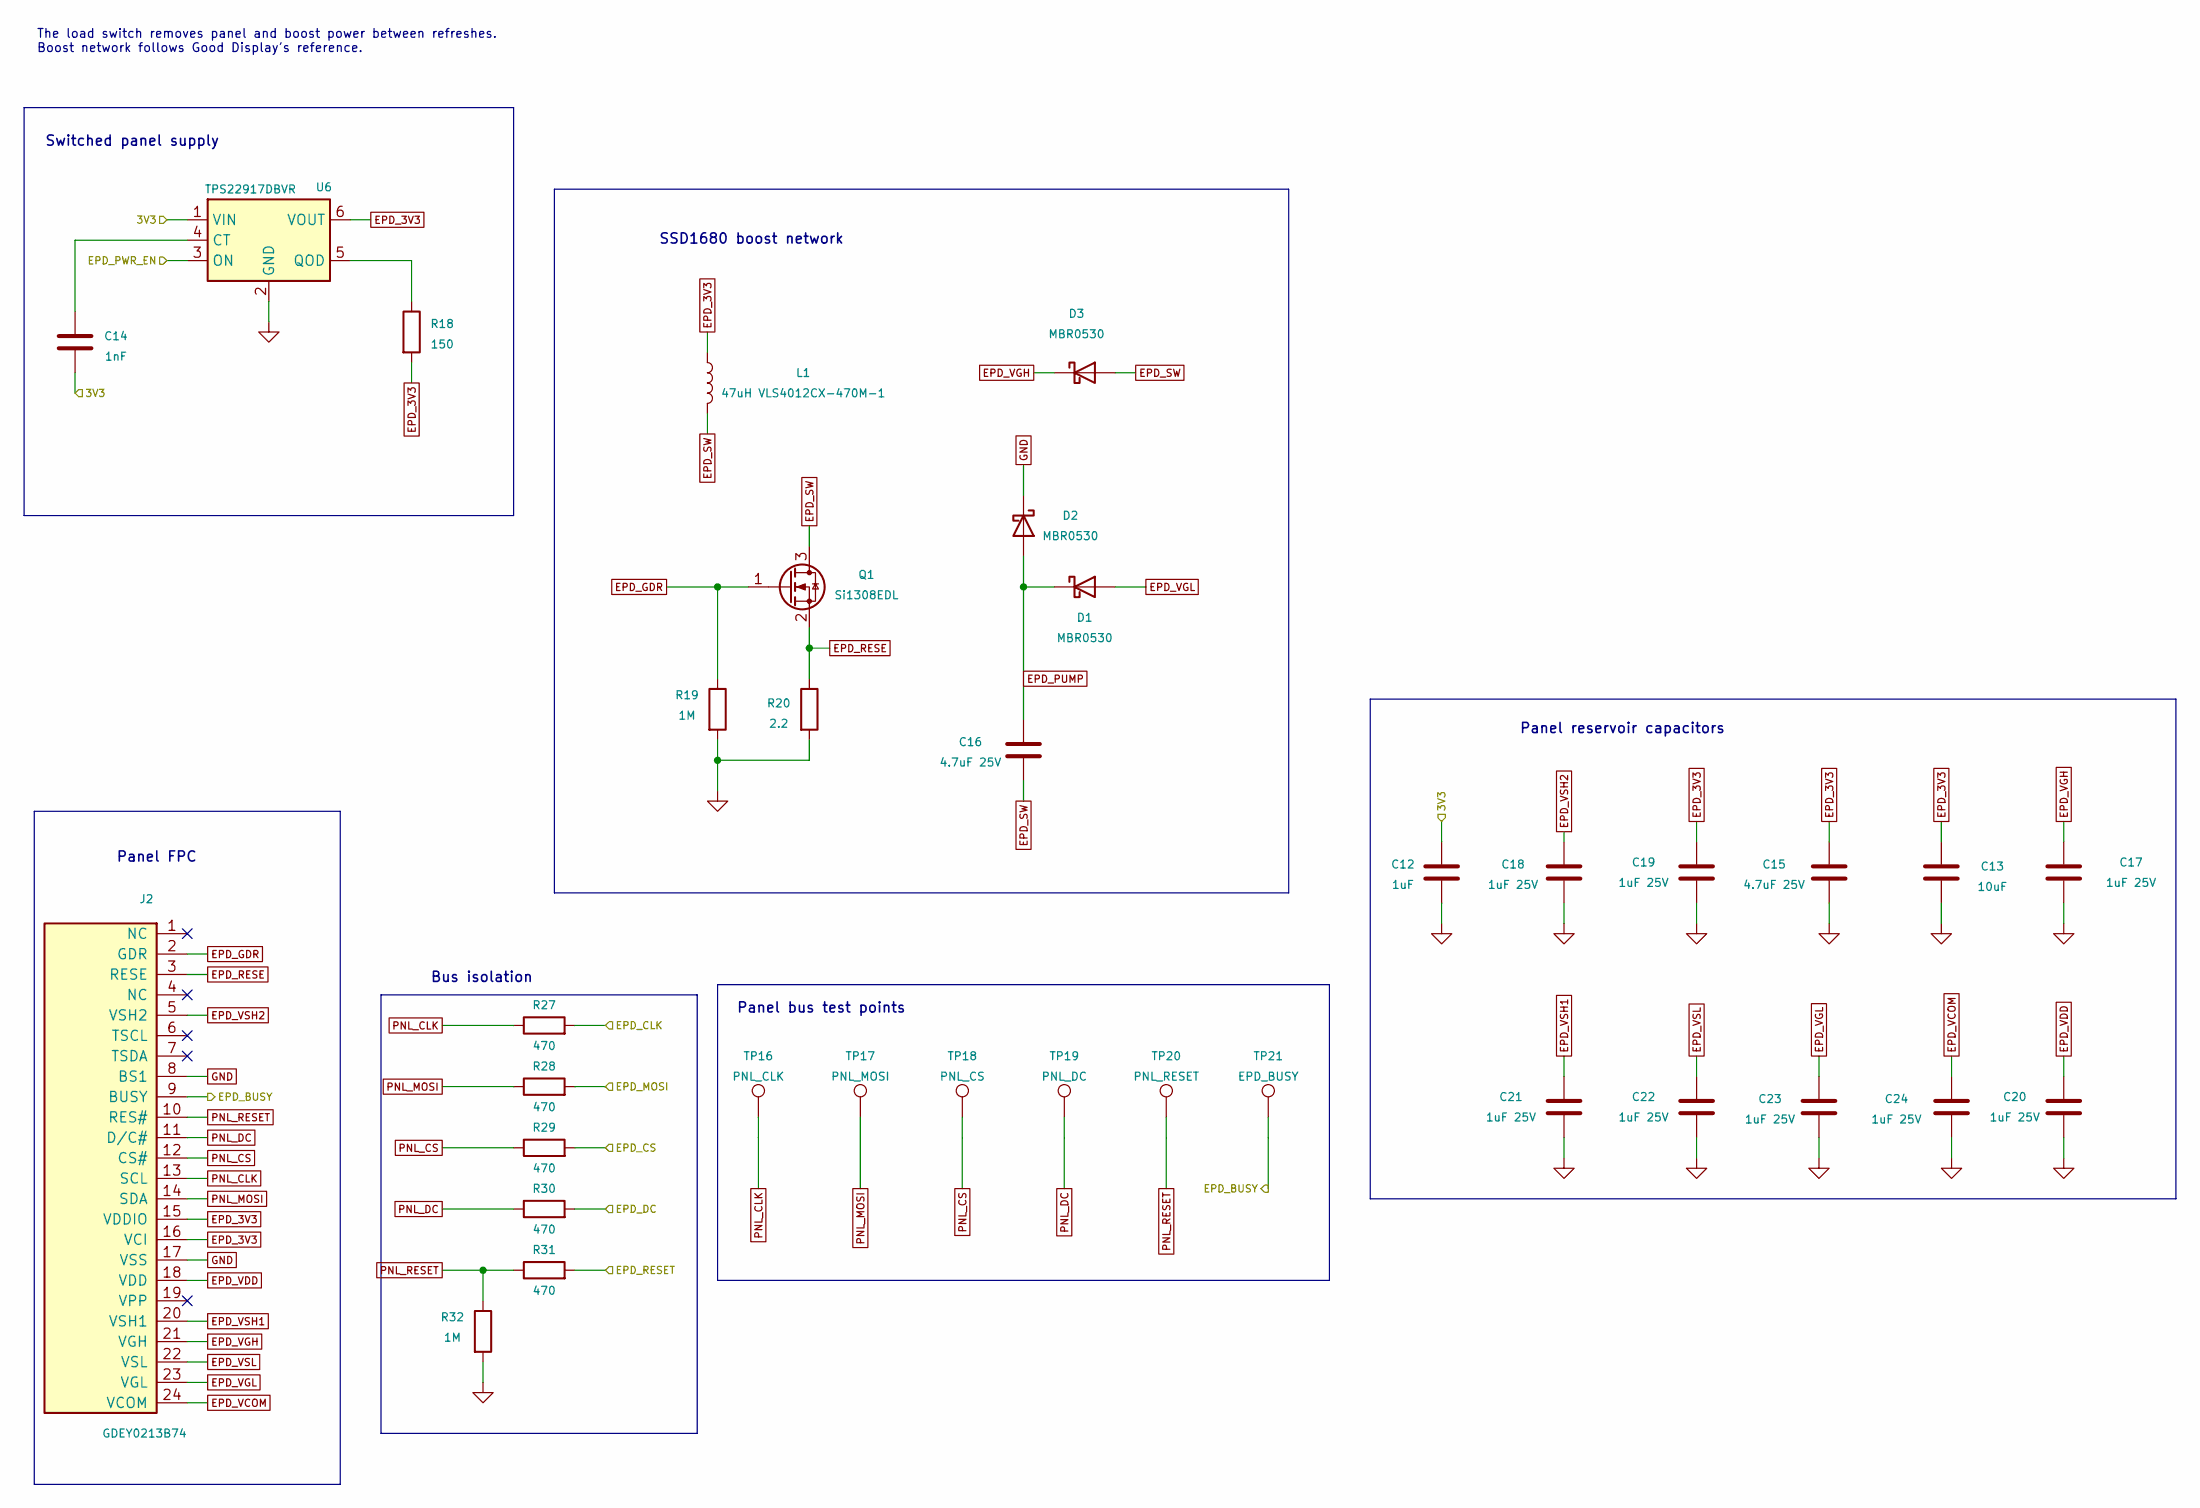
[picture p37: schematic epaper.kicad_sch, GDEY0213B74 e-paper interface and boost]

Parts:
C12: 1uF; C_0603_1608Metric; MPN CL10B105KA8NNNC; LCSC C29936
C13: 10uF; C_0603_1608Metric; MPN CL10A106KP8NNNC; LCSC C19702
C14: 1nF; C_0603_1608Metric; MPN CL10C102JB8NNNC; LCSC C163508
C15, C16: 4.7uF 25V; C_0805_2012Metric; MPN CL21B475KAFNNNE; LCSC C98195
C17, C18, C19, C20, C21, C22, C23, C24: 1uF 25V; C_0603_1608Metric; MPN CL10B105KA8NNNC; LCSC C29936
D1, D2, D3: MBR0530; D_SOD-123; MPN MBR0530-7-F
J2: GDEY0213B74; Hirose_FH12-24S-0.5SH_1x24-1MP_P0.50mm_Horizontal; MPN FH12-24S-0.5SH(55)
L1: 47uH VLS4012CX-470M-1; L_TDK_VLS4012; MPN VLS4012CX-470M-1
Q1: Si1308EDL; SOT-323_SC-70; MPN Si1308EDL-T1-GE3
R18: 150; R_0603_1608Metric; MPN RC0603FR-07150RL
R19, R32: 1M; R_0603_1608Metric; MPN RC0603FR-071ML
R20: 2.2; R_0603_1608Metric; MPN RC0603FR-072R2L
R27, R28, R29, R30, R31: 470; R_0603_1608Metric; MPN RC0603FR-07470RL
TP16: PNL_CLK; TestPoint_Pad_D1.0mm
TP17: PNL_MOSI; TestPoint_Pad_D1.0mm
TP18: PNL_CS; TestPoint_Pad_D1.0mm
TP19: PNL_DC; TestPoint_Pad_D1.0mm
TP20: PNL_RESET; TestPoint_Pad_D1.0mm
TP21: EPD_BUSY; TestPoint_Pad_D1.0mm
U6: TPS22917DBVR; SOT-23-6; MPN TPS22917DBVR

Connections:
3V3: C12.1, C14.2, U6.1 (VIN); also elsewhere on the board
EPD_3V3: C13.1, C15.1, C19.1, J2.15 (VDDIO), J2.16 (VCI), L1.1, R18.2, U6.6 (VOUT)
EPD_BUSY: J2.9 (BUSY), TP21.1; also elsewhere on the board
EPD_CLK: R27.2; also elsewhere on the board
EPD_CS: R29.2; also elsewhere on the board
EPD_DC: R30.2; also elsewhere on the board
EPD_GDR: J2.2 (GDR), Q1.1 (G), R19.1
EPD_MOSI: R28.2; also elsewhere on the board
EPD_PUMP: C16.1, D1.1 (K), D2.2 (A)
EPD_PWR_EN: U6.3 (ON); also elsewhere on the board
EPD_RESE: J2.3 (RESE), Q1.2 (S), R20.1
EPD_RESET: R31.2; also elsewhere on the board
EPD_SW: C16.2, D3.2 (A), L1.2, Q1.3 (D)
EPD_VCOM: C24.1, J2.24 (VCOM)
EPD_VDD: C20.1, J2.18 (VDD)
EPD_VGH: C17.1, D3.1 (K), J2.21 (VGH)
EPD_VGL: C23.1, D1.2 (A), J2.23 (VGL)
EPD_VSH1: C21.1, J2.20 (VSH1)
EPD_VSH2: C18.1, J2.5 (VSH2)
EPD_VSL: C22.1, J2.22 (VSL)
GND: C12.2, C13.2, C15.2, C17.2, C18.2, C19.2, C20.2, C21.2, C22.2, C23.2, C24.2, D2.1 (K), J2.8 (BS1), J2.17 (VSS), R19.2, R20.2, R32.2, U6.2 (GND); also elsewhere on the board
unnamed: C14.1, U6.4 (CT)
unnamed: R18.1, U6.5 (QOD)
PNL_CLK: J2.13 (SCL), R27.1, TP16.1
PNL_CS: J2.12 (CS#), R29.1, TP18.1
PNL_DC: J2.11 (D/C#), R30.1, TP19.1
PNL_MOSI: J2.14 (SDA), R28.1, TP17.1
PNL_RESET: J2.10 (RES#), R31.1, R32.1, TP20.1

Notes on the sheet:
The load switch removes panel and boost power between refreshes. Boost network follows Good Display's reference.
Panel reservoir capacitors
Bus isolation
SSD1680 boost network
Switched panel supply
Panel FPC
Panel bus test points

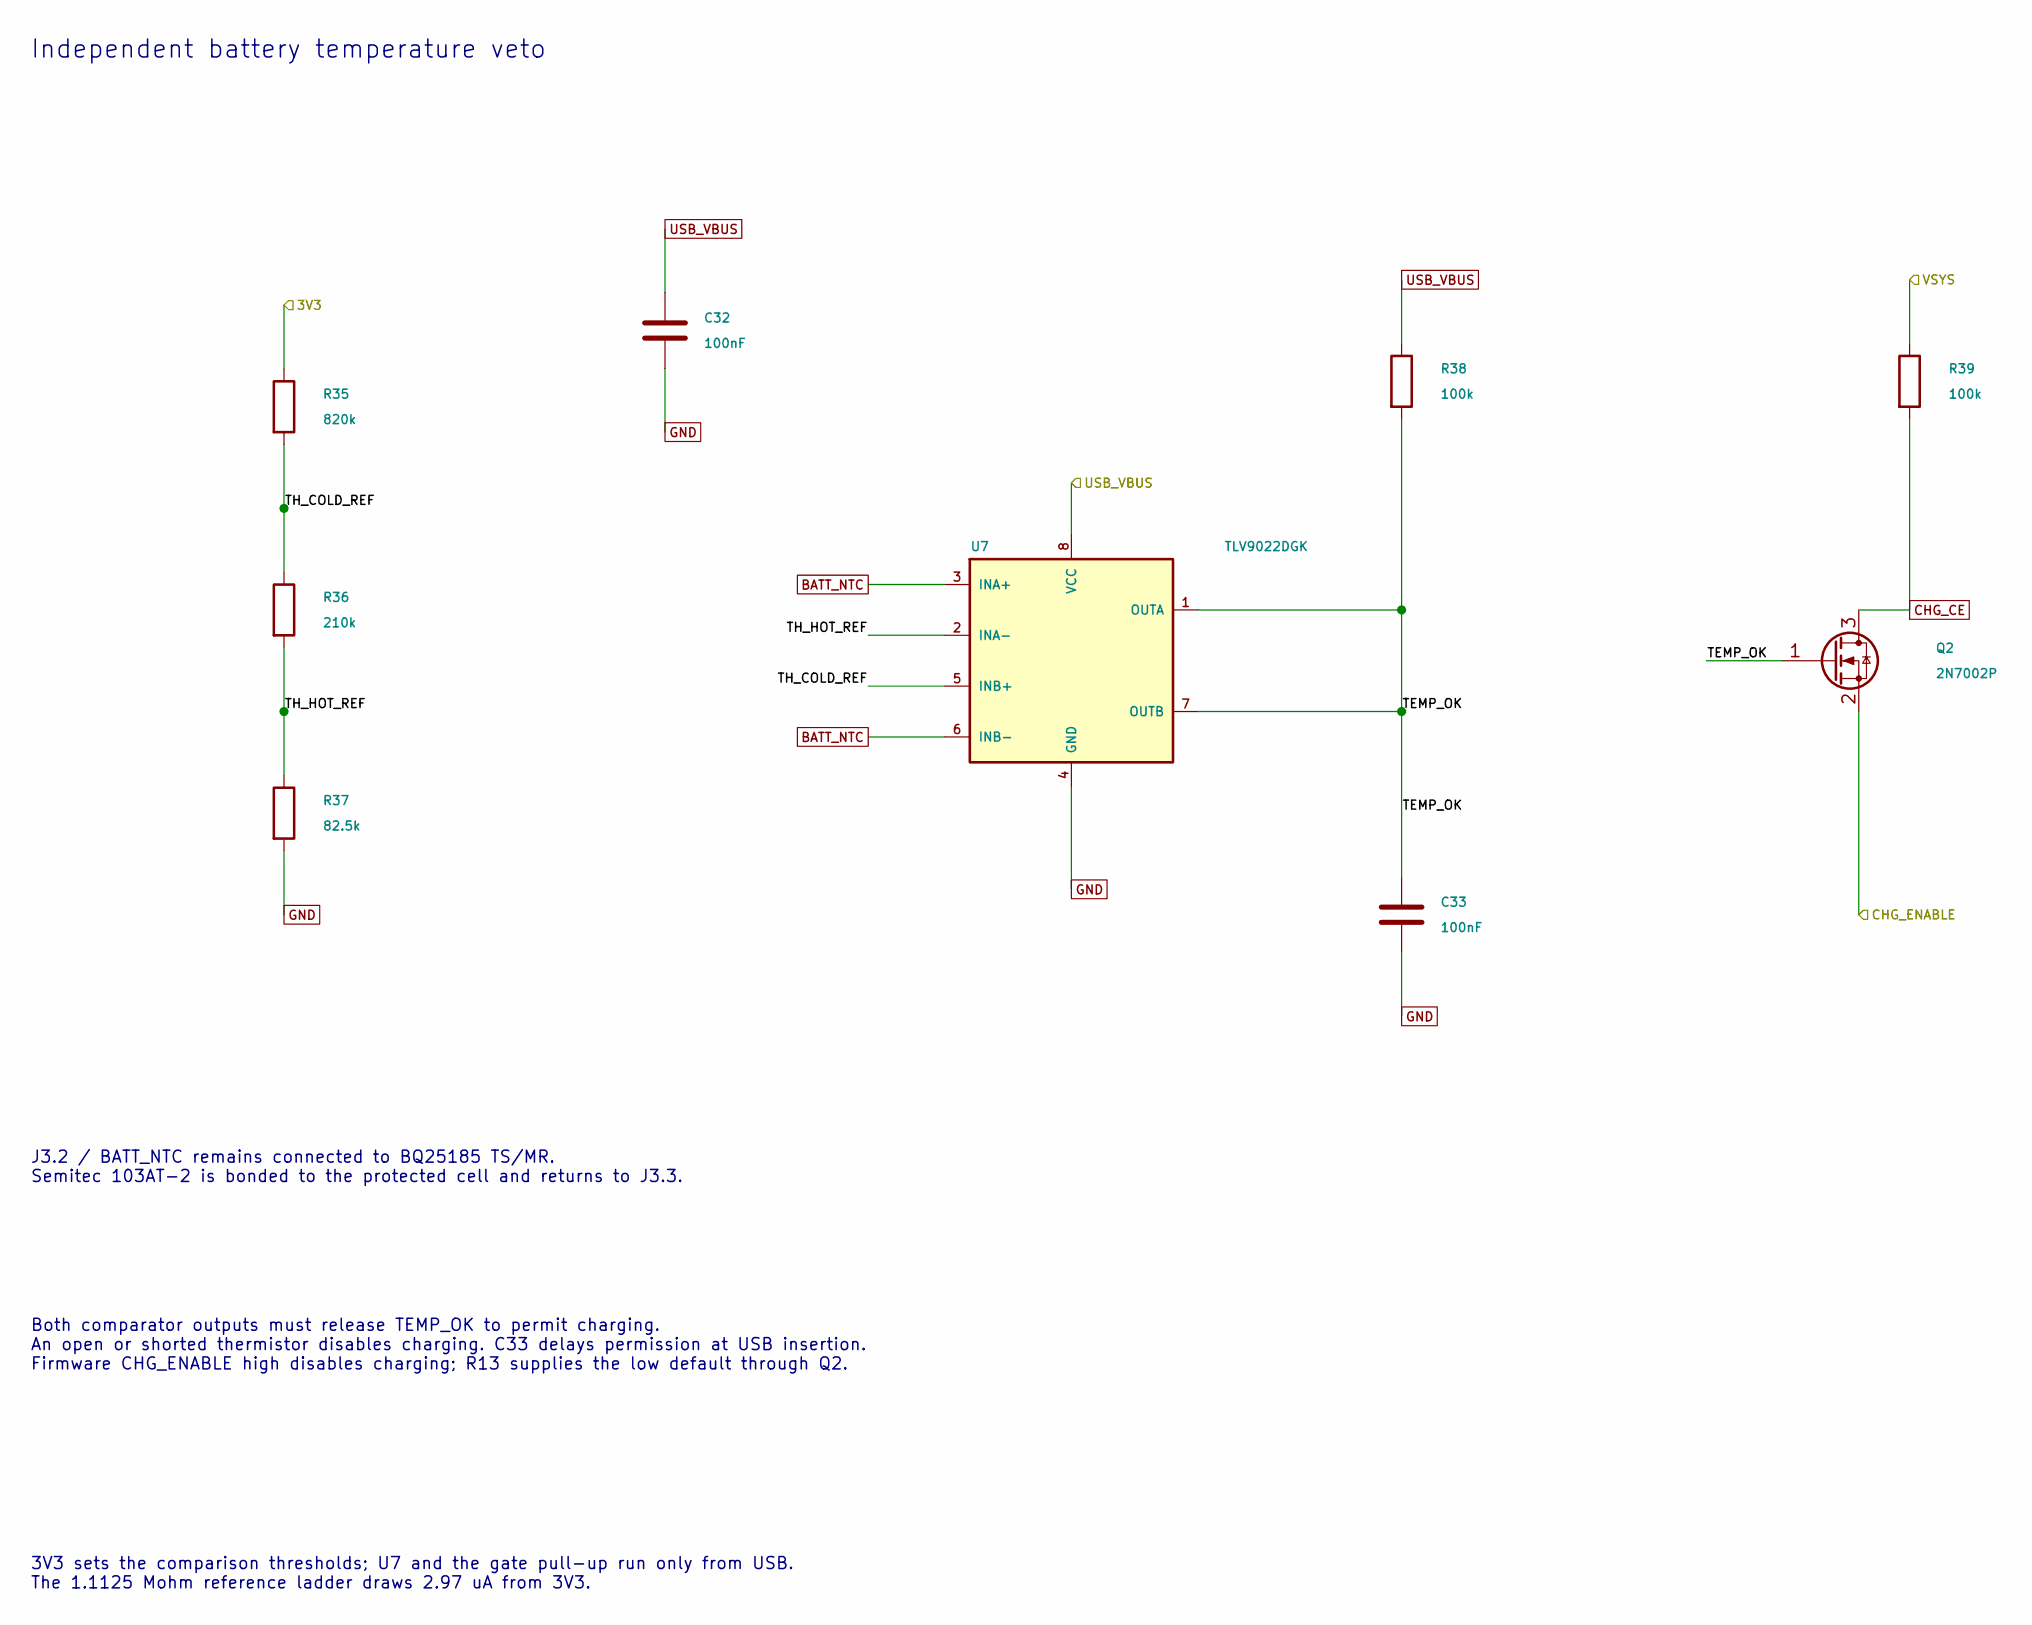
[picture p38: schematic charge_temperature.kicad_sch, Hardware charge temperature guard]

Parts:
C32, C33: 100nF; C_0603_1608Metric; MPN CL10B104KB8NNNC
Q2: 2N7002P; SOT-23; MPN 2N7002P,215
R35: 820k; R_0603_1608Metric; MPN RC0603FR-07820KL
R36: 210k; R_0603_1608Metric; MPN RC0603FR-07210KL
R37: 82.5k; R_0603_1608Metric; MPN RC0603FR-0782K5L
R38, R39: 100k; R_0603_1608Metric; MPN RC0603FR-07100KL
U7: TLV9022DGK; VSSOP-8_3x3mm_P0.65mm; MPN TLV9022DGKR

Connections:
3V3: R35.1; also elsewhere on the board
/Charge temperature guard/TEMP_OK: C33.1, Q2.1 (G), R38.2, U7.1 (OUTA), U7.7 (OUTB)
/Charge temperature guard/TH_COLD_REF: R35.2, R36.1, U7.5 (INB+)
/Charge temperature guard/TH_HOT_REF: R36.2, R37.1, U7.2 (INA-)
BATT_NTC: U7.3 (INA+), U7.6 (INB-); also elsewhere on the board
CHG_CE: Q2.3 (D), R39.2; also elsewhere on the board
CHG_ENABLE: Q2.2 (S); also elsewhere on the board
GND: C32.2, C33.2, R37.2, U7.4 (GND); also elsewhere on the board
USB_VBUS: C32.1, R38.1, U7.8 (VCC); also elsewhere on the board
VSYS: R39.1; also elsewhere on the board

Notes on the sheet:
Independent battery temperature veto
J3.2 / BATT_NTC remains connected to BQ25185 TS/MR. Semitec 103AT-2 is bonded to the protected cell and returns to J3.3.
Both comparator outputs must release TEMP_OK to permit charging. An open or shorted thermistor disables charging. C33 delays permission at USB insertion. Firmware CHG_ENABLE high disables charging; R13 supplies the low default through Q2.
3V3 sets the comparison thresholds; U7 and the gate pull-up run only from USB. The 1.1125 Mohm reference ladder draws 2.97 uA from 3V3.

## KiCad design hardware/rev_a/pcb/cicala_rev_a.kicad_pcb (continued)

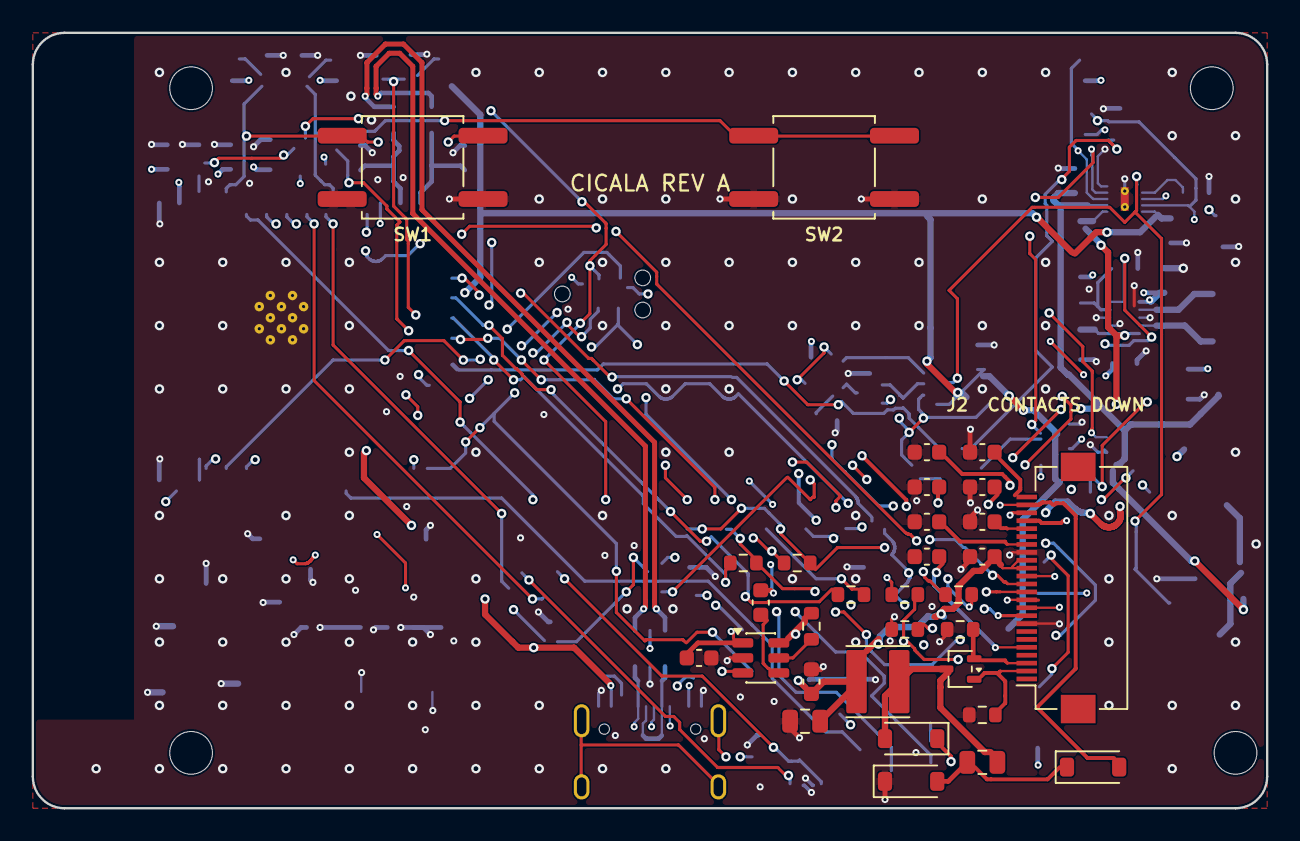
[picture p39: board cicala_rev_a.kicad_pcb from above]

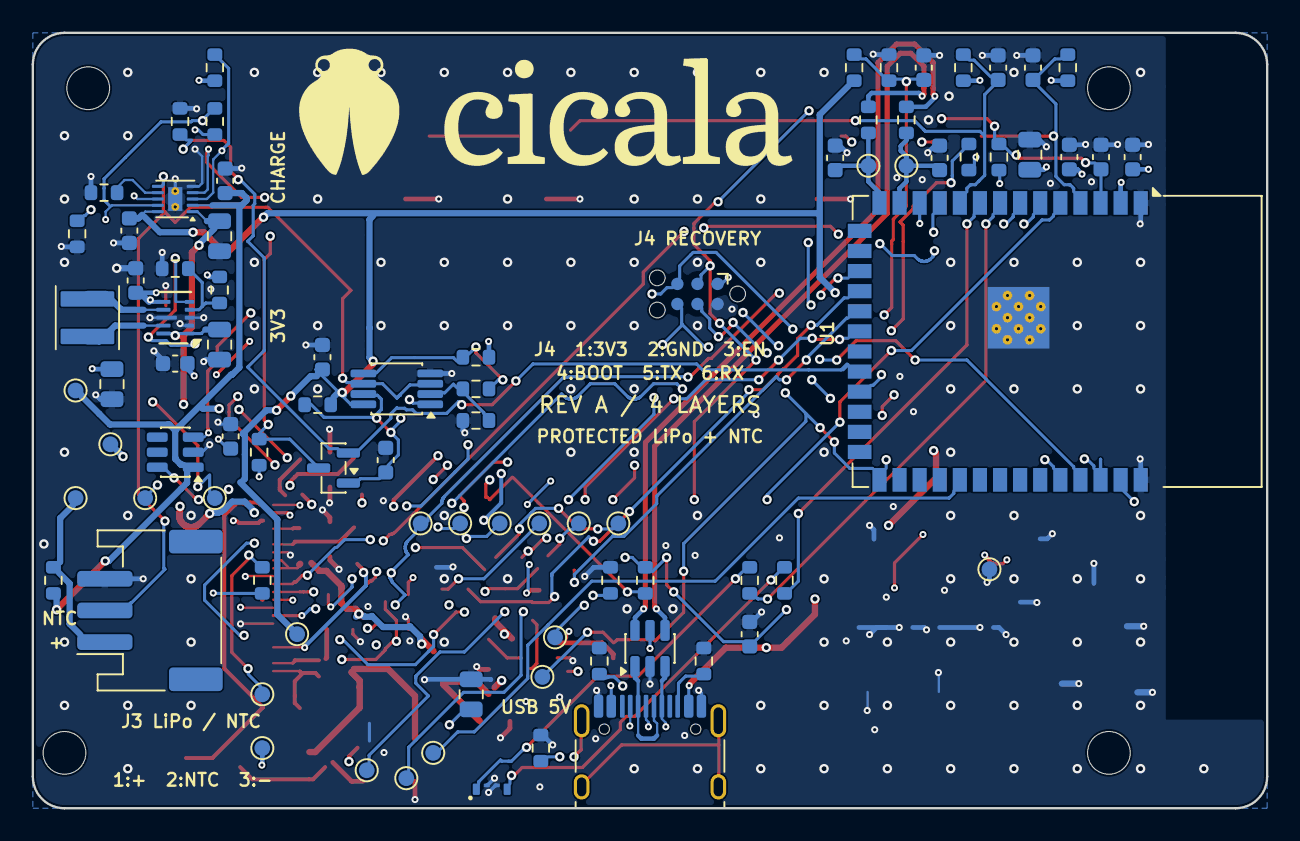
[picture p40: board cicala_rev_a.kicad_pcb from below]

Board: 4 copper layers, 78.0 x 49.0 mm, 119 parts (84 on the bottom side), 70 nets.

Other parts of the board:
H1, H2, H3, H4: M2.5; MountingHole_2.7mm

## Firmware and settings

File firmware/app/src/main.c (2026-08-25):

#include <zephyr/drivers/gpio.h>
#include <zephyr/drivers/hwinfo.h>
#include <zephyr/init.h>
#include <zephyr/kernel.h>
#include <zephyr/logging/log.h>
#include <zephyr/zbus/zbus.h>

#include "channels.h"
#include "input.h"
#include "update_notice.h"

LOG_MODULE_REGISTER(cicala_main, LOG_LEVEL_INF);

#ifdef CONFIG_SETTINGS

#include <zephyr/settings/settings.h>

/* Read the `cicala` subtree back out of NVS. */
static int load_settings(void)
{
    int err = settings_subsys_init();

    if (err != 0) {
        LOG_ERR("settings init failed: %d", err);

        return 0;
    }

    err = settings_load();

    if (err != 0) {
        LOG_ERR("settings load failed: %d", err);
    }

    /* Missing settings leaves defaults intact. */
    return 0;
}

SYS_INIT(load_settings, APPLICATION, CONFIG_APPLICATION_INIT_PRIORITY);

#endif /* CONFIG_SETTINGS */

static void log_reset_cause(void)
{
    uint32_t cause = 0;

    if (hwinfo_get_reset_cause(&cause) != 0) {
        LOG_INF("reset: cause not available on this target");
        return;
    }

    /* Clear accumulated reset causes after reading them. */
    (void) hwinfo_clear_reset_cause();

    if (cause == 0) {
        LOG_INF("reset: none reported");
    } else if (cause & RESET_POR) {
        LOG_INF("reset: power-on — RTC memory is not expected to survive this");
    } else if (cause & RESET_LOW_POWER_WAKE) {
        LOG_INF("reset: low-power wake");
    } else if (cause & RESET_SOFTWARE) {
        LOG_INF("reset: software");
    } else if (cause & RESET_PIN) {
        LOG_INF("reset: pin");
    } else if (cause & RESET_BROWNOUT) {
        LOG_WRN("reset: brownout");
    } else if (cause & RESET_WATCHDOG) {
        LOG_WRN("reset: watchdog");
    } else {
        LOG_INF("reset: cause 0x%08x", cause);
    }
}

/* Hold the DevKitC's onboard WS2812 data line low. */
static void hold_onboard_led_quiet(void)
{
    /* _OR: only the devkit overlay has this LED. */
    static const struct gpio_dt_spec ws2812 =
        GPIO_DT_SPEC_GET_OR(DT_PATH(zephyr_user), ws2812_gpios, {0});

    if (ws2812.port != NULL && gpio_is_ready_dt(&ws2812)) {
        (void) gpio_pin_configure_dt(&ws2812, GPIO_OUTPUT_INACTIVE);
    }
}

int main(void)
{
    LOG_INF("cicala on %s", CONFIG_BOARD_TARGET);

    log_reset_cause();
    hold_onboard_led_quiet();

    const int ret = cicala_input_init();

    if (ret != 0) {
        LOG_ERR("input init failed: %d", ret);
        return ret;
    }

    /* Publishing a notice requires the app thread to be running. */
    cicala_update_notice_check();

    return 0;
}

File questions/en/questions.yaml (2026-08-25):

# questions/en/questions.yaml — Cicala question database (CC0).
# Managed by tools/validate.py --fix. Append new entries WITHOUT id/added;
# CI assigns them. Never edit an existing id. See CONTRIBUTING.md.

- id: q-5a3fb181
  text: "What's the most spontaneous thing you've ever done?"
  decks: [new_people, close]
  depth: 1
  tags: [memory, icebreaker]
  added: "2026-07-24"
- id: q-5b5d9714
  text: "Which song gets you on the dance floor every single time?"
  decks: [new_people, close]
  depth: 1
  tags: [icebreaker]
  added: "2026-07-24"
- id: q-349092b4
  text: "What's the best party you've ever been to, and what made it great?"
  decks: [new_people, close]
  depth: 1
  tags: [memory]
  added: "2026-07-24"
- id: q-1877895c
  text: "What's your go-to karaoke song, and how did it earn that spot?"
  decks: [new_people, close]
  depth: 1
  tags: [icebreaker]
  added: "2026-07-24"
- id: q-03765224
  text: "What's the strangest food combination you genuinely enjoy?"
  decks: [new_people, close]
  depth: 1
  tags: [icebreaker]
  added: "2026-07-24"
- id: q-b03f9f70
  text: "What would the theme of your dream party be?"
  decks: [new_people, close]
  depth: 1
  tags: [hypothetical]
  added: "2026-07-24"
- id: q-10b753f0
  text: "What's the funniest thing you've ever witnessed at a wedding?"
  decks: [new_people, close]
  depth: 1
  tags: [memory]
  added: "2026-07-24"
- id: q-182bdc6f
  text: "Who is the best storyteller you know, and what's their signature story?"
  decks: [new_people, close]
  depth: 1
  added: "2026-07-24"
- id: q-92c67648
  text: "What's a skill you have that surprises people when they find out?"
  decks: [new_people, close]
  depth: 1
  tags: [icebreaker]
  added: "2026-07-24"
- id: q-c0f40125
  text: "What's the most ridiculous thing you've ever bought and never regretted?"
  decks: [new_people, close]
  depth: 1
  added: "2026-07-24"
- id: q-75547a32
  text: "Would you rather always be overdressed or always be underdressed?"
  decks: [new_people, close]
  depth: 1
  tags: [wouldyourather]
  added: "2026-07-24"
- id: q-cf122dd5
  text: "What's the worst haircut you've ever had, and whose fault was it?"
  decks: [new_people, close]
  depth: 1
  tags: [memory, icebreaker]
  added: "2026-07-24"
- id: q-c9f5be2f
  text: "What's your most controversial food opinion?"
  decks: [new_people, close]
  depth: 1
  tags: [icebreaker]
  added: "2026-07-24"
- id: q-138a1f32
  text: "If you had to enter a talent show tonight, what would you perform?"
  decks: [new_people, close]
  depth: 1
  tags: [hypothetical]
  added: "2026-07-24"
- id: q-8d917690
  text: "What's the best prank you've ever pulled or fallen for?"
  decks: [new_people, close]
  depth: 1
  tags: [memory]
  added: "2026-07-24"
- id: q-901b441a
  text: "Which fictional place would you book a holiday to?"
  decks: [new_people, close]
  depth: 1
  tags: [hypothetical]
  added: "2026-07-24"
- id: q-75b64403
  text: "What's a small thing that instantly wins you over at a party?"
  decks: [new_people, close]
  depth: 1
  added: "2026-07-24"
- id: q-95ce2feb
  text: "What's the most embarrassing thing in your search history you'd admit to?"
  decks: [wild]
  depth: 2
  tags: [spicy]
  added: "2026-07-24"
- id: q-52e681ad
  text: "What's a story your friends make you tell every time you go out?"
  decks: [new_people, close]
  depth: 1
  tags: [memory]
  added: "2026-07-24"
- id: q-a8fe5dff
  text: "If animals could talk, which species would be the rudest?"
  decks: [new_people, close]
  depth: 1
  tags: [hypothetical, icebreaker]
  added: "2026-07-24"
- id: q-034c50fe
  text: "What's the weirdest compliment you've ever received?"
  decks: [new_people, close]
  depth: 1
  tags: [memory, icebreaker]
  added: "2026-07-24"
- id: q-172b2c26
  text: "Would you rather never hear music again or never watch another film?"
  decks: [new_people, close]
  depth: 1
  tags: [wouldyourather]
  added: "2026-07-24"
- id: q-1f8937fb
  text: "What childhood game would you still absolutely win at?"
  decks: [new_people, close]
  depth: 1
  tags: [icebreaker]
  added: "2026-07-24"
- id: q-ed3eaf59
  text: "What's the most useless talent you're secretly proud of?"
  decks: [new_people, close]
  depth: 1
  tags: [icebreaker]
  added: "2026-07-24"
- id: q-25cf6318
  text: "If your life had a laugh track, which moment would have gotten the biggest laugh?"
  decks: [new_people, close]
  depth: 1
  tags: [hypothetical, memory]
  added: "2026-07-24"
- id: q-852ebed2
  text: "What's the pettiest opinion you will defend to the very end?"
  decks: [new_people, close]
  depth: 1
  tags: [icebreaker]
  added: "2026-07-24"
- id: q-099c0d8d
  text: "What's the best excuse you've ever used to leave a party early?"
  decks: [new_people, close]
  depth: 1
  tags: [memory]
  added: "2026-07-24"
- id: q-f6133d16
  text: "Which celebrity would be the most fun to be stuck in an elevator with?"
  decks: [new_people, close]
  depth: 1
  tags: [hypothetical]
  added: "2026-07-24"
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

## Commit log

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2026-08-01 test(fw): ztest harness with real bundle fixtures
    Adds a passing smoke suite so the harness has a green baseline, plus the
    suite plan and the fixture pipeline.
    native_sim is the fastest host platform and the only one that emulates
    GPIO, but it builds on Linux only. Development is on macOS, so the default
    is qemu_xtensa: a full Zephyr kernel on the target architecture, covering
    everything except the GPIO-driven suites. CI overrides it with
    `just simboard=native_sim fw-test`, and `just fw-test-linux` runs those
    suites in Zephyr's CI container.
    qdb suites run against real bundles built from the question database by
    `just fw-fixtures`, not hand-written bytes, which is what the component
    notes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
    [main.cpp]
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2026-08-01 feat(fw): table-driven Fsm with an injected clock
    Ports the transition-table pattern in with two changes.
    A timeout now only fires on a self-loop: a transition that actually leaves
    the state wins even on the tick its timeout expires. The original checked
    the timeout before looking for a transition, so a state that had just
    succeeded could be sent to the fail state instead. A transition with no
    table row still fails, because that is a table bug rather than a runtime
    condition.
    current_state_has_timeout() is new. An event loop uses it to decide whether
    it may block forever, which is what lets this design reach deep sleep — no
    timeout to honour means K_FOREVER, means nothing runnable, means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
    [main.cpp]
2026-08-01 feat(fw): bring-up blinky
    Proves build, flash, devicetree and GPIO end to end. Not the product — it
    is replaced by the state machine once input and display land.
    The pin comes from a `zephyr,user` node in the board overlay rather than a
    number in the source, so moving the LED is an overlay edit and the same
    main.c builds for the host. A discrete LED is needed: the DevKitC-1's only
    onboard LED is an addressable WS2812 on GPIO48, so the board defines no
    `led0` alias to reuse.
    [main.c]
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2026-08-02 feat(fw): flash, monitor and debug the devkit from vscode
    None of the on-target flow worked end to end. Each piece failed for its own
    reason, and the fixes are in one change because they only pay off together.
    Flashing let esptool probe every serial port on the machine, Bluetooth
    included, and connect to whichever answered first. The port is now derived
    from the UART jack's cu.usbserial-* glob, overridable via `just port=...` or
    ESPTOOL_PORT.
    `west espressif monitor` locates the build through west's build.dir-fmt
    config, not through -d (which it defines as --enable-address-decoding), so it
    looked in ./build and died before parsing its arguments. fw-init now sets
    dir-fmt, and the monitor re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
    [esp32s3_builtin_jtag.cfg]
2026-08-02 feat(fw): build the bring-up blinky for qemu
    The dc233c board has no GPIO controller, so the sim build had no node to
    resolve blink-gpios against. An overlay backs the selector, Next and the
    blinky pin with Zephyr's emulated controller, keeping index order aligned with
    the target overlay and questions/schema.json x-tischkarte.decks.
    Blink interval goes to 2 s, which is easier to read against a breadboard LED.
    [main.c]
2026-08-04 feat(fw): read the selector and Next button
    Turns the six selector contacts and the Next button into the two zbus
    channels the state machine will consume, and replaces the bring-up blinky
    with a console reporter so `just fw-monitor` shows deck changes and presses.
    Zephyr's input subsystem drives the existing gpio-keys nodes, so per-contact
    debounce is upstream code. What is ours is the one-hot rule, the 600 ms
    settle window, and a boot-time read of the pins: the driver reports only
    edges and samples each pin once at its own init, so a selector already in
    position when power arrives would otherwise go unnoticed — which after deep
    sleep is every wake.
    CONFIG_INPUT_MODE_SYNCHRONOUS is delib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
    [main.c]
2026-08-04 feat(fw): decide what to show with a tabletop state machine
    `app_fsm` on top of the `Fsm` engine that has been sitting in lib/ unused
    since it landed: BOOT, SHOWING, DRAWING, REFRESHING, FAIL, with the
    transition table as the specification and one handler per state.
    No Zephyr headers and no channels. Inputs arrive through post_*(), effects
    leave through an AppIo the caller implements, which is what lets the suite
    drive a fifteen-second refresh timeout in microseconds with no board and no
    display.
    Two rules live in the handlers rather than the table, because they are about
    what the machine remembers rather than where it goes. A press arriving during
    REFRESHING is dropped, not queued — a p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
    [main.cpp]
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2026-08-04 feat(fw): lay out UTF-8 with composed accents
    Zephyr's CFB fonts cover ASCII 32..126 and nothing else, while 74 of the 99
    German questions need ß, ä, ö or ü — and French, Spanish and Italian bring
    another few dozen accented letters. Bundling a font with Latin-1 coverage
    would fix it at the cost of a font file and its licence.
    Decomposition avoids both. `é` is an `e` with an acute above it, and the panel
    already has an `e`, so layout emits a base character plus a mark and the panel
    draws the mark itself. Fifty-one entries cover German, French, Spanish and
    Italian including capitals. Characters with no base letter to mark fall back
    to the spelling the language itself uses when the char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
    [main.cpp]
2026-08-04 feat(fw): render questions on the e-paper
    CFB for the glyphs, hand-drawn marks on top, and a font chosen per question.
    The devicetree was wrong and would never have bound: this Zephyr puts the
    ssd16xx driver behind MIPI-DBI, so the display node has to be a child of a
    `zephyr,mipi-dbi-spi` node that owns the bus and the D/C and reset pins.
    Declaring those on the display node is the older binding and matches nothing.
    The `full` and `partial` profiles are not decoration either — the driver only
    offers partial refresh when a partial profile exists.
    Blanking is how the waveform is selected, but the two calls bracket the write
    rather than acting as a mode flag: blanking on selects the full pro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
    [main.cpp]
2026-08-04 feat(fw): wire input, decisions and display into a working device
    Turning the selector or pressing Next now draws a question and puts it on the
    panel. Two threads: `app` decides, `display` refreshes, and the display gets
    its own thread precisely so `app` stays responsive enough to notice a press
    made during a refresh and deliberately drop it.
    `chan_question` and `chan_render` complete the input half of the channel
    table. The question travels by value rather than as a pointer into the corpus:
    a sync can replace the bundle between the publish and the render, and a
    128-byte copy is cheaper than a rule about who may free what.
    C and C++ split where the architecture says they do. app.c owns the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
    [main.c]
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2026-08-04 fix(fw): stop the LED claiming a dropped press worked
    A press made while the panel is refreshing is deliberately discarded — a full
    refresh takes seconds, and honouring presses made during it would spend them
    drawing questions nobody has read. The state machine has always done this.
    The LED did not. It toggled on every chan_next, dropped presses included, so
    pressing during a refresh lit the LED and then nothing happened. From the
    table that reads as a button that does not work. It now follows chan_question,
    so it only ever confirms something that actually reached the panel, and the
    app thread logs the drop rather than leaving it silent.
    The selector is deliberately not gated the same wa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
    [main.c]
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2026-08-05 feat(fw): keep the shuffle bag and the refresh counter across a reboot
    Deep sleep on the ESP32-S3 does not preserve SRAM, so every wake runs main()
    from the top with .bss freshly zeroed. Anything the device is meant to remember
    between presses has to live in RTC slow memory instead. Bag::State was an
    ordinary .bss object and the panel's refresh counter was a file static, so both
    restarted on every boot.
    The counter is the one with a price on it now. tk_panel_init() forces a full
    refresh because a cold boot cannot know what is on the glass, and once deep
    sleep makes every press a boot, that would turn every question into a 2315 ms
    full refresh instead of a 622 ms partial one — the measured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
    [main.cpp]
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2026-08-05 feat(fw): prove on hardware what survives a reboot
    Deep sleep is a reboot, so the retained block is only worth anything if RTC
    memory really does come back. That could not be checked: CONFIG_PM does not
    exist yet, and the reset button is no substitute — a reset through the
    DevKitC's EN pin reports as rst:0x1 (POWERON), clears the RTC domain, and the
    firmware correctly calls it a cold boot.
    A warm software reset does keep it, so the soak image can perform the test on
    itself. CONFIG_TK_DEBUG_SOAK_REBOOT reboots it every few presses, which is the
    closest thing to a wake that exists today, and `just fw-retain` builds it.
    Measured across three consecutive reboots on the rig: the shuffle bag k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
    [main.c]
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2026-08-05 feat(fw): deep sleep, and a Category button in place of the selector
    Two changes that turned out to depend on each other.
    ## Deep sleep
    CONFIG_TK_SLEEP, off by default, built by `just fw-sleep`. Confirmed reaching
    real deep sleep on the board: rst:0x5 (DSLEEP) and "reset: low-power wake".
    Sleep is called, not fallen into. The architecture had the idle thread choose
    it once nothing was runnable, and that is not how this SoC works — Zephyr's
    devicetree marks the state disabled and documents it as enterable only through
    pm_state_force() or sys_poweroff(). An idle timer decides instead, rearmed by
    every press and every render, and only from a settled state: a wake is a fresh
    boot, so sleepi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
    [main.c]
2026-08-05 feat(fw): keep the panel across a wake, and answer the press
    Deep sleep is a reset, and two separate things assumed it was not.
    ssd16xx clears both controller RAM buffers, pulses the hardware reset and
    drives a full update from its init function, with no way to opt out. All three
    ran on every wake: the panel spent 2314 ms going white before the application's
    own refresh began, and the retained refresh counter described a panel state
    that no longer existed. deps/ is gitignored, so the opt-out lives in
    firmware/patches/ and is applied by `west patch` — `just fw-patch`, and
    fw-init now runs it after `west update`. Kconfig only warns when a .conf
    assigns a symbol that does not exist, so sleep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
    [main.cpp]
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2026-08-06 feat(fw): a portal library that parses without a radio
    The setup portal needs three things that are bytes in and bytes out: a
    DNS responder that answers every name with the device's own address, a
    decoder for the form a browser posts, and the pages themselves. None of
    them needs a radio, so they go in firmware/lib/ where the suite runs
    them on the host, and app/src/ is left owning only sockets.
    Zephyr has no wildcard DNS responder to configure instead — the DNS
    library ships a resolver, an mDNS responder and an LLMNR responder, none
    of which answers arbitrary names on somebody else's behalf. Writing it
    is a hundred lines; the part worth testing is that it refuses malformed
    queries, since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
    [main.cpp]
2026-08-06 feat(fw): a state machine for the setup portal
    Same shape as the tabletop machine: the table is the specification, the
    handlers only say what happened, and PortalIo is the whole of what the
    machine can do to the world. The clock is injectable, so the suite
    drives a five-minute window in microseconds with no radio and no phone.
    Two orderings in it are not arbitrary, and both come from the ESP32-S3
    having one radio for two jobs.
    The scan runs before the access point, because a scan hops every channel
    in the band for several seconds while a SoftAP sits on one. Scanning
    with a phone already associated stalls it and can drop the association.
    A scan that never reports back is survivable and goes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
    [main.cpp]
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2026-08-06 feat(fw): a service card the state machine owns
    The setup portal has to say which network to join, and the panel is the
    only output the device has. Joining a network then knocks the phone off
    the setup access point, so the panel is also the only place the result
    can be reported — the browser that submitted the form never sees it.
    The obvious implementation is wrong. app_logic owns the sequence number
    every card is stamped with, and post_render discards any result whose
    seq is not the one last published; that guard is what fixed the bug
    where one press appeared to do nothing and the next showed two
    questions. A card published straight from the net thread would allocate
    a sequence number be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
    [main.cpp]
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2026-08-06 refactor: the bundle is a .qdb, not a .tkb
    Two problems with the old name, and the second is the one that matters.
    It carried the product name into a wire format. The magic bytes and the
    published filenames are the least reversible thing in the tree — once a
    signed release exists and devices are in the field, both have to be read
    forever — and pinning them to a product name that is still being
    questioned is a bad trade for nothing.
    And `.tkb` was the gzip while `.tkb2` was the raw binary, so the two
    artifacts differed by *compression* while the name differed by what
    looks like a *version*. That was mine, from pointing devices at the raw
    file, and it would have confused everyone who met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
    [main.cpp]
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2026-08-06 feat(fw): fetch, verify and install a signed bundle
    The middle of the flow, which was the only part missing: everything
    after "verify" already existed.
    The manifest is parsed by hand in lib/sync rather than with Zephyr's
    JSON library, because `languages` is an object whose keys are data — en,
    de, whatever ships later — which a descriptor-driven parser cannot
    describe. That makes it testable on the host, which matters: it reads
    bytes off a transport that authenticates nobody.
    version_compare works component by component on integers. As text
    "2026.08.9" sorts after "2026.08.10", so a string compare would refuse
    the newer release and accept the older one as an upgrade. Components
    saturate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
    [main.cpp]
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2026-08-07 fix(fw): load the tk settings subtree, which nothing ever did
    Found while building something that needed to read a stored value, and
    true since settings were introduced: no code anywhere called
    settings_load(). settings_save_one() initialises the subsystem by
    itself, so saving worked and looked complete, while every registered
    load handler sat unused.
    Two things were quietly broken by it. The chosen language was written
    and never restored, so a device set to German through the portal came
    back in English on the next boot. And the installed corpus version was
    never read, which meant the anti-rollback check in sync.cpp compared
    every manifest against an empty string — the guard was there, a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
    [main.c]
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2026-08-07 feat(fw): say on the panel that an update installed
    An update installs during a boot, which is the one moment nobody is
    looking: MCUboot copies the image before a single line of this firmware
    runs, and the device comes up looking exactly as it did before. Without
    this the only evidence is a console nobody has attached.
    Zephyr exposes mcuboot_swap_type() and it is the wrong source twice
    over. It answers what will happen on the *next* boot rather than what
    happened on this one, and in overwrite-only mode there is nothing left
    afterwards to distinguish an image installed a moment ago from one that
    has run for months.
    Comparing APP_VERSION_STRING against a version in NVS answers the
    question a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
    [main.c]
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2026-08-09 feat(fw): decide what a cell voltage means, and what to show for it
    Two libraries, both pure C++17 on lib/fsm, both testable without a board.
    lib/power turns a millivolt reading and a VBUS bit into one state. Three
    things about its shape are load-bearing and are commented where they live:
    readings are sticky, so one sample walks several rungs of the ladder — on
    battery the machine sees one sample in its whole life, because a wake is a
    reboot and the device is awake for about two seconds. Hysteresis applies
    only upwards, since being slow to notice a cell getting worse costs
    something. And UNKNOWN permits refreshes, so a failed ADC costs the battery
    reading and nothing else; it is also the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
    [main.cpp]
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2026-08-09 feat(fw): refuse a refresh the cell cannot carry
    CONFIG_TK_REFRESH_MIN_MV has existed since the panel work and nothing read
    it. Now app_logic's Io checks it before drawing, and under the floor the
    previous question stays on the glass.
    The check runs before bag.draw(), which mutates the retained shuffle state:
    gating after it would burn a question from the no-repeat cycle on every
    press the device was too flat to answer. show_category() gates before ++_seq
    for the same reason — a sequence number handed out and never used makes the
    guard that drops a late render match against something that never happened.
    Returning false sends the machine to FAIL, which already means exactly this:
    claim t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
    [main.c]
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2026-08-12 feat(fw): a reading too low to be a cell is not a flat cell
    The devkit board conf turns CONFIG_TK_POWER on for every image fw-build
    produces, and neither divider is soldered. A floating GPIO1 reads
    something, anything under 1600 mV at the tap walks the ladder to LOW or
    CRITICAL before a thread starts, and refresh_allowed() then refuses every
    press — including the one that draws the first card, answered by three
    red blinks on LEDs that are not wired either.
    So lib/power gets a floor. Below CONFIG_TK_POWER_PLAUSIBLE_MV, 2500 mV, a
    reading returns to UNKNOWN from wherever it was: an SoC that is still
    executing cannot be reading 2.4 V from its own pack, because the
    protection circuit and the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
    [main.cpp]
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2026-08-13 fix(fw): the portal's amber never reached the LEDs on battery
    tk_status_post_portal() was called from one place, the chan_power listener,
    on the assumption that every power sample passes through it. Every power
    *publish* does, and a publish is deadbanded: the machine reports a state
    change or a reading that has moved 20 mV, and nothing else. A resting cell
    does neither for minutes at a time.
    So a setup session on battery went like this. Boot publishes twice walking
    UNKNOWN to NORMAL, both before `net` has started the portal, so both report
    it off. The portal then goes on air and no publish follows it, so the LEDs
    stay dark for the whole session — on the one screen where the panel cannot
    s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
    [main.c]
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2026-08-13 docs: the bench is built, and rev A is what comes next
    The power path runs on hardware now, so the pages that said otherwise were
    wrong in the direction that matters: somebody planning rev A would have read
    "nothing about power has been seen on hardware" and re-derived what the bench
    already answered. AGENTS.md, the architecture status, the wiring status and the
    open-items list all say what the rig does instead, and the bench-measurements
    table carries the two readings it produced.
    The rotary selector went in a firmware change some time ago and four pages
    still described it as the current input — design.md, the primer, the index and
    the device prototype, the last of which was still framed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
    [main.c]
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2026-08-19 fix(hw): correct rev A charger/regulator wiring and assign footprints
    Two schematic errors that ERC could not catch, both electrically valid
    but topologically wrong:
    - TPS63802 feedback divider was shorted: a straight wire tied FB to VOUT
    and bypassed R14, so the part would regulate the 3.3 V rail down to its
    0.5 V reference. Rewired VOUT -> R14 -> FB node -> R15 -> GND (3.31 V).
    - BQ25185 TS/MR and the pack NTC wire (J3.2) were tied to VBAT, which the
    charger reads as an out-of-range temperature and suspends charging.
    TS/MR is now the BATT_NTC net carrying only J3.2; BAT stays on VBAT.
    The 38 uA TS source and the 10 kOhm B=3435 pack NTC to GND need no
    external bias (~1.5 C / ~5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
    [battery_charger.kicad_sch, epaper.kicad_sch, esp32_core.kicad_sch]
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2026-08-26 fix(hw): split the shorted USB pair and PREVGL pump node
    Sheet re-layout that also separates two nets that were tied together.
    J1 CC2, D+ and D- shared one net with both USBLC6 line pins; D+ and D-
    are now their own nets. D1 had both pins on EPD_PREVGL, shorting it out
    of the charge pump; its cathode is now the pump node with C16.
    Three net labels were lost in the move and are now auto-named:
    BATT_NTC, BTN_CATEGORY and BTN_NEXT. pin_contract.csv and BOM.md still
    name them, so they need restoring.
    [battery_charger.kicad_sch, epaper.kicad_sch, esp32_core.kicad_sch]
2026-08-26 fix(hw): correct four ERC-invisible rev A wiring errors
    All four are electrically valid connections that are simply wrong, which
    is why ERC accepted them. Verified against the part datasheets and the
    GDEY0213B74 reference circuit, and checked by re-exporting the netlist.
    USB D+/D- were crossed between the receptacle and the MCU: J1 D- reached
    GPIO20 (USB_D+) through U4 I/O1 and R3. Swapping the USB_DP and USB_DN
    labels puts each line on its own pin without crossing wires. R3 now
    carries D-, R4 carries D+.
    Q1 used Q_NMOS_SGD, but the Si1308EDL in SOT-323 is pin 1 = G, 2 = S,
    3 = D, so the gate driver landed on the sense node. The symbol is now
    Q_NMOS_GSD; the drawing is unchanged because bo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
    [battery_charger.kicad_sch, epaper.kicad_sch, esp32_core.kicad_sch]
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2026-09-05 feat(questions)!: reset the corpus and ship Italian
    Remove the 240 English and 99 German seed questions to build the database
    from scratch. Every id is derived from its own text, nothing outside the
    repository pins one, and no release has shipped, so the reset costs no
    stable references.
    Italian joins as a shipped language rather than through the incubator:
    questions/it/ with its style guide and denylist, an x-cicala entry, the
    UI string set, CODEOWNERS routing and both issue forms.
    Every google block is gone, so the translation workflow plans no targets
    until a fluent maintainer opts a language back in. Re-enabling does not
    backfill; docs/languages.md records how to catch up on the gap.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
    [questions.yaml]
2026-09-05 fix(firmware): run the behaviour suites against a fixture corpus
    The corpus reset in #23 emptied questions/en and questions/de, and the
    firmware job went red on main. cicala.qdb, cicala.integration and
    cicala.soak embed bundles built from the shipped database: with nothing in
    it the bag draws nothing, the integration seams publish no card, and the
    soak run stops after the first refresh.
    The database is editorial and will stay in motion, so the suites that
    exercise behaviour now read a committed fixture corpus at
    firmware/tests/corpus/, built by `build_bundle.py --corpus` into
    firmware/tests/fixtures/. Its shapes are load bearing and documented next
    to it: two disjoint decks of fourteen for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
    [main.cpp, questions.yaml]
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

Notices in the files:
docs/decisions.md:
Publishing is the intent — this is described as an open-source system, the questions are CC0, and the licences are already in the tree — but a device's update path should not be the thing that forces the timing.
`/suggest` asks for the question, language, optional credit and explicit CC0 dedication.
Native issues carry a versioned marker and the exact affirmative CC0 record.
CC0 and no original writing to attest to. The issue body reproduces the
